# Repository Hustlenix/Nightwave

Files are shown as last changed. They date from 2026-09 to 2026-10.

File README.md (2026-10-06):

# Nightwave

Current builder boundary (2026-10-06): target PCB <=90x60 mm, finished device
about <=110x70x25 mm, INR15,000 electronics + PCB/assembly excluding tools.
Final PCB redesign/routing and enclosure CAD are builder-authored. The large
AI reference is not the final design; battery remains unselected. See
[compact requirements](docs/compact-builder-constraints.md), which supersede
older size/budget and final-CAD authoring permissions below.

## PCB checkpoint - 2026-10-06

The AI-authored [KiCad reference project](hardware/kicad/nightwave-reference/README.md)
now has a routed four-layer board, 132 circuit footprints plus three M2
mounting holes, numbered GPIO assignments, and native manufacturing review
exports. See its [validation status](hardware/kicad/nightwave-reference/VALIDATION_STATUS.md)
and [engineering checkpoint](docs/reference-pcb-checkpoint.md) for exact results.
The [downloadable review package](hardware/kicad/Nightwave-AI-Reference-2026-10-06.zip)
includes editable sources, PDF, Gerbers, drill, positions and board STEP.

The [completion ledger](docs/design-completion-status.md) tracks open work.
The [reference firmware profile](docs/reference-board-firmware.md) now matches
the PCB GPIO map and implements TFT output and expander buttons. Typed ERC,
DRC and schematic/board parity pass locally; hardware operation remains untested.

**This is not fabrication or grant-submission approval.** USB source-current
and protection, power-loop/current capacity, complete component procurement,
firmware-to-board integration and enclosure fit remain unresolved. Clean
connectivity/clearance checks are not electrical safety or functional proof.
The builder requested this separate AI-authored reference when their laptop
could not run KiCad; their original starter files remain untouched.

Nightwave is an in-progress, standalone pocket music player for the Pixl “A Music player for the saloon” Trial. It reads user-owned MP3 and PCM/WAV files directly from microSD, with software decoding, physical controls, wired stereo headphones, a speaker, synchronized LRC and Bluetooth output. No phone or streaming service is required. The builder selected ESP32-S3 plus BM83SM1-00TA (BD-14) and Waveshare 24382 non-touch TFT (BD-15). Their hardware drivers, combined GPIO map and battery sizing are not qualified or locked.

> Status (2026-10-03): WAV/MP3 three-task streaming, bench OLED/five-button interaction,
> lyrics/metadata/M3U, modes, bounded seek/resume, sleep timer and versioned
> persistence are implemented for the provisional hardware. The 2026-10-02
> continuation adds an idle-built SD catalog, paged songs/artists/albums and
> bounded PSRAM lookups for filtered browsing/track changes, MP3 duration/sparse
> seek, full-text display interface, BT/power contracts and engineering telemetry;
> [catalog limits](docs/library-index.md) remain explicit. See the
> [expanded-scope checkpoint](docs/engineering-budgets.md) for remaining software.
> Executed [firmware/host CI evidence](docs/software-validation.md) is revision-specific.
> **Funding package is NOT READY:** final power design,
> complete procurement BOM, reviewed enclosure CAD and human reviews are
> missing. An [AI-authored PCB reference](hardware/kicad/nightwave-reference/README.md)
> now exists; its native checks do not constitute fabrication approval or builder authorship.
> No physical playback, runtime, fit, final hardware or tier is claimed.

## Why it exists

The original hardware workflow used builder-authored mentor/reviewer mode;
the separate AI-authored reference above was subsequently requested. **Before
final schematic tasks**, review the selected [Bluetooth architecture](docs/bluetooth-architecture.md)
and [display BD-15](docs/display-selection.md). BD-16 selects
[TCA9535PWR input expansion](docs/input-expansion.md); review its [combined GPIO map](docs/pin-budget.md)
and review the [current power model](docs/current-power-model.md), charger/pack
and complete BOM before the first schematic task. Then use
[builder tasks](docs/builder-tasks.md), [subsystem requirements](docs/schematic-requirements.md)
and [your decision log](docs/builder-decisions.md). AI research and review are
disclosed; final schematic, routing and enclosure must be materially authored
by the builder. The reported Pixl clarification does not mark missing work done.

The product goal is to play the builder's own music offline without a phone,
notifications, subscription or hidden playback module. The builder's personal
motivation and genuine work journal must remain their own account; this README
does not invent a first-person build story.

## Architecture

```text
microSD / FAT
      |
      v
StorageTask -> compressed ring buffer -> DecoderTask -> PCM ring buffer
                                                        |
                                                        v
                                                AudioOutputTask
                                                        |
                                                   I2S + DMA
                                      +-----------------+-----------------+
                                      |                                   |
                                PCM5102A DAC                       MAX98360C amp
                                      |                                   |
                              TPA6132A2 headphone amp                mono speaker
                                      |
                               3.5 mm stereo jack
```

The ESP32 owns file enumeration, storage reads, MP3/WAV decoding, buffering, playback state, I2S output, buttons, UI, settings, diagnostics, and power policy. Nightwave does not use DFPlayer or another module that hides the storage/decode/playback pipeline. The diagram above is the current two-local-output software/bench path. The product requires a third mutually exclusive, rate-qualified I2S branch to BM83SM1-00TA for A2DP source output. Its radio adapter, combined playback router and 22.05/32 kHz conversion are not implemented. Host-tested Bluetooth control/framing contracts do not make that output operational.

The bench prototype uses an available MAX98357A breakout as a functional speaker-path proxy. The current AI-authored KiCad reference uses MAX98357AETE+T (TQFN); MAX98360C in historical candidate documents is not the reference board's fitted amplifier. This remains an unqualified engineering candidate.

## Current implementation

- repository and required engineering-document structure;
- current Pixl/Trial rules verification and honest AI-disclosure strategy;
- datasheet-backed provisional component comparison, BOM, pin budget, power tree, risk register, prototype plan, and decoder study;
- ESP-IDF 6.1 C++ firmware with safe-muted boot, chip/reset/heap/PSRAM diagnostics, debounced five-button logging, 1-bit SDMMC mount/enumeration/benchmarking, I2S DMA output, and a low-level tone test;
- robust host-tested WAV parsing for 16-bit mono/stereo PCM at 22.05/32/44.1/48 kHz, including unknown-chunk skipping and explicit errors;
- three-task WAV/MP3 streaming through a 32 KiB encoded ring and 16,384-frame
  SPSC PCM ring, pause/resume, cancellation, gain ramps and queue/error telemetry;
- SH1106 OLED driver (SSD1306 option), file/folder browser, now-playing, five
  buttons, headphone indicator, no-SD/error screens, sleep and diagnostics;
- bounded LRC, ID3v2.3/v2.4/ID3v1/WAV INFO metadata and local M3U/M3U8 loading;
- SD-backed incremental catalog, 16-row songs/artists/albums views, full indexed
  collection/filter queues, bounded artist/album lookup and checked ordinal-hint
  filter/folder resume; low-memory/over-cap caches use a slower fallback;
- normal/shuffle/repeat-all/repeat-track; accepted-sample lyric clock; WAV direct
  seek and idle-built sparse MP3 seek checkpoints with decoder preroll, safe
  decode-from-start fallback and a 30-minute resume/seek cap;
- versioned checked NVS volume/mode/output/resume/playlist/folder persistence,
  explicit saved-track resume and 15/30/45/60-minute/end-track sleep timers;
- JSON boot/stream/performance/self-test/engineering records, with unmeasured hardware marked;
- injected display frame interface carrying full bounded metadata/LRC strings;
  tested Bluetooth source-state/timeout/backpressure boundary and unknown-safe
  power HAL, without pretending unqualified adapters are operational;
- portable tests for WAV parsing, generated fixtures, ring wrap/full behavior, stereo-to-mono arithmetic, volume scaling, button debounce, and playback state;
- CI definitions for both ESP32-S3 firmware and portable host tests;
- exact Phase 2 prototype BOM, pin-by-pin wiring table, voltage/current plan, deterministic test-media generator, and staged bring-up checklist.

The firmware does **not** prove that a card mounts, a waveform reaches a physical
module, a speaker/headphone produces correct audio, or buffering survives real
card latency. OLED/controller wiring, jack detection and NVS behavior still need
bench validation. Battery reads, power-latch shutdown and automatic SD hotplug
reinitialization are not implemented. Retry/error handling is not a claim that
removing a real card during playback has been tested.

## Controls

The [Trial acceptance matrix](docs/trial-acceptance.md) maps every requirement to
source and missing physical proof. The [runtime recorder](docs/runtime-test.md)
logs sampled elapsed/playback windows and faults; it cannot certify battery life.

Previous/Next navigate the browser or change playing tracks. Play opens a folder
or starts/toggles playback. Volume +/- changes gain. Hold Play for the browser,
hold Previous for the parent folder, hold Volume + for diagnostics, hold Next
for lyrics and hold Volume - for mode/sleep/resume/output settings. First input
after the 30 s display sleep wakes without changing playback.
See [complete controls and limitations](docs/player-controls.md).

## Audio architecture

Helix decodes MP3 in software on ESP32-S3; WAV uses the validated PCM parser.
Storage, decode and I2S have separate tasks. PCM is stereo 16-bit at supported
22.05/32/44.1/48 kHz rates. ID3 skipping and resynchronization are bounded;
unsupported or corrupt media produces a recoverable error. The Class-D path
must select averaged-stereo mono in the reviewed final hardware; headphone
output uses the separate stereo DAC/amp path. Neither path is physically proven.

## Power architecture

USB-C and a protected 1S pack feed a charger/power path; SYS powers the speaker
and a buck-boost supplies 3.3 V. This direction is **provisional**, not a finished
circuit. The [selected-product screening model](docs/current-power-model.md)
calculates MCU, SD, selected TFT, speaker/wired/BT, idle, transients and charging.
Its continuously lit typical speaker case needs an estimated 7.08 Ah for eight
hours under the documented margins; a hypothetical 6.6 Ah gives 7.46 h, not a
passing measurement. Dimming/gating scenarios are conditional, not implemented
power savings. The [historical OLED model](docs/power-budget.md) is superseded.
[Charger timer, source-current and peak-load conflicts](docs/power-assumptions.md)
must be resolved before locking hardware. Estimated runtime is not measured
runtime, and charge-while-play safety is not verified.

## PCB and enclosure

The [current KiCad reference](hardware/kicad/nightwave-reference/README.md)
contains a seven-sheet schematic, placed four-layer board, project-local land
patterns and explicit pin map. Check its [revision-specific validation status](hardware/kicad/nightwave-reference/VALIDATION_STATUS.md)
for actual routing, DRC/parity results and available review exports. The source
is AI-authored at the builder's request, not evidence of human-authored CAD.
It is not fabrication approved. No reviewed editable enclosure, full mechanical
assembly or physical build proof is claimed. See [the reference differences and remaining gates](docs/reference-pcb-checkpoint.md).
An [AI-assisted KiCad starter](hardware/kicad/nightwave-starter/START_HERE.md)
now supplies a root hierarchy, six empty subsystem sheets and a blank board so
the builder can begin quickly. It is scaffolding only: it contains no finished
circuit, footprint assignment, GPIO map, placement or routing and is not funding
evidence by itself.
The board, battery, speaker, display, controls and ports must all have verified
mounting and clearances in the builder-owned design before funding submission.

## BOM

[Preliminary BOM CSV](hardware/BOM.csv): captured-price core subtotal **$53.16**,
including selected BM83 and Waveshare 24382, excluding the pending battery. This is
not a finished BOM total or funding/order cost. USB-C, support parts, PCB,
assembly, enclosure, delivery and taxes also remain excluded/pending. Critical
rows now include package, datasheet, source, footprint and electrical roles;
pending rows are explicit, not approved substitutes. The spreadsheet review
preserved the CSV and checked its selected/pending fields. Older prices remain
dated snapshots; the selected display was checked via official indexed content
2026-10-03 (direct fetch refused; stock/delivery unverified).
No parts have been ordered by this run.

## Build the firmware

Target toolchain: ESP-IDF `v6.1`, target `esp32s3`.

```sh
cd firmware
idf.py set-target esp32s3
idf.py build
```

The development baseline is `ESP32-S3-DevKitC-1-N8R8`; the provisional final module is `ESP32-S3-WROOM-1-N16R8`. Pins and component choices remain provisional until prototype validation.

Use `idf.py -p PORT flash monitor` after building, with the documented DevKit
only and verified wiring. The console adds `play`, `pause`, `resume`, and
`volume` to the bench commands; `wav` remains an alias. Follow
[Phase 3 firmware bring-up](docs/phase3-firmware-bringup.md) before enabling an
output. Production flashing/power instructions depend on the unfinished PCB.

## Load music and build the prototype

Copy supported `.wav` or `.mp3` files to a FAT-formatted microSD, optionally in
folders. Paths must be under 256 bytes; the browser displays at most 128 entries
per folder. No streaming or network is used. Generated test tones are described
in [test media](docs/test-tracks.md). Free-format/MPEG2.5 MP3, unsupported rates,
24-bit WAV and full Unicode display are not implemented features. Bounded WAV
and MP3 seek and shuffle are implemented; their limits and fallback behavior are
documented in [player controls](docs/player-controls.md) and [software evidence](docs/software-validation.md).

For the USB-powered human-assembled prototype, use the
[prototype BOM](hardware/prototype-BOM.csv), [wiring](docs/prototype-wiring.md)
and [bring-up checklist](docs/prototype-bringup.md). Do not connect a lithium
pack or place a final-PCB order using this preliminary package.

## Current validation and funding status

[Software evidence](docs/software-validation.md) separates actual CI runs from
host simulations and pending board measurements. The regression suite exercises
1000 start/cancel/control transitions, corrupt media, fragmented MP3, WAV,
concurrent ring transfers and real folder-navigation logic with fake devices.

[Funding audit](docs/funding-readiness.md),
[current official requirements](docs/pixl-funding-readiness.md),
[builder design/provenance review](docs/human-design-review.md), and
[independent sanity-check packet](docs/sanity-check.md) record the exact gaps.
Project 1200 was inspected in the authenticated builder session on 2026-10-02.
It is a hardware funding draft, with finished-build status unchecked. The Trial
requires local files, real speakers, physical playback/volume controls and a
full-night battery with the achieved runtime stated. Design funding and finished
build evidence are separate stages; see [the current project audit](docs/project-1200-audit.md).
No funding request has been submitted.

Run the [shipping artifact inventory](docs/shipping-audit.md) to expose unresolved
costs and missing design sources. A passing development validator or green form
checkbox does not establish a complete funding design or T4 eligibility.

## Finished-device acceptance

The [finished-device evidence inventory](docs/trial-acceptance.md#finished-device-evidence-inventory)
tracks own-file standalone speaker playback, physical play/pause/skip/volume,
actual full-night speaker battery runtime, final schematic/CAD/STEP, parts/build
instructions, build photos and a real demo video. The pending record is
[trial-evidence.json](measurements/trial-evidence.json); **achieved runtime is
unknown**, not an estimate or a simulated eight-hour result. No demo video exists
yet. Only populate evidence after the corresponding real work and human review.

```sh
python3 tools/check_trial_readiness.py
```

Exit 2 lists missing evidence. Exit 0 only inventories builder-reported evidence
for human review; it never certifies playback, safety, runtime, authorship or Pixl
acceptance. Keep the full [systems scope](docs/trial-acceptance.md) through release;
the hardware integrations must work, not just appear in the feature list.

## Engineering documents

- [Pixl requirements](docs/pixl-requirements.md)
- [Architecture notes](docs/architecture-notes.md)
- [Component comparison](docs/component-comparison.md)
- [Decoder study](docs/decoder-study.md)
- [Decision log](docs/decisions.md)
- [Pin budget](docs/pin-budget.md)
- [Power tree](docs/power-tree.md)
- [Prototype plan](docs/prototype-plan.md)
- [Prototype BOM](hardware/prototype-BOM.csv)
- [Prototype wiring](docs/prototype-wiring.md)
- [Prototype bring-up checklist](docs/prototype-bringup.md)
- [Deterministic test media](docs/test-tracks.md)
- [Phase 3 firmware bring-up](docs/phase3-firmware-bringup.md)
- [Audio buffer analysis](docs/audio-buffer-analysis.md)
- [Headphone prototype options](docs/headphone-prototype-options.md)
- [MP3 integration plan](docs/mp3-integration-plan.md)
- [Risk register](docs/risks.md)
- [Preliminary BOM](hardware/BOM.csv)
- [AI disclosure](docs/ai-disclosure.md)

## Physical validation still required

Direct-SD playback, decoder timing, buffer sizing, audio quality, channel correctness, output power, noise, thermal behavior, current draw, charge-while-play behavior, battery capacity, full-night runtime, PCB manufacturability, and enclosure fit all require physical evidence. The project-defined acceptance test is at least eight hours of continuous speaker playback under a declared profile; the current Pixl Trial itself says “a full night” and requires the achieved runtime to be stated, but does not publish an exact hour count.

## AI disclosure

AI assistance is being used for research synthesis, repository scaffolding, interface design, documentation, and software checks. The builder must understand and materially review the electrical and mechanical design, physically assemble and test the device, maintain honest journals and photos, and obtain a second-person sanity check before hardware submission. Fully AI-generated hardware design files are not acceptable under the current Pixl hardware rules.

## License

Nightwave's original repository content is provided under the MIT License. Third-party libraries keep their own licenses and notices.
The MP3 wrapper's Apache-2.0 license does not relicense the RealNetworks Helix
decoder. Read [dependency provenance and terms](docs/decoder-licenses.md);
notices are preserved in [licenses](licenses/). Original tone fixtures and the
small text font are generated within this repository, not downloaded media.

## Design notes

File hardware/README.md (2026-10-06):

# Hardware inventories and authority

`reference-procurement.csv` is the current procurement working inventory:
it is generated from the actual reference circuit BOM plus manufacturer-checked
resistor MPN selections in `reference-resistor-selections.json`. Run
`tools/build_reference_procurement.py` after changing either input. It resolves
49 resistor positions without changing their values/footprints. Zero-ohm current
ratings, capacitor effective capacitance, other missing MPNs and complete quotes
remain open. Empty prices are unknown, not zero; retained older prices are marked
historical. This file is not a completed purchasing list or an approved order.

Current product choices: ESP32-S3, BM83SM1-00TA Bluetooth output, Waveshare 24382
TFT and TCA9535PWR controls. Speaker, wired headphones, microSD, synchronized
lyrics and rechargeable power remain in scope.

Use `kicad/nightwave-reference/reference-bom.csv` for the **actual AI-authored
reference schematic inventory** and `design-manifest.json` for its pin/net
assignments. Missing prices and `PENDING_SELECTION` parts are unresolved, not
free or purchase-ready. The reference includes BQ25628E, dual TPS63802,
TPS22965 and MAX17048; battery approval and safety review remain open.

`BOM.csv` is the older research/candidate cost inventory, not a purchasing list
for that PCB. Its BQ25185 and pending BT rail entries do not describe the
reference circuit. `prototype-BOM.csv` and `prototype-wiring.csv` describe the
legacy USB-powered OLED/direct-button bench, not the selected product.

Do not combine these inventories to produce a purported complete price or
substitute their wiring maps. See `../docs/design-completion-status.md` for
the remaining design, procurement, enclosure and independent-review gates.

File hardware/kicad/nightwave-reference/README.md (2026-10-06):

# Nightwave KiCad reference design

This directory is an AI-authored KiCad engineering reference. See `VALIDATION_STATUS.md` for the actual routing/check results of the exported revision. It is unbuilt, unmeasured, and **not approved for fabrication or lithium-cell connection**. It is not evidence of human-authored CAD or Pixl acceptance.

## What is here

- native KiCad 10 hierarchical schematic and four-layer PCB source;
- selected ESP32-S3, BM83, Waveshare TFT, TCA9535, local DAC/headphone/speaker, USB-C, charger, dual regulated rails, protected battery and service/test interfaces;
- exact logical net/GPIO assignments generated from the same source as the PCB;
- BOM and machine-readable design manifest;
- `manufacturing/` review exports generated by KiCad CLI and prominently marked **DO NOT FABRICATE**;
- `reports/` ERC/DRC/netlist and rendered-review evidence.

## Critical stop

Do not order this board yet. An independent reviewer must close `REVIEW_CHECKLIST.md`. Automated routing and clearance/connectivity checks do not establish USB impedance, power-loop stability, current capacity, RF performance, charger safety, manufacturability or enclosure fit. IC pins now have explicit electrical types from manufacturer pin-function tables. ERC checks this model; it does not verify analog behavior or mode-dependent module configuration. The four source flags declare external power/ground and the analog rail after R30, not safety approval.

## Opening tomorrow

Open `Nightwave-Reference.kicad_pro`. Start with the root schematic, then inspect the PCB. The existing `nightwave-starter` project is intentionally separate and unchanged.

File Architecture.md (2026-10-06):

# Architecture.md

Current builder boundary (2026-10-06): target PCB <=90x60 mm, finished device
about <=110x70x25 mm, INR15,000 electronics + PCB/assembly excluding tools.
Final PCB redesign/routing and enclosure CAD are builder-authored. The large
AI reference is not the final design; battery remains unselected. See
[compact requirements](docs/compact-builder-constraints.md), which supersede
older size/budget and final-CAD authoring permissions below.

## Current implementation override - 2026-10-06

The separately disclosed AI-authored [reference PCB](hardware/kicad/nightwave-reference/README.md)
uses the selected S3/BM83, Waveshare 24382 and TCA9535 architecture.
Its [numbered GPIO map](hardware/kicad/nightwave-reference/FINAL_GPIO_MAP.md)
is checked against the [reference firmware profile](docs/reference-board-firmware.md).
TFT and expander button transports are implemented but not physically qualified;
Bluetooth still has an unavailable runtime backend. Power monitoring now has
a read-only shared-I2C adapter; charging control/shutdown remain unqualified.
The reference circuit uses BQ25628E, dual TPS63802, TPS22965, MAX17048,
PCM5102A, TPA6132A2 and MAX98357A. Earlier BQ24074/BQ25185 charger options
and old direct-button/OLED maps below are historical alternatives, not its BOM.
See [remaining completion gates](docs/design-completion-status.md). No pack,
fabrication approval or physical runtime is locked by this architecture.

# Nightwave — Technical Architecture

## 2026-10-01 final execution scope override

Local software decoding remains mandatory. New scope includes synced .lrc,
metadata/M3U, playback modes/resume/sleep and Bluetooth audio output. S3 remains
the working target, not an A2DP-capable chip. Choose docs/bluetooth-architecture.md
and docs/display-selection.md before final schematic work. On 2026-10-02 the
builder selected S3 plus BM83SM1-00TA (BD-14). On 2026-10-03 the builder selected
Waveshare 24382 non-touch 240x280 ST7789V2 (BD-15). BD-16 selects TCA9535PWR
input expansion; its combined numbered map and reviewed power hardware/pack
remain open; docs/current-power-model.md is
the current calculated screening model, not physical runtime evidence.
docs/engineering-budgets.md distinguishes
implemented software from remaining library performance, HAL/power and transport
work. Older two-output/OLED references below are historical provisional design.

2026-10-02: `library` now includes LibraryCatalog, with fixed-size SD records,
bounded directory work queue, idle incremental build, per-record integrity/path
checks and PSRAM 16-row pages. PlayerFrontend supplies songs/artist/album views,
full collection/filter playback and cached context resume. No indexing/metadata
work runs on the real-time audio workers. A v2 footer supplies bounded PSRAM
artist/album dictionaries and grouped track IDs; filtered selection uses direct
record access, with legacy/allocation/group-cap slow fallback. Queries/footer
warmup are UI-sliced; SD contention and fallback latency remain acceptance gaps.
See docs/library-index.md for memory budgets, wire format and resume checks.

## 1. Architecture objective

Runtime diagnostics now run from the serialized UI/console owner, using
boot-lifetime accepted-media and fault counters from the audio engine. Reports
distinguish wall time, sampled playback and qualified battery observations;
current unavailable power/untested audio keeps battery proof unestablished.
No logging, allocation or filesystem work is added to the audio worker. See
docs/runtime-test.md for sampling, counter-wrap, gap and physical-evidence limits.

Nightwave is not an ESP32 remote control for a self-contained MP3 module. The ESP32-S3 owns the storage, decode, buffering, playback state, UI, and power policy.

Current product output branches (only one active route):

```text
microSD -> reader -> encoded ring -> Helix/WAV -> PCM ring -> route/gain policy
  +-> I2S -> MAX98360C -> speaker                         [local candidate]
  +-> I2S -> PCM5102A -> TPA6132A2 -> stereo jack        [local candidate]
  +-> rate-qualified I2S -> BM83SM1-00TA -> A2DP sink    [builder-selected; backend pending]
```

BM83 does SBC/radio transport only; S3 retains filesystem/software decoding.
AT Tx supports 44.1/48 kHz. Existing 22.05/32 kHz local playback remains valid,
but Bluetooth at those rates requires a tested converter or explicit rejection.
No implicit rate change, AVRCP Tx support or speaker fallback on BT loss.
Source-mode control and full-text display/power HAL boundaries are portable;
hardware adapters, final GPIO, power rails and acoustic timing remain unqualified.

Implementation boundary, 2026-10-03: `StreamingPlayer` currently owns the local
`I2sAudioSink` and its muted/speaker/line routes. `BluetoothSource` is a separate
host-tested control/PCM contract; `app_main` instantiates `UnavailableBluetooth`.
The three-output diagram specifies the product, not an integrated three-output
implementation. Combined routing, actual UART events/provisioning and rate-correct
PCM transport still require implementation and qualification. Invalid PCM now
faults closed, disconnects and invalidates stale events; this does not enable radio.

Historical two-local-output bench pipeline (not the complete product architecture):

```text
microSD
  │
  ▼
SDMMC + FatFS
  │
  ▼
Storage / reader task
  │ compressed-byte ring buffer
  ▼
MP3/WAV decoder task
  │ PCM frames
  ▼
PCM ring buffer
  │
  ├── optional digital volume / EQ / limiter
  ▼
Audio output task
  │ I²S DMA
  ├──────────────────────┐
  ▼                      ▼
PCM5102A               MAX98360C
stereo DAC             mono Class-D
  │                      │
  ▼                      ▼
headphone amp          speaker
  │
  ▼
3.5 mm stereo jack
```

This architecture is deliberately chosen to expose the systems problems that a dedicated MP3 module hides.

## 2. Chosen stack

### Firmware

**ESP-IDF, C/C++, FreeRTOS**

Rationale:
- native access to ESP32-S3 I²S and DMA;
- native SDMMC/FatFS integration;
- FreeRTOS task primitives;
- detailed memory/task/driver control;
- suitable for profiling and embedded systems work.

Arduino wrappers MAY be used only for isolated libraries if necessary and justified. The main architecture MUST remain ESP-IDF-native.

### EDA

**KiCad**

Deliverables:
- `.kicad_pro`
- `.kicad_sch`
- `.kicad_pcb`
- footprint/model libraries used by project
- Gerber/drill export

### Mechanical CAD

Preferred:
**FreeCAD** with:
- `.FCStd`
- `.STEP`
- `.STL`

A parametric alternative such as Onshape is acceptable only if source remains editable and exportable.

### Rendering

Optional:
- KiCad 3D viewer;
- pcb2blender;
- Blender `.blend`.

Rendering is documentation, not a substitute for CAD source.

## 3. Repository structure

```text
nightwave/
├── README.md
├── LICENSE
├── docs/
│   ├── requirements.md
│   ├── architecture-notes.md
│   ├── decisions.md
│   ├── power-budget.md
│   ├── prototype-wiring.md
│   ├── schematic-review.md
│   ├── pcb-review.md
│   ├── bringup.md
│   ├── validation.md
│   ├── runtime-test.md
│   └── ai-disclosure.md
├── firmware/
│   ├── CMakeLists.txt
│   ├── sdkconfig.defaults
│   ├── main/
│   ├── components/
│   └── test/
├── hardware/
│   ├── BOM.csv
│   ├── kicad/
│   ├── libraries/
│   ├── manufacturing/
│   └── datasheets/
├── enclosure/
│   ├── nightwave.FCStd
│   ├── nightwave.step
│   ├── nightwave.stl
│   └── drawings/
├── renders/
├── measurements/
│   ├── current-draw.csv
│   ├── runtime.csv
│   └── notes.md
└── media/
    ├── build/
    └── final/
```

## 4. Major firmware modules

### app_state
Owns global product state:
- booting;
- ready;
- playing;
- paused;
- error;
- charging;
- low-battery shutdown.

No arbitrary module may mutate global state directly.

### storage
Responsibilities:
- mount/unmount microSD;
- enumerate folders/files;
- provide sequential reads;
- report throughput/errors;
- detect card changes when hardware allows.

### library
Responsibilities:
- filter supported media;
- parse/display file names;
- metadata extraction if implemented;
- stable track identifiers;
- navigation.

### decoder
Responsibilities:
- consume compressed bytes;
- identify format;
- decode MP3;
- decode WAV PCM;
- output normalized PCM frame representation;
- report decode errors/end-of-stream.

Candidate lightweight libraries should be researched and license-checked before lock. Avoid large framework adoption that bypasses the core architecture.

### audio_pipeline
Responsibilities:
- PCM ring buffer;
- sample-format normalization;
- volume ramp;
- mono mix for speaker;
- optional DSP;
- underrun/overflow counters.

### audio_i2s
Responsibilities:
- configure I²S;
- configure DMA buffers;
- stream PCM;
- start/stop cleanly;
- expose playback diagnostics.

### playback
Responsibilities:
- play/pause;
- next/previous;
- end-of-track;
- seek if implemented;
- queue;
- repeat/shuffle if implemented.

### input
Responsibilities:
- button GPIO;
- debounce;
- press/release events;
- long press only where explicitly defined.

### ui
Responsibilities:
- display rendering;
- screen transitions;
- error state;
- battery status;
- no blocking storage/audio operations.

### power
Responsibilities:
- fuel gauge;
- charger status;
- low-battery behavior;
- idle/display sleep policy;
- controlled shutdown.

### settings
Responsibilities:
- NVS-backed persistent volume;
- last track/path;
- preferences;
- schema/version handling.

### diagnostics
Responsibilities:
- structured logging;
- task high-water marks;
- underrun count;
- SD throughput;
- heap/PSRAM use;
- reset reason.

## 5. FreeRTOS task architecture

Initial tasks:

| Task | Priority intent | Primary responsibility |
|---|---|---|
| AudioOutputTask | highest application priority | keep DMA supplied |
| DecoderTask | high | compressed → PCM |
| StorageTask | medium-high | prefetch compressed data |
| InputTask | medium | button events |
| UITask | medium-low | screen refresh |
| PowerTask | low | SOC/charging/thermal policy |
| DiagnosticsTask | low | periodic metrics in debug builds |

Exact priorities/core affinity MUST be measured and tuned, not guessed permanently.

## 6. Buffering architecture

Two-stage buffering:

```text
SD card
  │
  ▼
compressed ring buffer
  │
  ▼
decoder
  │
  ▼
PCM ring buffer
  │
  ▼
I²S DMA
```

Why two buffers:
- isolates SD latency from decode;
- isolates decode-time variance from real-time audio output;
- makes underruns measurable;
- permits controlled prefetch.

Work MUST benchmark:
- SD sequential throughput;
- worst observed read latency;
- decode throughput;
- PCM consumption rate;
- heap/PSRAM budget.

Buffer sizes MUST be derived from measurements and recorded in `docs/architecture-notes.md`.

## 7. Memory architecture

Baseline:
- internal SRAM for latency-critical queues/driver structures;
- PSRAM, if the selected ESP32-S3 module includes it, for larger media buffers/library cache;
- NVS for settings only;
- microSD for music and optional cache/index.

Do not make playback depend on a huge in-RAM library database.

## 8. Storage architecture

Preferred final interface:
- SDMMC rather than SPI when pin budget/layout permit.

Reasons:
- higher bandwidth headroom;
- stronger systems depth;
- avoids unnecessary contention with display/peripherals.

Fallback:
- SDSPI if board constraints materially justify it.

Filesystem:
- FAT32/exFAT only if supported and licensing/toolchain implications are acceptable;
- FAT32 baseline is sufficient for V1.

## 9. Audio data model

Internal canonical PCM representation should be documented, e.g.:

```c
struct pcm_frame {
    int16_t left;
    int16_t right;
};
```

or packed buffers equivalent to 16-bit stereo PCM.

Decoder output that differs in sample rate/channel count MUST pass through an explicit format-adaptation stage.

## 10. Sample-rate strategy

V1 should support the common music rates used by the selected decoder library.

Preferred strategy:
- reconfigure I²S clock between tracks when source rate changes;
- avoid implementing arbitrary software resampling unless needed.

The transition MUST mute/ramp to avoid pops.

## 11. DSP architecture

Required:
- digital volume;
- saturation-safe stereo-to-mono mix.

Optional after stable core:
- parametric or multi-band EQ;
- limiter;
- balance.

DSP MUST not jeopardize buffer deadlines.

## 12. Audio hardware architecture

### Headphone path

```text
ESP32-S3 I²S
   │
   ▼
PCM5102A
   │ stereo analog
   ▼
headphone amplifier
   │
   ▼
3.5 mm TRS jack
```

PCM5102A is a candidate because it accepts I²S, provides stereo output, and does not require MCLK in the common configuration. Final schematic MUST follow the authoritative datasheet/reference design.

The DAC line output MUST NOT be assumed safe for arbitrary low-impedance headphones without the headphone amplifier stage.

### Speaker path

```text
ESP32-S3 I²S
   │
   ▼
MAX98360C-class Class-D
   │ differential speaker output
   ▼
4–8 ohm speaker
```

The speaker amplifier can consume the stereo stream and use a documented mono/channel selection mode.

The speaker path MUST support hardware/software shutdown for power savings and headphone insertion behavior.

### Headphone detection

Use a jack with a reliable detect/switch contact or a dedicated detector.

Event:
- headphone inserted → mute/shutdown speaker, enable headphone path;
- headphone removed → ramp/mute transition then restore speaker if user policy allows.

## 13. Control hardware

Five dedicated buttons:
- PREV;
- PLAY/PAUSE;
- NEXT;
- VOL-;
- VOL+.

Buttons:
- must be debounced in software;
- must not float;
- should use documented pull-up/pull-down strategy;
- must have ergonomic spacing in CAD.

## 14. Display hardware

Final product: Waveshare 24382 non-touch 240x280 SPI display selected in BD-15. The small
monochrome OLED is a legacy bench adapter, not a final default.

SelectedDisplayProfile defines portrait 240x280 geometry, 20-row GRAM offset,
RGB565 and bounded 16-row tiles (7,680 bytes). Maker example register choices
are recorded, not a functioning ESP-IDF driver. GPIO, initialization, PWM/sleep,
full lyric wrapping/glyphs and physical panel tests remain unfinished. Do not
run the historical OLED adapter against the TFT or infer a reviewed final map.

Selection criteria:
- low current;
- strong library support;
- readable outdoors/indoors;
- easy mechanical integration;
- availability.

SPI DMA tiles and backlight power need bounded budgets. I2C remains available
for the fuel gauge/control devices; check capacitance and pull-ups separately.

## 15. Power architecture

High-level:

```text
USB-C 5V
  │
  ├─ CC resistors / protection
  ▼
1-cell charger with power path
  │
  ├────────► VSYS
  │
  └────────► LiPo
               │
               └─ fuel gauge → I²C → ESP32-S3

VSYS
  ├─ qualified regulator → ESP32/DAC/readable display/logic
  ├─ speaker amp supply or validated derived rail
  └─ BM83 qualified rail + shutdown/backfeed isolation
```

Candidate charger:
- BQ24074-class or BQ25185-class power-path charger.

Candidate fuel gauge:
- MAX17048-class gauge.

The final choice MUST be based on:
- battery chemistry;
- charge current;
- thermal limits;
- package assembly;
- availability;
- protection requirements.

## 16. USB-C architecture

USB-C is used for power/charging in V1.

MUST:
- correctly advertise sink behavior using CC resistors if using USB-C receptacle;
- include ESD/protection as appropriate;
- avoid claiming USB data functionality unless implemented;
- keep connector mechanically supported.

Optional later:
- native USB firmware update or mass storage if electrical design supports data lines.

## 17. Battery sizing

Do not choose capacity from guesswork.

Process:

1. Prototype current measurement for:
   - idle;
   - headphone playback;
   - speaker playback at multiple volume levels;
   - display on/off.
2. Set >=8 h acceptance target and >=10 h engineering target for speaker profile.
3. Include regulator/charger losses and reasonable capacity derating.
4. Choose protected cell whose dimensions fit CAD.
5. Verify thermal and charge-current compatibility.
6. Validate with full discharge test.

## 18. PCB architecture

The final board is a real mixed-signal PCB, not a breakout-module motherboard.

Functional zones:

```text
┌─────────────────────────────────────┐
│ USB/charger/power     speaker amp   │
│                                     │
│ battery/fuel gauge                  │
│                                     │
│ ESP32-S3 + SD         I²S DAC       │
│                       headphone amp │
│ display/buttons       audio jack    │
└─────────────────────────────────────┘
```

Layout principles:
- respect ESP32 antenna keepout if using module with PCB antenna;
- short decoupling paths;
- controlled high-current Class-D return path;
- keep switching power/Class-D nodes away from low-level analog path;
- continuous reference planes where appropriate;
- avoid splitting return paths blindly;
- provide test points;
- clearly mark polarity/connectors;
- verify connector edge placement against CAD before fab.

## 19. Schematic hierarchy

Sheets/blocks:

- `POWER`
- `MCU`
- `STORAGE`
- `DISPLAY_INPUT`
- `AUDIO_DIGITAL`
- `AUDIO_ANALOG`
- `CONNECTORS_TEST`

Every rail and bus must be named consistently.

## 20. Mechanical architecture

Parametric enclosure with:
- base;
- lid;
- PCB standoffs;
- threaded inserts or screw bosses;
- battery pocket/cradle;
- speaker mount;
- acoustic grille;
- display window;
- button plungers/caps;
- USB-C opening;
- headphone opening;
- optional SD service opening;
- strain/clearance management.

PCB edge/connector placement and enclosure must be co-designed, not designed sequentially in isolation after PCB freeze.

## 21. Physical prototype architecture

Before final custom PCB:

```text
ESP32-S3 dev board
+ microSD breakout
+ I²S DAC breakout
+ headphone amp breakout
+ I²S speaker amp breakout
+ legacy bench OLED (final BD-15 screen is separate)
+ buttons
+ bench/USB power
```

Purpose:
- validate firmware architecture;
- measure current;
- validate headphone/speaker UX;
- expose software issues before fabrication.

The prototype is NOT the final submitted hardware.

## 22. Bring-up architecture

Final PCB bring-up sequence:

1. visual inspection;
2. continuity/short tests;
3. current-limited USB/bench power without battery when possible;
4. validate 3.3 V and VSYS;
5. validate MCU programming;
6. validate I²C devices;
7. validate SD;
8. validate DAC clocks/output;
9. validate headphone amp;
10. validate speaker amp;
11. validate buttons/display;
12. validate charger;
13. validate battery/fuel gauge;
14. full integrated playback.

Battery insertion comes only after power subsystem validation.

## 23. Testing strategy

### Firmware tests
- unit tests for file filtering;
- WAV parser;
- playback state transitions;
- settings validation;
- ring-buffer behavior where practical.

### Hardware validation
- rail voltage;
- current consumption;
- SD throughput;
- I²S clocks;
- headphone left/right;
- speaker output;
- jack detection;
- charging behavior;
- battery SOC;
- runtime.

### System tests
- 2+ hour continuous playback;
- full-night runtime;
- corrupted files;
- SD removal;
- repeated track changes;
- low-battery shutdown;
- headphones hot-plug;
- charge while playing.

## 24. Observability

Debug build MUST expose:

- boot/reset reason;
- current state;
- heap free/minimum;
- PSRAM use;
- stack high-water marks;
- SD throughput;
- decoder failures;
- compressed-buffer level;
- PCM-buffer level;
- audio underruns;
- output sample rate;
- battery SOC/voltage;
- charger state.

Release UI does not need to show all diagnostics.

## 25. CI

GitHub Actions SHOULD run:
- firmware format/lint if configured;
- ESP-IDF build;
- host-side unit tests where possible;
- file presence validation for release artifacts.

CI MUST NOT pretend to validate physical electronics.

## 26. Security/privacy

No user accounts and no network services.

Firmware MUST not transmit telemetry.

If USB data is later enabled, expose only intended interfaces.

## 27. Important tradeoffs

### Why not DFPlayer?
It hides filesystem/audio decode/buffering and removes much of the system depth.

### Why ESP32-S3?
It provides sufficient compute, I²S, DMA, FreeRTOS, SD support, and optional PSRAM while still fitting a handheld embedded device.

### Why separate DAC and speaker amp?
The headphone and speaker loads have different requirements and deserve explicit signal paths.

### Why a power-path charger?
The player must behave predictably while charging and playing.

### Why a custom PCB?
The goal is a complete physical product and a deeper hardware build, not a permanent breadboard/module stack.

## 28. Architectural freeze rule

The following are architecture-level invariants after Phase 2:

- ESP32-S3-class MCU;
- direct microSD access;
- software decode;
- ring-buffered PCM pipeline;
- DMA-driven I²S;
- separate headphone, speaker and Bluetooth source output paths;
- BM83SM1-00TA with source-capable AT firmware (builder-selected BD-14);
- larger readable display selected through BD-15, not locked to OLED;
- rechargeable 1-cell battery;
- fuel gauge;
- custom PCB;
- editable custom enclosure.

Changing one requires updating PRD.md, Architecture.md, phases.md, rules.md, design.md, and memory.md where affected.

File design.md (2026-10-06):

# design.md

Current builder boundary (2026-10-06): target PCB <=90x60 mm, finished device
about <=110x70x25 mm, INR15,000 electronics + PCB/assembly excluding tools.
Final PCB redesign/routing and enclosure CAD are builder-authored. The large
AI reference is not the final design; battery remains unselected. See
[compact requirements](docs/compact-builder-constraints.md), which supersede
older size/budget and final-CAD authoring permissions below.

## Current implementation override - 2026-10-06

A separate AI-authored reference PCB and board STEP now exist at the user's
request. The historical no-AI-CAD workflow below no longer describes those
artifacts; authorship must be disclosed and eligibility resolved with Pixl.
The board alone is 110 x 100 mm. No enclosure CAD or assembled fit verification
is complete. Waveshare 24382, two antenna exclusion regions, battery retention,
speaker, USB/headphone access and physical controls remain mandatory mechanical
requirements. Do not call the board STEP an enclosure or a finished pocket design.

# Nightwave — Physical + Interface Design System

2026-10-01 visual scope override: original angular industrial/comic-tech identity,
high contrast and lyric readability. Use Nightwave-owned shapes/typography,
not Marvel names, characters, logos or copied reactor/helmet art. Colour screen,
window/cutouts and final enclosure dimensions follow the builder's display/BT
decisions; no final CAD is assistant-authored. Earlier retro/OLED sketches below
are historical exploratory direction, not an approved physical design.

2026-10-03 selected display: Waveshare 24382 non-touch, 240x280; maker board
31.5x39 mm and active area 27.972x32.634 mm. Final window, corner treatment,
glass/PCB thickness, mount coordinates, cable bend and connector access must
follow the exact supplied drawing and builder-owned CAD. BM83 and S3 need
separate antenna exclusions. Pack size and enclosure dimensions are not locked.

## 1. Design principles

Nightwave should look and behave like a small intentional consumer device, not a development board inside a box.

Priorities:

1. controls are obvious by touch;
2. screen communicates playback state immediately;
3. speaker and headphones feel intentional;
4. enclosure is solid and serviceable;
5. internals look engineered;
6. PCB silkscreen is useful first, expressive second;
7. no visual feature may compromise battery, RF, audio, thermals, or manufacturability.

## 2. Visual direction

Working personality:

**compact offline player / late-night utility / understated retro-digital**

Avoid:
- gamer RGB;
- imitation iPod branding;
- copying PocketPlayer art;
- fake analog gauges;
- crowded cyberpunk decoration;
- unnecessary touchscreen aesthetics.

The physical object should remain recognizable even with the display off.

## 3. Product layout

Preferred portrait-ish front:

```text
┌────────────────────────────┐
│                            │
│       NIGHTWAVE            │
│ ┌────────────────────────┐ │
│ │ ♪ Track / File        │ │
│ │ ▶ 01:42     BAT 78%   │ │
│ │ VOL ███████░          │ │
│ └────────────────────────┘ │
│                            │
│   ◀      ▶/Ⅱ       ▶      │
│                            │
│       − VOL +              │
│                            │
│          speaker           │
│      · · · · · · ·         │
└────────────────────────────┘
```

This is conceptual; exact geometry comes from ergonomics and components.

## 4. Physical control hierarchy

Primary playback controls:
- Previous
- Play/Pause
- Next

Secondary:
- Volume -
- Volume +

Power:
- separate side switch/button to avoid accidental presses.

Controls should be distinguishable:
- play/pause central and largest;
- previous/next symmetric;
- volume separate enough to avoid accidental track changes.

Minimum button touch target is driven by physical switch/cap design, but should be comfortable for one-handed use.

## 5. Port layout

Preferred:
- USB-C: bottom or side, accessible while device rests on table;
- 3.5 mm jack: top edge for cable exit;
- microSD: side/service edge, not where it ejects into the user's palm;
- power: side.

Port positions MUST be frozen jointly between PCB and CAD.

## 6. Speaker design

Speaker:
- on front lower region or rear depending enclosure acoustic testing;
- grille should provide sufficient open area;
- enclosure must prevent diaphragm contact;
- speaker must have a rigid mount;
- avoid rattling surfaces;
- optional gasket if needed.

A rear speaker is acceptable only if tabletop use is not badly muffled.

## 7. Enclosure construction

Preferred two-part enclosure:
- base;
- lid/front.

Fastening:
- screws and bosses / heat-set inserts where suitable.

Internal features:
- PCB standoffs;
- battery cradle;
- speaker pocket;
- button guidance;
- display retention;
- connector clearances;
- cable channels only if wires are unavoidable.

Rounded external edges for pocket handling.

## 8. Serviceability

The enclosure SHOULD be reopenable.

Battery replacement need not be tool-less but should not require destroying the case.

SD card replacement MUST be practical.

## 9. Display typography

Readable display typography (BD-15 selected Waveshare 24382; driver/glyph tests pending; OLED sketches are bench-only):
- one readable bitmap font family or at most two sizes;
- high contrast;
- no decorative tiny fonts;
- truncate/scroll long file names predictably.

Information hierarchy:

### Level 1
Track/file title.

### Level 2
Play/pause state + elapsed time.

### Level 3
Volume, battery, output mode.

## 10. Screen inventory

### Splash
```text
NIGHTWAVE
offline audio
v0.x
```

### Initializing
```text
Mounting SD...
Starting audio...
```

### Now Playing
```text
Track Name
▶ 01:42 / 03:58
VOL 18     BAT 78%
HEADPHONES
```

### Paused
Same screen with a clear pause indicator.

### Library
```text
/Music
> Albums
  Mixes
  song.mp3
```

### No SD
```text
NO SD CARD
Insert card
```

### File error
```text
CAN'T PLAY FILE
Skip / Back
```

### Low battery
```text
LOW BATTERY
Saving state...
```

### Charging
Battery icon/state only; playback remains usable if validated.

## 11. Interaction rules

### Playback screen
- Play/Pause: immediate.
- Next/Previous: immediate.
- Volume buttons: immediate with temporary volume overlay.
- UI work must not block audio.

### Library
- Controls must have an explicitly documented navigation mapping.
- If five buttons are insufficient for intuitive library browsing, a later rotary encoder may be added, but core playback buttons remain.

### Long presses
Use only if they create real value and do not make required actions ambiguous.

## 12. Error-state behavior

Error UI must be factual.

Bad:
- "Oops! Something went wrong!"

Good:
- "SD card removed"
- "Unsupported file"
- "Decoder error"
- "Battery too low"

Where possible show one actionable response.

## 13. Motion

Display animation must be restrained:
- short transitions;
- no continuous decorative animation during playback;
- avoid wasting CPU/power;
- no animation that can starve audio task.

## 14. Accessibility / usability

- high contrast;
- clear icons plus text where ambiguity exists;
- controls usable without color;
- playback usable with one hand;
- volume changes predictable;
- startup/error text readable;
- no essential status conveyed only by tiny icon differences.

## 15. PCB visual design

PCB should be functional and authored.

Silkscreen SHOULD include:
- NIGHTWAVE;
- board revision;
- USB/power labels;
- battery polarity;
- speaker polarity;
- button labels;
- test-point names;
- headphone label;
- small original music/night-themed art in unused space.

Silkscreen MUST NOT:
- obscure pads;
- cross keepouts;
- cover reference information needed for assembly;
- copy another project's artwork.

## 16. Color/material direction

Do not lock color until fabrication/print options are known.

Roles:
- enclosure base: neutral/dark;
- printed legends: high contrast;
- PCB soldermask may be chosen aesthetically only after fab availability/cost is confirmed.

No project decision depends on a specific color.

## 17. Renders

Required render set:
- PCB front;
- PCB rear;
- exploded assembly;
- finished front;
- finished rear/ports.

Renders must reflect actual final source files.

## 18. Build photography

Take real photos at:
- breadboard audio proof;
- schematic/PCB design screen;
- board arrival;
- bare board inspection;
- assembled PCB;
- first power;
- audio test;
- enclosure fit;
- final device;
- runtime test setup.

Photos are evidence, not decoration.

## 19. Demo video structure

Target 45–90 seconds of clear evidence.

Sequence:
- finished device beauty shot;
- SD card/music;
- boot;
- speaker playback;
- pause/play;
- next/previous;
- volume;
- headphone insertion and stereo demo explanation;
- quick internals/PCB;
- runtime result;
- closing shot.

No cinematic edit should hide whether the device actually works.

## 20. Anti-patterns

Avoid:
- giant enclosure to make CAD easy;
- exposed dev boards in final device;
- permanently dangling jumper wires;
- hot glue as core mechanical structure;
- unreadable display or lyric text;
- buttons with unclear behavior;
- fake album art;
- unnecessary RGB;
- menus deeper than the feature set justifies;
- excessive boot animation;
- decorative PCB routing that harms return paths/audio;
- a render-only "finished device" with no physical proof.

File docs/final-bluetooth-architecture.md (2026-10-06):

# Bluetooth architecture closure record - 2026-10-06

Conclusion: S3 decoded PCM -> BM83 I2S input -> A2DP headphones/speaker is
documented, but current firmware still uses UnavailableBluetooth. Capability
is not completed integration or physical proof. No PCB changes are authorized.

## SKU and firmware

Selected BM83SM1-00TA ships with AT v1.0 in Host mode. Its source path uses
SBC44.1/48 kHz, I2S or analog input. Tx AVRCP and HFP audio gateway are absent.
Use one receiver with concurrent BLE/dual-link disabled initially: published
errata include reconnection audio breaks and particular TWS incompatibility.
Pairing/discovery and auto reconnect exist, but a confirmed link event must
precede PCM release. [AT release notes](https://ww1.microchip.com/downloads/aemDocuments/documents/WSG/ProductDocuments/ReleaseNotes/BM83_AT_v1.0_Release_Notes.pdf).

New sourcing issue: [Mouser TA listing](https://www.mouser.in/en/ProductDetail/Microchip-Technology/BM83SM1-00TA?qs=W%2FMpXkg%252BdQ4DzNNx0q4h4Q%3D%3D)
marks TA NRND. Its indexed quantity-one INR1136.80 is a snapshot, not a quote.
[TB listing](https://www.mouser.in/en/ProductDetail/Microchip-Technology/BM83SM1-00TB?qs=XAiT9M5g4x%2FwGa5Oh0NFkA%3D%3D)
shows INR1165.59 and2140 stock (retrieved2026-10-06; shipping/tax unknown).
TB has [ATv1.0.1 release notes](https://ww1.microchip.com/downloads/aemDocuments/documents/WSG/ProductDocuments/ReleaseNotes/BM83-AT-v1.0.1-Release-Notes.pdf).
Recommendation: investigate TB for a new design. Builder decision requested;
no silent substitution. Firmware/package compatibility remains engineering work.

Actual local archive inspection: downloaded IS2083_Turnkey_1.2.0.zip contains
Config GUI1.3.08, isUpdate, SPKCommandSet206.003 and MSPK2v1.3 images; it does
NOT establish possession of an AT image. Do not flash MSPK image as a substitute.
TA documentation names Turnkey1.1.0, CommandSet2.07, Config1.2.25, isUpdate297.
Recoverable AT image and matching configuration workflow still need verification.

## Electrical/software interface requirements

S3 I2S clock host, BM83 client is the proposed single-clock configuration.
DR1 receives PCM; RFS1/SCLK1 are frame/bit clocks. MCLK1 is BM83 OUTPUT, never
drive it from S3. Use PCM16 stereo44.1/48 kHz initially; general silicon I2S
formats do not imply AT source encoder support at every rate. Low-rate tracks
need tested conversion; current HAL rejects unsupported rates.
[Module datasheet](https://ww1.microchip.com/downloads/aemDocuments/documents/WSG/ProductDocuments/DataSheets/BM83-Bluetooth-Stereo-Audio-Module-Data-Sheet-DS70005402.pdf).

Reserve UART host/wake/reset and independently accessible programming pins,
ground and supply; service must work without booting normal S3 software.
Provision source/client format then read back mode/input/rate. Supply3.6 V is
the reference target, not direct SYS. Disable/isolate internal charging and
prevent I2S/UART backfeed when rail is off. Decoupling, pull states and exact
service pin map must be reconciled against the selected firmware/module revision.
Both RF modules need manufacturer all-layer antenna exclusions; no invented
universal inter-antenna distance. Metal battery/speaker/fasteners count as obstacles.

50/100 mA AT-source loads are ESTIMATED. Published internal-codec receiver
current and continuous RF test currents are not source-playback measurements.
Shutdown cannot be modelled as zero until off-state pin leakage/backfeed is bounded.

## Digital implementation status

Implemented: bounded eight-device discovery, event epochs, connection/start
timeouts, PCM validation/backpressure, disconnect stop request, reconnect and
pairing states. Added checksummed versioned64-byte preferred-endpoint NVS record,
failure-safe decode and commit-result handling. Clearing the preference is NOT
erasing BM83 bond keys. New host tests cover every corrupted record byte, partial
records, NVS failures, stale events and timer wrap. No automatic speaker fallback.

Still engineering work: actual UART command queue/ACK/error recovery, variable
discovery event parsing, bond erase confirmation, output-router mute sequencing,
UI/persistence integration, PCM clock/rate conversion and diagnostics wiring.
Keep firmware backend unavailable until those are implemented; do not represent
these software tasks as awaiting physical hardware alone.

Best architectural fallback remains replacing S3 with ESP32-WROVER-E-N8R8:
single Classic-Bluetooth-capable MCU/antenna, but native USB is lost and GPIO,
decoder/SBC memory, timing and firmware need migration. Keeping S3 plus another
ESP32 adds a second firmware/transport and does not reduce RF integration work.
Not recommended over qualified BM83 solely to avoid resolving provisioning.
[Espressif A2DP API](https://docs.espressif.com/projects/esp-idf/en/stable/esp32/api-reference/bluetooth/esp_a2dp.html).

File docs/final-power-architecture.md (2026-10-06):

# Power architecture closure record

2026-10-06. Architecture direction selected by builder; detailed circuit NOT
released. No CAD generated or changed. DATASHEET denotes published limits,
ESTIMATED planning assumptions, CALCULATED arithmetic; MEASURED: none.

## Selected direction and alternatives

Builder approved development of 5 V-only USB-C sink, TUSB320LAI current detection,
protected reverse-blocked input and BQ25628E switching power path with charging
disabled by default at reset. This is NOT approval of the old CE-tied-low circuit.

| Candidate | Engineering comparison | Disposition |
| --- | --- | --- |
| BQ25628ERYKR | Switching NVDC power path; programmable current and status; needs inductor, careful hot-loop layout and fail-safe host policy | Selected direction, detailed implementation open |
| BQ24074RGTR | Standalone linear power path, simpler control; enclosed dissipation rises with charge current | Not preferred for compact charge-while-play |
| BQ25185DLHR | Standalone linear 1 A-class candidate, small package; slower cool charging or more thermal burden | Not preferred |
| MCP73871-2CCI/ML | Linear load sharing with USB low/high current control; larger support/thermal budget | Useful simpler alternative, not selected |

CALCULATED linear charger-only heat at 5 V input, 3.7 V cell and 0.96 A charge:
(5-3.7)*0.96 = 1.248 W, excluding system-path loss. Switching is recommended
for heat reduction, not because the reference already used it. Actual switching
efficiency depends on operating point and layout; model assumes 85%, not a guarantee.

Sources: [BQ25628E](https://www.ti.com/lit/ds/symlink/bq25628e.pdf),
[BQ24074](https://www.ti.com/lit/ds/symlink/bq24074.pdf),
[BQ25185](https://www.ti.com/lit/ds/symlink/bq25185.pdf),
[MCP73871](https://www.microchip.com/content/dam/mchp/documents/APID/ProductDocuments/DataSheets/MCP73871-Data-Sheet-DS20002090F.pdf).

## Required power tree

USB-C VBUS -> connector protection/inrush/reverse blocking -> BQ25628E VBUS.
Protected 1S pack <-> BAT; SYS -> controlled system switch -> 3.3 V logic/audio
regulation and separately controlled 3.6 V Bluetooth regulation. Speaker uses
reviewed SYS-derived supply, never an unqualified 5 V boost assumption.
MAX17048 senses the cell independently of the switched application rails.

## USB and startup requirements

TUSB320LAIRWBR is the proposed exact CC controller. Configure sink-only; its
internal Rd replaces, rather than parallels, discrete CC pull-downs. This is not
the older TUSB320: live current-advertisement behavior differs. Provide dead-cell
CC operation and avoid back-driving its unpowered pins. No PD voltages requested.
[TI TUSB320LAI datasheet](https://www.ti.com/lit/ds/symlink/tusb320lai.pdf).

Current policy must distinguish unattached/unknown, default USB, enumerated USB,
1.5 A and 3 A advertisements, suspend, detach and detection faults. Never equate
CC default with unconditional permission for 500 mA. Device design target is at
most 1.5 A even if source advertises 3 A. All limits need tolerance/headroom for
CC/protection current outside the charger measurement path.

Critical unresolved implementation: reset-default input restriction and safe
dead-battery startup must work before S3 firmware. CE high stops charging, NOT
system input draw. A weak/default source may require application rails held off
and low-power detection/control before boot. Cannot resolve this by merely setting
IINDPM after startup. Hardware current-limit switching/gating and its reset truth
table remain engineering work, not a builder preference question.

Protection candidate TPS25947 family offers reverse-blocking/inrush/OVP, but
exact suffix, clamp/threshold tolerance, low-current limiting range and coordinated
VBUS TVS remain unselected. A high-current eFuse is not automatically a compliant
100 mA startup limiter. Candidate TPD2E2U06DCKR for exposed USB data needs clamp,
capacitance and placement verification; CC needs separate ESD/short-to-VBUS review.
No final protection BOM claim is made.
[eFuse](https://www.ti.com/lit/ds/symlink/tps25947.pdf),
[ESD](https://www.ti.com/lit/ds/symlink/tpd2e2u06.pdf).

## Charger, thermal and fault policy

Proposed normal charge target 960 mA (ESTIMATED policy), limited further by the
eventual pack rating, source permission, available system power and temperature.
Keep safety timers enabled. DATASHEET table default: 14.5 h nominal, 10.5 h minimum,
15.5 h maximum; conflicting 12 h prose is recorded, not silently used. Dynamic
timer/termination behavior needs full stage review. Do not reset timer repeatedly
to force completion on a weak source.

CE requires a hardware default-off path surviving reset, watchdog, unpowered MCU
and I2C faults. Thermal safety cannot depend solely on firmware. NTC must be an
exact curve/tolerance, attached to the selected pack with open/short response
verified. The reference 103AT network's 0..60 C mapping is not compatible by
default with a 0..45 C pack. Thresholds, resistor tolerances and reset register
values remain unresolved; never disable TS protection to pass startup.

Charge-while-playing uses available input power first; charge reduces on overload,
then battery supplementation may occur. A plugged-in device can still discharge.
On source drop/detach, reduce allowed input without depending on slow UI tasks.
Dead-cell/absent-cell and poor-source boot must not oscillate indefinitely.

## Rails, shutdown and gauge

TPS63802DLAR remains a candidate for 3.3 V and 3.6 V regulation. DATASHEET 2 A
rating at 3.3 V for VIN>=2.3 V does not qualify the 3.6 V rail or every layout.
Verify inductance/saturation, effective DC-biased capacitors, current peaks and
thermal derating. Use 80/85% efficiency only as ESTIMATED screening inputs.
[TPS63802](https://www.ti.com/lit/ds/symlink/tps63802.pdf).

Low voltage: mute/stop playback, persist state once, stop SD access, then release
power hold; hardware supervisor/protection must cover brownout or wedged firmware.
Exact threshold/hysteresis and supervisor/latch parts remain pending rail/pack
review. Gauge SOC is telemetry, not the protection cutoff. Existing read-only
MAX17048/BQ25628E backend and shared-I2C owner are tested digitally; no charging
register writes or actual controlled-shutdown backend are yet qualified.

## Mode model and closure status

`tools/output_power_model.py` is the current exclusive-output model. Speaker,
wired and Bluetooth never stream simultaneously. BT-off assumptions require
verified shutdown/isolation; otherwise retained-radio overhead is a separate
sensitivity, not simultaneous Bluetooth audio. See output-power-estimates.md.

Architecture choice COMPLETE. Reset input gating, protection coordination,
NTC/reset safety, final support parts and closed-loop control remain IN PROGRESS.
These are agent engineering tasks, not falsely labelled blocked on the builder.

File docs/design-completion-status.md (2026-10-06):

# Design completion ledger - 2026-10-06

Target: complete, reproducible Nightwave digital design. T4 is a reviewer decision,
not a claim. This document is engineering status, not a personal work journal.

## Completed in this checkpoint

- Separate reference/legacy firmware profiles and schematic-to-firmware pin checks.
- Reference TCA9535 button sampling/recovery, initial TFT transport/text/lyrics,
  and corrected headphone-enable versus DAC-mute GPIO handling.
- Explicit IC pin types in generated schematics, including BM83 MCLK direction;
  external supply/ground declarations instead of an all-passive ERC model.
- Schematic-only generation preserves existing project rules and footprint files.
- Packaging checks typed ERC as well as DRC/parity; it must not archive a failing
  native report or silently claim that digital checks certify electrical safety.
- Native ERC negative controls pass: deliberately conflicting outputs and a
  removed battery power declaration are both rejected in isolated design copies.
- Core scope documents explicitly distinguish the current reference architecture
  from historical charger, OLED/direct-button, power and authorship workflows.

## Executed checkpoint evidence

Latest software source `161cbc9711793a3932db5e07af251155a77d53fb` is pushed to
`main`. [Quality run 37445159892](https://github.com/Hustlenix/Nightwave/actions/runs/37445159892)
passed all 18 Release suites, all 18 ASAN/leak suites, 46 Python tests and the
project/reference validators. Both reference and bench ESP32-S3 builds passed
[firmware run 37445159915](https://github.com/Hustlenix/Nightwave/actions/runs/37445159915).
This adds serialized shared-I2C device registration and host concurrency,
ownership, timeout and partial-read failure tests against the actual adapters.
Charger timer screening now uses the Rev C table values (10.5 h minimum,
14.5 h nominal, 15.5 h maximum), with the conflicting 12 h prose recorded.
These changes do not alter or qualify the PCB, battery, USB interface or enclosure.

Earlier native CAD checkpoint (CAD unchanged by the latest software source):

Source `add96254341f786c73a4e9cfb6795bf37f1b4b58` is pushed to `main`.
[Project quality run 37441295569](https://github.com/Hustlenix/Nightwave/actions/runs/37441295569)
passed all 15 Release suites, all 15 AddressSanitizer/leak suites, 39 Python
tests and project/reference validators. Hardware tests remain unperformed.
Local native KiCad reports show zero ERC, DRC, unconnected and parity findings.
Both reference and legacy bench ESP32-S3 jobs passed in
[firmware run 37441295524](https://github.com/Hustlenix/Nightwave/actions/runs/37441295524).

## Still open; do not label the design complete

Continuation after add9625: shared I2C ownership and read-only MAX17048/BQ25628E
power telemetry are implemented; host conversion/failure tests pass locally.
The new reference-specific power calculation exposes concrete blockers:
320 mA default charging versus 10.05 Ah/10.5-hour minimum timer, >2 A transient harness
screen, USB current permission and pack-compatible temperature policy.
These are not resolved by reading registers. Source
b7566f34de4ed5d4800aa6802087daeb4587eb0e is pushed. Quality run
[37443602845](https://github.com/Hustlenix/Nightwave/actions/runs/37443602845)
passed 16 Release/16 ASAN-leak suites and 42 Python tests; both firmware
profiles passed [37443602596](https://github.com/Hustlenix/Nightwave/actions/runs/37443602596).
Procurement follow-up resolves 49 resistor MPNs against primary manufacturer
specifications; 48 other entries and complete current pricing remain open.

| Work | Exit evidence |
| --- | --- |
| Pixl authorship eligibility | Organizer clarification covering the actual AI-authored CAD, plus honest disclosure |
| Physical envelope/budget | Decided: PCB <=90x60 mm target, device about <=110x70x25 mm, INR15,000 electronics + PCB/assembly excluding tools. Final PCB/CAD builder-authored; feasibility and quotes remain open. See compact-builder-constraints.md. |
| USB source-current policy/protection | Reviewed CC/USB enumeration policy, startup current, ESD and connector implementation |
| Charger/battery safety | Verified limits, NTC curve/attachment, default/reset behavior, charge timing and pack approval |
| Power/current budget | Mode-specific calculations including transient load, connector/wire/copper limits and estimated runtime |
| Purchaseable BOM | Exact passives/NTC/harness/connector MPNs, ratings, availability and complete priced total |
| Mixed-signal layout | Reviewed switching loops, return paths, current necks, RF clearances, USB impedance and assembly process |
| Product firmware | BM83 live transport/provisioning, rate compatibility, real power backend, status/SD handling and improved TFT UI |
| Enclosure | Editable complete assembly, realistic component bodies, retention and interference/tolerance checks |
| External review | Named independent human review and resolution of material findings |
| Final build | Real assembly, listening/thermal/fit tests, overnight runtime, photos and video after funding |

No purchase, fabrication order, Pixl submission, organizer message or human
review has been performed by this checkpoint. No approval is inferred from CI.

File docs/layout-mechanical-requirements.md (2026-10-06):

# PCB and enclosure requirements for builder authoring

## Current compact-design override - 2026-10-06

Use [compact builder constraints](compact-builder-constraints.md): PCB target
90 x 60 mm, device about 110 x 70 x 25 mm, electronics/PCB assembly INR15,000
excluding tools. Builder authors final PCB and enclosure CAD. The AI reference
is not the final layout. Battery is unselected; old pack/package examples below
are historical unless reconciled with the current reference BOM. BQ25628E and
MAX98357A replace older options in the reference, still requiring review.

2026-10-01. Requirements and candidate constraints only. No outline, placement,
routing, footprint or enclosure source has been authored/verified here. Builder
must select dimensions/stackup, author files and return them for source review.

Final-addendum gate: Bluetooth/display decisions must precede final layout/CAD.
Use their exact module/panel/cable/antenna envelope, not the historical OLED
window. Recalculate pack/charging/thermal space from expanded engineering budgets.

BD-14 now retains S3 and selects BM83SM1-00TA: reserve its 32 x 15 x 2.5 mm
module envelope plus manufacturer land pattern, antenna exclusion and UART/
reset/provisioning access. Both RF modules need their own reviewed antenna
space, kept away from pack/speaker/metal and each other; nominal body area is
not the RF envelope. BD-15 selects Waveshare 24382 non-touch: 31.5x39 mm board,
27.972x32.634 mm active area with maker R5 corner description. Thickness,
mount-hole datum, glass projection, MX1.25 cable bend/mate and lens tolerance
require the exact supplied drawing. BD-16 selects TCA9535PWR TSSOP-24;
reserve its verified land pattern and input pull-ups, not a module-sized box.
The recalculated pack remains unselected. The old
OLED cutout and 6600 mAh pack dimensions below are historical examples only.

## Footprint verification register

| Candidate | Source/package fact | Source-file verification still required |
| --- | --- | --- |
| ESP32-S3-WROOM-1-N16R8 | Module 18x25.5x3.1 mm; manufacturer land pattern | Module-pad/GPIO mapping, center ground pad, antenna exclusion, height/tolerance |
| PCM5102APWR | TI PW TSSOP-20 | Exact pad pitch/body, pin 1, analog/digital grounds, model rotation |
| TPA6132A2RTER | TI RTE WQFN-16, 3x3 mm | Exposed pad, paste/vias, charge-pump pin mapping |
| MAX98360CEFB+T | ADI ordering table: 10-pin FC2QFN, NOT WLP | Corrected October 2023 OUTP/OUTN map; exact outline/land pattern, assembly support |
| BQ25185DLHR | TI DLH WSON-10 2.2x2 mm, unresolved choice | Thermal pad/paste, polarity, charger decision |
| BQ25628E alternative | TI RYK WQFN-18 2.5x3 mm, unselected | Full drawing/pad map, power components and assembly quote |
| TPS63802DLAR | TI DLA 10 numbered pins plus exposed pad | Copper/paste/thermal connection, switch pins, regulator-loop geometry |
| MAX17048G+T10 | ADI TDFN-EP 8, 2x2 mm; outline 21-0168, land pattern 90-0065 | VDD sense versus CELL, EP ground, pad numbering/model |
| USB4105-GF-A | GCT series page: 3.31 mm profile, 7.35 mm body length | Exact suffix/stake length/locating pegs drawing; board edge/mating envelope |
| Molex 104031-0811 | Manufacturer part page located | Actual sales drawing/pin table/detect switch/card insertion envelope |
| SJ-3503-SMT-TR | Indexed maker drawing identifies sleeve/tip/ring and two audio switches; full PDF returns 403 | Full drawing/pad map and physical continuity; no isolated digital detect assumed |
| BM83SM1-00TA | Selected 50-pad module, 32 x 15 x 2.5 mm | Exact land pattern, second antenna keep-out, test/provision access, assembly height |
| Waveshare 24382 non-touch TFT | Selected 31.5x39 mm board; 27.972x32.634 mm active area | Exact drawing/revision/thickness/mount/cable/mate and window tolerance |
| TCA9535PWR input expansion | Selected TSSOP-24 PW | Exact pin-1/pad pitch/land pattern and external pull-ups; no floating inputs |
| Switches, speaker/battery/display connectors | Exact choices not locked | Maker drawings, hole/pad numbering, cable/actuation/clearance envelopes |

Source links and electrical roles: [schematic requirements](schematic-requirements.md).
Body dimensions are not pad dimensions and a 3D model does not prove a footprint.
Package suffixes are engineering inputs, not interchangeable names.

For every actual footprint: compare top/bottom view, pin-1 landmark, pitch,
pad size, thermal pad net, solder-mask/paste, drills/slots, courtyard and height
against its dated manufacturer drawing. Save a dimensioned comparison and
source URL/revision. Inspect actual KiCad library and placed-instance overrides.
Third-party downloads remain unverified until compared. No register row is PASSED.

## Stackup and fabrication

Four layers are a candidate for continuous returns and compact power/audio
routing, not a builder selection. Candidate topology: top components/signals,
adjacent continuous GND, inner power/slow signals, bottom signals/ground. Two
layers require proving returns and fitting exact packages without risky necks.

[JLCPCB capabilities](https://jlcpcb.com/capabilities/pcb-capabilities) is a
comparison source, not a quotation or committed manufacturer. Choose a real
service/stackup and capture copper weights, thickness, drill/annular ring,
trace/space, edge clearance, mask/paste, via treatment and assembly capabilities.
Fine-pitch FC2QFN and any WLP option need package-specific assembly confirmation.
Do not equate advertised PCB minimum trace width with supported assembly.
Do not order, buy or export a fictional manufacturing-ready package.

## Placement and electrical constraints

[Espressif layout guidance](https://docs.espressif.com/projects/esp-hardware-design-guidelines/en/latest/esp32s3/pcb-layout-design.html):
place module antenna toward/outside board edge where practical, maintain its
specified all-layer exclusion and account for enclosure/battery/speaker metal.
Recommended housing clearance around antenna is at least 15 mm. Native USB
uses continuous reference, 90 ohm differential ±10%, minimal transitions with
return vias. SDIO recommendations include 50 ohm ±10%, short routes and matched
CMD/DAT versus CLK. Use actual stackup impedance calculation, not guessed widths.

Keep converter/charger hot loops compact using each selected IC's layout
reference. Put input/return decoupling directly at pins; keep SW copper away
from DAC/headphone inputs, I2C and RF. Keep FB sense separate from noisy nodes.
Use a continuous ground return rather than blindly splitting analog/digital
grounds. Do not send switching/speaker supply return through headphone ground.
Keep DAC/amp analog traces short and symmetric where appropriate. Route I2S
over ground, review fanout capacitance and source damping after edge-rate data.

Route SPK_P/N together with short, adequately wide traces; neither is ground.
Account for DC/RMS and switched-current losses, connector contact resistance,
via/bottleneck resistance and speaker cable EMI. Keep headphone traces away
from that pair. Protection parts belong near exposed connectors with a short
return. Route input and battery power for worst-case validated current.

Builder width calculation example: copper resistivity assumed 1.72e-8 ohm-m,
50 mm long, 1 mm wide, 35 um thick trace gives 24.6 mohm. At 1.5 A this is 36.9 mV
drop and 55.3 mW per trace, excluding vias/connectors and temperature rise. A
similar return doubles path loss. This is NOT IPC thermal/current qualification.
Set allowed drop/temperature first, then size copper and validate physically.

Required checks: schematic/netlist consistency, no unconnected critical pins,
manufacturer DRC, plane continuity, power-loop review, RF keepout, test access,
mounting holes free of unintended copper and silkscreen polarity/revision.
Record every intentional waiver with reason; a zero DRC count is not a design
review. Final exports must be tied to the reviewed source commit.

## Mechanical dimensions and tolerances

Create a shared datum: PCB origin, top surface Z=0, port mating planes, display
active-area datum, button axes and mounting-hole coordinates. Record mm and
orientation. Builder chooses board outline from actual component/service
envelopes, not a generic pocket-size rectangle.

The historical, unselected 6600 mAh pack example is about 69x54x18 mm and 155 g; see
[supplier page](https://www.adafruit.com/product/353). Allow cable, connector,
retention and inspection space. Do not compress/pierce cells, use sharp bosses
against wraps or place a hot charger against the pack. Do not assume that an
estimated runtime justifies this size/weight or fixes the supplier-current issue.
The indexed [speaker maker datasheet](https://www.sameskydevices.com/product/resource/cms-28528n-l152.pdf)
lists diameter 28 mm, height 5.2 mm, weight 7.8 g and 750 Hz nominal resonance.
Full PDF access returned 403; wire/retention/tolerance drawing remains pending.
The base suffix has wire leads without connector; A and B specify different
mating housings. Do not budget a pre-attached connector for the base suffix.
BD-15's SKU is selected, but glass/cable/mate and mount-hole source dimensions
still need verification; never infer coordinates or thickness from a product photo.

Proposed fit starting points, NOT manufacturing guarantees: 0.3–0.5 mm clearance
per side for rigid printed sliding fits, 0.5 mm electrical part-to-wall reserve,
and 2 mm wall thickness. Builder must choose printer/material, run a tolerance
coupon and adjust; different processes require different values. Battery safety,
thermal, RF and moving-control clearances override these examples.

Use worst-case tolerances: minimum cavity minus maximum component size minus
retention/assembly reserve must stay positive. Include board thickness, solder
height, connector stake projection, print shrink/warp and fastener protrusion.
Do not call an overlap-free ideal STEP assembly a tolerance analysis.

## Retention, acoustics, controls and service

- PCB: actual screw/boss coordinates with insulating standoff height; no loose
  board. Choose screw/insert drawing, engagement and boss wall thickness before
  holes. Keep screws away from battery, traces and antenna keepout.
- Pack: removable cradle/strap or rated retention method with strain relief.
  Account for the selected pack's mass/inertial loads, no conductive abrasion and NTC contact.
- Speaker: secured flange/holder, gasket if appropriate, clear cone travel,
  isolated front/back paths. Choose acoustic cavity/grille based on actual
  speaker data and listening; no fabricated tuning or sound-pressure result.
- Display: secure mounts, glass not carrying enclosure screw force, aligned
  visible area with cable bend/connector removal access.
- Buttons: guide axes, rest preload, full switch travel, overtravel stop, return
  force and tolerance stack. Do not claim five plungers work from a render.
- Ports: plug-body/cable clearance, insertion/removal grip, USB/card/jack datum
  alignment, no side force on solder joints. Battery must remain serviceable.
- Assembly: documented order with screws/tool path, no trapped connectors,
  NTC/speaker wiring separated from switching nodes, no wire crushed by lid.
- Thermal: preserve charger/regulator heat paths and evaluate safe touch/cell
  temperatures later. Venting assumptions are not measured cooling performance.

Builder returns editable CAD plus electronics-inclusive STEP, dimensioned port
and mounting drawings, tolerance table, section views, interference results and
exploded assembly. Review starts with source dimensions and actual components.
STL alone is not an editable design. No final enclosure is authored here.

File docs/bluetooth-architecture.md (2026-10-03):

# BD-14 Bluetooth architecture

Checked 2026-10-02. **Builder selected A in chat: retain S3 + BM83SM1-00TA.**
The comparison is preserved for traceability. Selection is not transmitter-tool,
interoperability, power or physical validation. Personal reasons were not supplied.

| Item | A — S3 + BM83 (selected) | B — replace main MCU | C — S3 + ESP32 coprocessor |
| --- | --- | --- | --- |
| Exact hardware | Existing ESP32-S3-WROOM-1-N16R8 plus Microchip **BM83SM1-00TA** AT-preprogrammed module | **ESP32-WROVER-E-N8R8**, 8 MB flash/8 MB PSRAM | Existing S3 plus **ESP32-WROVER-E-N8R8** |
| Profiles/source | AT v1.0: A2DP 1.3 **source**; Tx AVRCP/HFP AG **not supported** | Classic BT 4.2; source A2DP and AVRCP via selected/tested stack | Same Classic source capabilities, second custom firmware |
| S3 interface | PCM I2S + UART host control, MFB wake/P0_0 UART_TX_IND, reset and separate service/configuration access | None: platform replacement. Native S3 USB lost; UART service needed | I2S receive or framed SPI PCM + UART/control; clock/queue protocol required |
| Firmware work | Medium/high: bounded AT protocol/events, provision tools, disconnect/mute, rate handling | High: port GPIO/SD/I2S/USB/PSRAM plus SBC/source queues and resource profiling | Highest: two images, transport/clock bridge plus SBC, recovery and updates |
| Audio | AT SBC encode **44.1/48 kHz**, I2S/Aux input. No AAC/AVRCP Tx promise | PCM16 decode -> SBC at qualified 44.1/48 rates; pin encoder/API version | Same, plus bridge framing/clock-domain handling |
| Power | Exact AT-source average unknown. **50 mA at 3.7 V is an estimate**, not a module rating; qualification must replace it | Whole MCU + concurrent decode/SBC/radio unknown; Wi-Fi datasheet current is not BT playback current | Additional MCU/radio load; no credible measured advantage over A |
| Module price/stock | **$12.20; 30** listed; standard lead 17 weeks | **$5.88; 16,392** listed; 8-week standard lead | Extra **$5.88** module, same snapshot; additional support circuitry |
| Area | BM83 **32x15x2.5 mm**, 480 mm² added before pads/keep-out/support | **18x31.4x3.3 mm**, 565.2 mm² main module before keep-out | Adds 565.2 mm² plus bridge/passives to S3 area |
| RF | Integrated antenna; two antenna locations, vendor keep-outs and disabled unused S3 radio | One PCB antenna; follow module land/placement guidance | Two antennas; separation/coexistence qualification |
| Latency | No universal vendor guarantee; endpoint + SBC/buffers dominate | Same, plus configured source queues | Same, plus bridge queues |
| Main risks | AT tool/package access, 22.05/32 conversion, headphone interop, supply/backfeed, Tx has no AVRCP | Platform migration, no native USB, scarce internal RAM, decode/SBC/display contention | Highest firmware/scheduling/clock risk and two-system failure handling |

Prices are USD quantity-one seller snapshots, not quotes; exclude carrier,
programmer, passives, delivery, import tax and assembly. Availability can change.
[BM83 seller](https://www.digikey.com/en/products/detail/microchip-technology/BM83SM1-00TA/12807564),
[WROVER seller](https://www.digikey.com/en/products/detail/espressif-systems/ESP32-WROVER-E-N8R8/11613126).

Recommendation was A to preserve the validated S3 pipeline. The builder has now
chosen it; do not switch to B/C or generic BM83SM1-00AA without a new choice.
S3's BLE does **not** supply Classic A2DP or LE Audio.
[Espressif audio support](https://docs.espressif.com/projects/esp-adf/en/latest/solution-center/bluetooth-audio.html).

## Selected-path qualification and constraints

AT v1.0 identifies UART CommandSet 2.07, ConfigTool 1.2.25, isUpdate 297 and
SPKCommandSet 202.253 under IS2083 Turnkey 1.1.0/AT v1.0. Actual usable package,
access/licence and on-module version compatibility remain unverified. Public
command documentation has now been inspected as described below. Do not invent
UART opcodes. Release notes identify dual-link/TWS and BLE coexistence problems
and FreeBuds 3 incompatibility. Start with one receiver and no concurrent BLE.
[Microchip AT release notes](https://ww1.microchip.com/downloads/aemDocuments/documents/WSG/ProductDocuments/ReleaseNotes/BM83_AT_v1.0_Release_Notes.pdf).

BM83 supply/IO limits, MFB/P0_0 wake direction, I2S master/slave clocks and
provisioning access must be traced to the exact module drawing. SYS_PWR is
internal, not a peripheral supply. Disable/isolate the module charger; never
parallel it with Nightwave's charger. Preserve antenna keep-out and modular
approval constraints; module certification is not final-product compliance.
[BM83 datasheet](https://ww1.microchip.com/downloads/en/DeviceDoc/BM83-Bluetooth-Stereo-Audio-Module-Data-Sheet-DS70005402D.pdf).

22.05/32 kHz tracks need a validated converter for this route; current HAL
explicitly rejects them rather than misclocking. Local outputs retain those
rates. Allocate an initial **100–300 ms test window**, not promised latency;
measure drift/reconnect/endpoint delay and lyric correction. No automatic loud
speaker fallback after radio loss. Unsupported adapter remains unavailable.

Portable `BluetoothSource` bounds discovery to eight devices, checks event
epochs, requires explicit choice, times out discovery/connect/start, propagates
PCM backpressure and requests stop on loss. Callbacks must queue fixed events;
backend connect cancels discovery. It is not a working BM83 UART/radio adapter.
`Bm83Uart` adds fixed 256-byte framing/checksum and fragmented-input timeout
tests from the manufacturer protocol example. It implements no guessed AT
discovery/source command semantics. `Bm83AtCodec` now encodes documented AT
discovery/cancel, TX selection, I2S input, 44.1/48 rate, queries and packet gating,
and validates fixed status reports. It does not connect devices, manage ACKs,
send PCM or declare a working backend. Packet gating is not AVDTP start/suspend.
[Microchip host UART guide, sections 5.2–5.3](https://ww1.microchip.com/downloads/aemDocuments/documents/OTH/ProductDocuments/UserGuides/BM83_Host_MCU_Firmware_Development_Guide_DS50002896A.pdf).
Do not claim pairing, transmission or runtime before actual qualification.

The manufacturer-linked [Turnkey 1.2.0 archive](https://ww1.microchip.com/downloads/en/DeviceDoc/IS2083_Turnkey_1.2.0.zip)
was downloaded read-only (38,375,334 bytes; SHA256
`426e6f7c2d2575ed820affb4f2ada0bd98aa543ed18df7e7c0ae64dbfdd101a7`).
Its `AudioUARTCommandSet_v2.08.pdf`, sections 5.1.63/7.65, contains AT commands
and status events. Tables were text/visually reviewed. The discovery/EIR length
wording needs on-module verification, so variable discovery payloads are not
guessed. Changing TX mode requires reset/reverification; changing input/rate
interrupts DSP. Vendor tools were not executed; actual AT image/tool/licence
and compatibility with selected TA's documented v2.07 remain qualification items.
Current [module datasheet Rev. H](https://ww1.microchip.com/downloads/aemDocuments/documents/WSG/ProductDocuments/DataSheets/BM83-Bluetooth-Stereo-Audio-Module-Data-Sheet-DS70005402.pdf)
and [AT v1.0.1 release notes](https://ww1.microchip.com/downloads/aemDocuments/documents/WSG/ProductDocuments/ReleaseNotes/BM83-AT-v1.0.1-Release-Notes.pdf)
were also located; the latter identifies **00TB**, not an automatic replacement
for builder-selected **00TA**. Do not silently change SKU/firmware.

Alternative ESP32 implementation must pin and test its IDF/SBC combination:
current IDF source send APIs take encoded buffers with MTU/ownership rules,
not an older PCM callback copied blindly.
[ESP-IDF A2DP source API](https://docs.espressif.com/projects/esp-idf/en/stable/esp32/api-reference/bluetooth/esp_a2dp.html),
[WROVER dimensions/RF guidance](https://documentation.espressif.com/esp32-wrover-e_esp32-wrover-ie_datasheet_en.html).

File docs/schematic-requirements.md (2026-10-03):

# Schematic mentoring and review requirements

Entry gate: BM83SM1-00TA (BD-14) and Waveshare 24382 non-touch (BD-15) are builder-selected.
Do not start Builder Task 1 until the current software checkpoint is pushed and
verified, selections propagated, selected BD-16 input strategy mapped/reviewed and the new
power/charger/pack/BOM/pin budget reviewed. See current-power-model.md and
pin-budget.md. The legacy OLED footprint and two-output map are not final.

Selected Bluetooth block must reserve the exact 50-pad BM83 land pattern,
qualified 3.2–4.2 V rail, UART, MFB, provisioning/boot, reset and reviewed I2S
clock/rate interface. Disable its internal charger with the external product
charger; evaluate powered-off audio/control backfeed. Preserve AT firmware
provision/recovery access and both module antenna keep-outs. Public framing
support is not qualification of source commands, firmware access or a headset.

BM83 P0_0 is a configuration-dependent UART_TX_IND host-wake output, not the
Test-mode strap. P3_4/SYS_CFG supplies reset-time Test-mode access in public
documentation and can also be RTS. Review the exact TA AT image's functions;
preserve safe service access and do not treat every service signal as free GPIO.
Candidate BQ25185 SYS is 4.5 V in adapter mode and must not directly feed BM83;
PENDING_BT_POWER_RAIL makes the unresolved supply explicit in the BOM.

Checked 2026-10-01. This is a requirements/reference packet, not a complete
netlist or final schematic. The builder chooses parts/values and draws the
actual KiCad sheets. Numbers below are reference values or calculated examples,
not component lock. Use exact package pin tables, never a breakout's labels as
an IC pin map. Review the actual files before marking any connection correct.

## 1. ESP32-S3 module

[Module datasheet](https://www.espressif.com/sites/default/files/documentation/esp32-s3-wroom-1_wroom-1u_datasheet_en.pdf),
pin definitions, reference schematic and land pattern. N16R8 contains flash,
PSRAM, crystal and RF circuitry: do not duplicate a bare-chip reference circuit.
Connect 3V3 and all module grounds, including the center grounding pad. EN is
reset/enable, GPIO0 selects recovery boot, GPIO19/20 are USB D-/D+. Do not use
octal-PSRAM GPIO35–37. Check module-pad numbers separately from GPIO numbers.

[Espressif checklist](https://docs.espressif.com/projects/esp-hardware-design-guidelines/en/latest/esp32s3/schematic-checklist.html)
recommends 3.3 V, at least 500 mA capability for the MCU supply, local bulk and
decoupling, and typically 10 kohm/1 uF EN RC. EN must not float. The RC time
constant is 10 ms, not proof of reset timing for a slow-rising supply. Consider
a supervisor if needed. Keep GPIO0 accessible and avoid a large boot-pin cap.

Review: annotate module variant, EN startup, boot states, reserved pins and
reset/programming access. Unused pins need intentional NCs, not hidden errors.

## 2. USB-C input and service

[GCT USB4105](https://gct.co/connector/usb4105): import the exact suffix drawing
before footprint approval. Decide power-only versus native USB; existing docs
disagree and GPIO19/20 are reserved, not a proven wired interface. In a passive
sink each CC has its own Rd; do not join CC1 and CC2. Account for both connector
orientations, shield stakes, VBUS transient protection and input inrush. D+/D-
need low-capacitance protection and impedance-controlled routing if used.

[TUSB320](https://www.ti.com/lit/ds/symlink/tusb320.pdf), sections 5, 7.3/7.4:
candidate CC current detector with internal Rd in sink mode; do not parallel
extra Rd without checking the implementation. PORT defines sink role, CC1/2
sense attach/current, VBUS_DET senses input, ADDR selects I2C or GPIO reporting,
EN_N controls operation. Its initial GPIO current result is not continuously
updated; I2C refresh needs the documented procedure. Check dead-battery and
powered-off backdrive conditions. This is not a USB-PD controller.

Review: default input cap before MCU boot, authorized current after attach,
detach/advertisement-change fallback, host eligibility and no reverse feeding.
Source-current permission is independent of a charger's programmed limit.

## 3. Charger and power path

See [power options](power-options.md). BQ25185 remains an unresolved candidate,
not a locked answer for the larger pack. IN receives protected VBUS, BAT the
protected pack, SYS the system load; these are different nets. ILIM/VSET selects
input/voltage and ISET selects charge current. TS/MR senses temperature/reset,
CE controls charging, STAT outputs need appropriate pull-ups.
[BQ25185](https://www.ti.com/lit/ds/symlink/bq25185.pdf), pin table and sections
6.3/7.2. Check capacitor derating, cell voltage, NTC and timer explicitly.

For a switching alternative, inspect BQ25628E sections 6, 8.3, 8.6, 9 and 11.
Builder must independently derive its bootstrap, inductor, bias, ILIM/TS and
reset-state circuit from that reference. Do not copy an EVM without explaining
why each populated component is needed. Charging faults must remain visible.

Review: charging with MCU absent/reset, unplug behavior, no-battery behavior,
timer/termination, real cell temperature and source current under playback.

## 4. 3.3 V regulator and master shutdown

[TPS63802](https://www.ti.com/lit/ds/symlink/tps63802.pdf), pin table, section 10
and package drawing. VIN is system input, VOUT regulated output, L1/L2 switching
inductor nodes, FB senses the divider, EN enables, MODE sets operating policy,
PG reports power-good. Tie/decouple every ground/supply as specified. Reference
3.3 V divider is 511 kohm/91 kohm with 0.5 V feedback; calculated nominal is
3.3077 V. The example 0.47 uH inductor and 10/22 uF caps require saturation,
DC-bias and layout verification. Ten numbered pins plus exposed pad is not an
arbitrary eleven-pin symbol. Verify at minimum input and peak load.

Review: SYS-fed speaker and regulator both turn off when requested; charging
can remain available. A GPIO called POWER_HOLD does not create a latch. Define
startup/wake, loss of firmware control and low-battery hardware behavior.

## 5. Fuel gauge

[MAX17048](https://www.analog.com/media/en/technical-documentation/data-sheets/MAX17048-MAX17049.pdf),
pin descriptions and application examples: VDD goes to protected battery positive
and is the MAX17048 voltage-sense input, bypassed by 0.1 uF. CELL is not internally
connected on MAX17048 (unlike MAX17049); follow its application wiring, not a
guessed sense circuit. CTG, GND and exposed pad go to ground. QSTRT goes low if
unused. SDA/SCL and active-low ALRT use the correct logic-domain pull-ups.

Review: gauge remains battery-powered when the player is off, switched 3.3 V
bus does not back-power the MCU, SOC remains an estimate, alert acknowledgment
and low-battery thresholds have a documented hysteresis/recovery policy.

## 6. microSD

[Molex 104031-0811](https://www.molex.com/en-us/products/part-detail/1040310811)
requires the real contact-number drawing, insertion envelope and switch diagram.
VDD is 3.3 V; CLK/CMD/DAT0 implement the current one-bit firmware. DAT1/2/3 still
need intentional bias. Card detect is a separate switch, not a data contact.
[Espressif SD pull-up requirements](https://docs.espressif.com/projects/esp-idf/en/stable/esp32s3/api-reference/peripherals/sd_pullup_requirements.html):
external 10 kohm pull-ups on CMD and DAT0–3 are required even for one-bit use.

Review: local decoupling/inrush, detect polarity, ESD, no 5 V contacts, removable
card accessibility. Firmware does not currently provide automatic hotplug remount.

## 7. Selected display: Waveshare 24382 non-touch

BD-15 is recorded: 240x280 ST7789V2 SPI, 3.3 V supply and logic, six independent
GPIO signals MOSI/SCLK/CS/DC/reset/PWM backlight. Review the exact MX1.25 8-pin
cable pinout, mating connector MPN/footprint, backlight input limits, reset and
powered-off behavior against the supplied revision. A module drawing is not
a bare-controller footprint. Budget 90 mA maximum maker allowance and bounded
RGB565 tiles; no verified ESP-IDF driver or final combined GPIO map exists.
See display-selection.md, pin-budget.md and current-power-model.md.

### Historical OLED bench reference, not the final product

SH1106-compatible is not an exact purchasable module definition. Obtain the
module maker's pinout, drawing, supply limits, address straps, controller and
mounting pattern. Current driver defaults to SH1106 128x64/0x3c and a two-column
glass offset, with SSD1306 option. Bare panel VCC/charge-pump circuitry is not
equivalent to a four-pin breakout supply. Do not approve the old unverified
SP12864-13 label without supplier evidence.

Review: 3.3 V logic, pull-up rail (not 5 V), optional reset GPIO40 if present,
module height/window/mounts and switched-off bus behavior. No new exact module
or price is asserted here.

## 8. Five buttons

Legacy bench firmware uses active-low switches to ground, GPIO1/2/4/10/15.
BD-16 moves product buttons and slow SD/charge/gauge inputs to TCA9535PWR;
exact port allocation, IRQ GPIO/address straps and debounced frontend integration
remain pending. All 16 ports stay inputs with external defined levels; do not
move mute, power hold or timing signals into this input-only contract. Select
exact momentary switch MPN, actuation force, lifetime, travel and actuator height.
External pull-up choices must account for leakage/off state. Avoid a large RC
that invalidates debounce or creates slow noisy edges. Firmware debounce is
25 ms, hold threshold 700 ms; a held control must not accidentally act as boot.

Review: map previous/play/next/volume-down/up consistently, inspect multi-pad
switch commoning, protect exposed long wires, give every button a real mount.

## 9. PCM5102A DAC

[PCM5102A](https://www.ti.com/lit/ds/symlink/pcm5102a.pdf), pin table and figure
33: BCK/LRCK/DIN receive I2S; SCK is handled per three-wire PLL mode, not floated
by accident. FMT low selects I2S, FLT/DEMP need deliberate straps. XSMT is active-
low mute. AVDD/DVDD/CPVDD, LDOO, VNEG and CAPP/CAPM need the specified supply,
decoupling and charge-pump connections. OUTL/R are line-level, not headphone
drivers. Reference full scale is 2.1 Vrms. Use the reference output filtering.

Review: part-specific pin numbering, pump loop, analog returns and mute timing.
At 22.05 kHz the 150-sample-plus-0.2-ms mute interval is about 7.0 ms. Current
GPIO18 was a prototype DAC-mute control; its relationship to final amp EN must
be explicitly designed, not assumed equivalent.

## 10. Headphone amplifier

[TPA6132A2](https://www.ti.com/lit/ds/symlink/tpa6132a2.pdf), pin table, gain table,
single-ended input and charge-pump examples. EN enables; G0/G1 select -6/0/3/6 dB
(both low is -6 dB). INL/R pairs need the documented single-ended configuration,
not arbitrary grounding of an input. CPP/CPN, HPVSS/HPVDD and supply caps support
the internal pump. OUTL/R connect to headphone tip/ring; sleeve is signal ground.

Review: DAC input amplitude versus amp clipping and chosen loaded output ceiling,
input capacitor high-pass corner, gain straps, enable default low and hotplug
noise. At 2.1 Vrms DAC full scale, -6 dB alone predicts 1.052 Vrms before clipping.
See calculations; no fixed voltage is claimed safe for every headphone or ear.

## 11. Speaker amplifier

[MAX98360 family](https://www.analog.com/media/en/technical-documentation/data-sheets/MAX98360A-MAX98360D.pdf),
DAI configurations and exact package drawing. BOM suffix CEFB+T is 10-pin
FC2QFN, not the CENL+T 9-ball WLP. Supply range is 2.5–5.5 V. EN enables,
GAIN_SLOT selects fixed gain/slot, DAI0/1/2 wiring selects input mode/channel.
Do not copy MAX98357A breakout labels to this device. For 6 dB I2S reference,
GAIN_SLOT is tied to VDD; verify DAI configuration for the intended mono stream.
Local reference supply caps are 10 uF and 0.1 uF. OUTP/OUTN are differential BTL.

Review: exact-package assembler capability, corrected OUTP/OUTN pin map
(October 2023 revision), gain/format, disabled boot,
peak supply/thermal limits, short output loop. Never ground either speaker output
or use a grounded scope probe there. Differential instrumentation is required.

## 12. Headphone jack and detect

The indexed [SJ-3503-SMT-TR maker drawing](https://www.sameskydevices.com/product/resource/sj-3503-smt-tr.pdf)
identifies 1=sleeve, 2=tip, 3=ring, 4=tip switch, 5=ring switch. These are audio
switches, not an isolated insertion detector. Full PDF access returned HTTP 403;
the actual source footprint and physical continuity are still NOT verified.
Do not put a 3.3 V pull-up on a contact that connects to headphone audio. An
isolated insertion contact or a properly designed detector is required for GPIO16.

Review: plug absent/present truth table with tip/ring/sleeve continuity, digital
thresholds, ESD, TRS/TRRS behavior, default speaker/amp mute and enclosure access.
Return an exact drawing and later unpowered continuity results; no result invented.

## 13. Speaker connector

Select keyed two-contact connector rated for actual BTL current, mating cable
and retention. Nets are SPK_P/SPK_N, not VCC/GND. At 2 W into 8 ohm, sinusoidal
load current is 0.5 Arms/0.707 A peak; switching/short-circuit stresses require
additional margin. Provide strain relief and keep pair routing together.

Review: connector numbering/mate orientation, insulation, assembly cable length,
speaker terminals never connected to chassis/ground and accessible service plug.

## 14. Battery connector and sensor

Protected 1S pack is still provisional. Verify mating connector, cable current,
actual polarity and protection specs from supplier; a JST-style name does not
guarantee common polarity. Two-wire pack needs a retained insulated external
temperature sensor, not a fabricated third wire or fixed-temperature bypass.

Review: battery removal without piercing/soldering cells, short protection,
NTC open/short faults, rated source/load current, reverse-connection mitigation.
Only a human connects a pack after current-limited non-battery checks.

## 15. Test and programming

Provide named GND, VBUS, BAT, SYS, 3V3, EN, GPIO0 and appropriate service pins.
UART0 GPIO43/44 can provide recovery independent of native USB. No raw 5 V UART
into MCU GPIO. Add current measurement access without interrupting protection.

Review: debugger/probe access after assembly, clear pad labels/polarity, no
inaccessible reset/boot, no grounded speaker test point. Capture actual ERC and
net cross-checks; a checklist is not an executed electrical test.

## Legacy bench GPIO contract — not the selected-product map

GPIO numbers below are not module pads or final product assignments. BD-16
relocates five buttons, SD detect, charge status and fuel alert to TCA9535PWR;
their ports/address/IRQ and combined BM83/TFT map require source review. Do not
draw the final schematic from this historical bench table.

| Interface | GPIO | Direction / default intent |
| --- | --- | --- |
| SD CLK/CMD/DAT0 / card detect | 12/11/13 / 14 | Clock/output, bidirectional data, detect input |
| I2S BCLK/WS/DOUT | 5/6/7 | Outputs to both digital audio branches |
| I2C SDA/SCL | 8/9 | Shared open-drain bus, 3.3 V pull-ups |
| Previous/play/next/down/up | 1/2/4/10/15 | Active-low input |
| Headphone detect | 16 | Active-low input expected; circuit pending |
| Speaker/headphone enable | 17/18 | Default off; final DAC mute relationship pending |
| Charge status / power hold | 21 / 38 | Input / output reserved, final policy pending |
| Fuel alert / display reset | 39 / 40 | Input / output reserved |
| Native USB D-/D+ | 19/20 | Reserved; service decision pending |
| UART0 TX/RX | 43/44 | Recovery service candidate |

Header authority: firmware/components/app_state/include/nightwave/hardware_config.h.
Changing an assignment requires coordinated schematic, wiring docs and firmware
tests. New charger/CC interrupt pins need a budget review, not an invented spare.
Calculate total I2C pull-up resistance including all modules: multiple parallel
resistors may exceed device sink limits. For a 100 pF assumed bus and 300 ns
rise-time budget, Rmax = tr/(0.8473*C) = 3.54 kohm; verify measured capacitance
and each device's VOL/IOL before choosing. This is an example, not a fitted value.
Calculation reference: [TI I2C pull-up application note](https://www.ti.com/lit/an/slva689/slva689.pdf).

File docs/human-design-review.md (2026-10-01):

# Builder design authorship and review

Status: NOT COMPLETE. A review checklist is not proof of original authorship.
See `pixl-funding-readiness.md` for the current program rule.

The builder reports Pixl clarified that AI tutoring/review is permitted with
real builder engineering decisions/authorship. Work now uses builder-tasks.md
and builder-decisions.md. Pending editable sources do not block independent
research/software; they do prevent claiming executed source-level design checks.

Provide original editable design sources and commit history as the work evolves.
For each subsystem record the builder's decisions, source/datasheet, authored
changes, reasoning, reviewer and unresolved issues. Do not invent dates or hours.

- [ ] Power tree, input limits and charge-while-play behavior
- [ ] Battery protection, polarity, NTC, charge current and thermal limits
- [ ] MCU boot/reset/programming, decoupling and antenna keepout
- [ ] SD pull-ups, voltage, pin map and detect
- [ ] DAC/headphone gain, jack switching and output safety
- [ ] Speaker supply, BTL output and shutdown
- [ ] Regulator layout, load/peak margins and grounding
- [ ] Exact footprint geometry and pin-1/orientation
- [ ] PCB return paths, placement/routing and manufacturer rules
- [ ] Enclosure port datums, fasteners, battery clearance and interference
- [ ] Firmware GPIOs agree with schematic and PCB
- [ ] Sources and AI disclosure accurately describe who created each artifact

Request clarification from Pixl before submission if the authorship boundary is
uncertain. Do not claim that rubber-stamping generated hardware satisfies it.

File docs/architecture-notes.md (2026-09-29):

# Firmware Architecture Notes

## Data flow

```text
FAT file
  |
  v
StorageTask -- compressed-byte ring --> DecoderTask -- PCM-frame ring --> AudioOutputTask
    |                                      |                                  |
 SD metrics                        format/error events                   I2S DMA + underruns
                                                                               |
                                                         +---------------------+------------------+
                                                         |                                        |
                                                  stereo DAC/HP amp                      mono Class-D
```

Control events travel through a bounded application event queue. Bulk audio never travels through the control queue. No UI, library scan, filesystem operation, logging sink, or allocation is allowed to block the audio output loop.

## Provisional tasks

Exact priority, stack size, core affinity, and period are **not locked** until profiling.

| Task | Responsibility | Input | Output | Queues/events | Timing sensitivity | Blocking restrictions |
|---|---|---|---|---|---|---|
| AudioOutputTask | keep I2S DMA supplied; apply final volume/ramp/mix policy; count underruns | PCM ring; playback state | DMA buffers; diagnostics | state/format events | Hardest application deadline | no filesystem, display, logging flush, or unbounded wait |
| DecoderTask | decode MP3 frames or parse/copy WAV PCM; emit format/error/EOF | compressed ring; track commands | PCM ring; format events | command queue + ring waits | High; must stay ahead of consumption | no UI; bounded waits only; avoid steady-state allocation |
| StorageTask | mount/enumerate/read SD; prefetch sequential bytes; recover card faults | open/read/cancel requests; card detect | compressed ring; storage status | request and event queues | Medium-high; latency is buffered | never runs in audio task; read chunks are bounded |
| InputTask | debounce five buttons and jack detect | GPIO/ISR notifications | input events | event queue | Low latency, tiny work | ISR only timestamps/notifies; no business logic |
| UITask | render boot/library/playback/error/diagnostic screens | immutable UI model/events | display bus updates | coalesced UI queue | Soft real-time | capped refresh rate; no storage scans |
| PowerTask | read gauge/charger state; enforce low-battery policy | I2C/status GPIO | power events/UI data | event queue | Low | bounded I2C timeout; never gates audio directly in ISR |
| DiagnosticsTask | snapshot counters/watermarks and print on debug channel | atomic counters/snapshots | logs/engineering screen | timer/event | Low | no expensive sampling in high-priority context |

## Buffering model

```text
SD read chunks -> compressed ring -> decoder frame -> PCM ring -> I2S DMA descriptors
```

Initial compile-time placeholders are 32 KiB compressed and 32 KiB PCM capacity, preferably in PSRAM for bulk storage while DMA buffers and queue structures remain internal. These are hypotheses, not final sizes.

Sizing procedure:

1. measure maximum PCM byte rate among V1 formats (48 kHz × 2 channels × 2 bytes = 192,000 B/s);
2. measure p95 and maximum SD read latency using several cards and file fragmentation states;
3. measure p95 and maximum MP3 frame decode time;
4. include DMA duration and task-scheduling jitter;
5. choose a reserve with documented margin and repeat under UI/SD/error stress;
6. compare internal-memory versus PSRAM ring access and ensure DMA-capable buffers stay internal;
7. expose current fill, minimum watermark, high watermark, overflow, and underrun counts.

## Audio format contract

Canonical PCM is signed 16-bit interleaved stereo. Mono decoder output is duplicated to L/R in the adaptation stage. Speaker mono uses `((int32_t)L + (int32_t)R) / 2` before saturation, never 16-bit addition. Format metadata includes sample rate, channels, and bits per sample. Unsupported combinations fail explicitly.

At a sample-rate change: ramp down/mute, stop and drain I2S, configure the clock, prefill, restart DMA, and ramp up. Arbitrary software resampling is not a V1 requirement.

## Events and ownership

- `AppStateStore` (future implementation) is the sole writer of application state.
- Producers send typed `AppEvent` values through a bounded queue.
- Playback commands are distinct from resulting state events.
- Track ownership is represented by a stable ID/path owned by the library component; UI holds a copied view model, not live filesystem objects.
- Stop/skip increments a stream generation so stale decoder/storage data is discarded deterministically.

## Diagnostics contract

The scaffold exposes fields for reset reason, SD bytes/throughput/worst latency, decoder frames/time/failures, compressed and PCM buffer levels/minimums, underruns, current sample rate, free/minimum heap, PSRAM use, per-task stack watermarks, battery percentage/voltage, and charger state. Unknown values remain explicitly unavailable; the UI must not invent them.

## Fault behavior

- SD absent/removal: cancel stream, mute, close/unmount where possible, remain responsive, show factual error, and allow remount.
- corrupt/unsupported file: stop only that stream, report typed error, permit skip/back.
- underrun: count it, output silence or controlled mute for the missing segment, and continue/recover according to severity.
- unexpected reset: report reset reason; never claim resume correctness until tested.

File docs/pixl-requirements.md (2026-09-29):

# Pixl Requirements Verification

Checked: 2026-09-29 (Asia/Calcutta)

This record separates published Pixl requirements from Nightwave's own stricter engineering goals. The live project page for Pixl project 1200 was checked while signed in, and the public official documentation was checked independently.

## Music Player Trial

| Requirement | Status | Source | Checked | Mandatory or recommended |
|---|---|---|---|---|
| Build a physical music player | Verified | Live Pixl project 1200, full Trial brief | 2026-09-29 | Mandatory |
| Load the builder's own audio files from SD card or flash | Verified | Live Pixl project 1200 | 2026-09-29 | Mandatory |
| Play through real speakers without phone, app, or streaming | Verified | Live Pixl project 1200 | 2026-09-29 | Mandatory |
| Provide physical play, pause, skip, and volume controls | Verified | Live Pixl project 1200 | 2026-09-29 | Mandatory |
| Battery lasts “a full night” and achieved runtime is stated | Verified | Live Pixl project 1200 | 2026-09-29 | Mandatory; no numeric duration is published |
| Repo includes wiring diagram or schematic, modifiable enclosure CAD (`.STEP` or `.blend`), parts list, build steps, and demo video | Verified | Live Pixl project 1200 | 2026-09-29 | Mandatory |
| ESP32/Pi Pico/Arduino plus DAC/amp is a suggested starting point | Verified | Live Pixl project 1200 | 2026-09-29 | Recommended |
| Technical requirements are intentionally not very fixed; ask `#pixl-help` before starting | Verified | Live Pixl project 1200 | 2026-09-29 | Recommended clarification path |

The live project is already associated with “A Music player for the saloon · Dustline.” The project page says the Trial picker flags it when shipping; that is the current Trial flagging mechanism.

## Hardware Requirements

Pixl requires an original, reproducible, plausibly working design. The hardware submission page requires a good README, a complete CAD assembly with all components, a concrete attachment method rather than tape/glue, applicable firmware, and another person’s sanity check. Source: [Pixl Hardware Ship Requirements](https://pixl.hackclub.com/docs/hardware-requirements).

## Required Repository Files

- public, live GitHub repository;
- README explaining what it is, how it is used, and why it exists;
- images of complete CAD and the PCB or a clear wiring diagram;
- BOM in CSV form with links and a total-cost line;
- PCB source when a PCB is used, including project/schematic/layout and manufacturing data;
- editable CAD source plus STEP export (the Trial text also names `.blend` as acceptable modifiable CAD);
- firmware source;
- build-progress images, finished-build images, and a demo video for the build submission;
- source updated to match any physical bodges.

Sources: [Hardware Ship Requirements](https://pixl.hackclub.com/docs/hardware-requirements), [Ship Requirements](https://pixl.hackclub.com/docs/rules).

## CAD / PCB Requirements

The official hardware page requires a complete assembly showing all components and their real retention, editable CAD plus STEP when 3D models are used, and full PCB source/manufacturing files when a PCB is used. A PCB is not explicitly required by the Trial, but it is a Nightwave project requirement and a central part of its technical case.

## AI / Authorship Requirements

The public ship rules permit AI tools when their use is disclosed honestly. The hardware rules are stricter about authorship: the design must be original and custom, not made entirely by AI, and fully AI-generated design files may be rejected. Nightwave therefore treats AI output as research/scaffolding/review material. The human builder must understand, materially review or author, assemble, measure, journal, photograph, and obtain the required second-person review. Sources: [Ship Requirements](https://pixl.hackclub.com/docs/rules), [Hardware Ship Requirements](https://pixl.hackclub.com/docs/hardware-requirements).

## Hackatime / Tracking

- Install Hackatime before substantive work and register the project using the correct Hackatime project name.
- Only hours after 2026-07-18 count under the current rules.
- Trial hour minimums, if any, are shown in the project dashboard.
- Journals are used to justify hours; entries claiming tracked hours require at least 100 characters per hour, with an absolute floor of 100 characters.
- Autonomous AI work must not be represented as human work time.

Sources: [Build Your First Project](https://pixl.hackclub.com/docs/first-project), [Ship Requirements](https://pixl.hackclub.com/docs/rules).

## Shipping / Demo Requirements

The live project page currently asks for a linked GitHub repo, demo link, thumbnail, uploaded BOM CSV, cart screenshots, and funding amount before shipping. It labels at least one tracked hour as optional for hardware. The Trial picker is already set to the music-player Trial. Public rules also require an accessible demo and AI disclosure. No submission was made in this phase.

## Tier Guidance

Reviewers assign T1–T4 after reviewing the build. Current guidance describes T4 Nexus as serious systems work with involved architecture and real depth; padding hours or features does not raise a tier. Nightwave targets that depth but cannot claim a tier. Source: [Restoration Energy and Levels](https://pixl.hackclub.com/docs/energy).
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

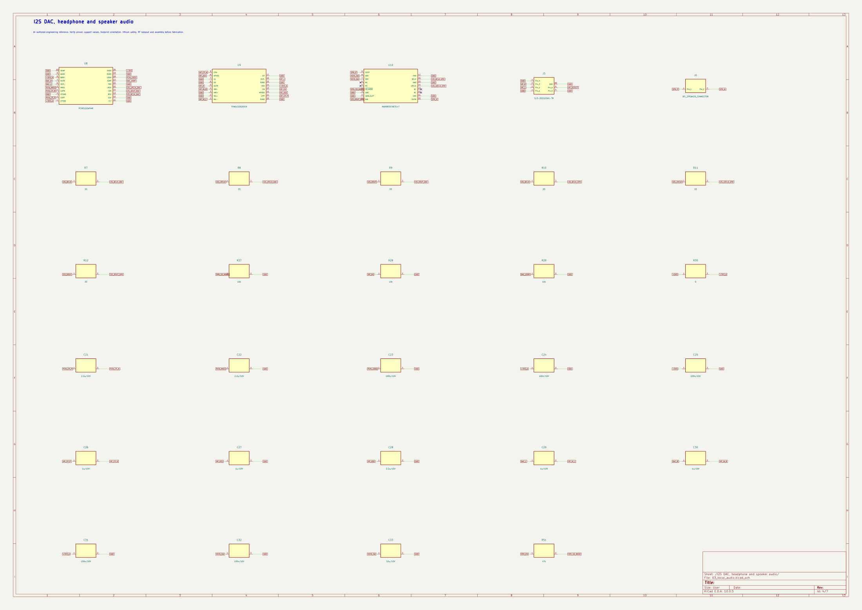
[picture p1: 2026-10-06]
hardware/kicad/nightwave-reference/reports/render/page-4.png

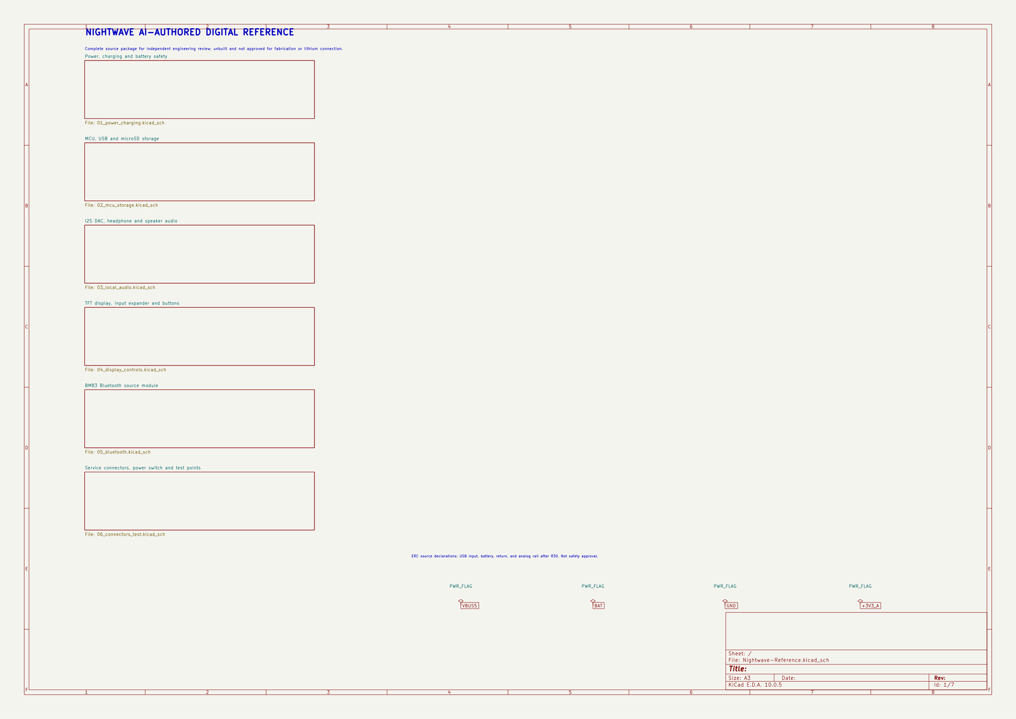
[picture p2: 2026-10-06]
hardware/kicad/nightwave-reference/reports/render/page-1.png

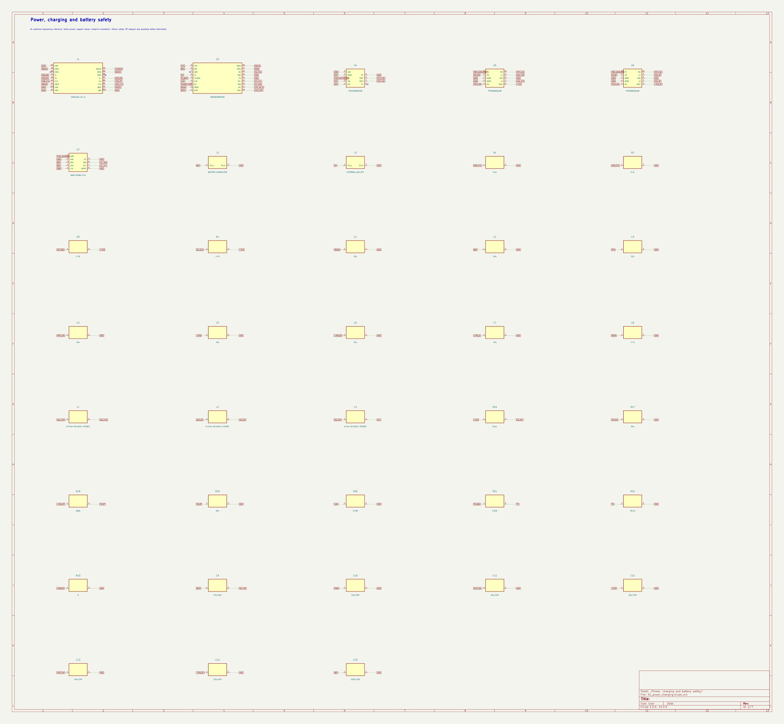
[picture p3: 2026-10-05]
hardware/kicad/nightwave-reference/reports/render/page-2.png

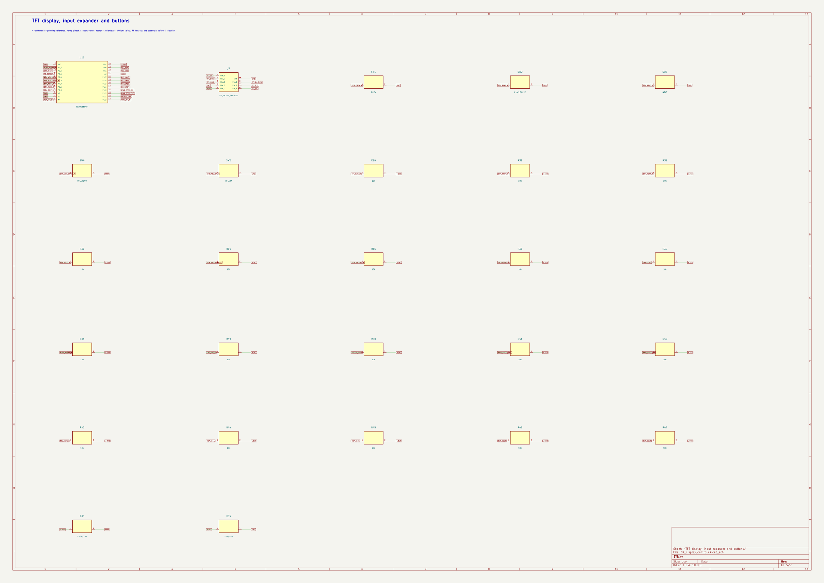
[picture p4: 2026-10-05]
hardware/kicad/nightwave-reference/reports/render/page-5.png

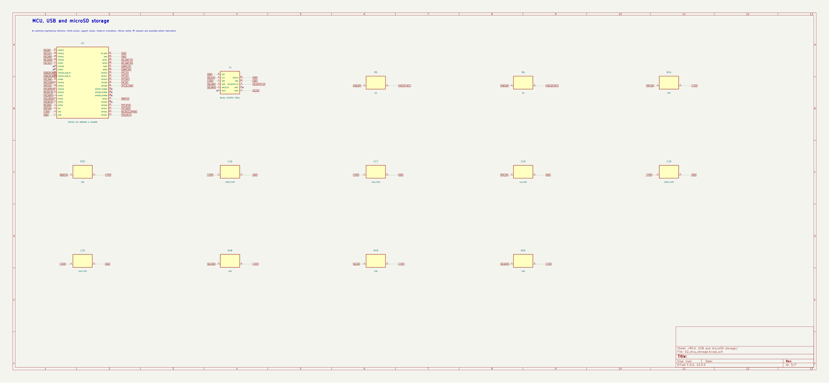
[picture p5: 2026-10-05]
hardware/kicad/nightwave-reference/reports/render/page-3.png

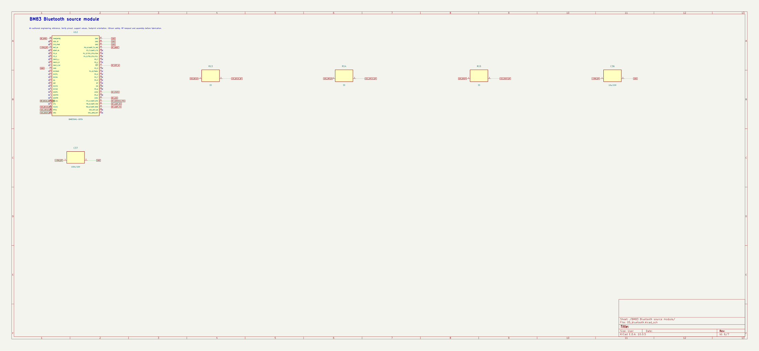
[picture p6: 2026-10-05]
hardware/kicad/nightwave-reference/reports/render/page-6.png

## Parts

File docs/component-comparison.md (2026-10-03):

# Component Comparison

2026-10-03 current choices supersede the historical pending labels below:
S3 + BM83SM1-00TA (BD-14), Waveshare 24382 non-touch (BD-15), TCA9535PWR
input expansion (BD-16). Current BOM is hardware/BOM.csv and selected-product
screening is current-power-model.md. Price snapshots are not procurement approval.

## 2026-10-01 expanded-scope candidates — NOT LOCKED

| Function | Candidate | Cost/availability snapshot | Qualification blocker | Status |
| --- | --- | --- | --- | --- |
| Dedicated A2DP source alongside S3 | BM83 AT family; AA listing needs AT firmware, TA release-note variant is AT-preprogrammed | AA $13.18, 2,429 listed; exact source SKU quote pending | Actual AT image/tools, UART/rates, one-headphone test, power/antenna budget | BD-14 PENDING |
| Main-MCU alternative | Original ESP32-WROVER-E-N8R8 | $5.88, 16,392 listed | S3-to-ESP32 pin/USB/PSRAM migration, SBC/IDF source integration | BD-14 PENDING |
| Larger display | Adafruit 3787, 1.54-inch ST7789 | $17.50, 7 listed | SPI/glyph driver, actual current and mount/window | BD-15 PENDING |
| Larger display | Waveshare non-touch 1.69-inch ST7789V2 | Indexed $9.31–$9.99, stock not verified | Exact drawing/connector/stock, offsets/current/driver | BD-15 PENDING |

Links and engineering comparisons are in [Bluetooth architecture](bluetooth-architecture.md)
and [display selection](display-selection.md). These are candidates, not added
locked BOM rows. Old SELECT/price labels below are historical and must not be
used for funding totals, procurement or proof of builder decisions.

Checked: 2026-09-29. Prices are indicative one-off USD snapshots where an official/distributor page exposed a price; `recheck` means a purchase-time quote is required. None of these parts has been purchased.

## MCU module and development board

2026-10-01 update: this table remains a historical price/comparison snapshot.
The power model now identifies Adafruit 353 / 6600 mAh as a provisional candidate
and a BQ25185 charge-timer conflict. See power-budget.md and power-assumptions.md;
neither charger nor final capacity is locked by the older table below.

| Candidate | MPN | Supply | Important Specs | Package | Power | Pros | Cons | Assembly Risk | Availability | Approx Cost | Source | Decision |
|---|---|---|---|---|---|---|---|---|---|---:|---|---|
| ESP32-S3 module, 16 MB/8 MB | ESP32-S3-WROOM-1-N16R8 | 3.0–3.6 V | dual-core LX7, 16 MB flash, 8 MB octal PSRAM, PCB antenna | 41-pad module | peaks require regulator margin | memory headroom; certified module; many GPIO | GPIO33–37 consumed by octal PSRAM; antenna keepout | Medium, castellated/LGA ground pad | Active; DigiKey showed 0 with incoming stock | 6.76 | [Espressif](https://www.espressif.com/en/products/modules/esp32/1000) | PROVISIONAL SELECT |
| ESP32-S3 module, 8 MB/8 MB | ESP32-S3-WROOM-1-N8R8 | 3.0–3.6 V | 8 MB flash, 8 MB octal PSRAM | module | similar | enough for V1; may have better stock | less flash margin | Medium | Active, recheck | recheck | [datasheet](https://www.espressif.com/sites/default/files/documentation/esp32-s3-wroom-1_wroom-1u_datasheet_en.pdf) | BACKUP |
| Prototype board | ESP32-S3-DevKitC-1-N8R8 | USB 5 V / 3.3 V | matching S3 + 8 MB PSRAM, USB/JTAG, headers | dev board | USB powered | official docs; exposed GPIO; no custom soldering | bulky; pin exposure differs from final | Low | Active, recheck exact variant | recheck | [guide](https://docs.espressif.com/projects/esp-dev-kits/en/latest/esp32s3/esp32-s3-devkitc-1/) | PROVISIONAL SELECT |

## microSD interface

| Candidate | MPN | Supply | Important Specs | Package | Power | Pros | Cons | Assembly Risk | Availability | Approx Cost | Source | Decision |
|---|---|---|---|---|---|---|---|---|---|---:|---|---|
| 1-bit SDMMC | ESP32-S3 peripheral | 3.3 V | CLK/CMD/D0; 20/40 MHz; CRC | internal | card dependent | native protocol, 3 bus pins, leaves D1–D3 free | dedicated bus and pull-ups | Low electrically; routing care | built in | 0 | [ESP-IDF](https://docs.espressif.com/projects/esp-idf/en/release-v5.4/esp32s3/api-reference/peripherals/sdmmc_host.html) | PROVISIONAL SELECT |
| 4-bit SDMMC | ESP32-S3 peripheral | 3.3 V | CLK/CMD/D0–D3 | internal | card dependent | maximum bandwidth headroom | six bus pins; extra pull-ups/routing with no proven need | Medium | built in | 0 | [ESP-IDF](https://docs.espressif.com/projects/esp-idf/en/release-v5.4/esp32s3/api-reference/peripherals/sdmmc_host.html) | REJECT for V1 |
| SDSPI | ESP32-S3 SPI host | 3.3 V | CS/SCLK/MOSI/MISO | internal | card dependent | broad module compatibility; shareable bus | arbitration, lower practical throughput, no native 4-bit path | Low | built in | 0 | [ESP-IDF](https://docs.espressif.com/projects/esp-idf/en/stable/esp32/api-reference/storage/sdmmc.html) | BACKUP |

## Stereo DAC

| Candidate | MPN | Supply | Important Specs | Package | Power | Pros | Cons | Assembly Risk | Availability | Approx Cost | Source | Decision |
|---|---|---|---|---|---|---|---|---|---|---:|---|---|
| TI stereo DAC | PCM5102APWR | 3.3 V analog/digital | 2.1 Vrms, 112 dB SNR, 8–384 kHz, 32-bit I2S, internal PLL/no MCLK | TSSOP-20 | recheck operating draw | proven, hardware controlled, easy package | line output still needs headphone amp; newer TI alternatives exist | Low–Medium | Active | recheck | [TI](https://www.ti.com/product/PCM5102A) | PROVISIONAL SELECT |
| TI integrated newer DAC | TAD5242 | check datasheet | 120 dB class, integrated line/headphone driver | QFN | recheck | potentially removes headphone amp | newer integration increases software/supply risk; not prototype-matched | High | Active | recheck | [TI comparison](https://www.ti.com/product/PCM5102A) | BACKUP |
| Cirrus stereo DAC | CS4344-CZZ | 3.3/5 V domains | 24-bit, up to 192 kHz, I2S | TSSOP-10 | recheck | compact and established | MCLK/clocking and output filtering must be checked | Low–Medium | recheck | recheck | [Cirrus](https://www.cirrus.com/products/cs4344-45-48/) | BACKUP |

## Headphone amplifier

| Candidate | MPN | Supply | Important Specs | Package | Power | Pros | Cons | Assembly Risk | Availability | Approx Cost | Source | Decision |
|---|---|---|---|---|---|---|---|---|---|---:|---|---|
| DirectPath stereo amp | TPA6132A2RTER | 2.3–5.5 V | 25 mW/ch into 16 Ω at 2.3 V, –6/0/+3/+6 dB, pop suppression | 16-WQFN 3×3 mm | 2.1 mA typ; <1 µA shutdown | capless 0 V outputs; differential inputs; high PSRR | QFN/exposed pad; output level/gain needs listening and safety validation | High | Active; 1,760 seen in stock | 1.10 | [TI](https://www.ti.com/product/TPA6132A2) | PROVISIONAL SELECT |
| TI output-cap amp | TPA6111A2DGN | 2.5–5.5 V | stereo headphone amplifier | HVSSOP | recheck | easier exposed-lead package | output capacitors and pop/size penalties | Medium | Active, recheck | recheck | [TI](https://www.ti.com/product/TPA6111A2) | BACKUP |
| ADI DirectDrive amp | MAX97220A | 2.5–5.5 V | stereo headphone amplifier, click/pop controls | TDFN | recheck | capless output alternative | leadless package and supply check | High | Production, recheck | recheck | [ADI](https://www.analog.com/en/products/max97220a.html) | BACKUP |

## Speaker amplifier

| Candidate | MPN | Supply | Important Specs | Package | Power | Pros | Cons | Assembly Risk | Availability | Approx Cost | Source | Decision |
|---|---|---|---|---|---|---|---|---|---|---:|---|---|
| Ramped digital Class-D | MAX98360CEFB+T | 2.5–5.5 V | 3.2 W into 4 Ω at 5 V; I2S; mono mix; no MCLK; 13 ms ramp | 10-pin FC2QFN 0.5 mm | 2.2 mA IQ; 92% at 1 W/8 Ω | current production; ramp; lower noise; compact | fine-pitch leadless assembly; no easy generic breakout | High | Production | 1.33 class list price | [ADI](https://www.analog.com/en/products/MAX98360A.html) | PROVISIONAL SELECT |
| Common digital Class-D | MAX98357AETE+T | 2.5–5.5 V | 3.2 W/4 Ω at 5 V; I2S; mono mix; no MCLK | 16-TQFN 3×3 mm | 2.4 mA IQ; 92% at 1 W/8 Ω | excellent breakout ecosystem and prototype evidence | DigiKey base listing constrained/discontinued; older device | High | Production at ADI; supplier risk | 4.08 | [ADI](https://www.analog.com/en/products/max98357a.html) | BACKUP / PROTOTYPE |
| 14 V digital Class-D | MAX98365AEWC+T | 3–14 V | up to 13.8 W/8 Ω at 14 V; I2S | WLCSP | 30 mW IQ | recommended for new designs | unnecessary rail/power/assembly complexity for pocket 1S system | Very high | Recommended for new designs | 1.01 list | [ADI](https://www.analog.com/en/products/max98365.html) | REJECT |

## Charger / power path

| Candidate | MPN | Supply | Important Specs | Package | Power | Pros | Cons | Assembly Risk | Availability | Approx Cost | Source | Decision |
|---|---|---|---|---|---|---|---|---|---|---:|---|---|
| Modern standalone power-path charger | BQ25185DLHR | 3–18 V input | 1-cell, up to 1 A charge, 4.5 V SYS, thermistor/thermal regulation, 3.125 A system discharge | 10-WSON 2.2×2 mm | 4 µA battery-only IQ | low IQ; robust input; charge/system control | tiny exposed-pad package; linear heat at high charge current | High | Active | recheck | [TI](https://www.ti.com/product/BQ25185) | PROVISIONAL SELECT |
| Established power-path charger | BQ24074RGTR | 4.35–10.2 V input | 1-cell, up to 1.5 A, fixed 4.2 V, 4.4 V system output | 16-VQFN 3×3 mm | 6.5 µA battery sleep max cited | proven, larger QFN, many examples | higher IQ/older; heat; fixed battery voltage | High | Active | recheck | [TI](https://www.ti.com/product/BQ24074) | BACKUP |
| Load-sharing charger | MCP73871-2CCI/ML | USB/adaptor input | 1-cell linear charger with system load sharing | QFN-20 | recheck | established; flexible source selection | larger BOM/package; older architecture | High | In production, recheck | recheck | [Microchip](https://ww1.microchip.com/downloads/en/DeviceDoc/MCP73871-Data-Sheet-DS20002090F.pdf) | BACKUP |

## 3.3 V regulator

| Candidate | MPN | Supply | Important Specs | Package | Power | Pros | Cons | Assembly Risk | Availability | Approx Cost | Source | Decision |
|---|---|---|---|---|---|---|---|---|---|---:|---|---|
| 2 A buck-boost | TPS63802DLAR | 1.3–5.5 V | 3.3 V adjustable, 2 A for VIN≥2.3 V, load disconnect, forced PWM | 10-VSON-HR 3×2 mm | 11 µA IQ | uses full 1S range; ESP peak margin; low IQ | demanding layout/0.47 µH inductor; switching-noise validation | High | Active | recheck | [TI](https://www.ti.com/product/TPS63802) | PROVISIONAL SELECT |
| Wide-input buck-boost | TPS63070RNMR | 2–16 V | up to 2 A, 2.4 MHz, PFM/PWM, load disconnect | 15-VQFN-HR | 50 µA IQ | robust output; easy headroom | higher IQ; over-wide input; more loss/complexity | High | Active | recheck | [TI](https://www.ti.com/product/TPS63070) | BACKUP |
| 750 mA buck | TPS62840DGRR | 1.8–6.5 V | 750 mA, 100% duty | VSON | 60 nA IQ | excellent idle efficiency, RF-friendly | loses 3.3 V regulation as battery falls; marginal peak margin | High | Active | recheck | [TI](https://www.ti.com/product/TPS62840) | REJECT for main rail |
| 600 mA LDO | AP2112K-3.3TRG1 | up to 6 V | 3.3 V, 600 mA | SOT-25 | low IQ class | cheap/easy/quiet | wastes energy; dropout loses low-SOC capacity; current margin weak | Low | Active | 0.28 snapshot | [Diodes](https://www.diodes.com/part/view/AP2112) | REJECT for main rail |

## Fuel gauge

| Candidate | MPN | Supply | Important Specs | Package | Power | Pros | Cons | Assembly Risk | Availability | Approx Cost | Source | Decision |
|---|---|---|---|---|---|---|---|---|---|---:|---|---|
| ModelGauge 1S | MAX17048G+T10 | cell 2.5–4.5 V | SOC/voltage/rate over I2C, no sense resistor | 8-TDFN 2×2 mm | 3 µA hibernate; 23 µA active | low BOM and power; alert output | cell model/temperature compensation still needs validation | High | Recommended for new designs | 1.64 at 1k list | [ADI](https://www.analog.com/en/products/max17048.html) | PROVISIONAL SELECT |
| Advanced ModelGauge | MAX17055 | 1S | ModelGauge m5, current sensing/coulomb features | TDFN/WLP | recheck | richer diagnostics and accuracy potential | sense resistor/BOM/config complexity | High | Recommended, recheck | recheck | [ADI](https://www.analog.com/en/products/max17055.html) | BACKUP |
| OCV gauge | LC709203F | 1S | I2C, no sense resistor | WDFN | low power | common module ecosystem | lifecycle/supply must be checked at lock | High | recheck | recheck | [onsemi](https://www.onsemi.com/products/power-management/battery-management/battery-fuel-gauges/lc709203f) | BACKUP |

## Display

| Candidate | MPN | Supply | Important Specs | Package | Power | Pros | Cons | Assembly Risk | Availability | Approx Cost | Source | Decision |
|---|---|---|---|---|---|---|---|---|---|---:|---|---|
| 1.3 in OLED module | SP12864-13 | module 3.3 V target | 128×64, SH1106, I2C/SPI/parallel | module | content dependent | readable, low pin count, mechanical module | vendor price/connector must be confirmed; OLED burn-in | Low | Vendor quote/check | recheck | [SantoP](https://santopdisplay.com/1-3-inch-oled-display/) | PROVISIONAL SELECT |
| 0.96 in SSD1306 module | exact vendor TBD | 3.3 V | 128×64, I2C | module | content dependent | ubiquitous and cheap | too small for filenames; clones vary | Low | broad but inconsistent | recheck | [SSD1306 datasheet](https://cdn-shop.adafruit.com/datasheets/SSD1306.pdf) | BACKUP |
| 1.54 in memory LCD | exact Sharp part TBD | 3.3 V | reflective, very low static power | FPC/module | low static | sunlight readable, low power | cost/library/mechanical complexity; no deep black UI | Medium | recheck | recheck | [Sharp displays](https://global.sharp/products/device/lineup/selection/lcd/memory/) | REJECT for first prototype |

## Connectors, speaker, battery, USB-C

| Candidate | MPN | Supply | Important Specs | Package | Power | Pros | Cons | Assembly Risk | Availability | Approx Cost | Source | Decision |
|---|---|---|---|---|---|---|---|---|---|---:|---|---|
| switched 3.5 mm jack | SJ-3503-SMT-TR | passive | TRS, two internal switches, right-angle mid-mount | SMT/mechanical | none | physical detect contacts; published CAD | board-edge/CAD coordination; switch truth table validation | Medium | Active; recheck stock | recheck | [Same Sky](https://www.sameskydevices.com/product/interconnect/connectors/audio-connectors/jacks/sj-3503-smt-tr) | PROVISIONAL SELECT |
| microSD socket | 104031-0811 | 3.3 V bus | push-pull, 1.42 mm, card detect, 10k cycles | SMT/mechanical | none | exact drawing; retention tabs | fine contacts and edge orientation | Medium | Published; check supplier | recheck | [Molex](https://www.molex.com/en-us/products/part-detail/1040310811) | PROVISIONAL SELECT |
| 28 mm speaker | CMS-28528N-L152 | amplifier load | 8 Ω, 2 W nominal, 28×5.2 mm, 99 dB at 1 W/0.1 m | wire leads | program dependent | slim; useful power margin | needs cavity/gasket/listening validation | Low electrical | Active; check supplier | recheck | [Same Sky](https://www.sameskydevices.com/product/audio/speakers/miniature-%2810-mm~40-mm%29/cms-28528n-l152) | PROVISIONAL SELECT |
| protected LiPo candidate | Adafruit 258 | 3.7 V nominal | 1200 mAh, 34×62×5 mm, JST-PH, protection | pouch | 4.5 Wh nominal | documented size and protection | likely insufficient for target; 500 mA max charge recommendation | Physical safety gate | In stock when checked | 9.95 | [Adafruit](https://www.adafruit.com/product/258) | BACKUP |
| protected LiPo candidate | Adafruit 328 | 3.7 V nominal | 2500 mAh, about 10 Wh, JST-PH, protection | pouch | measured later | larger energy baseline | capacity and enclosure cannot be locked before measurement | Physical safety gate | In stock when checked | 14.95 | [Adafruit](https://www.adafruit.com/category/574) | PROVISIONAL FORM-FACTOR CANDIDATE |
| USB-C receptacle | USB4105-GF-A | 5 V VBUS | USB2.0 16-signal, 5 A rated, shell stakes, 20k cycles | SMT + through-hole stakes | passive | robust mechanical retention; exact drawing/CAD | 16 pins more than power-only minimum | Medium | Active; supplier lead time shown | recheck | [GCT](https://gct.co/files/specs/usb4105-spec.pdf) | PROVISIONAL SELECT |

## Decision summary

The final module, storage width, audio/power ICs, display, jack, socket, speaker, and battery are all **provisional**. Prototype measurements, supply checks in the purchase region, footprint verification, and assembly-service capability must precede Phase 7 lock.

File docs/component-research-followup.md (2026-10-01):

# Component research follow-up

Checked 2026-10-01. Proposals only, not builder selections, final procurement
or source-file footprint passes. Existing BOM labels/prices are historical
candidate inputs. The $55.97 subtotal stays unchanged; the examples below are
not silently added to a funding total. Final quantity/cost depends on the real
builder schematic and chosen fab/assembly/mechanical process.

## Display alternative with documented interface and dimensions

[Adafruit product 938](https://www.adafruit.com/product/938) is a 1.3-inch
128x64 SSD1306 module, I2C default with optional reset, address selectable
0x3c/0x3d, compatible in principle with the firmware's SSD1306 option (not
physically tested). Listed $19.95 and out of stock at check time. This is a retail
product ID, not an invented bare-panel manufacturer MPN. Board dimensions are
35.6x33x6.2 mm, mounting pitch 30.5x28 mm, holes 2.5 mm; confirm received revision.
Maker quotes approximately 25–40 mA depending on usage. It requires reviewing
the current model's 5 mA OLED average assumption, duty cycle and transient budget.
Documented source beats an unverified pinout, but out-of-stock availability and
module bulk/cost are tradeoffs. Do not replace the builder's intended module
without their decision. Never use an old revision's mounting pattern blindly.

## Passive reference candidates, not a complete passive BOM

[TPS63802 reference table 10-6](https://www.ti.com/lit/ds/symlink/tps63802.pdf)
lists Coilcraft XFL4015-471ME (0.47 uH), Murata GRM188R60J106ME84 (10 uF) and
GRM188R60J226MEA0 (22 uF) as application-characterization components. These are
exact research candidates, not automatically approved substitutions. Obtain
current maker drawings/derating curves, lifecycle, stock and assembly quotes.
Nominal capacitance and example inductor current do not establish adequacy at
the chosen bias/temperature/transients. Choose resistor tolerance/package for
divider and current-limit error budget. Passives count comes from actual sheets.

## Connector and assembly issues

- [GCT USB4105](https://gct.co/connector/usb4105) includes distinct shell stake
  lengths. Capture the exact purchasable suffix/drawing and quoted quantity.
  Do not use a 060 model to prove fit for a different stake length.
- [Same Sky jack drawing](https://www.sameskydevices.com/product/resource/sj-3503-smt-tr.pdf)
  indexed pin table confirms tip/ring audio switches, not isolated digital detect.
  Full fetch is 403. Resolve detector topology or choose a documented isolated
  detect jack. No actual continuity/footprint check has passed.
- [Same Sky speaker datasheet](https://www.sameskydevices.com/product/resource/cms-28528n-l152.pdf)
  indexed text distinguishes base wire-lead part from A/B connector variants.
  Full fetch is 403; reserve cable strain relief and obtain the mechanical drawing.
- MAX98360CEFB+T is the 10-pin FC2QFN. CENL+T is the 9-ball WLP. The
  [manufacturer ordering/pin table](https://www.analog.com/media/en/technical-documentation/data-sheets/MAX98360A-MAX98360D.pdf)
  and corrected output locations control selection; review actual library files.

## Before a priced BOM can be final

For every builder-chosen component capture reference designators, exact MPN,
quantity, package, datasheet revision, validated footprint/model reference,
supplier URL, unit/extended price, currency/date/quantity, stock and substitutions.
Include NTC, source controller, master disconnect, all passives/ESD, connectors
and mates, switches, fasteners/retention, PCB/assembly, print/material, shipping
and tax. Mark unknown prices unavailable, never zero. Distinguish raw prototype
cost, final per-unit cost and minimum-order cash outlay. Requote before approval.
No purchase, funded budget, or human selection is asserted in this research.

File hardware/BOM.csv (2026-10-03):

Section | Manufacturer | Manufacturer_Part_Number | Description | Qty | Unit_Price_USD | Extended_Price_USD | Supplier | Supplier_URL | Availability_Snapshot | Decision_Status | Notes | Package | Datasheet_URL | Footprint_Information | Power_Role | Interface_Role
Candidate PCB | Espressif Systems | ESP32-S3-WROOM-1-N16R8 | S3 main MCU 16 MB flash 8 MB PSRAM | 1 | 6.76 | 6.76 | DigiKey | https://www.digikey.com/en/products/detail/espressif-systems/ESP32-S3-WROOM-1-N16R8/15295894 | 2026-09-29 historical backorder snapshot; recheck | RETAINED_BY_BD14 | Exact flash variant remains sourcing review; legacy bench map not final | Castellated module | https://www.espressif.com/sites/default/files/documentation/esp32-s3-wroom-1_wroom-1u_datasheet_en.pdf | Manufacturer land pattern and antenna keepout; builder verify pad map | Regulated 3.3 V main load | SDMMC I2S UART SPI I2C USB
Candidate PCB | Texas Instruments | PCM5102APWR | Stereo line DAC | 1 | 4.04 | 4.04 | DigiKey | https://www.digikey.com/en/products/detail/texas-instruments/PCM5102APWR/3788628 | 2026-09-29 historical stock 1140; recheck | CANDIDATE | Not a direct headphone driver | TSSOP-20 PW | https://www.ti.com/lit/ds/symlink/pcm5102a.pdf | TI PW package drawing; builder pad/orientation verification | 3.3 V analog and digital; mute/rail policy pending | I2S to stereo analog
Candidate PCB | Texas Instruments | TPA6132A2RTER | Stereo headphone amplifier | 1 | 1.10 | 1.10 | DigiKey | https://www.digikey.com/en/products/detail/texas-instruments/TPA6132A2RTER/2121537 | 2026-09-29 historical stock 1760; recheck | CANDIDATE | Gain and output ceiling need builder review | WQFN-16 RTE 3x3 mm | https://www.ti.com/lit/ds/symlink/tpa6132a2.pdf | TI RTE land pattern including exposed pad | Headphone path supply and enable | Analog stereo input and TRS output
Candidate PCB | Analog Devices | MAX98360CEFB+T | Mono I2S class-D amplifier | 1 | 1.33 | 1.33 | Analog Devices | https://www.analog.com/en/products/max98360a-max98360b-max98360c-max98360d.html | 2026-09-29 manufacturer price class; exact stock/price recheck | CANDIDATE | Do not substitute CENL WLP pin map; BTL outputs never grounded | 10-pin FC2QFN EFB | https://www.analog.com/media/en/technical-documentation/data-sheets/MAX98360A-MAX98360D.pdf | Manufacturer EFB drawing and numbered pin map; assembly review | System speaker rail with shutdown | I2S and differential speaker load
Candidate PCB | Microchip Technology | BM83SM1-00TA | AT-preprogrammed A2DP source radio module | 1 | 12.20 | 12.20 | DigiKey | https://www.digikey.com/en/products/detail/microchip-technology/BM83SM1-00TA/12807564 | 2026-10-02 stock 30; 17 week standard lead | BUILDER_SELECTED_BD14 | AT package/UART mapping and physical source validation pending; disable internal charger | 50-pad SMD module 32x15x2.5 mm | https://ww1.microchip.com/downloads/en/DeviceDoc/BM83-Bluetooth-Stereo-Audio-Module-Data-Sheet-DS70005402D.pdf | Manufacturer BM83 pad pattern plus antenna keepout; no final footprint authored | Qualified module rail shutdown and backfeed isolation pending | 44.1/48 kHz I2S UART MFB host wake P0_0 UART_TX_IND; P3_4 service configuration per exact firmware
Builder-selected module | Waveshare | 24382 | Non-touch 1.69 inch 240x280 ST7789V2 SPI display | 1 | 9.49 | 9.49 | Waveshare | https://www.waveshare.com/product/1.69inch-lcd-module.htm | 2026-10-03 official indexed USD9.49; direct403; stock and delivery unverified | BUILDER_SELECTED_BD15 | Selected in chat Oct3; six GPIO and reviewed cable/backlight/power integration pending | 31.5x39 mm carrier; thickness pending; MX1.25 8-pin cable | https://www.waveshare.com/wiki/1.69inch_LCD_Module | Module mounts per exact drawing; PCB connector MPN pinout and footprint pending; not bare ST7789 footprint | 3.3 V logic and backlight; vendor90 mA maximum; not measured | SPI MOSI SCLK CS DC reset PWM backlight; no touch
Candidate PCB | Texas Instruments | BQ25185DLHR | Single-cell power-path charger candidate | 1 | 2.28 | 2.28 | DigiKey | https://www.digikey.com/en/products/detail/texas-instruments/BQ25185DLHR/16834981 | 2026-09-29 historical stock 16473; recheck | REVIEW_REQUIRED | Not charger lock; safety timer/source/thermal conflict; BQ25628E alternative pending | WSON-10 DLH 2.2x2 mm | https://www.ti.com/lit/ds/symlink/bq25185.pdf | TI DLH land pattern plus thermal pad; trace exact revision | USB to protected cell and system power path | Status ILIM ISET VSET TS
Candidate PCB | Texas Instruments | TPS63802DLAR | 3.3 V buck-boost regulator candidate | 1 | 3.00 | 3.00 | DigiKey | https://www.digikey.com/en/products/detail/texas-instruments/TPS63802DLAR/10273184 | 2026-09-29 historical stock 16848; recheck | REVIEW_REQUIRED | Low-cell transients and effective capacitance need new product budget | VSON-HR-10 DLA plus exposed pad | https://www.ti.com/lit/ds/symlink/tps63802.pdf | TI DLA land pattern and high-current loop layout | 3.3 V conversion | Enable feedback power-good
Candidate PCB | Analog Devices | MAX17048G+T10 | Fuel gauge candidate | 1 | 4.61 | 4.61 | DigiKey | https://www.digikey.com/en/products/detail/analog-devices-inc-maxim-integrated/MAX17048G-T10/3758921 | 2026-09-29 historical stock 24490; recheck | CANDIDATE | VDD senses protected cell; not powered as 3.3 V peripheral | TDFN-8 | https://www.analog.com/media/en/technical-documentation/data-sheets/MAX17048-MAX17049.pdf | Manufacturer G package land pattern; builder review | Protected cell sensing | I2C and optional alert
Candidate PCB | Same Sky | SJ-3503-SMT-TR | Stereo 3.5 mm jack | 1 | 1.38 | 1.38 | DigiKey | https://www.digikey.com/en/products/detail/same-sky-formerly-cui-devices/SJ-3503-SMT-TR/2625162 | 2026-09-29 historical stock 18421; recheck | CANDIDATE | Audio switches do not establish isolated digital insertion detection | SMT mid-mount mechanical | https://www.sameskydevices.com/product/resource/sj-3503-smt-tr.pdf | Exact maker pad/hole/cutout drawing; continuity review | Passive headphone connector | Tip ring sleeve and audio switch contacts
Candidate PCB | Molex | 104031-0811 | microSD socket with card detect | 1 | 2.21 | 2.21 | DigiKey | https://www.digikey.com/en/products/detail/molex/104031-0811/5029382 | 2026-09-29 historical stock 17181; recheck | CANDIDATE | Pullups and insertion clearance required | SMT push-pull socket | https://www.molex.com/en-us/products/part-detail/1040310811 | Exact Molex sales drawing footprint/card travel/detect map | 3.3 V SD card rail | 1-bit SDMMC and detect
Candidate PCB | Same Sky | CMS-28528N-L152 | 28 mm 8 ohm 2 W speaker | 1 | 4.76 | 4.76 | DigiKey | https://www.digikey.com/en/products/detail/same-sky-formerly-cui-devices/CMS-28528N-L152/9561796 | 2026-09-29 historical stock 1374; recheck | CANDIDATE | Base suffix wire leads; acoustic cavity must be validated | 28x5.2 mm speaker wire leads | https://www.sameskydevices.com/product/resource/cms-28528n-l152.pdf | Mechanical envelope gasket and separately selected connector | Speaker amplifier load | Differential BTL leads
Candidate PCB | GCT | USB4105-GF-A | USB-C service/charge receptacle | 1 |  |  | Mouser | https://www.mouser.com/ProductDetail/GCT/USB4105-GF-A | Historical active listing; price/stock recheck | CANDIDATE | Native USB service reserved; source-current policy pending | 16-contact SMT plus shell stakes | https://gct.co/files/specs/usb4105-spec.pdf | Exact GF-A suffix drawing and plated/nonplated hole map | 5 V input and source policy | USB2 D+/D- and independent CC1 CC2 Rd
Pending PCB | Builder choice | PENDING_BATTERY_SELECTION | Protected rechargeable 1S battery sized after selected-product power review | 1 |  |  | Pending documented pack source |  | Pending ratings price stock NTC polarity envelope | PENDING_BUILDER_SELECTION | Current calculated screening is not pack approval; old 2500/6600 mAh candidates not authoritative | Pending protected pack and keyed connector | Pending chosen supplier electrical/current/charge datasheet | Pending cell envelope retention connector polarity | Energy store and protection | Charger fuel sensing NTC
Builder-selected PCB | Texas Instruments | TCA9535PWR | 16-bit I2C input expander for buttons and slow status | 1 |  |  | Texas Instruments | https://www.ti.com/product/TCA9535/part-details/TCA9535PWR | 2026-10-03 active maker listing; price and numeric stock unavailable | BUILDER_SELECTED_BD16 | Selected in chat; all-input driver tested digitally; address ports IRQ and physical bus pending; unused inputs need external pulls | TSSOP-24 PW; nominal7.8x6.4mm including leads | https://www.ti.com/lit/ds/symlink/tca9535.pdf | TI PW0024 drawing and numbered pin table; builder verify land pattern orientation | 3.3 V low-speed control load; external pull-up current budgeted in support allowance | I2C address0x20-0x27 and open-drain INT; five buttons SD detect charge status fuel alert; no power or audio outputs
Pending PCB | Builder choice | PENDING_SUPPORT_PARTS | Inductor effective capacitors feedback current-set NTC USB Rd ESD switches and keyed connectors | 1 |  |  | Pending exact approved suppliers |  | Selections incomplete | PENDING_BUILDER_SELECTION | Must split into exact rows before circuit/BOM release; not hidden in priced total | Pending each exact package | Pending each exact component datasheet | Pending each exact land pattern and pin map | Power conversion protection source policy sensing and shutdown | USB power analog GPIO I2C and external connectors
Fabrication | Builder choice | PENDING_PCB_FAB | Four-layer PCB fabrication/assembly | 1 |  |  | Pending fab |  | Quote and stackup pending | PENDING_BUILDER_SELECTION | Not a final board design or authorized order | Pending stackup | Pending fab capability document | Builder-owned PCB and fab stackup | PCB interconnect | Manufacturing
Mechanical | Builder choice | PENDING_ENCLOSURE | Serviceable enclosure lens mounts and hardware | 1 |  |  | Pending material supplier |  | Design not started | PENDING_BUILDER_SELECTION | Builder authors final CAD; chosen display/pack drawings required | Pending material and fixtures | Pending material and fixture data | Builder-owned editable enclosure | Thermal and mechanical role | Controls ports acoustic/RF clearance
Pending PCB | Builder choice | PENDING_BT_POWER_RAIL | BM83 isolated regulated supply and enable with backfeed control | 1 |  |  | Pending reviewed source |  | Selected BM83 needs qualified3.2-4.2V rail | PENDING_BUILDER_SELECTION | Do not connect to BQ25185 SYS4.5V or parallel chargers; exact regulator switches support parts pending | Pending power IC and switch package | https://www.microchip.com/en-us/product/bm83 | Pending exact regulator and load-switch footprint and BM83 pin/rail review | Separate qualified BM83 rail | Supply enable discharge and powered-off I2S/UART isolation
Summary | NA | PRICED_CORE_SUBTOTAL | Subtotal of captured candidate and selected-module prices | 1 |  | 53.16 | NA | NA | 2026-10-03 mixed dated research snapshots | PRELIMINARY | Not an order total; excludes battery support parts BT rail PCB assembly enclosure delivery and tax | NA | NA | NA | NA | NA

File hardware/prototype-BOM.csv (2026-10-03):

ID | Stage | Category | Manufacturer | Manufacturer_Part_Number | Description | Qty | Unit_Price_USD | Extended_Price_USD | Supplier | Supplier_URL | Availability_Checked_2026-09-30 | Required | Alternative | Notes
P01 | All | Controller | Espressif Systems | ESP32-S3-DevKitC-1-N8R8 | Official ESP32-S3 development board with 8 MB flash and 8 MB PSRAM | 1 | 15.00 | 15.00 | Mouser | https://www.mouser.com/en/ProductDetail/Espressif-Systems/ESP32-S3-DevKitC-1-N8R8 | In stock 1127 | YES | DigiKey 1965-ESP32-S3-DEVKITC-1-N8R8-ND is backordered | Record board revision because v1.1 uses GPIO38 for RGB LED
P02 | SD | Storage | SparkFun Electronics | BOB-00544 | Raw microSD Transflash breakout with all SD data pins exposed | 1 | 5.95 | 5.95 | SparkFun | https://www.sparkfun.com/sparkfun-microsd-transflash-breakout.html | In stock | YES | DigiKey 1568-00544-ND | 3.3 V only; no level shifter and no mechanical card-detect switch
P03 | Headphone | DAC | Adafruit Industries | 6250 | PCM5102 I2S stereo line-level DAC breakout | 1 | 4.95 | 4.95 | DigiKey | https://www.digikey.com/en/products/detail/adafruit-industries-llc/6250/26249971 | In stock 457 | YES | Adafruit direct was out of stock | Line output is rated for loads of at least 1 kohm and must not drive headphones directly
P04 | Headphone | Headphone amplifier | Texas Instruments | TPA6132A2EVM2 | TPA6132A2 stereo DirectPath headphone amplifier evaluation module | 1 |  |  | Texas Instruments | https://www.ti.com/tool/TPA6132A2EVM2 | TI page reports unavailable for direct order | YES | Build the reviewed MIT breakout at https://github.com/AdamKeher/TPA6132A2RTER-Breakout only after human review | Do not substitute an unlabeled marketplace board; obtain quote before purchase
P04A | Headphone | Alternative headphone prototype | Adafruit Industries | 6309 | TLV320DAC3100 I2S DAC with stereo headphone output | 1 | 6.95 | 6.95 | Adafruit | https://www.adafruit.com/product/6309 | In stock at check time | PROVISIONAL ALTERNATIVE | TPA6132A2EVM2 if a documented unit becomes available | Bench-only alternate path; requires I2C configuration and does not validate final PCM5102A plus TPA6132A2 architecture
P05 | Speaker | Speaker amplifier | Adafruit Industries | 3006 | MAX98357A mono I2S Class-D amplifier breakout | 1 | 5.95 | 5.95 | Adafruit | https://www.adafruit.com/product/3006 | In stock | YES | Exact MAX98357A breakout from an authorized distributor | Prototype proxy for the final MAX98360C path; BTL output is never grounded
P06 | UI | Display | Adafruit Industries | 938 | 1.3 inch 128x64 SSD1306 OLED I2C breakout | 1 | 19.95 | 19.95 | Adafruit | https://www.adafruit.com/product/938 | In stock | YES | Bench-only OLED; final Waveshare24382 selected BD-15 and unqualified | Historical USB-powered UI proxy; not the final screen or enclosure envelope
P07 | Input | Buttons | Adafruit Industries | 367 | 6 mm normally-open tactile button pack of 20 | 1 | 2.50 | 2.50 | Adafruit | https://www.adafruit.com/product/367 | In stock | YES | Any documented normally-open breadboard switch | Use five buttons; remaining switches are spares
P08 | Speaker | Transducer | Adafruit Industries | 6486 | 36 mm 8 ohm 2 W speaker with wires | 1 | 1.95 | 1.95 | Adafruit | https://www.adafruit.com/product/6486 | In stock | YES | Any documented 8 ohm speaker rated at least 2 W | Keep initial amplifier gain and digital volume low
P09 | Interconnect | Breadboard | Adafruit Industries | 239 | Full-size 830-tie-point solderless breadboard | 1 | 5.95 | 5.95 | Adafruit | https://www.adafruit.com/product/239 | In stock | YES | Equivalent reputable full-size breadboard | DevKitC may require a second breadboard or side rail because of board width
P10 | Interconnect | Jumpers | Adafruit Industries | 1957 | Premium male-to-male jumper wires 20 x 150 mm | 1 | 1.95 | 1.95 | Adafruit | https://www.adafruit.com/product/1957 | In stock | YES | Short 22 AWG solid-core jumpers | Keep I2S and SD wiring short
P11 | Interconnect | USB cable | Adafruit Industries | 898 | USB-A to Micro-B data cable 165 mm | 1 | 2.95 | 2.95 | Adafruit | https://www.adafruit.com/product/898 | In stock | YES | Cable matching the verified DevKitC revision | Official guide identifies the USB-to-UART connector as Micro-USB
P12 | SD | Pull-up resistor | Stackpole Electronics | CF14JT10K0 | 10 kohm 5 percent 0.25 W axial resistor | 5 | 0.10 | 0.50 | DigiKey | https://www.digikey.com/en/products/detail/stackpole-electronics-inc/CF14JT10K0/1741265 | In stock 389046 | YES | Any 10 kohm through-hole resistor | One each from CMD and DAT0-DAT3 to 3.3 V
P13 | Storage | Test media | BUILDER-SUPPLIED | RECORDED-AT-GATE | 8 to 32 GB microSDHC card formatted FAT32 | 1 |  |  |  |  | Exact make and model must be recorded | YES | None | Do not assume counterfeit-card performance
P14 | Headphone | Load | BUILDER-SUPPLIED | RECORDED-AT-GATE | Wired stereo headphones 32 ohm or higher for first test | 1 |  |  |  |  | Exact model and impedance must be recorded | YES | None | Begin at mute and zero digital volume
P15 | Power | Test equipment | BUILDER-SUPPLIED | RECORDED-AT-GATE | Current-limited 5 V bench supply or powered USB source rated 2 A plus DMM | 1 |  |  |  |  | Availability must be confirmed | YES | None | No lithium battery is used in the first audio proof
SUMMARY | NA | NA | NA | KNOWN_PRICED_SUBTOTAL | Subtotal of rows with captured prices; includes optional P04A but excludes P04 P13 P14 P15 tax and shipping | 1 |  | 74.55 | NA | NA | NA | NA | NA | This is not a purchase authorization or final project cost

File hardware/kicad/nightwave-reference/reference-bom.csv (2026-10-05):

Reference | Qty | Manufacturer | MPN | Value | Footprint | Datasheet | Unit_Price_USD | Supplier_URL | Status
J1 | 1 | GCT | USB4105-GF-A | USB4105-GF-A | Connector_USB:USB_C_Receptacle_GCT_USB4105-xx-A_16P_TopMnt_Horizontal | https://gct.co/files/specs/usb4105-spec.pdf |  |  | REFERENCE_REVIEW_REQUIRED
U3 | 1 | Texas Instruments | BQ25628ERYKR | BQ25628ERYKR | Nightwave:TI_RYK0018A | https://www.ti.com/lit/ds/symlink/bq25628e.pdf |  |  | REFERENCE_REVIEW_REQUIRED
U4 | 1 | Texas Instruments | TPS22965DSGR | TPS22965DSGR | Package_SON:Texas_DSG0008A_WSON-8-1EP_2x2mm_P0.5mm_EP0.9x1.6mm_ThermalVias | https://www.ti.com/lit/ds/symlink/tps22965.pdf |  |  | REFERENCE_REVIEW_REQUIRED
U5 | 1 | Texas Instruments | TPS63802DLAR | TPS63802DLAR | Nightwave:TI_DLA0010A | https://www.ti.com/lit/ds/symlink/tps63802.pdf |  |  | REFERENCE_REVIEW_REQUIRED
U6 | 1 | Texas Instruments | TPS63802DLAR | TPS63802DLAR | Nightwave:TI_DLA0010A | https://www.ti.com/lit/ds/symlink/tps63802.pdf |  |  | REFERENCE_REVIEW_REQUIRED
U7 | 1 | Analog Devices | MAX17048G+T10 | MAX17048G+T10 | Package_DFN_QFN:TDFN-8-1EP_2x2mm_P0.5mm_EP0.8x1.2mm | https://www.analog.com/media/en/technical-documentation/data-sheets/MAX17048-MAX17049.pdf |  |  | REFERENCE_REVIEW_REQUIRED
J2 | 1 | JST | S2B-PH-K-S | BATTERY_CONNECTOR | Connector_JST:JST_PH_S2B-PH-K_1x02_P2.00mm_Horizontal | https://www.jst-mfg.com/product/pdf/eng/ePH.pdf |  |  | REFERENCE_REVIEW_REQUIRED
J3 | 1 | JST | S2B-PH-K-S | EXTERNAL_10K_NTC | Connector_JST:JST_PH_S2B-PH-K_1x02_P2.00mm_Horizontal | https://www.jst-mfg.com/product/pdf/eng/ePH.pdf |  |  | REFERENCE_REVIEW_REQUIRED
U1 | 1 | Espressif Systems | ESP32-S3-WROOM-1-N16R8 | ESP32-S3-WROOM-1-N16R8 | RF_Module:ESP32-S3-WROOM-1 | https://www.espressif.com/sites/default/files/documentation/esp32-s3-wroom-1_wroom-1u_datasheet_en.pdf | 6.76 |  | REFERENCE_REVIEW_REQUIRED
J4 | 1 | Molex | 104031-0811 | Molex 104031-0811 | Connector_Card:microSD_HC_Molex_104031-0811 | https://www.molex.com/en-us/products/part-detail/1040310811 | 2.21 |  | REFERENCE_REVIEW_REQUIRED
U8 | 1 | Texas Instruments | PCM5102APWR | PCM5102APWR | Package_SO:Texas_PW0020A_TSSOP-20_4.4x6.5mm_P0.65mm | https://www.ti.com/lit/ds/symlink/pcm5102a.pdf | 4.04 |  | REFERENCE_REVIEW_REQUIRED
U9 | 1 | Texas Instruments | TPA6132A2RTER | TPA6132A2RTER | Package_DFN_QFN:VQFN-16-1EP_3x3mm_P0.5mm_EP1.6x1.6mm_ThermalVias | https://www.ti.com/lit/ds/symlink/tpa6132a2.pdf | 1.10 |  | REFERENCE_REVIEW_REQUIRED
U10 | 1 | Analog Devices | MAX98357AETE+T | MAX98357AETE+T | Package_DFN_QFN:TQFN-16-1EP_3x3mm_P0.5mm_EP1.23x1.23mm | https://www.analog.com/media/en/technical-documentation/data-sheets/MAX98357A-MAX98357B.pdf |  |  | REFERENCE_REVIEW_REQUIRED
J5 | 1 | Same Sky | SJ3-350153AG-TR | SJ3-350153AG-TR | Nightwave:SameSky_SJ3-350153AG | https://www.sameskydevices.com/product/resource/sj3-35015x.pdf |  |  | REFERENCE_REVIEW_REQUIRED
J6 | 1 | JST | S2B-PH-K-S | BTL_SPEAKER_CONNECTOR | Connector_JST:JST_PH_S2B-PH-K_1x02_P2.00mm_Horizontal | https://www.jst-mfg.com/product/pdf/eng/ePH.pdf |  |  | REFERENCE_REVIEW_REQUIRED
U11 | 1 | Texas Instruments | TCA9535PWR | TCA9535PWR | Package_SO:TSSOP-24_4.4x7.8mm_P0.65mm | https://www.ti.com/lit/ds/symlink/tca9535.pdf |  |  | REFERENCE_REVIEW_REQUIRED
J7 | 1 | JST | SM08B-GHS-TB(LF)(SN) | TFT_24382_HARNESS | Connector_JST:JST_GH_SM08B-GHS-TB_1x08-1MP_P1.25mm_Horizontal | https://www.jst-mfg.com/product/pdf/eng/eGH.pdf |  |  | REFERENCE_REVIEW_REQUIRED
SW1 | 1 |  | PENDING_SELECTION | PREV | Button_Switch_SMD:SW_SPST_TL3342 |  |  |  | MPN_PENDING_SELECTION
SW2 | 1 |  | PENDING_SELECTION | PLAY_PAUSE | Button_Switch_SMD:SW_SPST_TL3342 |  |  |  | MPN_PENDING_SELECTION
SW3 | 1 |  | PENDING_SELECTION | NEXT | Button_Switch_SMD:SW_SPST_TL3342 |  |  |  | MPN_PENDING_SELECTION
SW4 | 1 |  | PENDING_SELECTION | VOL_DOWN | Button_Switch_SMD:SW_SPST_TL3342 |  |  |  | MPN_PENDING_SELECTION
SW5 | 1 |  | PENDING_SELECTION | VOL_UP | Button_Switch_SMD:SW_SPST_TL3342 |  |  |  | MPN_PENDING_SELECTION
U12 | 1 | Microchip Technology | BM83SM1-00TA | BM83SM1-00TA | Nightwave:Microchip_BM83_GroundLands | https://ww1.microchip.com/downloads/en/DeviceDoc/BM83-Bluetooth-Stereo-Audio-Module-Data-Sheet-DS70005402D.pdf | 12.20 |  | REFERENCE_REVIEW_REQUIRED
SW6 | 1 |  | PENDING_SELECTION | MAIN_POWER | Button_Switch_SMD:SW_SPDT_PCM12 |  |  |  | MPN_PENDING_SELECTION
J8 | 1 |  | PENDING_SELECTION | UART0_SERVICE | Connector_PinHeader_2.54mm:PinHeader_1x06_P2.54mm_Vertical |  |  |  | MPN_PENDING_SELECTION
TP1 | 1 |  | NO_PURCHASE | VBUS5 | TestPoint:TestPoint_Pad_D1.0mm |  |  |  | PCB_FEATURE
TP2 | 1 |  | NO_PURCHASE | BAT | TestPoint:TestPoint_Pad_D1.0mm |  |  |  | PCB_FEATURE
TP3 | 1 |  | NO_PURCHASE | SYS | TestPoint:TestPoint_Pad_D1.0mm |  |  |  | PCB_FEATURE
TP4 | 1 |  | NO_PURCHASE | VSYS_SW | TestPoint:TestPoint_Pad_D1.0mm |  |  |  | PCB_FEATURE
TP5 | 1 |  | NO_PURCHASE | +3V3 | TestPoint:TestPoint_Pad_D1.0mm |  |  |  | PCB_FEATURE
TP6 | 1 |  | NO_PURCHASE | +3V6_BT | TestPoint:TestPoint_Pad_D1.0mm |  |  |  | PCB_FEATURE
TP7 | 1 |  | NO_PURCHASE | I2C_SDA | TestPoint:TestPoint_Pad_D1.0mm |  |  |  | PCB_FEATURE
TP8 | 1 |  | NO_PURCHASE | I2C_SCL | TestPoint:TestPoint_Pad_D1.0mm |  |  |  | PCB_FEATURE
TP9 | 1 |  | NO_PURCHASE | I2S_BCLK | TestPoint:TestPoint_Pad_D1.0mm |  |  |  | PCB_FEATURE
TP10 | 1 |  | NO_PURCHASE | I2S_LRCLK | TestPoint:TestPoint_Pad_D1.0mm |  |  |  | PCB_FEATURE
TP11 | 1 |  | NO_PURCHASE | I2S_DOUT | TestPoint:TestPoint_Pad_D1.0mm |  |  |  | PCB_FEATURE
TP12 | 1 |  | NO_PURCHASE | GND | TestPoint:TestPoint_Pad_D1.0mm |  |  |  | PCB_FEATURE
TP13 | 1 |  | NO_PURCHASE | BT_SERVICE_P34 | TestPoint:TestPoint_Pad_D1.0mm |  |  |  | PCB_FEATURE
TP14 | 1 |  | NO_PURCHASE | BT_LED | TestPoint:TestPoint_Pad_D1.0mm |  |  |  | PCB_FEATURE
TP15 | 1 |  | NO_PURCHASE | BT_STATE | TestPoint:TestPoint_Pad_D1.0mm |  |  |  | PCB_FEATURE
TP16 | 1 |  | NO_PURCHASE | HP_DETECT | TestPoint:TestPoint_Pad_D1.0mm |  |  |  | PCB_FEATURE
R1 | 1 |  | PENDING_SELECTION | 5.1k | Resistor_SMD:R_0603_1608Metric |  |  |  | MPN_PENDING_SELECTION
R2 | 1 |  | PENDING_SELECTION | 5.1k | Resistor_SMD:R_0603_1608Metric |  |  |  | MPN_PENDING_SELECTION
R3 | 1 |  | PENDING_SELECTION | 4.7k | Resistor_SMD:R_0603_1608Metric |  |  |  | MPN_PENDING_SELECTION
R4 | 1 |  | PENDING_SELECTION | 4.7k | Resistor_SMD:R_0603_1608Metric |  |  |  | MPN_PENDING_SELECTION
R5 | 1 |  | PENDING_SELECTION | 22 | Resistor_SMD:R_0603_1608Metric |  |  |  | MPN_PENDING_SELECTION
R6 | 1 |  | PENDING_SELECTION | 22 | Resistor_SMD:R_0603_1608Metric |  |  |  | MPN_PENDING_SELECTION
R7 | 1 |  | PENDING_SELECTION | 33 | Resistor_SMD:R_0603_1608Metric |  |  |  | MPN_PENDING_SELECTION
R8 | 1 |  | PENDING_SELECTION | 33 | Resistor_SMD:R_0603_1608Metric |  |  |  | MPN_PENDING_SELECTION
R9 | 1 |  | PENDING_SELECTION | 33 | Resistor_SMD:R_0603_1608Metric |  |  |  | MPN_PENDING_SELECTION
R10 | 1 |  | PENDING_SELECTION | 33 | Resistor_SMD:R_0603_1608Metric |  |  |  | MPN_PENDING_SELECTION
R11 | 1 |  | PENDING_SELECTION | 33 | Resistor_SMD:R_0603_1608Metric |  |  |  | MPN_PENDING_SELECTION
R12 | 1 |  | PENDING_SELECTION | 33 | Resistor_SMD:R_0603_1608Metric |  |  |  | MPN_PENDING_SELECTION
R13 | 1 |  | PENDING_SELECTION | 33 | Resistor_SMD:R_0603_1608Metric |  |  |  | MPN_PENDING_SELECTION
R14 | 1 |  | PENDING_SELECTION | 33 | Resistor_SMD:R_0603_1608Metric |  |  |  | MPN_PENDING_SELECTION
R15 | 1 |  | PENDING_SELECTION | 33 | Resistor_SMD:R_0603_1608Metric |  |  |  | MPN_PENDING_SELECTION
C1 | 1 |  | PENDING_SELECTION | 10u | Capacitor_SMD:C_0603_1608Metric |  |  |  | MPN_PENDING_SELECTION
C2 | 1 |  | PENDING_SELECTION | 10u | Capacitor_SMD:C_0603_1608Metric |  |  |  | MPN_PENDING_SELECTION
C3 | 1 |  | PENDING_SELECTION | 22u | Capacitor_SMD:C_0603_1608Metric |  |  |  | MPN_PENDING_SELECTION
C4 | 1 |  | PENDING_SELECTION | 22u | Capacitor_SMD:C_0603_1608Metric |  |  |  | MPN_PENDING_SELECTION
C5 | 1 |  | PENDING_SELECTION | 22u | Capacitor_SMD:C_0603_1608Metric |  |  |  | MPN_PENDING_SELECTION
C6 | 1 |  | PENDING_SELECTION | 22u | Capacitor_SMD:C_0603_1608Metric |  |  |  | MPN_PENDING_SELECTION
C7 | 1 |  | PENDING_SELECTION | 10u | Capacitor_SMD:C_0603_1608Metric |  |  |  | MPN_PENDING_SELECTION
C8 | 1 |  | PENDING_SELECTION | 4.7u | Capacitor_SMD:C_0603_1608Metric |  |  |  | MPN_PENDING_SELECTION
L1 | 1 | Coilcraft | XFL4015-471MEC | 0.47uH XFL4015-471MEC | Nightwave:Coilcraft_XFL4015 | https://www.coilcraft.com/getmedia/84927b8b-f089-421b-a7f4-a0fa23afe908/xfl4015.pdf |  |  | REFERENCE_REVIEW_REQUIRED
L2 | 1 | Coilcraft | XFL4015-471MEC | 0.47uH XFL4015-471MEC | Nightwave:Coilcraft_XFL4015 | https://www.coilcraft.com/getmedia/84927b8b-f089-421b-a7f4-a0fa23afe908/xfl4015.pdf |  |  | REFERENCE_REVIEW_REQUIRED
L3 | 1 | Coilcraft | XFL4015-701MEC | 0.7uH XFL4015-701MEC | Nightwave:Coilcraft_XFL4015 | https://www.coilcraft.com/getmedia/84927b8b-f089-421b-a7f4-a0fa23afe908/xfl4015.pdf |  |  | REFERENCE_REVIEW_REQUIRED
R16 | 1 |  | PENDING_SELECTION | 511k | Resistor_SMD:R_0603_1608Metric |  |  |  | MPN_PENDING_SELECTION
R17 | 1 |  | PENDING_SELECTION | 91k | Resistor_SMD:R_0603_1608Metric |  |  |  | MPN_PENDING_SELECTION
R18 | 1 |  | PENDING_SELECTION | 562k | Resistor_SMD:R_0603_1608Metric |  |  |  | MPN_PENDING_SELECTION
R19 | 1 |  | PENDING_SELECTION | 91k | Resistor_SMD:R_0603_1608Metric |  |  |  | MPN_PENDING_SELECTION
R20 | 1 |  | PENDING_SELECTION | 5.49k | Resistor_SMD:R_0603_1608Metric |  |  |  | MPN_PENDING_SELECTION
R21 | 1 |  | PENDING_SELECTION | 5.23k | Resistor_SMD:R_0603_1608Metric |  |  |  | MPN_PENDING_SELECTION
R22 | 1 |  | PENDING_SELECTION | 30.1k | Resistor_SMD:R_0603_1608Metric |  |  |  | MPN_PENDING_SELECTION
R23 | 1 |  | PENDING_SELECTION | 0 | Resistor_SMD:R_0603_1608Metric |  |  |  | MPN_PENDING_SELECTION
R24 | 1 |  | PENDING_SELECTION | 10k | Resistor_SMD:R_0603_1608Metric |  |  |  | MPN_PENDING_SELECTION
R25 | 1 |  | PENDING_SELECTION | 10k | Resistor_SMD:R_0603_1608Metric |  |  |  | MPN_PENDING_SELECTION
R26 | 1 |  | PENDING_SELECTION | 10k | Resistor_SMD:R_0603_1608Metric |  |  |  | MPN_PENDING_SELECTION
R27 | 1 |  | PENDING_SELECTION | 10k | Resistor_SMD:R_0603_1608Metric |  |  |  | MPN_PENDING_SELECTION
R28 | 1 |  | PENDING_SELECTION | 10k | Resistor_SMD:R_0603_1608Metric |  |  |  | MPN_PENDING_SELECTION
R29 | 1 |  | PENDING_SELECTION | 10k | Resistor_SMD:R_0603_1608Metric |  |  |  | MPN_PENDING_SELECTION
R30 | 1 |  | PENDING_SELECTION | 0 | Resistor_SMD:R_0603_1608Metric |  |  |  | MPN_PENDING_SELECTION
R31 | 1 |  | PENDING_SELECTION | 10k | Resistor_SMD:R_0603_1608Metric |  |  |  | MPN_PENDING_SELECTION
R32 | 1 |  | PENDING_SELECTION | 10k | Resistor_SMD:R_0603_1608Metric |  |  |  | MPN_PENDING_SELECTION
R33 | 1 |  | PENDING_SELECTION | 10k | Resistor_SMD:R_0603_1608Metric |  |  |  | MPN_PENDING_SELECTION
R34 | 1 |  | PENDING_SELECTION | 10k | Resistor_SMD:R_0603_1608Metric |  |  |  | MPN_PENDING_SELECTION
R35 | 1 |  | PENDING_SELECTION | 10k | Resistor_SMD:R_0603_1608Metric |  |  |  | MPN_PENDING_SELECTION
R36 | 1 |  | PENDING_SELECTION | 10k | Resistor_SMD:R_0603_1608Metric |  |  |  | MPN_PENDING_SELECTION
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

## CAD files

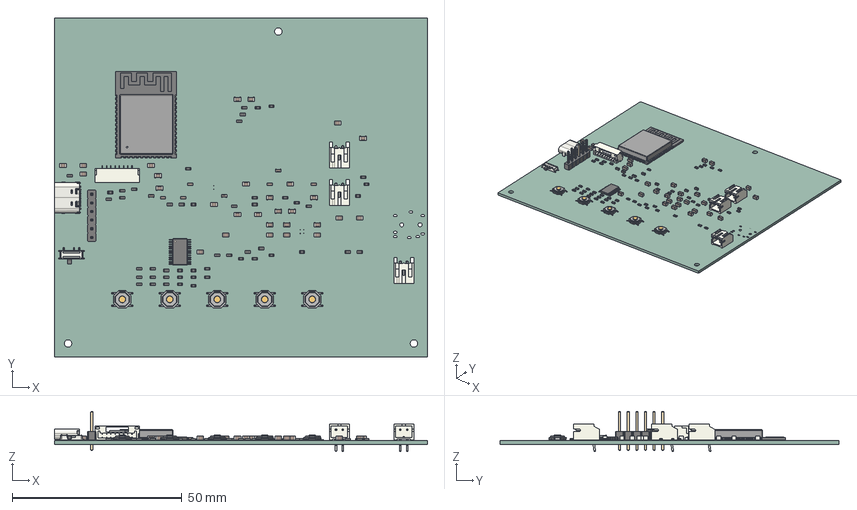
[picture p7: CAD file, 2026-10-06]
hardware/kicad/nightwave-reference/manufacturing/Nightwave-Reference-PCB-Review.step
110.0 x 100.0 x 11.9 mm
R_0603_1608Metric x 51
C_0805_2012Metric x 29
JST_S2B_PH_K x 3
C_0603_1608Metric x 8
PinHeader_1x06_P254mm_Vertical
Fusion_sp
SW_SPST_TL3342 x 5
JST_SM08B_GHS_TB
USB_C_Receptacle_16P_TopMnt_Horizontal_GCT_USB4105-xx-A
TSSOP-24_4.4x7.8mm_P0.65mm
ESP32-S3-WROOM-1
Nightwave-Reference_PCB

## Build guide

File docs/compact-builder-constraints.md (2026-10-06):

# Compact Nightwave requirements - 2026-10-06

User-approved constraints, not a finished layout or enclosure design.
Supersedes the former unanswered size/budget decision and prior permission to
produce the final PCB routing or final enclosure CAD automatically.

## Envelope and authorship

- PCB target <=90 x 60 mm; finished device target about <=110 x 70 x 25 mm.
  A few extra millimetres need an engineering reason and builder acceptance.
- The 110 x 100 mm AI reference is historical engineering input, not the final
  pocket-player board. Do not preserve its size merely to reuse routing.
- Builder authors final KiCad layout/routing and editable enclosure CAD.
  AI continues research, calculations, software/tests, sourcing, requirements
  and review. Do not shrink, reroute, generate or overwrite final CAD files.
- Retain selected S3 + BM83SM1-00TA, Waveshare 24382 and TCA9535; no silent
  substitutions or deletion of speaker, headphones, SD, controls or lyrics.

## Budget

Electronics plus PCB fabrication/assembly target maximum: INR15,000, excluding
reusable tools. Conservatively include delivery, taxes, import charges, setup,
stencil, minimum order quantities and spares within this ceiling. Enclosure
production cost is reported separately until inclusion is clarified, not free.

Planning allocations, NOT quotes: electronics INR8,000, PCB/assembly INR4,000,
freight/tax/contingency INR3,000. Rebalance against dated quotes, never by cutting
safety or assembly capability. There are 48 unresolved reference BOM entries
and no complete landed total. Partial prices do not establish affordability.
Quote the actual final board/stackup/quantity, not the large reference exports.

## Battery-independent power screening

Run `python tools/compact_design_screen.py`. Assumptions: 3.7 V nominal,
80% usable energy, 80% aging factor, 20% load margin, eight hours. These are
estimates, not measured performance. No candidate capacity is a pack selection.

| Hypothetical capacity | Maximum average cell-side power for 8 h |
| --- | ---: |
| 4,000 mAh | 0.987 W |
| 5,000 mAh | 1.233 W |
| 6,000 mAh | 1.480 W |
| 8,000 mAh | 1.973 W |

Existing reference speaker + retained BT estimate is 1.959 W, requiring about
7,940 mAh; wired requires about 6,775 mAh and Bluetooth about 6,674 mAh under
these assumptions. These are not final specifications. Worst-practical 1 W
speaker sensitivity requires about 16,077 mAh; do not automatically pick a huge
pack to satisfy that sensitivity. Define listening level and display duty,
implement safe inactive-route isolation/dimming, then recalculate. Muting is
not power-off. Peak current remains a separate protection/path constraint.

Neither historical 6,600 mAh nor reference 10,050 mAh is selected for the compact
device. Final sizing follows finalized BT/TFT/speaker/power topology, losses,
load profiles, minimum guaranteed capacity, protection, temperature and connector
limits. Actual runtime requires later physical measurement.

## Mechanical screening, not CAD

Illustrative 2 mm walls leave a 106 x 66 x 21 mm internal bounding box. A 1.2 mm
PCB leaves 19.8 mm total vertical space for components, display, pack, insulation,
retention and tolerance. Bosses, ports and cables reduce usable space further.

The [reference Adafruit 5035 pack](https://www.adafruit.com/product/5035) is
66.6 x 55.3 x 18.7 mm (manufacturer checked 2026-10-06). Stacking it over that
PCB leaves only 1.1 mm for everything else under these assumptions. This flags
a stack conflict, not proof all arrangements fail. Do not compress a cell to
fit. Use supplier-specific dimensional/swelling allowances for the eventual pack.

Builder requirements:

- Dimensioned XY/Z stack for exact display/module revisions, connectors/mates,
  cable bends, SD insertion, plug-body access and assembly sequence.
- Separate manufacturer RF exclusion volumes for both radios, accounting for
  every copper layer, battery, speaker metal, fasteners and enclosure material.
- Speaker retention/cone clearance/front-back acoustic separation; no invented
  acoustic tuning. Buttons need actuation travel and tolerance analysis.
- Battery service access, insulated retention, strain relief and NTC contact;
  no screws/edges pressing on cells; thermal review around charger/regulators.
- Actual fabrication stackup/impedance, power loops/returns, courtyards and
  tolerance/interference checks before routing release.

## Remaining non-builder closure before final handoff

1. USB source-current permission and reset-safe charger control; compatible NTC,
   charge limits, timing and fault behavior. Read-only telemetry is not safety control.
2. Final mode-specific energy/current/charge model with the compact constraints.
3. Exact sourced BOM and dated landed INR quote within target.
4. BM83 transport/provisioning/audio-rate integration and digital tests.
5. Verified manufacturer drawing register for mechanical and footprint requirements.

I2C race fix 161cbc9 is already pushed: CI37445159892 passed 18 Release,
18 ASAN/leak suites and 46 Python tests; firmware37445159915 passed both profiles.
New compact-screen tests are separate from that checkpoint. No builder CAD is
changed here. Independent review and physical qualification remain necessary.

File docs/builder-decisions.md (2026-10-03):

# Builder decisions

## Final pre-schematic choices

### BD-14 Bluetooth architecture

- Decision: A2DP SOURCE transport/platform, before final schematic.
- Alternatives: S3 + BM83 AT; original ESP32-WROVER main MCU; S3 + ESP32 coprocessor.
- My selection: retain ESP32-S3 plus Microchip BM83SM1-00TA, explicitly selected by the builder in chat on 2026-10-02.
- Why I selected it: not supplied; do not invent an AI-written first-person justification.
- Tradeoffs: See bluetooth-architecture.md; firmware access, rates, GPIO, power, cost and antennas.
- Evidence: Manufacturer research is linked in bluetooth-architecture.md; builder source/journal PENDING.
- Validation still required: chosen firmware/tools, one-headphone source demo, latency/rates, power, source review.

### BD-15 Display — selected 2026-10-03

- Decision: readable display SKU/envelope, before schematic/CAD.
- Alternatives: Adafruit 3787 1.54-inch TFT; Waveshare non-touch 1.69-inch TFT SKU 24382. Old OLED is a bench reference, not a final default.
- My selection: Waveshare 24382 non-touch 1.69-inch 240x280 ST7789V2 module, explicitly selected by the builder in chat on 2026-10-03. Not touch SKU 27057.
- Why I selected it: personal reasons not supplied; do not invent a first-person justification.
- Tradeoffs: Readability, SPI/GPIO/RAM, backlight power, driver and enclosure size.
- Evidence: actual builder chat selection; maker snapshots/calculations in display-selection.md. Builder source/journal remains PENDING.
- Validation still required: exact supplied module revision/drawing/thickness, connector/cable, combined pin strategy, driver, brightness/current, glyph/wrapping and fit tests. Selection is not physical qualification or battery approval.

### BD-16 Combined GPIO input expansion — selected 2026-10-03

- Decision: recover GPIO capacity without using USB, boot straps or PSRAM pins.
- Alternatives: TCA9535PWR input expansion; review a reduced/direct pin strategy.
- My selection: TI TCA9535PWR, explicitly selected in chat on 2026-10-03 for five buttons and slow card/charge/gauge inputs. Audio mute, power hold, TFT and BT timing controls remain direct.
- Why I selected it: personal reasons not supplied; do not invent them.
- Tradeoffs: one 24-pin IC, external pull-ups and IRQ; shared-bus failure/recovery and polling latency; eight unused inputs must not float.
- Evidence: actual chat selection; datasheet/register and ESP-IDF adapter regression in docs/input-expansion.md. Maker price/stock remain unverified.
- Validation still required: address straps, exact port/IRQ map, I2C electrical/POR/off-state review, debounced button integration, physical latency/current and footprint/source review. Selection is not schematic entry approval.

For subsequent choices use these seven fields: Decision / Alternatives / My
selection / Why I selected it / Tradeoffs / Evidence / Validation still required.
Earlier research records below remain historical prompts, not completed choices.

2026-10-01. Candidate comparisons below are AI-prepared research prompts, not
builder selections. The existing BOM's SELECTED labels are historical candidate
status, not proof of human authorship or final approval. Fill choices and reasons
only with the builder's actual account. Preserve alternatives and rejected ideas.
Link the real commit/files and genuine journal entry when available. Do not
invent hours. Verify genuine Hackatime tracking before a long authoring session;
no secret/key inspection is required.

## BD-01 MCU module and service interface

- Decision: PENDING BUILDER INPUT.
- Alternatives considered: ESP32-S3-WROOM-1-N16R8 versus smaller flash; native USB versus UART service pads (research candidates; builder may add/reject).
- Datasheet/reference: Espressif module datasheet and schematic checklist.
- Reason I selected it: PENDING BUILDER INPUT; do not AI-fill as a personal account.
- Risks/tradeoffs: Module availability; reserved PSRAM pins; recovery when firmware is broken.
- Validation still required: datasheet trace, actual source review, relevant ERC/DRC/fit and physical tests.
- Builder-authored files/commit and date: PENDING.

## BD-02 USB source-current policy

- Decision: PENDING BUILDER INPUT.
- Alternatives considered: Fixed conservative sink; advertised Type-C current detector; legacy-host enumeration policy (research candidates; builder may add/reject).
- Datasheet/reference: TUSB320 datasheet; USB-C requirements in schematic-requirements.md.
- Reason I selected it: PENDING BUILDER INPUT; do not AI-fill as a personal account.
- Risks/tradeoffs: Default/dead-battery current; changing advertisement; powered-off backfeed.
- Validation still required: datasheet trace, actual source review, relevant ERC/DRC/fit and physical tests.
- Builder-authored files/commit and date: PENDING.

## BD-03 Charger and recharge target

- Decision: PENDING BUILDER INPUT.
- Alternatives considered: BQ25185 linear versus BQ25628E switching power path; battery/profile changes (research candidates; builder may add/reject).
- Datasheet/reference: power-options.md and linked TI datasheets.
- Reason I selected it: PENDING BUILDER INPUT; do not AI-fill as a personal account.
- Risks/tradeoffs: Safety timer; reset defaults; enclosure thermal behavior; weak source.
- Validation still required: datasheet trace, actual source review, relevant ERC/DRC/fit and physical tests.
- Builder-authored files/commit and date: PENDING.

## BD-04 Pack and temperature sensing

- Decision: PENDING BUILDER INPUT.
- Alternatives considered: 6600 mAh protected pack versus documented higher-current pack; attached NTC versus pack-integrated NTC (research candidates; builder may add/reject).
- Datasheet/reference: Adafruit product 353; selected charger temperature circuit.
- Reason I selected it: PENDING BUILDER INPUT; do not AI-fill as a personal account.
- Risks/tradeoffs: Supplier current-rating conflict; mass/size; NTC retention; charge limits.
- Validation still required: datasheet trace, actual source review, relevant ERC/DRC/fit and physical tests.
- Builder-authored files/commit and date: PENDING.

## BD-05 3.3 V converter and shutdown

- Decision: PENDING BUILDER INPUT.
- Alternatives considered: TPS63802 with master disconnect versus another proven converter/power architecture (research candidates; builder may add/reject).
- Datasheet/reference: TPS63802 datasheet; power-options.md.
- Reason I selected it: PENDING BUILDER INPUT; do not AI-fill as a personal account.
- Risks/tradeoffs: Low-cell transients; effective capacitance; off-state leakage; charging while off.
- Validation still required: datasheet trace, actual source review, relevant ERC/DRC/fit and physical tests.
- Builder-authored files/commit and date: PENDING.

## BD-06 Fuel-gauge and low-battery policy

- Decision: PENDING BUILDER INPUT.
- Alternatives considered: MAX17048; validated voltage/SOC policy; interrupt or polling (research candidates; builder may add/reject).
- Datasheet/reference: MAX17048/MAX17049 datasheet.
- Reason I selected it: PENDING BUILDER INPUT; do not AI-fill as a personal account.
- Risks/tradeoffs: VDD sense wiring; model accuracy; bus backfeed; graceful shutdown.
- Validation still required: datasheet trace, actual source review, relevant ERC/DRC/fit and physical tests.
- Builder-authored files/commit and date: PENDING.

## BD-07 Storage and display

- Decision: PENDING BUILDER INPUT.
- Alternatives considered: Molex 104031-0811; exact SH1106 module versus documented SSD1306 module (research candidates; builder may add/reject).
- Datasheet/reference: Molex drawing; actual display vendor drawing required.
- Reason I selected it: PENDING BUILDER INPUT; do not AI-fill as a personal account.
- Risks/tradeoffs: Connector pin numbering; DAT pull-ups; module pin order and mounts.
- Validation still required: datasheet trace, actual source review, relevant ERC/DRC/fit and physical tests.
- Builder-authored files/commit and date: PENDING.

## BD-08 Controls and headphone detection

- Decision: PENDING BUILDER INPUT.
- Alternatives considered: Five momentary buttons; isolated insertion contact versus separate detector (research candidates; builder may add/reject).
- Datasheet/reference: schematic-requirements.md; actual jack drawing required.
- Reason I selected it: PENDING BUILDER INPUT; do not AI-fill as a personal account.
- Risks/tradeoffs: Audio-contact bias; detect polarity; ESD; button travel.
- Validation still required: datasheet trace, actual source review, relevant ERC/DRC/fit and physical tests.
- Builder-authored files/commit and date: PENDING.

## BD-09 Headphone signal chain

- Decision: PENDING BUILDER INPUT.
- Alternatives considered: PCM5102A plus TPA6132A2; gain/attenuation options and output ceiling (research candidates; builder may add/reject).
- Datasheet/reference: TI DAC/headphone-amp datasheets; engineering calculations.
- Reason I selected it: PENDING BUILDER INPUT; do not AI-fill as a personal account.
- Risks/tradeoffs: Clipping; hearing exposure; input impedance; pop sequencing; output load.
- Validation still required: datasheet trace, actual source review, relevant ERC/DRC/fit and physical tests.
- Builder-authored files/commit and date: PENDING.

## BD-10 Speaker path and assembly

- Decision: PENDING BUILDER INPUT.
- Alternatives considered: MAX98360CEFB+T 10-pin FC2QFN versus CENL+T 9-ball WLP or compatible alternative; fixed gain and I2S mode (research candidates; builder may add/reject).
- Datasheet/reference: MAX98360 family datasheet.
- Reason I selected it: PENDING BUILDER INPUT; do not AI-fill as a personal account.
- Risks/tradeoffs: Exact package assembly availability; DAI mode wiring; corrected output pin map; BTL output isolation; peak power.
- Validation still required: datasheet trace, actual source review, relevant ERC/DRC/fit and physical tests.
- Builder-authored files/commit and date: PENDING.

## BD-11 Connectors, protection and test access

- Decision: PENDING BUILDER INPUT.
- Alternatives considered: USB4105; keyed battery/speaker connectors; selected ESD devices and test points (research candidates; builder may add/reject).
- Datasheet/reference: Each exact manufacturer drawing required.
- Reason I selected it: PENDING BUILDER INPUT; do not AI-fill as a personal account.
- Risks/tradeoffs: Battery polarity; current rating; clamp voltage; service access.
- Validation still required: datasheet trace, actual source review, relevant ERC/DRC/fit and physical tests.
- Builder-authored files/commit and date: PENDING.

## BD-12 PCB manufacturing and placement

- Decision: PENDING BUILDER INPUT.
- Alternatives considered: Manufacturer/stackup, trace rules, assembly side, outline and mounting (research candidates; builder may add/reject).
- Datasheet/reference: layout-mechanical-requirements.md; chosen fab rules.
- Reason I selected it: PENDING BUILDER INPUT; do not AI-fill as a personal account.
- Risks/tradeoffs: RF keepout; switching noise; trace drop; DRC; component sourcing.
- Validation still required: datasheet trace, actual source review, relevant ERC/DRC/fit and physical tests.
- Builder-authored files/commit and date: PENDING.

## BD-13 Enclosure and acoustic design

- Decision: PENDING BUILDER INPUT.
- Alternatives considered: Battery/speaker placement, mounting/retention, screws, port datums, cavity (research candidates; builder may add/reject).
- Datasheet/reference: layout-mechanical-requirements.md; actual component dimensions.
- Reason I selected it: PENDING BUILDER INPUT; do not AI-fill as a personal account.
- Risks/tradeoffs: Fit tolerances; sound leakage; thermal clearance; serviceability.
- Validation still required: datasheet trace, actual source review, relevant ERC/DRC/fit and physical tests.
- Builder-authored files/commit and date: PENDING.

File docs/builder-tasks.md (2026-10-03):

# Builder tasks and source-review handoff

2026-10-01 final-addendum override: **do not start final schematic/PCB/CAD tasks
until Bluetooth architecture (BD-14) and display (BD-15) choices are recorded,
the current software checkpoint is pushed/verified, selections propagated, and
the updated power model, BOM and GPIO budget are complete**.
Read bluetooth-architecture.md and display-selection.md. The existing S3 pin
table and OLED envelope are provisional and cannot be treated as final.

BD-14 is selected: S3 + BM83SM1-00TA. BD-15 is selected: Waveshare 24382 non-touch.
BD-16 selects TCA9535PWR input expansion; the combined map and power/charger/pack
review remain open. See
[pin budget](pin-budget.md) and [current power screening](current-power-model.md).
The existing bench pins are not final combined-product assignments. Only after all the
entry checks above, start with task 1 (MCU); remaining tasks are assignments,
not a demand to complete the whole device before review. Return one subsystem
at a time. AI keeps independent research/test/documentation work moving, but
never claims your decisions/hours or authors final design files wholesale.

Before a long authoring session, verify genuine Hackatime tracking in your
editor; do not share keys. Record your actual choices/reasons in
[builder-decisions.md](builder-decisions.md). Save source under hardware/kicad
or enclosure, with required custom libraries. Screenshots support review but
are not substitutes for editable sources. No task below is marked completed.

Review loop: builder authors -> assistant traces against the exact datasheet,
identifies pin/net/footprint/value mistakes with explanations -> builder fixes ->
assistant re-reviews. Later add an independent human sanity check. For each
review record source commit, files, issue severity, required correction and
retest evidence. Do not mark ERC/DRC or fit passed unless actually executed.

## Bluetooth qualification checklist — not the first schematic builder task

### Objective

After the architecture choice, qualify an actual A2DP source path before locking its schematic.

### What I need to create

Builder-authored block for the selected module/MCU, control/provisioning access,
power/reset and digital audio interface; or integrate Classic Bluetooth in the
chosen main MCU block. Do not author both alternatives as if both were selected.

### Datasheets I need

Exact chosen module datasheet, source-firmware release notes/UART guide or
Espressif Classic A2DP source API/example; links in bluetooth-architecture.md.

### Engineering decisions I must make

Exact source-capable SKU/firmware, clocks/rates, provision/recovery access,
power-off/backfeed, GPIO allocation and antenna coexistence/keep-outs.

### Constraints

No sink-only/BLE substitution. Support the required sample rates via validated
conversion if needed. No sudden speaker fallback on wireless disconnection.
Never use a module's internal power output to feed arbitrary peripherals.

### Checklist

- [ ] Record BD-14 choice/reasons; verify real firmware/tool availability and source role.
- [ ] Reconcile display/SD/audio/control GPIO and rail/peak-current budgets.
- [ ] Return one-headphone digital/bench evidence under a separate safe human gate.
- [ ] Keep provisioning and firmware licensing reproducible; no unqualified codec claims.

### What files/screenshots to return

Actual builder source block/reference annotations, firmware/SKU/tool versions,
BD-14 entry, unresolved issues and real prototype logs when performed.

## BUILDER TASK — 1. Chosen MCU module

### Objective

After every entry gate above, create the retained ESP32-S3 MCU sheet. Reconcile
the combined BM83/TFT/SD/audio GPIO and updated power budget first.

### What I need to create

A KiCad module block with 3V3/GND, EN reset, GPIO0 boot, service access and named peripheral interfaces.

### Datasheets I need

Module datasheet pin table/reference/land pattern; Espressif schematic checklist (links in schematic-requirements.md §1).

### Engineering decisions I must make

Module suffix, reset timing, USB versus UART recovery and GPIO-to-module-pad mapping.

### Constraints

Use the module reference, not bare-chip crystal/flash circuitry. Do not assign PSRAM/strap/USB pins to other functions.

### Checklist

- [ ] Verify all grounds/center pad, local bulk/decoupling, EN default, boot access, no accidental rail shorts and header-consistent GPIOs.
- [ ] Record real decisions/reasons, source revision and unresolved questions.

### What files/screenshots to return

Editable .kicad_pro/.kicad_sch plus custom symbol/library files; MCU-sheet PDF or screenshots, ERC report with unresolved items, and BD-01 choices.

## BUILDER TASK — 2. USB-C input and service

### Objective

Define an input that never overdraws its source.

### What I need to create

Connector/protection/CC block and a default/attached/detached current-policy table.

### Datasheets I need

Exact GCT suffix drawing; chosen CC controller if used (§2).

### Engineering decisions I must make

Power-only versus native USB, passive Rd versus current-aware sink, shield/protection and legacy-source policy.

### Constraints

No default highest-current assumption; no 5 V into GPIO; protect every powered-off path.

### Checklist

- [ ] Trace both plug orientations, CC independence/controller Rd, reset/dead-battery limit, source-change fallback and inrush.
- [ ] Record real decisions/reasons, source revision and unresolved questions.

### What files/screenshots to return

Editable sheet, exact connector drawing, state/current table and BD-02/11 entries.

## BUILDER TASK — 3. Charger and power path

### Objective

Resolve the large-pack timer/source/thermal conflict.

### What I need to create

Chosen charger sheet, component calculations and POR/watchdog/fault table.

### Datasheets I need

power-options.md; exact selected charger/cell datasheets (§3).

### Engineering decisions I must make

Charger, current, timer, termination, temperature monitoring and recharge expectation.

### Constraints

Keep safety mechanisms; charge setting cannot create absent source power. No cell connection or ordering.

### Checklist

- [ ] Trace IN/BAT/SYS, CE, NTC open/short, timer, input cap and thermal estimate.
- [ ] Record real decisions/reasons, source revision and unresolved questions.

### What files/screenshots to return

Editable sheet, value calculations, reset/fault table, source evidence and BD-03/04 entries.

## BUILDER TASK — 4. 3.3 V regulator and shutdown

### Objective

Provide stable logic power and real off behavior.

### What I need to create

Regulator sheet plus master-disconnect/wake schematic.

### Datasheets I need

TPS63802 reference/package or chosen alternative; switch/latch datasheet (§4).

### Engineering decisions I must make

Converter, effective caps, inductor, MODE/EN, charging while off and wake method.

### Constraints

SYS speaker branch must obey off policy; no invented latch just from POWER_HOLD.

### Checklist

- [ ] Check divider tolerance, inductor saturation, min-cell peak load, shutdown leakage paths.
- [ ] Record real decisions/reasons, source revision and unresolved questions.

### What files/screenshots to return

Editable sheet, calculations, off/wake state diagram and BD-05 entry.

## BUILDER TASK — 5. Fuel gauge

### Objective

Sense the protected cell without back-powering switched logic.

### What I need to create

Gauge block and low-battery/hysteresis requirements.

### Datasheets I need

MAX17048 pin/application/I2C sections (§5).

### Engineering decisions I must make

Pull-up domains, alert versus polling and unknown/low/recovery states.

### Constraints

MAX17048 VDD senses the cell; CELL is not its internal sense input.

### Checklist

- [ ] Check VDD bypass, CTG/EP/GND, QSTRT, bus off state and ALRT polarity.
- [ ] Record real decisions/reasons, source revision and unresolved questions.

### What files/screenshots to return

Editable block and BD-06 entry; no SOC/runtime measurement assumed.

## BUILDER TASK — 6. microSD

### Objective

Connect one-bit storage with all required biasing.

### What I need to create

Socket, decoupling, detect and protection block.

### Datasheets I need

Exact Molex sales drawing and Espressif SD pull-up requirements (§6).

### Engineering decisions I must make

Socket, detect polarity, inrush and protective/series components.

### Constraints

External CMD/DAT0–3 pull-ups even for one-bit; 3.3 V contacts.

### Checklist

- [ ] Compare contact numbers to drawing, card insertion envelope and current GPIO map.
- [ ] Record real decisions/reasons, source revision and unresolved questions.

### What files/screenshots to return

Editable block, actual socket drawing and BD-07 entry.

## BUILDER TASK — 7. Builder-selected display

### Objective

Implement the BD-15 chosen display interface after its combined budget review.

### What I need to create

Exact module/connector/reset block and dimension reference.

### Datasheets I need

Actual chosen module supply/pin/dimension/controller drawing; display-selection.md.

### Engineering decisions I must make

Review selected Waveshare 24382/ST7789V2 four-wire SPI, exact cable/mating
connector, reset/PWM backlight, 3.3 V logic/supply, GPIO and mounting. Do not
reopen SPI versus I2C or substitute the old OLED without a new builder decision.

### Constraints

Do not reuse the old OLED pin/window assumptions for TFT. Budget DMA/PSRAM,
backlight current and SPI GPIO together with the BD-14 Bluetooth transport.

### Checklist

- [ ] Check controller, logic rail, pull-ups, sleep/off bus and mount/window dimensions.
- [ ] Record real decisions/reasons, source revision and unresolved questions.

### What files/screenshots to return

Editable block, vendor drawing/URL, exact MPN and BD-15 entry.

## BUILDER TASK — 8. Five buttons

### Objective

Provide reliable electrical controls and mechanically supported actuators.

### What I need to create

Five switch blocks with named controls and exact switch drawing.

### Datasheets I need

Chosen switch maker datasheet; firmware interface contract (§8).

### Engineering decisions I must make

Switch package/force/travel, pull-up/RC, exposed-interface ESD.

### Constraints

Active-low mapping; do not accidentally ground unused common pads or a strap.

### Checklist

- [ ] Confirm commoning, rest/pressed state, debounce compatibility and actuator height.
- [ ] Record real decisions/reasons, source revision and unresolved questions.

### What files/screenshots to return

Editable block, switch drawing and BD-08 entry.

## BUILDER TASK — 9. PCM5102A DAC

### Objective

Create the line-level stereo source.

### What I need to create

DAC block, pump/decoupling/filter circuit and mute requirement.

### Datasheets I need

TI pin table and reference figure 33 (§9).

### Engineering decisions I must make

3-wire mode, FMT/FLT/DEMP, filtering and mute sequencing.

### Constraints

No headphones directly on line output; GPIO18 enable relationship is not finalized.

### Checklist

- [ ] Trace each pump/supply pin, I2S, output routing and shutdown timing.
- [ ] Record real decisions/reasons, source revision and unresolved questions.

### What files/screenshots to return

Editable block, pin trace and BD-09 entry.

## BUILDER TASK — 10. Headphone amplifier

### Objective

Provide a deliberately bounded, low-pop loaded output.

### What I need to create

Amp block, gain/attenuation budget and chosen input circuit.

### Datasheets I need

TPA6132A2 single-ended reference/gain table (§10).

### Engineering decisions I must make

Gain straps, input attenuation, high-pass corner and loaded output target.

### Constraints

A chosen voltage is not universal hearing safety; no listening at uncontrolled full scale.

### Checklist

- [ ] Check both input pairs, pump caps, EN low on reset, load clipping and hotplug policy.
- [ ] Record real decisions/reasons, source revision and unresolved questions.

### What files/screenshots to return

Editable block, calculations and BD-09 entry.

## BUILDER TASK — 11. Speaker amplifier

### Objective

Implement the exact part's I2S/BTL path.

### What I need to create

Amp supply/DAI/gain/enable/output block.

### Datasheets I need

MAX98360 exact FC2QFN or WLP pin/DAI/package sections (§11).

### Engineering decisions I must make

Exact suffix/package, mono selection, fixed gain and supply limits.

### Constraints

CEFB+T is FC2QFN, not WLP; OUTP/N never ground.

### Checklist

- [ ] Verify corrected output pin map, DAI configuration, disabled boot and supply current.
- [ ] Record real decisions/reasons, source revision and unresolved questions.

### What files/screenshots to return

Editable block, exact footprint/reference drawing and BD-10 entry.

## BUILDER TASK — 12. Headphone jack and detect

### Objective

Produce digital insertion indication without biasing audio.

### What I need to create

Exact jack plus isolated-contact/detector circuit and truth table.

### Datasheets I need

Actual selected jack switch drawing; detector datasheet if used (§12).

### Engineering decisions I must make

Jack/contact topology, logic polarity, ESD and default mode.

### Constraints

Do not pull an audio switch contact to 3.3 V without a justified detector.

### Checklist

- [ ] Trace every contact absent/present and annotate GPIO16 low/high behavior.
- [ ] Record real decisions/reasons, source revision and unresolved questions.

### What files/screenshots to return

Editable block, source drawing, circuit truth table and BD-08/11 entries; bench continuity only when actually obtained.

## BUILDER TASK — 13. Speaker connector

### Objective

Retain and service the BTL speaker wiring.

### What I need to create

Rated keyed connector and mating cable definition.

### Datasheets I need

Exact connector/mate current/geometry drawing (§13).

### Engineering decisions I must make

Connector, cable/current/retention and service direction.

### Constraints

SPK_P/N are not power/ground; no chassis/ground contact.

### Checklist

- [ ] Check pin/mate orientation, current and strain relief.
- [ ] Record real decisions/reasons, source revision and unresolved questions.

### What files/screenshots to return

Editable block, connector drawing and BD-11 entry.

## BUILDER TASK — 14. Battery connector and NTC

### Objective

Provide safe pack polarity, retention and real temperature sensing.

### What I need to create

Pack connector/sensor block with actual polarity and retention requirements.

### Datasheets I need

Pack, connector/mate and NTC datasheets (§14).

### Engineering decisions I must make

Exact pack/current capability, connector, reverse protection and sensor mounting.

### Constraints

No cell-wrap modification/soldering; no assumed JST polarity; no fixed TS bypass.

### Checklist

- [ ] Check polarity, wire rating, protection and NTC fault behavior.
- [ ] Record real decisions/reasons, source revision and unresolved questions.

### What files/screenshots to return

Editable block, supplier evidence, sensor plan and BD-04/11 entries.

## BUILDER TASK — 15. Test and programming

### Objective

Make recovery and safe diagnostics accessible.

### What I need to create

Named test points, boot/reset/service pads and measurement access.

### Datasheets I need

MCU recovery reference and selected connector/probe drawings (§15).

### Engineering decisions I must make

UART/USB access, pad geometry and current measurement link.

### Constraints

No grounded probe on BTL output; no 5 V UART GPIO.

### Checklist

- [ ] Check access after assembly and readable net/polarity labels.
- [ ] Record real decisions/reasons, source revision and unresolved questions.

### What files/screenshots to return

Editable sheet and BD-01/11 entry.

## BUILDER TASK — 16. PCB outline, placement and routing

### Objective

Author the reviewed circuit as a manufacturable board.

### What I need to create

Actual outline/mounts, validated footprints, placements, routes and planes.

### Datasheets I need

layout-mechanical-requirements.md; exact fab stackup/rules and package drawings.

### Engineering decisions I must make

Board geometry, stackup, port datums, placement and routing choices.

### Constraints

Do not start final routing before schematic/footprint review; builder performs placements/routes.

### Checklist

- [ ] Run DRC; inspect returns, power loops, antenna exclusion, source/CAD alignment and assembly capability.
- [ ] Record real decisions/reasons, source revision and unresolved questions.

### What files/screenshots to return

Editable .kicad_pcb/.kicad_pro, custom libraries, stackup/rules, DRC report, layer views, STEP and BD-12 entry.

## BUILDER TASK — 17. Editable enclosure assembly

### Objective

Author a serviceable fitted enclosure around real components.

### What I need to create

Base/lid, mounts/retention, control guides, port openings and complete assembly.

### Datasheets I need

layout-mechanical-requirements.md; actual board/component/fastener drawings.

### Engineering decisions I must make

Datums, material/process tolerances, cavity/grille, screws, cable/tool access.

### Constraints

No final enclosure around guessed OLED/jack/speaker dimensions; no compressed battery.

### Checklist

- [ ] Check worst-case clearances, interference, assembly order, thermal/RF envelope and removability.
- [ ] Record real decisions/reasons, source revision and unresolved questions.

### What files/screenshots to return

Editable native CAD, electronics-inclusive STEP, sections/dimension/tolerance table, interference report and BD-13 entry.

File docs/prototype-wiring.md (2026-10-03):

# Phase 2 prototype wiring

Checked: 2026-09-30. This is a staged bench-wiring plan for the exact parts in [`hardware/prototype-BOM.csv`](../hardware/prototype-BOM.csv), not permission to connect a battery or a claim that the wiring has been built.

The machine-readable pin-by-pin table is [`hardware/prototype-wiring.csv`](../hardware/prototype-wiring.csv). `tools/validate_project.py` checks its ESP GPIO assignments against the firmware hardware configuration.

## Prototype scope

The prototype proves the architecture in separable stages:

1. ESP32-S3 boot/logging;
2. five buttons and OLED;
3. raw 3.3 V microSD in 1-bit SDMMC mode;
4. PCM5102 stereo line output;
5. TPA6132A2 headphone output;
6. MAX98357A mono speaker output.

No lithium cell or charger is used. The MAX98357A breakout is a functional proxy for the provisional MAX98360C speaker path. The Adafruit SSD1306 breakout is a bench-only UI proxy. The builder selected Waveshare 24382 non-touch TFT in BD-15; the old SH1106 proposal is obsolete, not a final product default. This bench map does not allocate the selected BM83 or TFT; do not wire them from this table.

## GPIO map and development-board exceptions

| Function | GPIO | Physical destination |
|---|---:|---|
| I2S BCLK / LRCLK / data | 5 / 6 / 7 | PCM5102 and MAX98357A inputs in parallel |
| I2C SDA / SCL | 8 / 9 | OLED |
| SD CMD / CLK / DAT0 | 11 / 12 / 13 | raw microSD breakout |
| Previous / play / next | 1 / 2 / 4 | normally-open switches to ground |
| Volume down / up | 10 / 15 | normally-open switches to ground |
| Speaker enable | 17 | MAX98357A `SD` |
| DAC mute | 18 | PCM5102 `MUTE`, after polarity confirmation |

The SparkFun BOB-00544 does **not** expose a mechanical card-detect switch. Its `CD/DAT3` label is the SD DAT3/chip-select signal, so prototype GPIO14 is left unused and card insertion/removal is handled through mount/read failures. This is intentionally different from the final switched socket.

ESP32-S3-DevKitC-1 v1.1 drives its RGB LED from GPIO38. Do not connect the provisional final-board `POWER_HOLD` function to GPIO38 during the prototype. GPIO19/20 remain reserved for native USB, GPIO43/44 for UART0, and strapping/flash/PSRAM GPIO remain unused.

## SD pull-ups

Espressif specifies 10 kΩ pull-ups on CMD and DAT0–DAT3 even in 1-bit mode, and states that the DevKitC-1 provides none. Install five external resistors:

| Card signal | Connection |
|---|---|
| CMD | 10 kΩ to 3.3 V, plus GPIO11 |
| DAT0 | 10 kΩ to 3.3 V, plus GPIO13 |
| DAT1 | 10 kΩ to 3.3 V; otherwise unconnected |
| DAT2 | 10 kΩ to 3.3 V; otherwise unconnected |
| DAT3 | 10 kΩ to 3.3 V; otherwise unconnected |

CLK connects to GPIO12 without a pull-up. Card VCC is 3.3 V only. Source: [ESP32-S3 SD pull-up requirements](https://docs.espressif.com/projects/esp-idf/en/latest/esp32s3/api-reference/peripherals/sd_pullup_requirements.html).

## Headphone signal path

The PCM5102 breakout produces line level and explicitly requires a load of at least 1 kΩ. Do not plug headphones into its jack.

For the TI TPA6132A2EVM2:

- connect ground before VDD;
- power VDD from 3.3 V;
- connect PCM5102 left/right analog pads to `INL`/`INR`;
- install JP1 and JP2 shunts for single-ended input;
- select 0 dB gain (`G1=0`, `G0=1`);
- begin with the source muted and digital volume at zero;
- connect headphones only to the EVM output jack.

The official EVM guide permits 2.5–5.5 V and documents those jumper settings. Do not replace it with an unidentified marketplace module. `docs/headphone-prototype-options.md` selects the documented Adafruit 6309 TLV320DAC3100 breakout as a provisional separate headphone-test path; it requires its own reviewed wiring and ESP-IDF I2C driver and does not validate the PCM5102 plus TPA6132A2 chain. An open MIT TPA6132A2 breakout remains a fabrication alternative only after schematic and assembly review.

## Speaker signal path

The MAX98357A `+` and `-` outputs form a bridge-tied load. Connect them only across the 8 Ω speaker. Neither terminal may be grounded, probed with a ground-referenced oscilloscope clip, or fed into another amplifier.

Start with `SD` low, software volume at zero, and the breakout powered from a current-limited 5 V source. Enable only after clocks and zero PCM data are stable. The default board configuration mixes left and right to mono.

## Voltage domains

| Domain | Nominal | Loads | Rule |
|---|---:|---|---|
| USB/bench | 5 V | DevKitC input; MAX98357A VIN | current-limited during staged bring-up |
| Logic | 3.3 V | SD; OLED; PCM5102; TPA6132A2 EVM; GPIO | never expose raw SD to 5 V |
| I2S/I2C/GPIO | 3.3 V logic | all digital signals | no level shifting required for selected boards |
| PCM analog | ground-centered line level | DAC to headphone EVM | keep short and away from speaker output wiring |
| Speaker BTL | switching differential output | 8 Ω speaker only | neither lead is ground |

## Planning current envelope

These ranges size the bench source and help catch gross wiring faults. They are not measurements and must not be reported as results.

| Load/state | Expected planning range |
|---|---:|
| DevKitC, radios disabled | 50–150 mA from 5 V |
| microSD active reads | 20–100 mA at 3.3 V, with possible higher bursts |
| PCM5102 breakout active | 15–30 mA at 3.3 V |
| TPA6132A2 EVM | 2–5 mA idle; roughly 5–40 mA playing depending on load |
| OLED, content dependent | 10–40 mA at 3.3 V |
| MAX98357A and 8 Ω speaker | 2–10 mA idle; roughly 50–300 mA at quiet/moderate output; higher peaks possible |
| Whole prototype | roughly 80–220 mA idle; 150–700 mA during speaker playback |

Use a source capable of at least 1 A continuous; 2 A gives margin. Set a lower current limit for each isolated first-power stage, then raise it only when the observed draw is understood.

## Unresolved physical facts

Before board-specific firmware is merged, record photographs and labels for every actual module, the exact DevKitC revision, microSD make/model, headphone impedance, power-source arrangement, OLED I2C address, and whether the PCM5102 `MUTE` and MAX98357A `SD` pins behave as documented.

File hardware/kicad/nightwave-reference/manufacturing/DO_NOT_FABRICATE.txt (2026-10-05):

UNBUILT AI-AUTHORED REVIEW EXPORTS - NOT FABRICATION APPROVED
See ../VALIDATION_STATUS.md and ../REVIEW_CHECKLIST.md.
A clean DRC is not charging, thermal, RF, USB or mechanical qualification.

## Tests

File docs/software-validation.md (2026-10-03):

# Digital software validation

No physical playback, timing, fit, current, temperature or battery result is
claimed by these tests. Native device build and host simulations are different
evidence from a bench test.

The serial/player path uses `StreamingPlayer`: StorageTask -> 32768-byte SPSC
encoded ring -> DecoderTask -> 16384-frame stereo PCM ring -> AudioOutputTask
-> I2S DMA. Buffers live off worker stacks. The older two-task WavPlayer remains
a historical bring-up implementation and is not the active product path.

Helix 1.0.3 handles CBR/VBR Layer III; bounded ID3v2 skipping, ID3v1 tail skip,
framing, corrupt-frame recovery and typed EOF/errors surround the dependency.
Supported output rates are 22.05/32/44.1/48 kHz; mono duplicates to stereo. Free
format, MPEG2.5, unsupported rates and mid-track rate changes are rejected.
Rate changes between tracks reconfigure the sink after teardown. Tags above
16 MiB are rejected; resync/decode-error recovery is limited to 8192 bytes per
track. There is no unbounded retry of an unchanged compressed frame.

The output worker owns gain ramping, pause fade/drain/mute, resume fade, route
changes and teardown. Natural EOF drains DMA with silence. Errors cancel both
producers; completion publishes only after resources are closed. A bounded
stop timeout is not permission to delete live resources or start a new track.

## Host regression coverage

- WAV bounds, RIFF chunks, unsupported formats, generated PCM fixture.
- MP3 stereo CBR, mono VBR and MPEG2 mono, fragmented input, ID3 and truncated
  frames; deterministic corrupt byte corpus with bounded progress.
- Real StreamingPlayer with host-thread RTOS and simulated I2S: 1000 alternating
  WAV/MP3 starts/cancels, overlap refusal, pause/resume control cycles, an observed
  held/muted pause, resume, EOF, output fault/recovery, partial task creation and
  delayed-stop retention. Those are simulated scheduling tests, not 1000 physical
  track-change measurements.
- SPSC full/wrap/empty plus 100000 ordered transfers across two host threads;
  overflow-safe mono mixing, Q15 volume and ramp endpoints.
- Real PlayerFrontend with fake devices and actual host directory scans:
  folders, five-button commands, file changes, corrupt recovery, route indicator,
  delayed setting writes, diagnostic view, sleep/wake and mount retry.
- Actual I2S adapter with mocked ESP driver: configuration, preload, silence
  drain, write errors and output-enable behavior.
- Actual OLED/NVS adapters with mocked APIs: SH1106 page/offset versus SSD1306
  window addressing, render bytes, sleep/wake, bus errors/cleanup, volume
  persistence, malformed stored values and open/set/commit/init failures.
- Bounded LRC sorting/offset/multi-tags/duplicate timestamps/UTF-8, malformed and
  overlong documents, local M3U root containment, ID3 UTF-8/UTF-16 and WAV duration;
  1000 parser/fuzz/shuffle operations and sleep-timer unsigned-clock rollover.
- New real-frontend metadata/lyrics/settings/sleep/M3U controls with fake playback,
  sample clock freeze/direct WAV/MP3 decode-discard seek in real streaming tests,
  and actual checked NVS blob serialization/corruption handling.

CI generates its own WAV tones and encodes MP3 with FFmpeg; no songs are fetched.
Host Helix math substitutes equivalent C primitives; device builds use Xtensa
source. Read [dependency terms](decoder-licenses.md).

## Reproduce on Linux

```
python3 tools/validate_project.py
python3 tools/power_budget.py
python3 tools/generate_test_media.py --output .generated/test-media
# Encode the three original MP3 fixtures exactly as project-quality.yml does.
cmake -S tests -B build/host-tests -DCMAKE_BUILD_TYPE=Release
cmake --build build/host-tests --parallel
ctest --test-dir build/host-tests --output-on-failure
```

CI supplies full C++/ESP-IDF evidence; no Windows C++ compiler is on PATH.
Ubuntu WSL has g++ but no CMake; targeted frontend/ASAN tests can also run there.
Execution records below must name a successful commit/run,
not merely the presence of workflow files.

Executed evidence at `13ed6be` (2026-10-01):

- [ESP32-S3 firmware build](https://github.com/Hustlenix/Nightwave/actions/runs/36864360208): success.
- [Project quality](https://github.com/Hustlenix/Nightwave/actions/runs/36864360149): five test executables, 5/5 passed.

At `a2aa741`, [Project quality](https://github.com/Hustlenix/Nightwave/actions/runs/36865138075)
ran all six executables successfully, including actual OLED/NVS adapters against
mock APIs; [firmware build](https://github.com/Hustlenix/Nightwave/actions/runs/36865138056)
also passed.

At `6349cd0`, [Project quality](https://github.com/Hustlenix/Nightwave/actions/runs/36865602237)
passed all six suites in Release and again with AddressSanitizer and leak
detection (6/6 in each configuration). This includes the decoder's corrupt
corpus and actual streaming/frontend/adapter sources. No sanitizer finding was
reported by that run; this is not proof against every possible malformed file
or target-only race.

At `ea393ac`, [Project quality](https://github.com/Hustlenix/Nightwave/actions/runs/36874323047)
passed repository/BOM/wiring checks, the 17-task handoff structure check,
engineering-calculation self-tests, and all six suites in both Release and
AddressSanitizer with leak detection. This validates software and calculated
screening examples, not schematic/footprint correctness or physical behavior.
Device firmware source is unchanged from the previously successful device build.

At `35b7ab4`, [device build](https://github.com/Hustlenix/Nightwave/actions/runs/36878328683)
and [Project quality](https://github.com/Hustlenix/Nightwave/actions/runs/36878328795)
succeeded, with 7/7 Release and 7/7 AddressSanitizer/leak suites. Initial
54ba552 exposed a clipped corrupt-path error title; fixed to show the filename.
The later playlist-resume test exposed a noncanonical CTest fixture root
(tests/../) conflicting with the canonical SD-root contract. Test roots now use
weakly_canonical, and suite-owned generated playlists are cleared before each
run to make Release/ASAN reruns independent. No user media is removed.

Current UI lyrics/queue allocate explicitly in S3 PSRAM after boot; host tests
allocate them on the heap. The radio/display/power/load limits and unfinished
expanded-scope features are documented in engineering-budgets.md. A passing
build/sanitizer result does not establish physical sync, timing or production
readiness. Performance counters saturate at UINT32_MAX; discard derived averages
after saturation. Stack minima are meaningful only after workers report them.

At `50df90c`, [ESP32-S3 build plus size/component reports](https://github.com/Hustlenix/Nightwave/actions/runs/36882011549)
and [Project quality](https://github.com/Hustlenix/Nightwave/actions/runs/36882011690)
passed. All seven suites passed in Release and ASAN with leak detection,
including canonical-root M3U resume, isolated test fixtures and heap UI assets.
Targeted frontend and media suites also ran under ASAN/leak detection in Ubuntu
WSL; both passed. At `92c17ea`, [Project quality](https://github.com/Hustlenix/Nightwave/actions/runs/36882687260)
passed again after diagnostic-parser array/saturation validation fixes. Firmware
source is unchanged from 50df90c. Local project/calculation/parser self-tests pass.

2026-10-02 catalog continuation: targeted actual catalog + frontend sources
compiled in Ubuntu WSL with g++17, -Wall/-Wextra/-Wpedantic/-Werror and ASAN/leak
detection, and both executed successfully. Coverage includes 262-track catalog
and 260-track UI fixtures, paging, groups, full queues, repeat/seek, context
resume, backup fallback, corrupt checksums/paths, limits and 1,000 query/cancel
cycles. Repository validator and diff whitespace checks also passed. A new
device build and full eight-suite Release/ASAN CI run are required; their actual
results will be recorded below after execution. No physical acceptance inferred.

The initial merged checkpoint adbb92e failed its optimized Release compilation
in run 36962394436: GCC inlining reported possible snprintf truncation in the
cache-path helper. The join was replaced by checked lengths/memcpy; warning
policy was not weakened. Sanitizer success alone does not replace Release or
device compilation. Record the repaired run's results only after execution.

At 3ce6014 (run 36962585890), optimized compilation passed; 7/8 Release suites
passed. The new catalog location assertion used CTest's `tests/../` fixture path
instead of its canonical root. The fixture lookup now uses the canonical root,
matching the saved-path contract. ASAN was skipped by that failed run; it is
not recorded as a pass. Targeted WSL tests with canonical arguments had passed.

Validated checkpoint `14b10c02e433cf87f54a9f238603f0969b49ef90`:

- [ESP32-S3 build + size/components](https://github.com/Hustlenix/Nightwave/actions/runs/36962788706): success.
- [Project quality](https://github.com/Hustlenix/Nightwave/actions/runs/36962788677): success, 8/8 Release and 8/8 ASAN/leak suites.
- New frontend assertions verify catalog traversal does not advance while audio
  owns workers. The fake-audio suite does not prove on-device SD starvation bounds.
- Link report: DIRAM 204,882/341,760 bytes, remaining 136,878; .bss 144,960;
  image 437,340 bytes. Not runtime heap/PSRAM/CPU measurements.
- The device build includes upstream ESP-IDF Wi-Fi/supplicant CMake dependency
  warnings; it successfully builds. No project warning was suppressed.
- Concurrent origin/main CI/setting-migration/website changes were preserved
  via merge adbb92e, not overwritten. The original adbb92e device run was
  superseded/cancelled; it is not counted as successful validation.

The subsequent c05ba8d documentation-only ledger left firmware/test source identical
to this validated checkpoint. The full product is still not funding-ready;
library-index.md records lookup/fallback performance and physical acceptance gaps.

2026-10-02 v2 lookup continuation: targeted WSL catalog tests passed with
optimized -O3/_FORTIFY_SOURCE=3 and -Wall/-Wextra/-Wpedantic/-Werror, and again
with AddressSanitizer/leak detection. The catalog builds actual 10,000-file
metadata-only fixtures, checks zero-read group pages, ≤16-read filtered pages,
one-read selection/correct resume hints, stale hints, malformed footers,
1,024/1,025-group boundaries, legacy migration and 1,000 query/cancel cycles.
The expanded frontend suite passed ASAN/leak detection with actual catalog/UI
sources and fake audio/devices, including cold/legacy/malformed resume without
boot autoplay. Lookup allocation is 227,488 bytes per generation (bounded
explicit PSRAM on target, host heap in tests), not internal static storage.
These operation counts are not measured SD/UI/acoustic latency. A new full
eight-suite Release/ASAN run and ESP32-S3 build are required for this source;
record their actual results below, not the older checkpoint's success.

Validated/pushed v2 library checkpoint df301661256671e3db892fd3cd6450fb65588c4f:

- [ESP32-S3 build](https://github.com/Hustlenix/Nightwave/actions/runs/36994661327): success.
- [Project quality](https://github.com/Hustlenix/Nightwave/actions/runs/36994661341): success; 8/8 Release and 8/8 ASAN/leak.
- Link DIRAM 204882/341760, .bss 144960, image 445484 bytes. Not runtime heap.
- Concurrent website-only origin commits were preserved by merge, not overwritten.

Next digital continuation adds idle MP3 frame-duration/seek caches, real-Helix
indexed-seek equivalence checks, injected display frames, bounded Bluetooth
source control, unknown-safe power interfaces and engineering JSON. Targeted
local index Release/ASAN-leak and real-streaming Release tests passed. The
15-second indexed seek matches decode-from-start PCM hash/sample count and uses
fewer decode calls/SD bytes. This is synthetic host output, not physical latency.
Full new-source CI/device results must be recorded separately after execution.

Validated/pushed digital source `8c7015e6aac9ec7024e46e5aa58eeba0afa8604b`:

- [ESP32-S3 build/size](https://github.com/Hustlenix/Nightwave/actions/runs/37002164509): success.
- [Project quality](https://github.com/Hustlenix/Nightwave/actions/runs/37002164501): success, 10/10 Release plus 10/10 ASAN/leak suites; validator/arithmetic passed.
- MP3 index/streaming, display injection and BT/power/engineering HAL coverage
  are included, not inferred from the earlier eight-suite run.
- Link DIRAM 205394/341760, remaining 136366; .bss 145456; image 453300 bytes.
  These are link figures, not runtime free heap, stack/PSRAM or physical proof.
- Original b28228c host tests passed; its [device run](https://github.com/Hustlenix/Nightwave/actions/runs/37001601554)
  failed on initializer-list unsigned-int versus target uint32_t type deduction.
  A fixed-width array repaired it; warnings were not disabled. Website quality
  passed at b28228c. Failed build is retained, not counted as a pass.

Subsequent manufacturer-defined AT codec source requires its own run below;
neither wire-format tests nor this build proves wireless transmission.

Final firmware source `ee2f4fcf73614d2327ecfeccc653c36a05663846` is pushed:

- [ESP32-S3 firmware](https://github.com/Hustlenix/Nightwave/actions/runs/37003131904): success.
- [Project quality](https://github.com/Hustlenix/Nightwave/actions/runs/37003131911): success; 10/10 Release and 10/10 ASAN/leak, validator/arithmetic passed.
- Includes the manufacturer-defined fixed AT command/status codec and 1000
  repeated valid/invalid status cycles, without enabling the radio backend.
- All large-library, settings reload/stale resume, corruption/capacity/migration,
  MP3 seek and display/BT/power/report tests ran in those suites. Indexed real-
  decoder PCM comparison is a generated-host fixture, not an acoustic result.

Later diagnostics-reader/documentation updates leave firmware/C++ tests identical
to ee2f4fc; their own project-quality run is recorded after execution. The reader
now validates engineering counters/flags/null battery fields, rejects overflow/
excessive nesting, and keeps physical acceptance NOT_ESTABLISHED even if a
captured record falsely says physical_pass=true.

Final diagnostics-reader checkpoint `3316ff55d83511158287a02ada794164c2e98f55`
is pushed. [Project quality 37003778650](https://github.com/Hustlenix/Nightwave/actions/runs/37003778650)
succeeded: validator, engineering/diagnostic parser self-tests, 10/10 Release
and 10/10 ASAN/leak suites. `git diff ee2f4fc 3316ff5 -- firmware tests` is empty,
so the successful ee2f4fc ESP32-S3 build applies to identical firmware/C++ sources.
This subsequent evidence-ledger-only commit changes no software source.

## Runtime checkpoint and finished-device continuation

Verified on 2026-10-03 for published source `8bb9232c2c0647568259bf5ba04034ea728a4218`:

- [ESP32-S3 firmware](https://github.com/Hustlenix/Nightwave/actions/runs/37021176284): success.
- [Project quality](https://github.com/Hustlenix/Nightwave/actions/runs/37021176476): success, 11/11 Release and 11/11 ASAN/leak suites, nine synthetic shipping-inventory tests and project/calculation checks.
- Includes the sampled runtime recorder and boot-lifetime counters. Synthetic
  playback windows are not physical battery runtime; unknown power keeps battery
  evidence unestablished.

The 2026-10-03 continuation adds a separate finished-device evidence inventory and
malformed-PCM Bluetooth fail-closed regression. Null/empty/oversized/mismatched
blocks must fault, disconnect once, invalidate the epoch and request a stop; no
invalid block reaches the backend. Targeted strict optimized and ASAN/leak HAL
tests passed in WSL. Full Release/ASAN and firmware CI for this changed source
must be recorded separately after execution. No real radio/backend is enabled.

Selected-product continuation records the builder's BD-15 Waveshare 24382 and
BD-16 TCA9535PWR choices. New display geometry/tile and input-expander adapter
tests pass targeted strict Release and ASAN with leak detection in WSL.
All 27 Python tests (9 funding, 12 Trial inventory, 6 power arithmetic) and the
project validator pass locally. The new source requires 13/13 full C++ suites
and its own ESP32-S3 CI build; the pending run must not be labelled successful.

Published engineering source `a7edc5f215600a4436387c0fcfee70ace1dda816` has
passed [Project quality 37126760412](https://github.com/Hustlenix/Nightwave/actions/runs/37126760412):
**13/13 Release, 13/13 ASAN with leak detection**, all 27 Python tests (9 funding,
12 finished-device inventory, 6 selected-product power), validator and engineering
calculations. CI logs were read on 2026-10-03, not inferred from queued status.
This includes 10,000-track artists/albums/filtered pages, corrupt/legacy cache,
group/low-memory fallback, stale resume, settings reload, malformed BT PCM,
selected-display geometry and actual ESP-IDF input adapter against host fakes.
[ESP32-S3 firmware 37126760414](https://github.com/Hustlenix/Nightwave/actions/runs/37126760414)
also completed successfully for that exact source, including compilation of the
new input adapter. No host/CI
result establishes physical radio/display/SD, battery runtime, CAD fit or authorship.

Follow-up inventory verification found a stale selection-label allowlist: it
recognized BD-14 but not actual BD-15/16 or retained-S3 labels. The checker now
accepts those explicit labels without accepting unknown decisions or treating
selection as completed pricing/review. A tenth funding regression preserves
missing-price/final-total blockers. All 28 Python tests pass locally.

Final verified software source `cb3db92af2a889a90981650fe004e3e03244d0a7`:

- [Project quality 37127240521](https://github.com/Hustlenix/Nightwave/actions/runs/37127240521): success; 13/13 Release, 13/13 ASAN/leak, 10 funding +12 Trial +6 power Python tests, project validator and calculations.
- [ESP32-S3 firmware 37127240508](https://github.com/Hustlenix/Nightwave/actions/runs/37127240508): success for that exact commit.
- Firmware/C++ sources remain identical to a7edc5f; the follow-up changes only the funding checker, its Python regression and documentation. This final ledger follow-up changes documentation only, not software/config/BOM/tests.
- Actual funding inventory remains BLOCKED with 34 findings and no final total. Finished-device inventory remains BLOCKED with 41 findings, runtime null and physical_pass=false. No fabricated evidence was added to make either inventory green.

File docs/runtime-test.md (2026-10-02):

# Continuous runtime recording

The Trial says "a full night" without a numeric duration. Nightwave's internal
acceptance target is at least eight continuous hours, not a quoted Pixl minimum.
No physical runtime has been measured. This recorder does not award a pass.

## Software operation

Once supported local audio is playing at nonzero volume, use:

```text
runtime start
runtime status
runtime stop
```

`runtime stop` stops the recorder, not the music. Repeated start is refused while
a recording is active. Start/end/status and minute summaries emit bounded
`nightwave_runtime` JSON. Observation runs about once per second from the UI
owner, outside the audio task. No SD writes, NVS wear or heap allocation are added.

The engine supplies boot-lifetime accepted-media, error and underrun counters,
which survive track/seek changes. Accepted frames exclude starvation silence;
the frame counter wraps modulo 32 bits and observations handle that wrap.
This measures software acceptance by I2S, not sound leaving the speaker.

- `elapsed_ms`: wall time since the explicit start in this boot.
- `observed_play_ms`: sampled intervals with active, unpaused, nonzero-volume
  playback, stable route/volume/rate, sufficient accepted-frame progress and no
  newly observed fault. DMA lead allows up to 4096 frames of scheduling variation.
- `battery_play_ms`: those intervals additionally have fresh, plausible battery
  telemetry from a separately qualified power adapter and an acoustically verified
  route. The current `UnavailablePower`/untested bench integration gives **zero**.
- Gaps over two seconds, pauses/stalls/faults and configuration changes remain
  visible. Backwards time terminates recording. Duplicate timestamps add no time.

Every report retains `physical_pass:false` and `human_review_required:true`,
including the synthetic eight-hour regression fixture. A scheduler observation
cannot independently prove uninterrupted audible playback, calibrated voltage,
source authenticity, battery capacity or measured runtime. Short between-sample
events can be missed; retain external observations and original device logs.
The eight-hour test in CI is a rapidly simulated timeline, not an eight-hour run.

## Later physical protocol — not executed

First complete and review the exact protected battery, charger, source-current,
regulator, fuel-gauge and shutdown design. Do not connect a cell to the provisional
USB-only bench wiring. Follow the reviewed production power/bring-up procedure.

For the full-night profile, record the actual board/firmware hash, battery model
and capacity, full-charge conditions, speaker/load, fixed volume, same-rate local
playlist/repeat mode, display timeout/backlight, ambient conditions and logger.
The speaker route must work without any phone/app/network or Bluetooth receiver.
Use a separately reviewed logging setup that does not power or charge the device;
USB-powered playback is not battery-runtime evidence.

Capture actual start/stop times externally, real periodic voltage/SOC readings,
fault/underrun logs and whether audio continues. Run to the reviewed controlled
cutoff; never defeat battery protection or discharge beyond reviewed limits.
Stop for abnormal heat, unstable rails, protection activation or playback faults.
If power loss prevents a final report, the last minute record is only a lower
bound, not an invented stop time. Record shutdown externally.

Return the raw logs, exact conditions, real readings and video/time evidence.
State the achieved runtime precisely. If it misses eight hours, keep the failure,
identify the load/design cause and repeat after an actual revision.

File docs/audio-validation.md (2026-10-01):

# Audio validation and Phase 4 entry gate

Audit date: 2026-09-30.

Superseded execution gate, 2026-10-01: the funding-readiness request allows
digital development before physical validation. Historical missing-evidence
results below still apply, but no longer block software implementation. See
`pixl-funding-readiness.md`. No physical result has been supplied.

## Historical 2026-09-30 result (superseded for digital execution)

At this historical checkpoint, **Phase 4 had not started.** The prior request required physical
Phase 3 evidence before entry. The repository contains no returned device logs,
build photos, or measured audio results. Both existing measurement CSVs contain
headers only. Firmware and project-quality CI passed for `a66576a`; this establishes
build/host-test health, not physical playback.

| Entry evidence | Verified result |
|---|---|
| Exact ESP32-S3 board and connected audio hardware | Not provided |
| Device boots; serial console responds | Not physically verified |
| Real SD mounts and files enumerate | Not physically verified |
| I2S tone reaches the speaker | Not physically verified |
| Supported WAV plays on that speaker | Not physically verified |
| MP3 physical playback | Not physically verified; digital integration now implemented |
| Power source | USB/bench power is specified; actual source not provided |
| 30-minute / two-hour stability | Not run |

## Phase 3 preflight repairs

Repair commit: `ce4816965049b92f5cea02e8bdfb664f8803ce6f`.
Both [Firmware CI](https://github.com/Hustlenix/Nightwave/actions/runs/36750836556)
and [Project quality CI](https://github.com/Hustlenix/Nightwave/actions/runs/36750836808)
passed for that commit. Project quality ran the portable host-test executable
successfully. These checks do not exercise FreeRTOS worker lifetimes on a device.

Source inspection before the bench handoff found prerequisite defects:

- A 4096-byte automatic read array occupied a task with a 4096-byte stack.
  The array now belongs to the player object, leaving stack space for FatFS,
  logging, and calls. The workers report minimum free stack on exit; actual
  stack adequacy still needs device measurement.
- Workers could execute before both task creations succeeded. Both now wait
  for a notification before touching track resources, so creation rollback
  can safely close the file and destroy I2S.
- Audio errors could leave the storage worker stuck on a full ring. The audio
  worker now cancels the producer and waits for producer cleanup before
  publishing idle. `stop` refuses to tear down live worker resources if its
  one-second wait expires; a new track remains refused while cleanup is pending.
- The defaults specified 16 MB flash despite the documented N8R8 development
  board. Defaults now specify 8 MB flash. Exact hardware must still be confirmed.
- Short WAV reads now produce an explicit error and cancel playback instead
  of being mistaken for successful EOF.

These repairs do not establish production engine reliability. There is still
no MP3 decoder, compressed byte stage, pause/resume implementation, or track
controller in the device build. The standalone host state-machine tests do not
prove those playback features.

ESP-IDF documents task stack sizing/watermarks in bytes in its
[RAM usage guide](https://docs.espressif.com/projects/esp-idf/en/stable/esp32s3/api-guides/performance/ram-usage.html).

## HUMAN GATE: first returned Phase 3 evidence

### Objective

Verify actual board boot, serial diagnostics, SD access, tone, and WAV output.
Provide existing results first if these tests have already been performed.

### Wiring/configuration

Use the exact confirmed board and breakouts from `hardware/prototype-wiring.csv`.
The documented baseline is ESP32-S3-DevKitC-1-N8R8, SparkFun BOB-00544 raw SD,
Adafruit MAX98357A 3006, and an 8 ohm speaker. Confirm received labels/revisions
before wiring. Use USB/bench power without a lithium battery. The five external
SD pull-ups and 3.3 V SD power are required. Both speaker leads connect only to
the amplifier's BTL outputs.

### Firmware commit/build

Use the commit containing this preflight repair and its passing Firmware CI run.
The startup `project=nightwave version=...` line records the built Git revision.
Build with ESP-IDF 6.1, target `esp32s3`, and the 8 MB flash defaults for N8R8.
Do not use an old generated sdkconfig retaining the 16 MB setting: verify
`Flash size = 8 MB` in menuconfig before flashing the N8R8 baseline.

### Procedure

Follow `docs/phase3-firmware-bringup.md` in order. First boot the DevKitC alone
and save the complete serial output. Confirm the board label and observed
flash/PSRAM capacities. After the documented unpowered wiring checks, copy
the generated WAV fixtures to a FAT32 card and run:

```text
board
sd
bench /sdcard/02_left_right_stereo_44100.wav
tone speaker 440
wav speaker /sdcard/02_left_right_stereo_44100.wav
status
stop
```

Wait for each tone/file to finish before the next playback command. Capture
button presses too if the buttons are already connected. Leave headphones
disconnected for this first speaker test.

### Expected result

`BOOT OK`, correct board diagnostics, file enumeration, an error-free SD
benchmark, a quiet two-second tone, WAV playback, and a responsive console.
The speaker mixes stereo; it cannot prove headphone left/right separation.
No task-stack panic, reset loop, or unexplained underrun is acceptable evidence
of a successful first pass.

### What to measure

Record actual card identity, benchmark throughput/worst read latency/errors,
WAV underruns/errors, and worker stack watermarks. Return any observed current
only with its supply conditions and instrument. No measurement rows are filled
until the corresponding device log or instrument result exists.

### STOP if

The device resets unexpectedly, the stack checker panics, wiring disagrees with
the exact module, the rail is shorted, a module heats unexpectedly, or audio
produces severe pops. Power off before rewiring or removing the SD card.

### Return to Work

Exact board/audio-module labels, clear front/back photos, SD make/model/capacity,
power-source details, firmware version, complete serial log, and actual audible
observations. Failed logs are useful too. Once real WAV playback is understood,
finish the MP3 prerequisite; then evaluate Phase 4 entry again.

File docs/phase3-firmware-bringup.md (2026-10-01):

# Phase 3 firmware bring-up

This is the exact current digital handoff. The firmware builds for ESP32-S3 in CI, but no physical command below has been run on the user's hardware yet.

See `docs/audio-validation.md` for the Phase 4 entry audit and prerequisite
repairs. Use the repaired build for the first WAV bench test. On the N8R8
baseline, verify 8 MB flash in menuconfig if reusing an older sdkconfig.

## Build and flash

Use ESP-IDF 6.1 and the USB-to-UART connector on the confirmed `ESP32-S3-DevKitC-1-N8R8`:

```powershell
cd firmware
idf.py set-target esp32s3
idf.py build
idf.py -p COM_PORT flash monitor
```

Replace `COM_PORT` with the observed port. Do not connect a battery. Start with every peripheral disconnected and power only from USB or a current-limited 5 V bench source.

## Expected DevKitC-only log

The first valid boot contains lines equivalent to:

```text
diagnostics: BOOT OK
diagnostics: project=nightwave version=... idf=v6.1...
diagnostics: target=ESP32-S3 revision=... cores=2 flash=... reset_reason=...
diagnostics: heap_free=... heap_min=... psram=...
buttons: BUTTONS READY ...
storage: SD mount failed: ...
nightwave: SD unavailable; console and button diagnostics remain active
nightwave>
```

Return the complete boot log, not just `BOOT OK`. A mount failure is expected when SD is not connected. Stop if there is a brownout/reset loop, unexpected heat, smoke, or a rail fault.

## Button test

With power off, wire each normally-open button from its GPIO to ground according to `hardware/prototype-wiring.csv`. Reapply power, press and release every button ten times, and capture lines such as:

```text
buttons: BUTTON PLAY_PAUSE PRESSED t_ms=...
buttons: BUTTON PLAY_PAUSE RELEASED t_ms=...
```

Expected mapping is Previous GPIO1, Play/Pause GPIO2, Next GPIO4, Volume Down GPIO10, Volume Up GPIO15. The software debounce is an unmeasured 25 ms starting value; return any missed/double events rather than tuning by guess.

## SD test

Power off before attaching or removing the raw SD breakout. Follow `docs/prototype-wiring.md`, including all five required 10 kohm pull-ups and 3.3 V-only power. Copy `.generated/test-media/*.wav` to the FAT32 card root.

At the prompt:

```text
sd
bench /sdcard/02_left_right_stereo_44100.wav
status
```

Expected evidence includes card identity/capacity from ESP-IDF, the enumerated audio files, and one line containing `SD BENCH bytes=... elapsed_ms=... avg_kib_s=... worst_read_us=... errors=0`. Repeat across three cold boots, then perform the five-minute read procedure in `docs/prototype-bringup.md` before calling SD stable.

## I2S tone test

The boot state keeps GPIO17 and GPIO18 low and does not initialize I2S. Do not use `tone line` until the exact line/headphone module and enable polarity are confirmed. For the documented MAX98357A speaker breakout, power off, follow the wiring table, ensure neither BTL speaker lead is grounded, and start with a current-limited 5 V supply.

Then run:

```text
tone speaker 440
```

The firmware configures 44.1 kHz, 16-bit stereo I2S with 8 x 256 DMA frames, writes zero PCM, enables the speaker path, generates a two-second ramped tone at 1,200 counts peak (about 3.7% full scale), writes silence, disables the amp, and tears down I2S. Return the log plus a description/video of actual behavior. Stop on severe pops, reset, excessive current, or heat.

## WAV test

After SD and tone pass:

```text
wav speaker /sdcard/01_silence_stereo_44100.wav
status
wav speaker /sdcard/02_left_right_stereo_44100.wav
status
```

The parser accepts RIFF/WAVE PCM, 16-bit mono/stereo, and 22.05/32/44.1/48 kHz; it skips bounded unknown chunks and rejects inconsistent/truncated files. Playback uses a storage task, a 16,384-frame PCM ring, an audio task, and I2S DMA. Any `AUDIO UNDERRUN` line is a test failure to investigate, not a message to hide.

Use `stop` to request cancellation. Cleanup mutes before waiting for the producer,
then stops I2S after the producer closes its file. If `STOP PENDING` appears, cleanup has not finished;
the player retains live resources and refuses another track. Capture the log
and retry `status`/`stop`; do not remove the card or start a new hardware test.
Card removal recovery has not been implemented or tested.

## Evidence to return

- clear photos of both sides of the DevKitC and every connected module;
- board/module labels and revisions;
- microSD make, model, capacity, and FAT format;
- power source/current limit and any observed current;
- complete boot, button, SD benchmark, tone, WAV, and status logs;
- whether each physical sound was silent/correct/wrong, with no inferred measurements;
- exact wired headphone model and impedance before headphone testing.

## Phase 3 software repairs, 2026-10-01

Repair commit `4e19872` passed the [ESP32-S3 build](https://github.com/Hustlenix/Nightwave/actions/runs/36851574808)
and [project-quality checks](https://github.com/Hustlenix/Nightwave/actions/runs/36851574841),
including both test executables (2/2). Use this repair or a later verified build
for the bench procedure above.

- WAV parsing respects the declared RIFF extent, validates odd-chunk padding,
  rejects duplicate fmt/data chunks, rejects incomplete PCM frames, and checks
  full-width channel/bit-depth fields before narrowing. Data before fmt remains
  supported; bytes outside the RIFF container are ignored.
- I2S preloads all 8 x 256 stereo frames with zero PCM before enabling clocks.
  Setup fails explicitly on driver errors or incomplete preload. DMA buffers
  automatically clear after sending, preventing repeated stale PCM on starvation.
- The stereo output adapter rejects null/empty/overflowing PCM blocks and
  sample-rate/channel mismatches. Driver write timeouts use milliseconds, as
  required by the ESP-IDF API, independently of the RTOS tick rate.
- Natural WAV EOF flushes a complete DMA span of zeros before muting to avoid
  discarding the queued tail. Cancel/error mutes before waiting for producer
  cleanup. Tone generation rejects non-finite/out-of-range frequencies and
  reports silence/drain failures.
- Portable regression tests cover malformed WAV boundaries and PCM contracts.
  A separate test executable compiles the actual I2S adapter against fake driver
  calls, exercising startup order, failure cleanup, partial writes, timeout,
  drain size, and mutually exclusive output enables. These mocks do not simulate
  DMA timing, FreeRTOS scheduling, electrical behavior, or sound quality.

Reference: [Espressif I2S API](https://docs.espressif.com/projects/esp-idf/en/latest/esp32s3/api-reference/peripherals/i2s.html).
Physical verification remains outstanding; MP3 digital integration was added on
2026-10-01 (see software-validation.md). This repair is not
a claim that Phase 3 has met its hardware exit criteria.

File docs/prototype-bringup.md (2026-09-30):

# Phase 2 bring-up checklist

This checklist stops at every point where power, soldering, listening, or measurement requires the human builder. There is no battery in this phase.

## Equipment

- current-limited 5 V bench source or known 2 A USB source;
- digital multimeter with continuity and DC-current capability;
- computer with data-capable USB cable and serial monitor;
- soldering equipment for breakout headers;
- 8–32 GB microSDHC card;
- powered speakers or high-impedance input for the DAC-only stage;
- 32 Ω or higher wired headphones for the EVM stage;
- 8 Ω, 2 W speaker;
- camera for clear module-label and wiring photographs.

## 0 — Unpowered inspection

- [ ] Photograph both sides of every module and record exact labels/revisions.
- [ ] Confirm the board says `ESP32-S3-DevKitC-1-N8R8` and record v1.0/v1.1.
- [ ] Confirm every ground rail is continuous.
- [ ] Confirm 3.3 V and 5 V rails are not shorted to ground or each other.
- [ ] Confirm SD pull-ups measure approximately 10 kΩ to 3.3 V.
- [ ] Confirm no speaker terminal is connected to ground.
- [ ] Check that all GPIO matches `hardware/prototype-wiring.csv`.

Stop on any short, unknown label, damaged cell, or disagreement with the wiring table.

## 1 — DevKitC only

- [ ] Disconnect every peripheral.
- [ ] Power through the USB-to-UART connector.
- [ ] Capture boot log, chip revision, flash size, PSRAM size, reset reason, and firmware commit.
- [ ] Confirm GPIO38 RGB LED behavior for the recorded board revision.

Pass: repeated boots produce stable logs with no brownout/reset loop.

## 2 — Inputs and OLED

- [ ] Power off, connect OLED and buttons, then power on.
- [ ] Run an I2C scan and record the OLED address.
- [ ] Exercise every button at least ten times.
- [ ] Record bounce duration and choose debounce timing from observations.
- [ ] Display solid/off/checkerboard screens and note current variation.

Pass: every button maps correctly and the OLED updates without resets.

## 3 — microSD

- [ ] Power off and connect the raw 3.3 V socket and all five pull-ups.
- [ ] Insert a freshly FAT32-formatted test card before power-on.
- [ ] Mount, enumerate, and stream-read a large file.
- [ ] Record card make/model, capacity, mount time, sequential throughput, and read errors.
- [ ] Power down before removing the card until removal recovery firmware exists.

Pass: three cold boots and a five-minute sequential read complete without error.

## 4 — PCM5102 line output

- [ ] Connect BCLK/WSEL/DIN and DAC power with `MUTE` asserted.
- [ ] Connect only powered speakers, an audio analyzer, or another input rated for line level.
- [ ] Start zero PCM, configure 44.1 kHz/16-bit stereo I2S, then unmute.
- [ ] Play silence, left/right identification, dual-tone, and sweep files.
- [ ] Stop clocks only after ramping digital samples to zero and muting.

Pass: channel identity is correct, silence has no obvious severe noise, and repeated start/stop does not create severe pops.

## 5 — TPA6132A2 headphones

- [ ] Verify EVM VDD polarity, JP1/JP2, and 0 dB gain before power.
- [ ] Keep DAC muted and volume zero while inserting headphones.
- [ ] Unmute and increase volume one step at a time.
- [ ] Verify left/right identity at a safe listening level.
- [ ] Repeat mute/unmute and track-rate changes while noting clicks or imbalance.

Pass: stereo channels are correct, volume control is predictable, and no dangerous transient or thermal fault occurs.

## 6 — MAX98357A speaker

- [ ] Use a separate current-limited 5 V source for the amplifier with common ground.
- [ ] Verify speaker impedance and that neither BTL output is grounded.
- [ ] Hold `SD` low; start I2S with zero samples; then enable.
- [ ] Raise volume gradually while recording supply current.
- [ ] Run ten minutes at the intended prototype limit and inspect temperature, resets, rattles, and clipping.

Pass: mono mix is intelligible and stable, and no reset/overcurrent/thermal problem appears.

## 7 — Combined stress

- [ ] Stream from SD while updating OLED and polling buttons.
- [ ] Alternate DAC/headphone and speaker enable sequences.
- [ ] Record underruns, minimum free heap, queue depth, SD latency, and reset reason.
- [ ] Run at least 60 minutes before calling the prototype stable.

Pass: zero unexplained resets, zero silent errors, and every underrun is counted and visible.
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

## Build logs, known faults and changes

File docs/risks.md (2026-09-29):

# Risk Register

Status values remain `OPEN` until evidence closes them.

| Risk | Probability | Impact | Evidence | Mitigation | Verification | Status |
|---|---|---|---|---|---|---|
| ESP32/SD peak current collapses 3.3 V | Medium | High | ESP32 radio-class peaks and SD inrush exceed quiet averages even with radios disabled | 2 A-class buck-boost, local bulk/decoupling, radios disabled in product | scope 3V3 at boot, scan, skip, max decode/UI load | OPEN |
| TPS63802 transient or layout instability | Medium | High | fast converter with small inductor/exposed pad is layout-sensitive | copy datasheet layout/current loops; validated L/C; margin | load-step and ripple measurement across battery range | OPEN |
| switching regulator noise reaches headphones | Medium | High | buck-boost switching can couple by rail/ground/field | zoning, return-path control, forced PWM experiment, local filtering | noise spectrum/listening at silence and load transitions | OPEN |
| charger overheats | Medium | High | linear dissipation rises with 5 V input, low battery, playback load | conservative charge current, thermal copper, NTC/thermal regulation | temperature during worst charge + playback | OPEN |
| charge-while-play starves load or adds noise | Medium | High | input limit shared by charger/system | power-path config, charge-current reduction, UI status | current/rail/audio test while plugging/unplugging USB | OPEN |
| battery lacks protection or polarity differs | Low–Medium | Critical | JST-PH polarity is not universal | protected named pack; keyed/marked connector; polarity DMM gate | visual + polarity check before connection | OPEN |
| battery capacity misses full-night target | Medium | High | no current measurements exist | defer capacity; measure modes; apply derating | continuous declared runtime test | OPEN |
| headphone level unsafe or clips | Medium | High | 2.1 Vrms DAC and gain selection can exceed comfortable level | conservative digital max/gain; ramp; optional limiter | resistive-load scope + listening at staged volume | OPEN |
| headphone load incompatibility | Low–Medium | High | real headphones vary 16–300 Ω and cable behavior | TPA6132A2 rated path; test common loads | distortion/level/thermal across loads | OPEN |
| DAC/headphone gain or DC/pop issue | Medium | High | independent startup/shutdown sequencing | enable/mute state machine and ramps | hot-plug/start/stop scope/listening | OPEN |
| Class-D output tied to ground | Low | Critical | BTL outputs are both active | keyed 2-wire connector, schematic labels, docs | continuity review before power | OPEN |
| Class-D EMI couples into DAC/SD | Medium | High | high dV/dt speaker loop | tight differential route, zoning, edge control, optional filter pads | EMI/noise/SD-error stress at high output | OPEN |
| I2S fanout edge/ringing | Low–Medium | Medium | one ESP output drives DAC + speaker amp | short routes, source series-resistor options | logic-analyzer/scope edges and error-free playback | OPEN |
| SD latency causes underruns | Medium | High | cards and fragmentation vary | two-stage buffers, chunk prefetch, measurements | worst-latency + two-hour stress | OPEN |
| SD removal crashes or deadlocks | Medium | High | file/block driver can fail mid-read | card detect, generation cancel, bounded timeouts | repeated removal at read/decode/idle states | OPEN |
| MP3 decode misses real-time deadline | Low–Medium | High | library not yet benchmarked on exact build | fixed-point Helix candidate, dedicated task, telemetry | representative bitrate/frame timing | OPEN |
| corrupt MP3 causes infinite resync | Medium | Medium | sync bytes can appear in ID3/corrupt data | explicit ID3 skip and bounded resync budget | fuzz/truncated corpus tests | OPEN |
| sample-rate transition pops or misclocks | Medium | Medium | I2S needs reconfiguration | drain/mute/reconfigure/prefill/ramp | alternating 44.1/48 kHz stress | OPEN |
| PCM stereo-to-mono overflow | Low | High | 16-bit L+R can overflow | 32-bit sum, divide, saturate, tests | max-amplitude vector tests | OPEN |
| analog ground/return mistakes add hum | Medium | High | mixed signal + USB + headphone cables | continuous planes, controlled current paths, no blind splits | silence/noise test battery and USB-powered | OPEN |
| QFN/WSON/FC2QFN assembly defects | Medium | High | several exposed-pad fine-pitch parts | fab assembly capability, stencil, inspection/test points | X-ray/visual + electrical bring-up | OPEN |
| wrong footprint/pin-1/orientation | Medium | Critical | connector and leadless drawings are easy to misread | manufacturer land patterns; independent cross-check | print/1:1 overlay and second-person review | OPEN |
| connector orientation blocks enclosure | Medium | High | USB/SD/jack are edge-critical | co-design PCB/CAD, STEP models, datum table | assembled CAD/interference and physical fit | OPEN |
| speaker acoustic cavity rattles/muffles | High | Medium | bare speaker specs do not predict enclosure response | gasket, rigid mount, cavity/grille iterations | sweeps/listening/fit prototype | OPEN |
| enclosure tolerance damages battery | Low–Medium | Critical | pouch cells must not be pinched/punctured | cradle clearance, no sharp bosses, serviceable retention | CAD section review + unpowered fit test | OPEN |
| OLED current/burn-in hurts runtime | Medium | Medium | content and on-time control OLED power | timeout/dim, limited static icons, power gate option | display current/on-time measurement | OPEN |
| USB-C sink misconfiguration | Low–Medium | High | both CC pins need Rd; connector pin duplication easy | separate 5.1 kΩ Rd, exact footprint, ESD review | CC/VBUS test with flipped cables/sources | OPEN |
| component unavailable in purchase region | Medium | High | N16R8 and older MAX98357A listings showed supply constraints | backups, regional recheck, no lock before order | Phase 7 supplier/lead-time audit | OPEN |
| current BOM misses passives/mechanics | High | Medium | Phase 1 block-level BOM only | expand after reference schematics and CAD | schematic-BOM-PCB cross-check | OPEN |
| AI authorship violates Pixl rules | Medium | Critical | fully AI-generated hardware designs can be rejected | disclosure, human material review/authorship, second-person sanity check | documented human review before submission | OPEN |

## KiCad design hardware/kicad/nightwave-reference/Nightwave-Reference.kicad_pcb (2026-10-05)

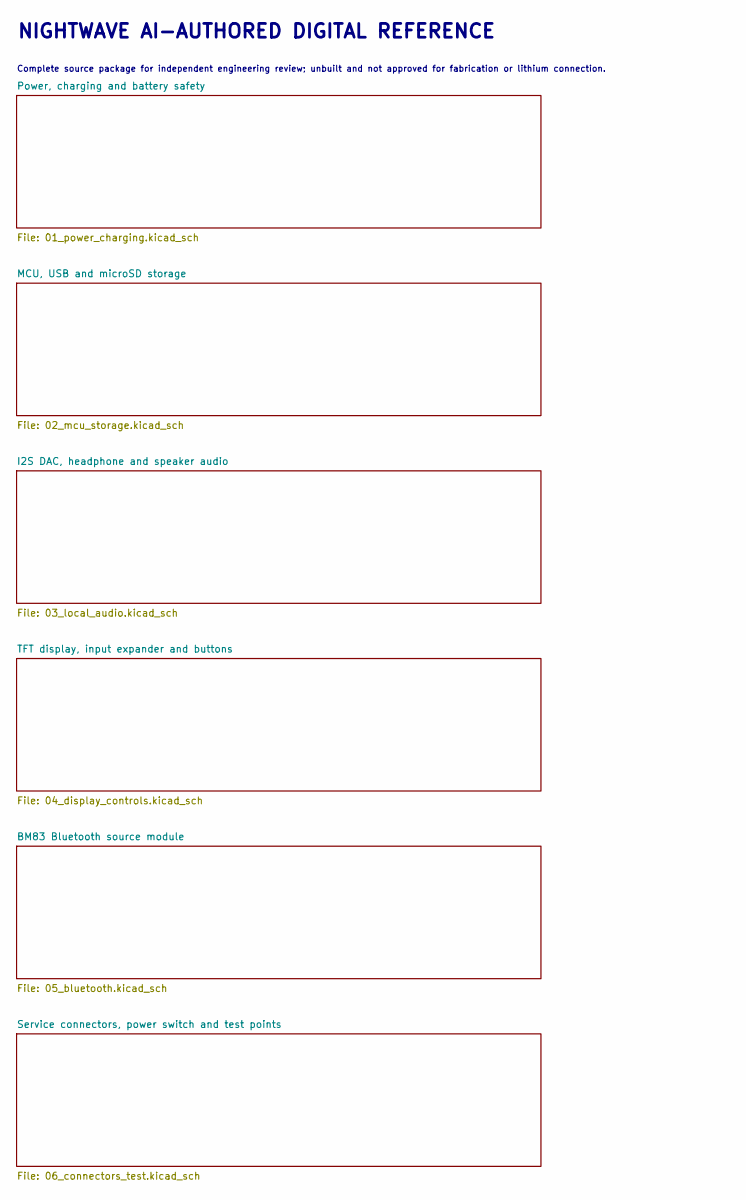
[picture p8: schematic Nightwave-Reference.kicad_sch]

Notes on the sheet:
NIGHTWAVE AI-AUTHORED DIGITAL REFERENCE
Complete source package for independent engineering review; unbuilt and not approved for fabrication or lithium connection.

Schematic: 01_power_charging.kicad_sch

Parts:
C1, C2, C7: 10u; C_0603_1608Metric
C3, C4, C5, C6: 22u; C_0603_1608Metric
C8: 4.7u; C_0603_1608Metric
C9: 47n/10V; C_0805_2012Metric
C10: 10u/25V; C_0805_2012Metric
C11, C13: 10u/10V; C_0805_2012Metric
C12, C14: 22u/10V; C_0805_2012Metric
C15: 100n/10V; C_0805_2012Metric
J1: USB4105-GF-A; USB_C_Receptacle_GCT_USB4105-xx-A_16P_TopMnt_Horizontal
J2: BATTERY_CONNECTOR; JST_PH_S2B-PH-K_1x02_P2.00mm_Horizontal
J3: EXTERNAL_10K_NTC; JST_PH_S2B-PH-K_1x02_P2.00mm_Horizontal
L1, L2: 0.47uH XFL4015-471MEC; Coilcraft_XFL4015
L3: 0.7uH XFL4015-701MEC; Coilcraft_XFL4015
R1, R2: 5.1k; R_0603_1608Metric
R3, R4: 4.7k; R_0603_1608Metric
R16: 511k; R_0603_1608Metric
R17, R19: 91k; R_0603_1608Metric
R18: 562k; R_0603_1608Metric
R20: 5.49k; R_0603_1608Metric
R21: 5.23k; R_0603_1608Metric
R22: 30.1k; R_0603_1608Metric
R23: 0; R_0603_1608Metric
U3: BQ25628ERYKR; TI_RYK0018A
U4: TPS22965DSGR; Texas_DSG0008A_WSON-8-1EP_2x2mm_P0.5mm_EP0.9x1.6mm_ThermalV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
U5, U6: TPS63802DLAR; TI_DLA0010A
U7: MAX17048G+T10; TDFN-8-1EP_2x2mm_P0.5mm_EP0.8x1.2mm

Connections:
+3V3: C5.1 (+3V3), C12.1 (+3V3), R3.2 (+3V3), R4.2 (+3V3), R16.1 (+3V3), U5.6 (VOUT); also elsewhere on the board
+3V3_A: C7.1 (+3V3_A); also elsewhere on the board
+3V6_BT: C6.1 (+3V6_BT), C14.1 (+3V6_BT), R18.1 (+3V6_BT), U6.6 (VOUT); also elsewhere on the board
BAT: C2.1 (BAT), C15.1 (BAT), J2.1, U3.8 (BAT), U7.2 (CELL), U7.3 (VDD); also elsewhere on the board
BTST: C9.1 (BTST), U3.1 (BTST)
CHASSIS: J1.SH (SHIELD), R23.1 (CHASSIS)
CHG_INT_N: U3.11 (INT); also elsewhere on the board
CHG_STAT: U3.10 (STAT); also elsewhere on the board
FB_3V3: R16.2 (FB_3V3), R17.1 (FB_3V3), U5.4 (FB)
FB_BT: R18.2 (FB_BT), R19.1 (FB_BT), U6.4 (FB)
FUEL_ALERT_N: U7.5 (ALRT); also elsewhere on the board
GND: C1.2 (GND), C2.2 (GND), C3.2 (GND), C4.2 (GND), C5.2 (GND), C6.2 (GND), C7.2 (GND), C8.2 (GND), C10.2 (GND), C11.2 (GND), C12.2 (GND), C13.2 (GND), C14.2 (GND), C15.2 (GND), J1.A1 (GND), J1.A12 (GND), J1.B1 (GND), J1.B12 (GND), J2.2, J3.2, R1.2 (GND), R2.2 (GND), R17.2 (GND), R19.2 (GND), R20.2 (GND), R22.2 (GND), R23.2 (GND), U3.14 (CE), U3.15 (GND), U4.5 (GND), U4.9 (EP), U5.2 (MODE), U5.3 (AGND), U5.8 (GND), U6.2 (MODE), U6.3 (AGND), U6.8 (GND), U7.1 (CTG), U7.4 (GND), U7.6 (QSTRT), U7.9 (EP); also elsewhere on the board
I2C_SCL: R4.1 (I2C_SCL), U3.13 (SCL), U7.7 (SCL); also elsewhere on the board
I2C_SDA: R3.1 (I2C_SDA), U3.12 (SDA), U7.8 (SDA); also elsewhere on the board
ILIM: R20.1 (ILIM), U3.4 (ILIM)
PGOOD_CHG: U3.3 (PG); also elsewhere on the board
PMID: C10.1 (PMID), U3.17 (PMID)
PWR_GOOD_3V3: U5.5 (PG); also elsewhere on the board
PWR_GOOD_BT: U6.5 (PG); also elsewhere on the board
PWR_SWITCH_ON: U4.3 (ON); also elsewhere on the board
REGN: C8.1 (REGN), U3.2 (REGN)
SW1_3V3: L1.1, U5.9 (L1)
SW1_BT: L2.1, U6.9 (L1)
SW2_3V3: L1.2, U5.7 (L2)
SW2_BT: L2.2, U6.7 (L2)
SW_CHG: C9.2 (SW_CHG), L3.1, U3.16 (SW)
SYS: C3.1 (SYS), L3.2, U3.9 (SYS), U4.1 (VIN), U4.2 (VIN), U4.4 (VBIAS); also elsewhere on the board
TS: J3.1, R21.2 (TS), R22.1 (TS), U3.6 (TS)
TS_BIAS: R21.1 (TS_BIAS), U3.5 (TS_BIAS)
USB_CC1: J1.A5 (CC1), R1.1 (USB_CC1)
USB_CC2: J1.B5 (CC2), R2.1 (USB_CC2)
USB_DM: J1.A7 (D-), J1.B7 (D-); also elsewhere on the board
USB_DP: J1.A6 (D+), J1.B6 (D+); also elsewhere on the board
VBUS5: C1.1 (VBUS5), J1.A4 (VBUS), J1.A9 (VBUS), J1.B4 (VBUS), J1.B9 (VBUS), U3.18 (VBUS); also elsewhere on the board
VSYS_SW: C4.1 (VSYS_SW), C11.1 (VSYS_SW), C13.1 (VSYS_SW), U4.7 (VOUT), U4.8 (VOUT), U5.1 (EN), U5.10 (VIN), U6.1 (EN), U6.10 (VIN); also elsewhere on the board

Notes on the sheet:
Power, charging and battery safety
AI-authored engineering reference. Verify pinout, support values, footprint orientation, lithium safety, RF keepout and assembly before fabrication.

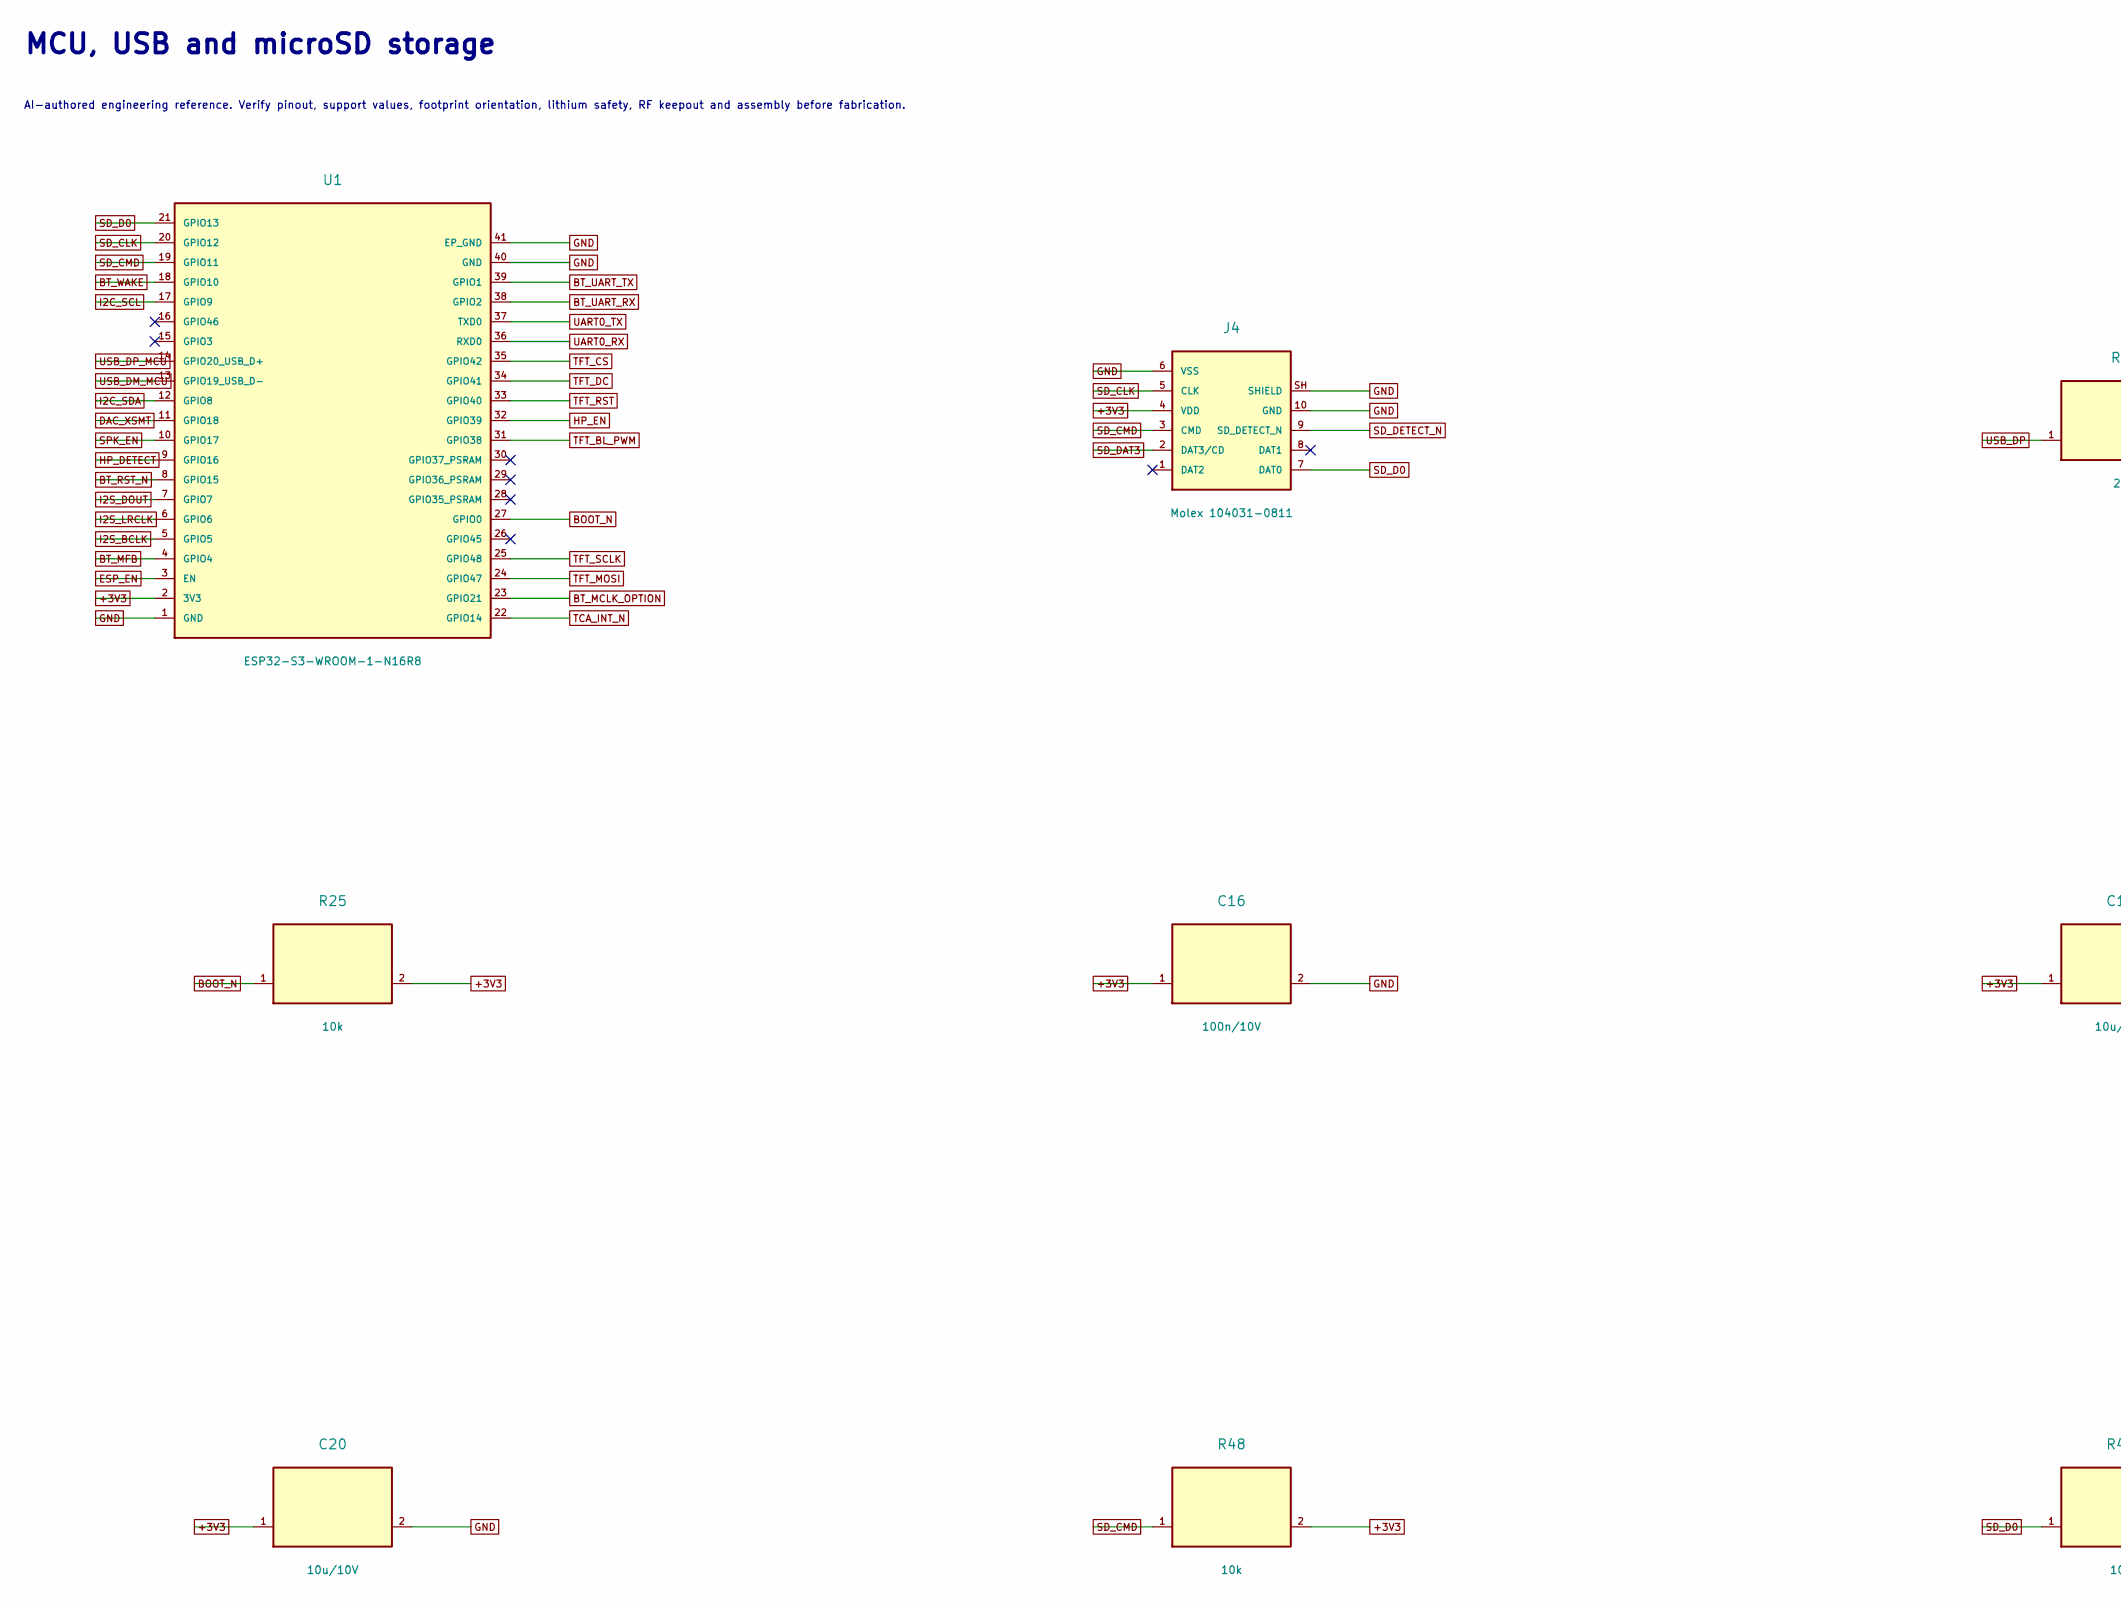
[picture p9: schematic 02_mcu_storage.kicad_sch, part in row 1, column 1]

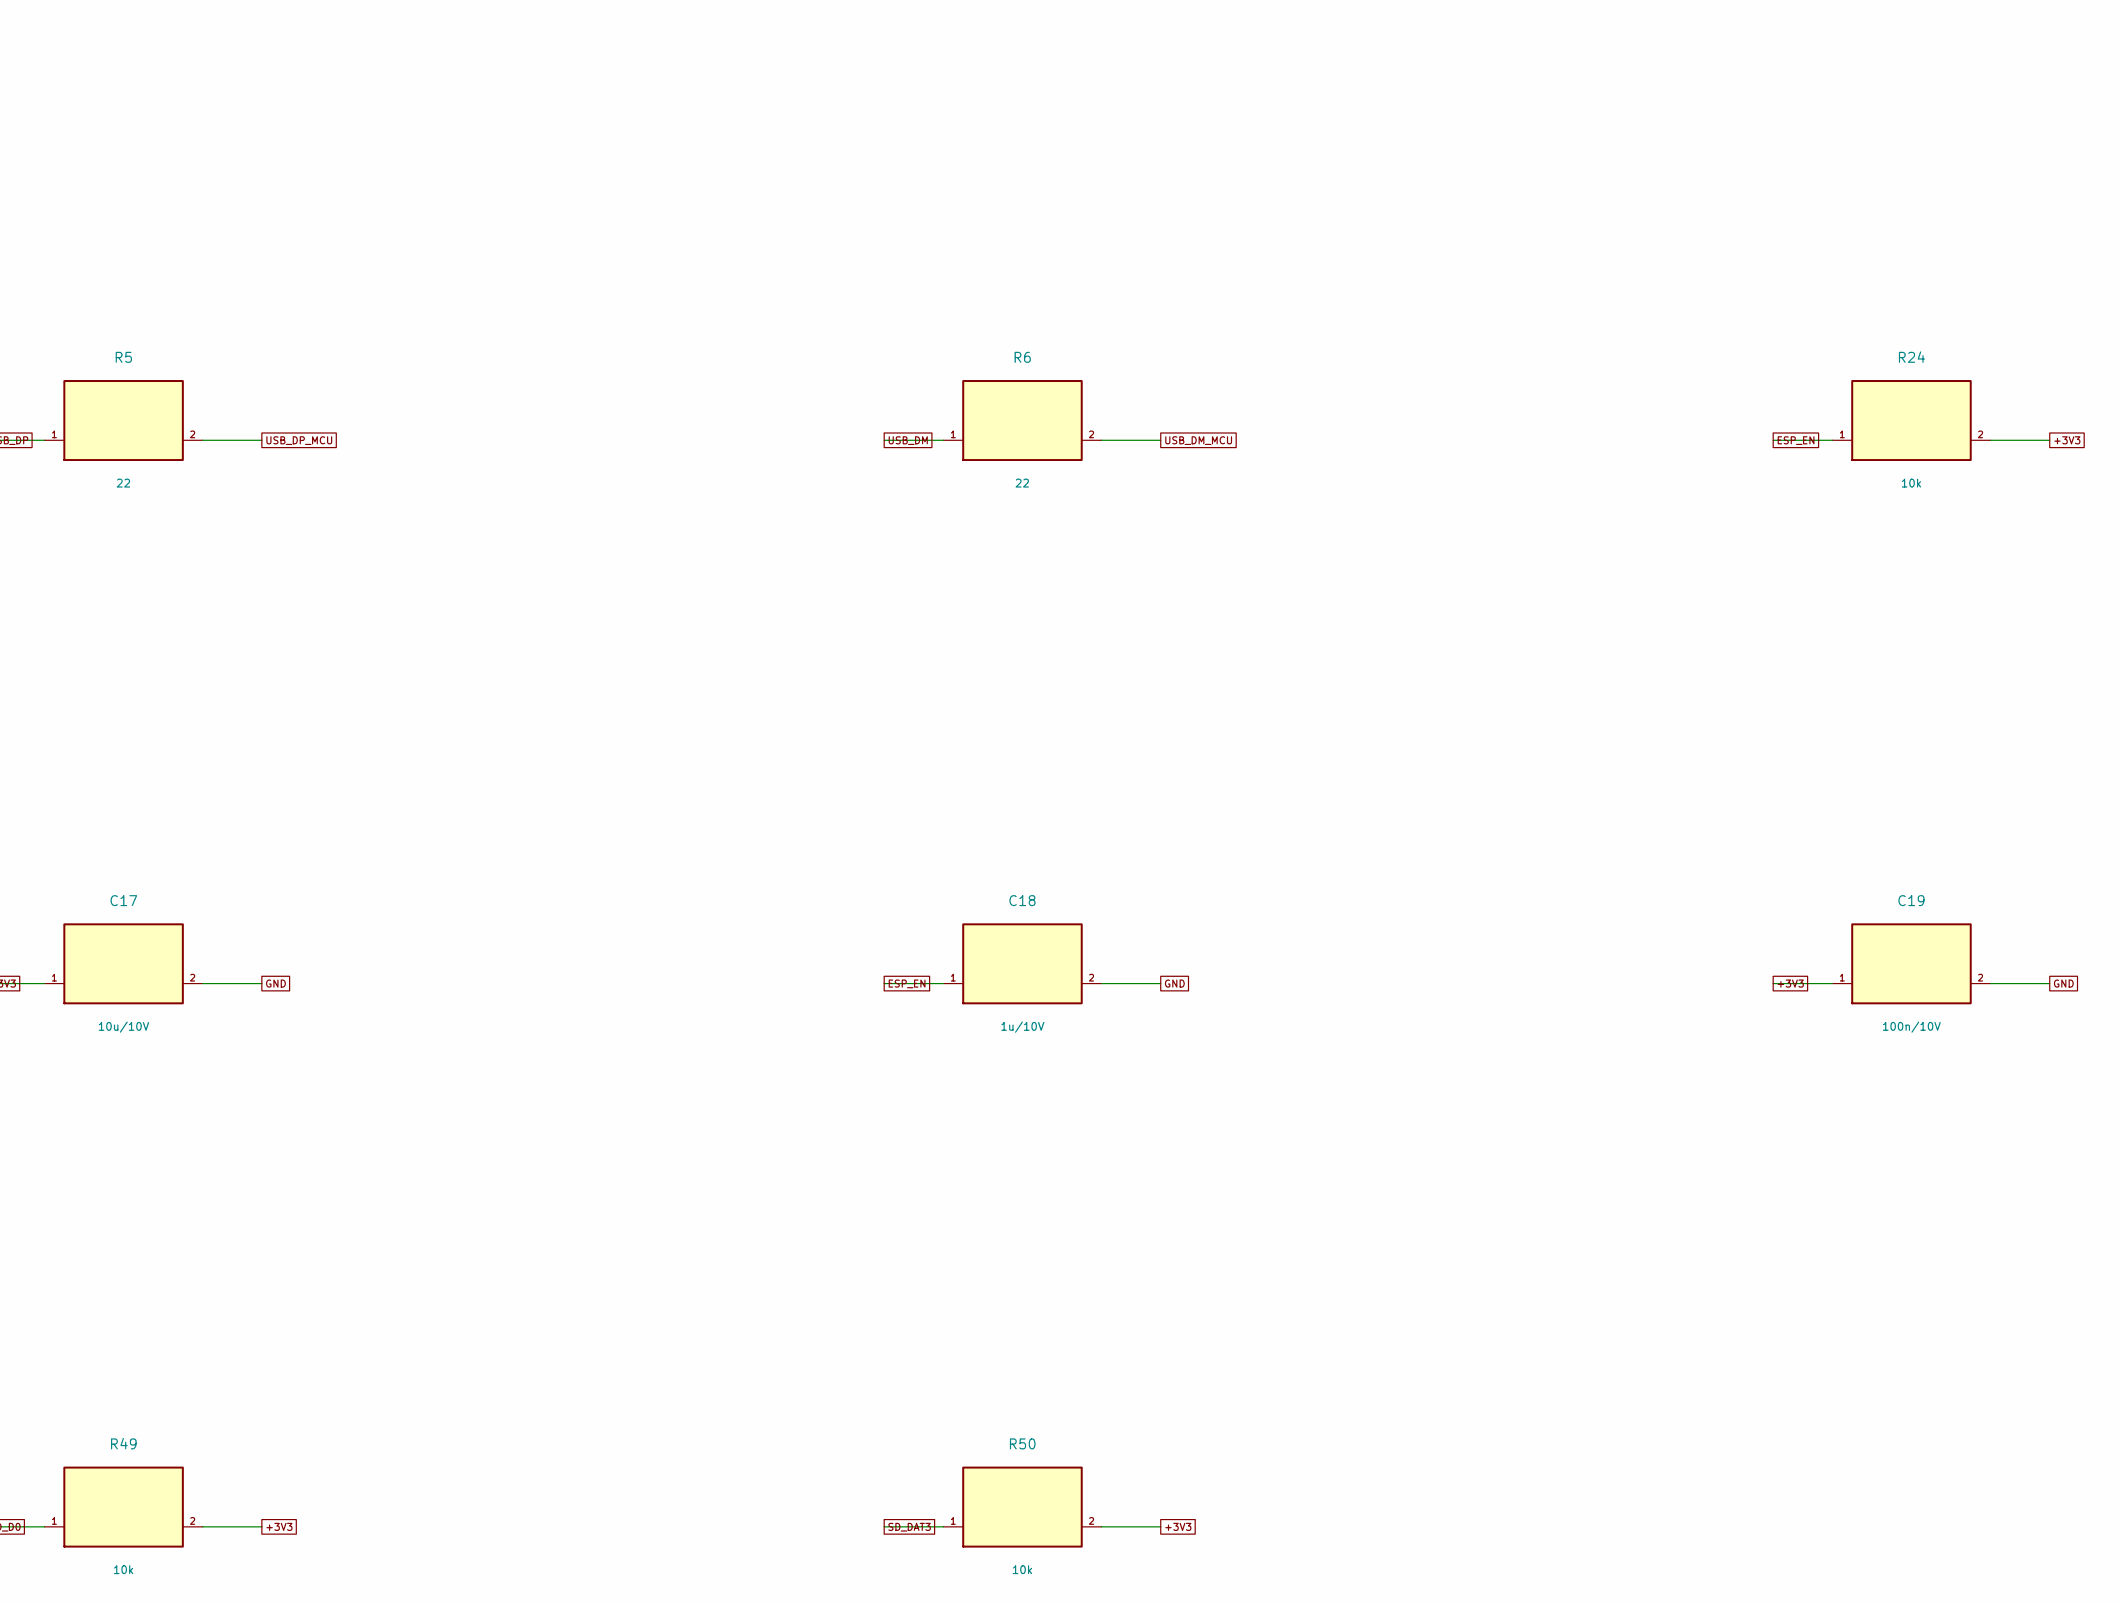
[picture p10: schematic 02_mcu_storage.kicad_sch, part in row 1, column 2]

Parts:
C16, C19: 100n/10V; C_0805_2012Metric
C17, C20: 10u/10V; C_0805_2012Metric
C18: 1u/10V; C_0805_2012Metric
J4: Molex 104031-0811; microSD_HC_Molex_104031-0811
R5, R6: 22; R_0603_1608Metric
R24, R25, R48, R49, R50: 10k; R_0603_1608Metric
U1: ESP32-S3-WROOM-1-N16R8; ESP32-S3-WROOM-1

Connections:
+3V3: C16.1 (+3V3), C17.1 (+3V3), C19.1 (+3V3), C20.1 (+3V3), J4.4 (VDD), R24.2 (+3V3), R25.2 (+3V3), R48.2 (+3V3), R49.2 (+3V3), R50.2 (+3V3), U1.2 (3V3); also elsewhere on the board
BOOT_N: R25.1 (BOOT_N), U1.27 (GPIO0); also elsewhere on the board
BT_MCLK_OPTION: U1.23 (GPIO21); also elsewhere on the board
BT_MFB: U1.4 (GPIO4); also elsewhere on the board
BT_RST_N: U1.8 (GPIO15); also elsewhere on the board
BT_UART_RX: U1.38 (GPIO2); also elsewhere on the board
BT_UART_TX: U1.39 (GPIO1); also elsewhere on the board
BT_WAKE: U1.18 (GPIO10); also elsewhere on the board
DAC_XSMT: U1.11 (GPIO18); also elsewhere on the board
ESP_EN: C18.1 (ESP_EN), R24.1 (ESP_EN), U1.3 (EN); also elsewhere on the board
GND: C16.2 (GND), C17.2 (GND), C18.2 (GND), C19.2 (GND), C20.2 (GND), J4.6 (VSS), J4.10 (GND), J4.SH (SHIELD), U1.1 (GND), U1.40 (GND), U1.41 (EP_GND); also elsewhere on the board
HP_DETECT: U1.9 (GPIO16); also elsewhere on the board
HP_EN: U1.32 (GPIO39); also elsewhere on the board
I2C_SCL: U1.17 (GPIO9); also elsewhere on the board
I2C_SDA: U1.12 (GPIO8); also elsewhere on the board
I2S_BCLK: U1.5 (GPIO5); also elsewhere on the board
I2S_DOUT: U1.7 (GPIO7); also elsewhere on the board
I2S_LRCLK: U1.6 (GPIO6); also elsewhere on the board
SD_CLK: J4.5 (CLK), U1.20 (GPIO12)
SD_CMD: J4.3 (CMD), R48.1 (SD_CMD), U1.19 (GPIO11)
SD_D0: J4.7 (DAT0), R49.1 (SD_D0), U1.21 (GPIO13)
SD_DAT3: J4.2 (DAT3/CD), R50.1 (SD_DAT3)
SD_DETECT_N: J4.9 (SD_DETECT_N); also elsewhere on the board
SPK_EN: U1.10 (GPIO17); also elsewhere on the board
TCA_INT_N: U1.22 (GPIO14); also elsewhere on the board
TFT_BL_PWM: U1.31 (GPIO38); also elsewhere on the board
TFT_CS: U1.35 (GPIO42); also elsewhere on the board
TFT_DC: U1.34 (GPIO41); also elsewhere on the board
TFT_MOSI: U1.24 (GPIO47); also elsewhere on the board
TFT_RST: U1.33 (GPIO40); also elsewhere on the board
TFT_SCLK: U1.25 (GPIO48); also elsewhere on the board
UART0_RX: U1.36 (RXD0); also elsewhere on the board
UART0_TX: U1.37 (TXD0); also elsewhere on the board
USB_DM: R6.1 (USB_DM); also elsewhere on the board
USB_DM_MCU: R6.2 (USB_DM_MCU), U1.13 (GPIO19_USB_D-)
USB_DP: R5.1 (USB_DP); also elsewhere on the board
USB_DP_MCU: R5.2 (USB_DP_MCU), U1.14 (GPIO20_USB_D+)

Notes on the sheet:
MCU, USB and microSD storage
AI-authored engineering reference. Verify pinout, support values, footprint orientation, lithium safety, RF keepout and assembly before fabrication.

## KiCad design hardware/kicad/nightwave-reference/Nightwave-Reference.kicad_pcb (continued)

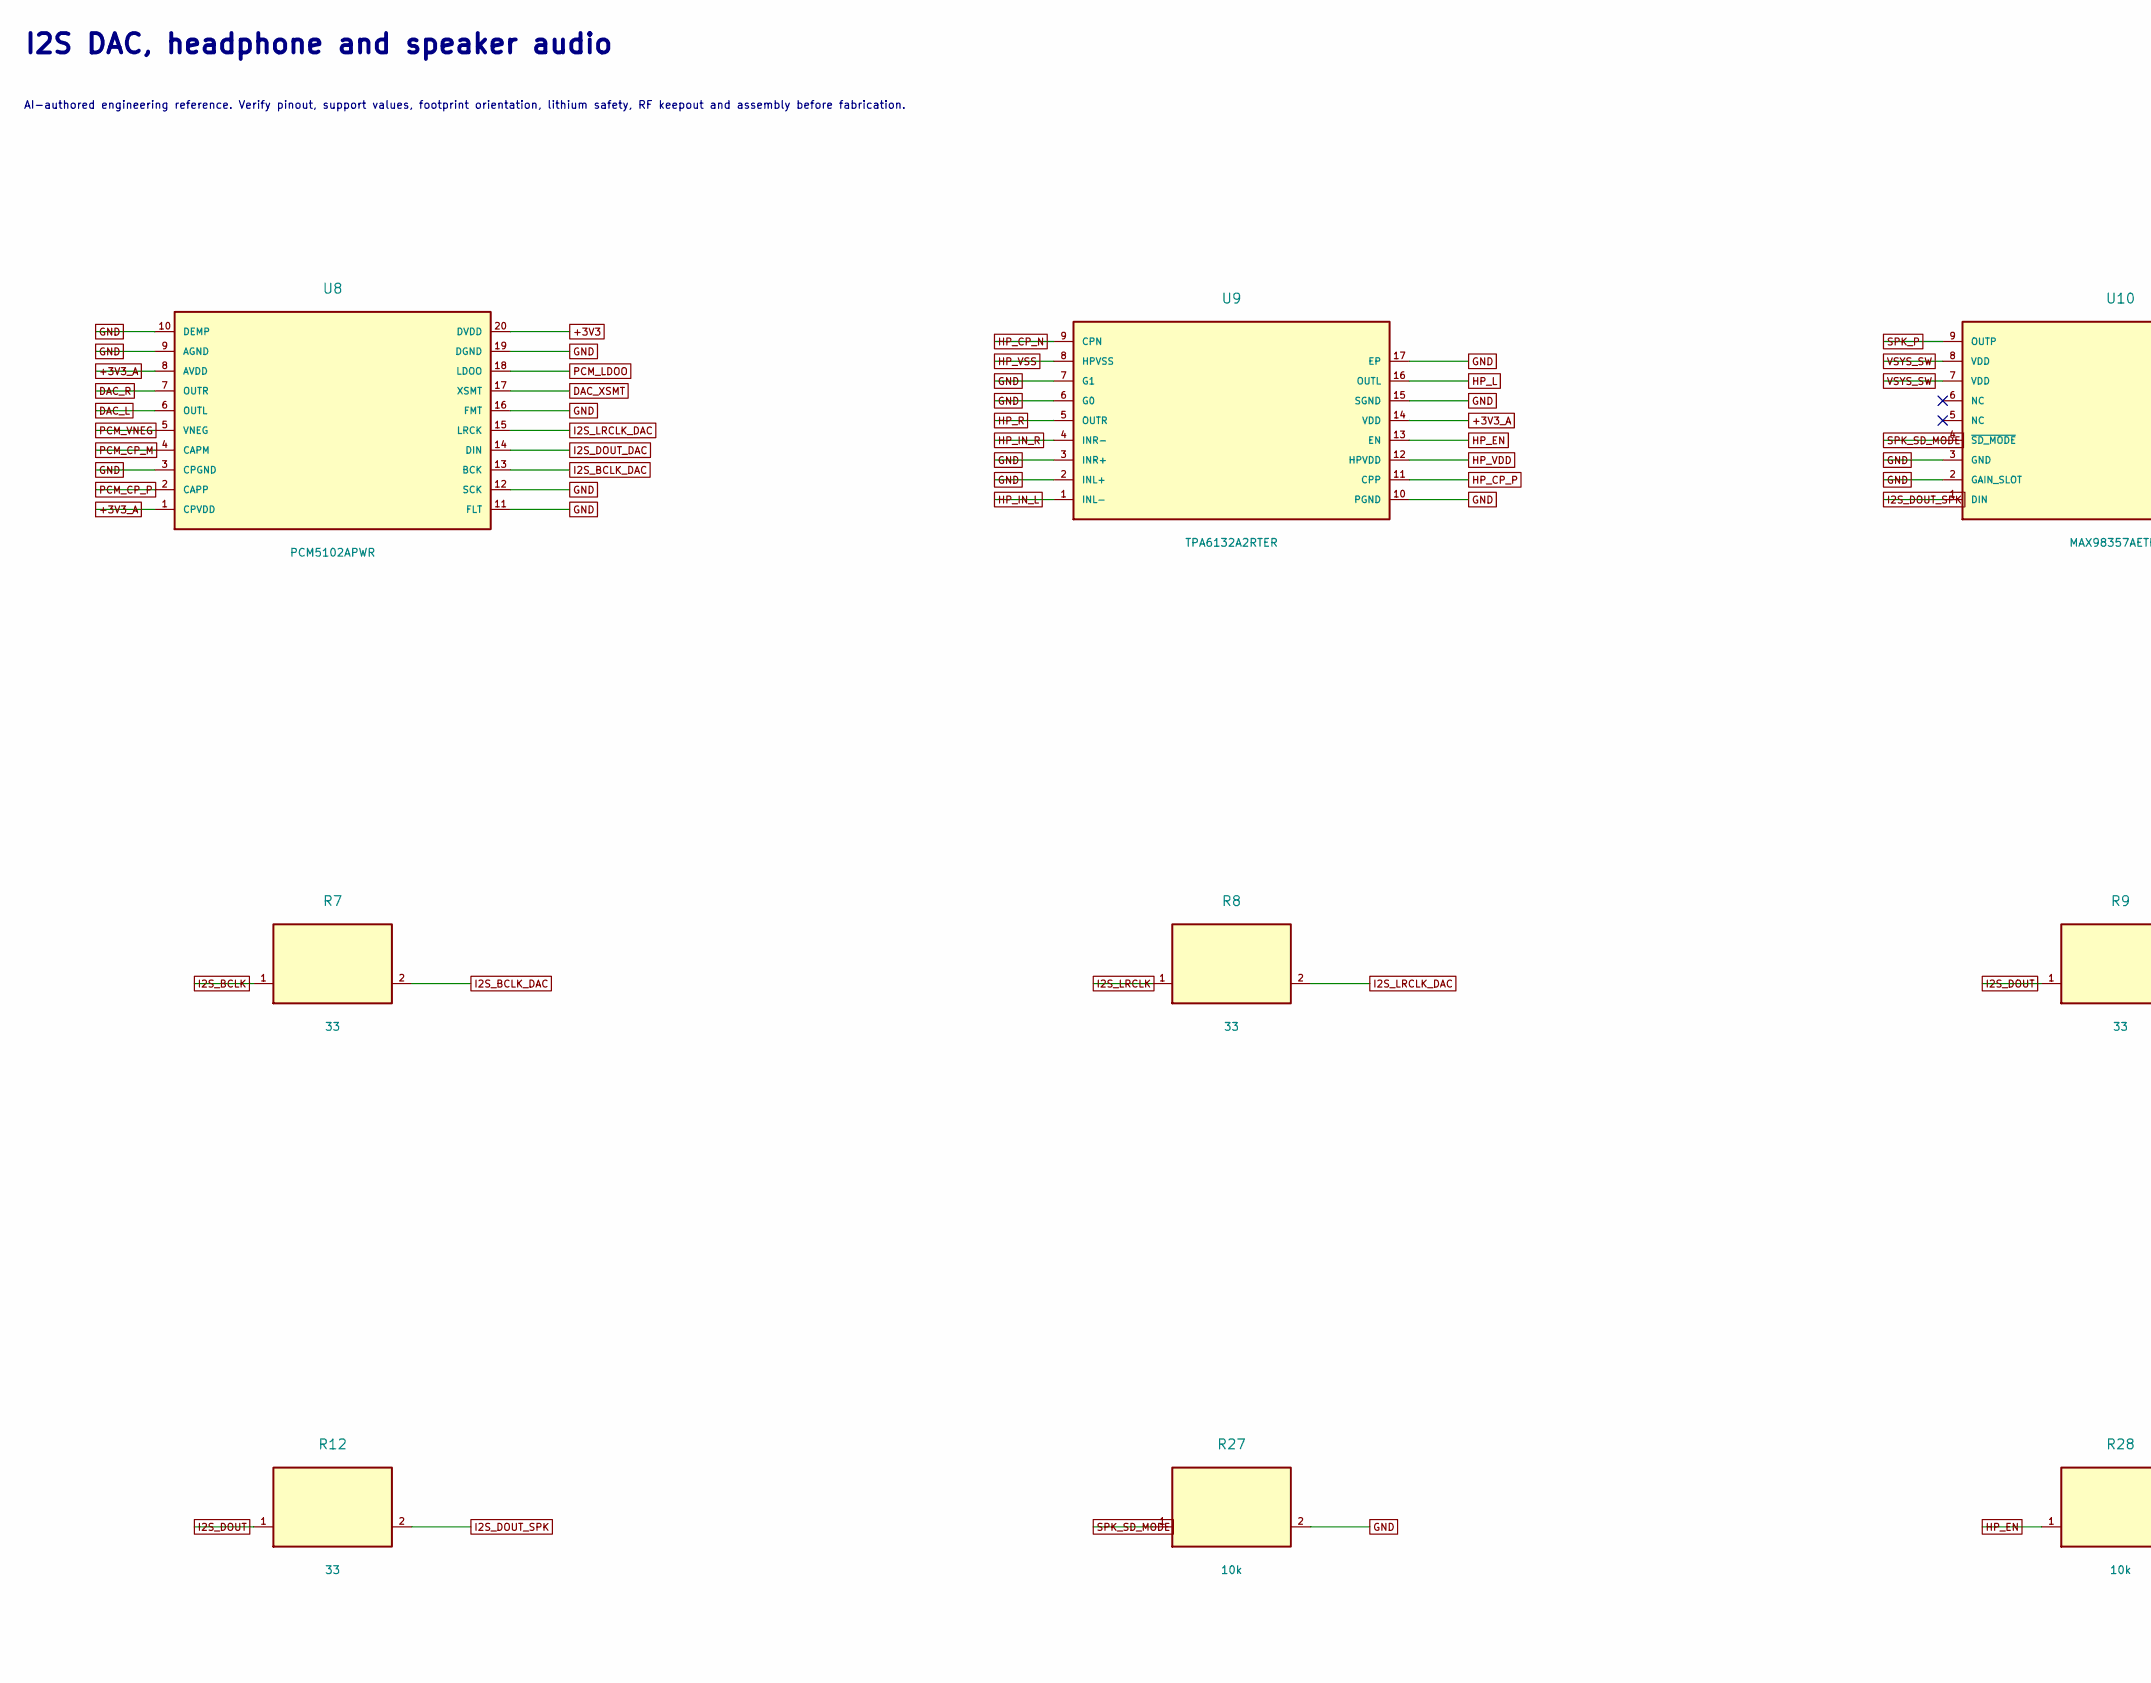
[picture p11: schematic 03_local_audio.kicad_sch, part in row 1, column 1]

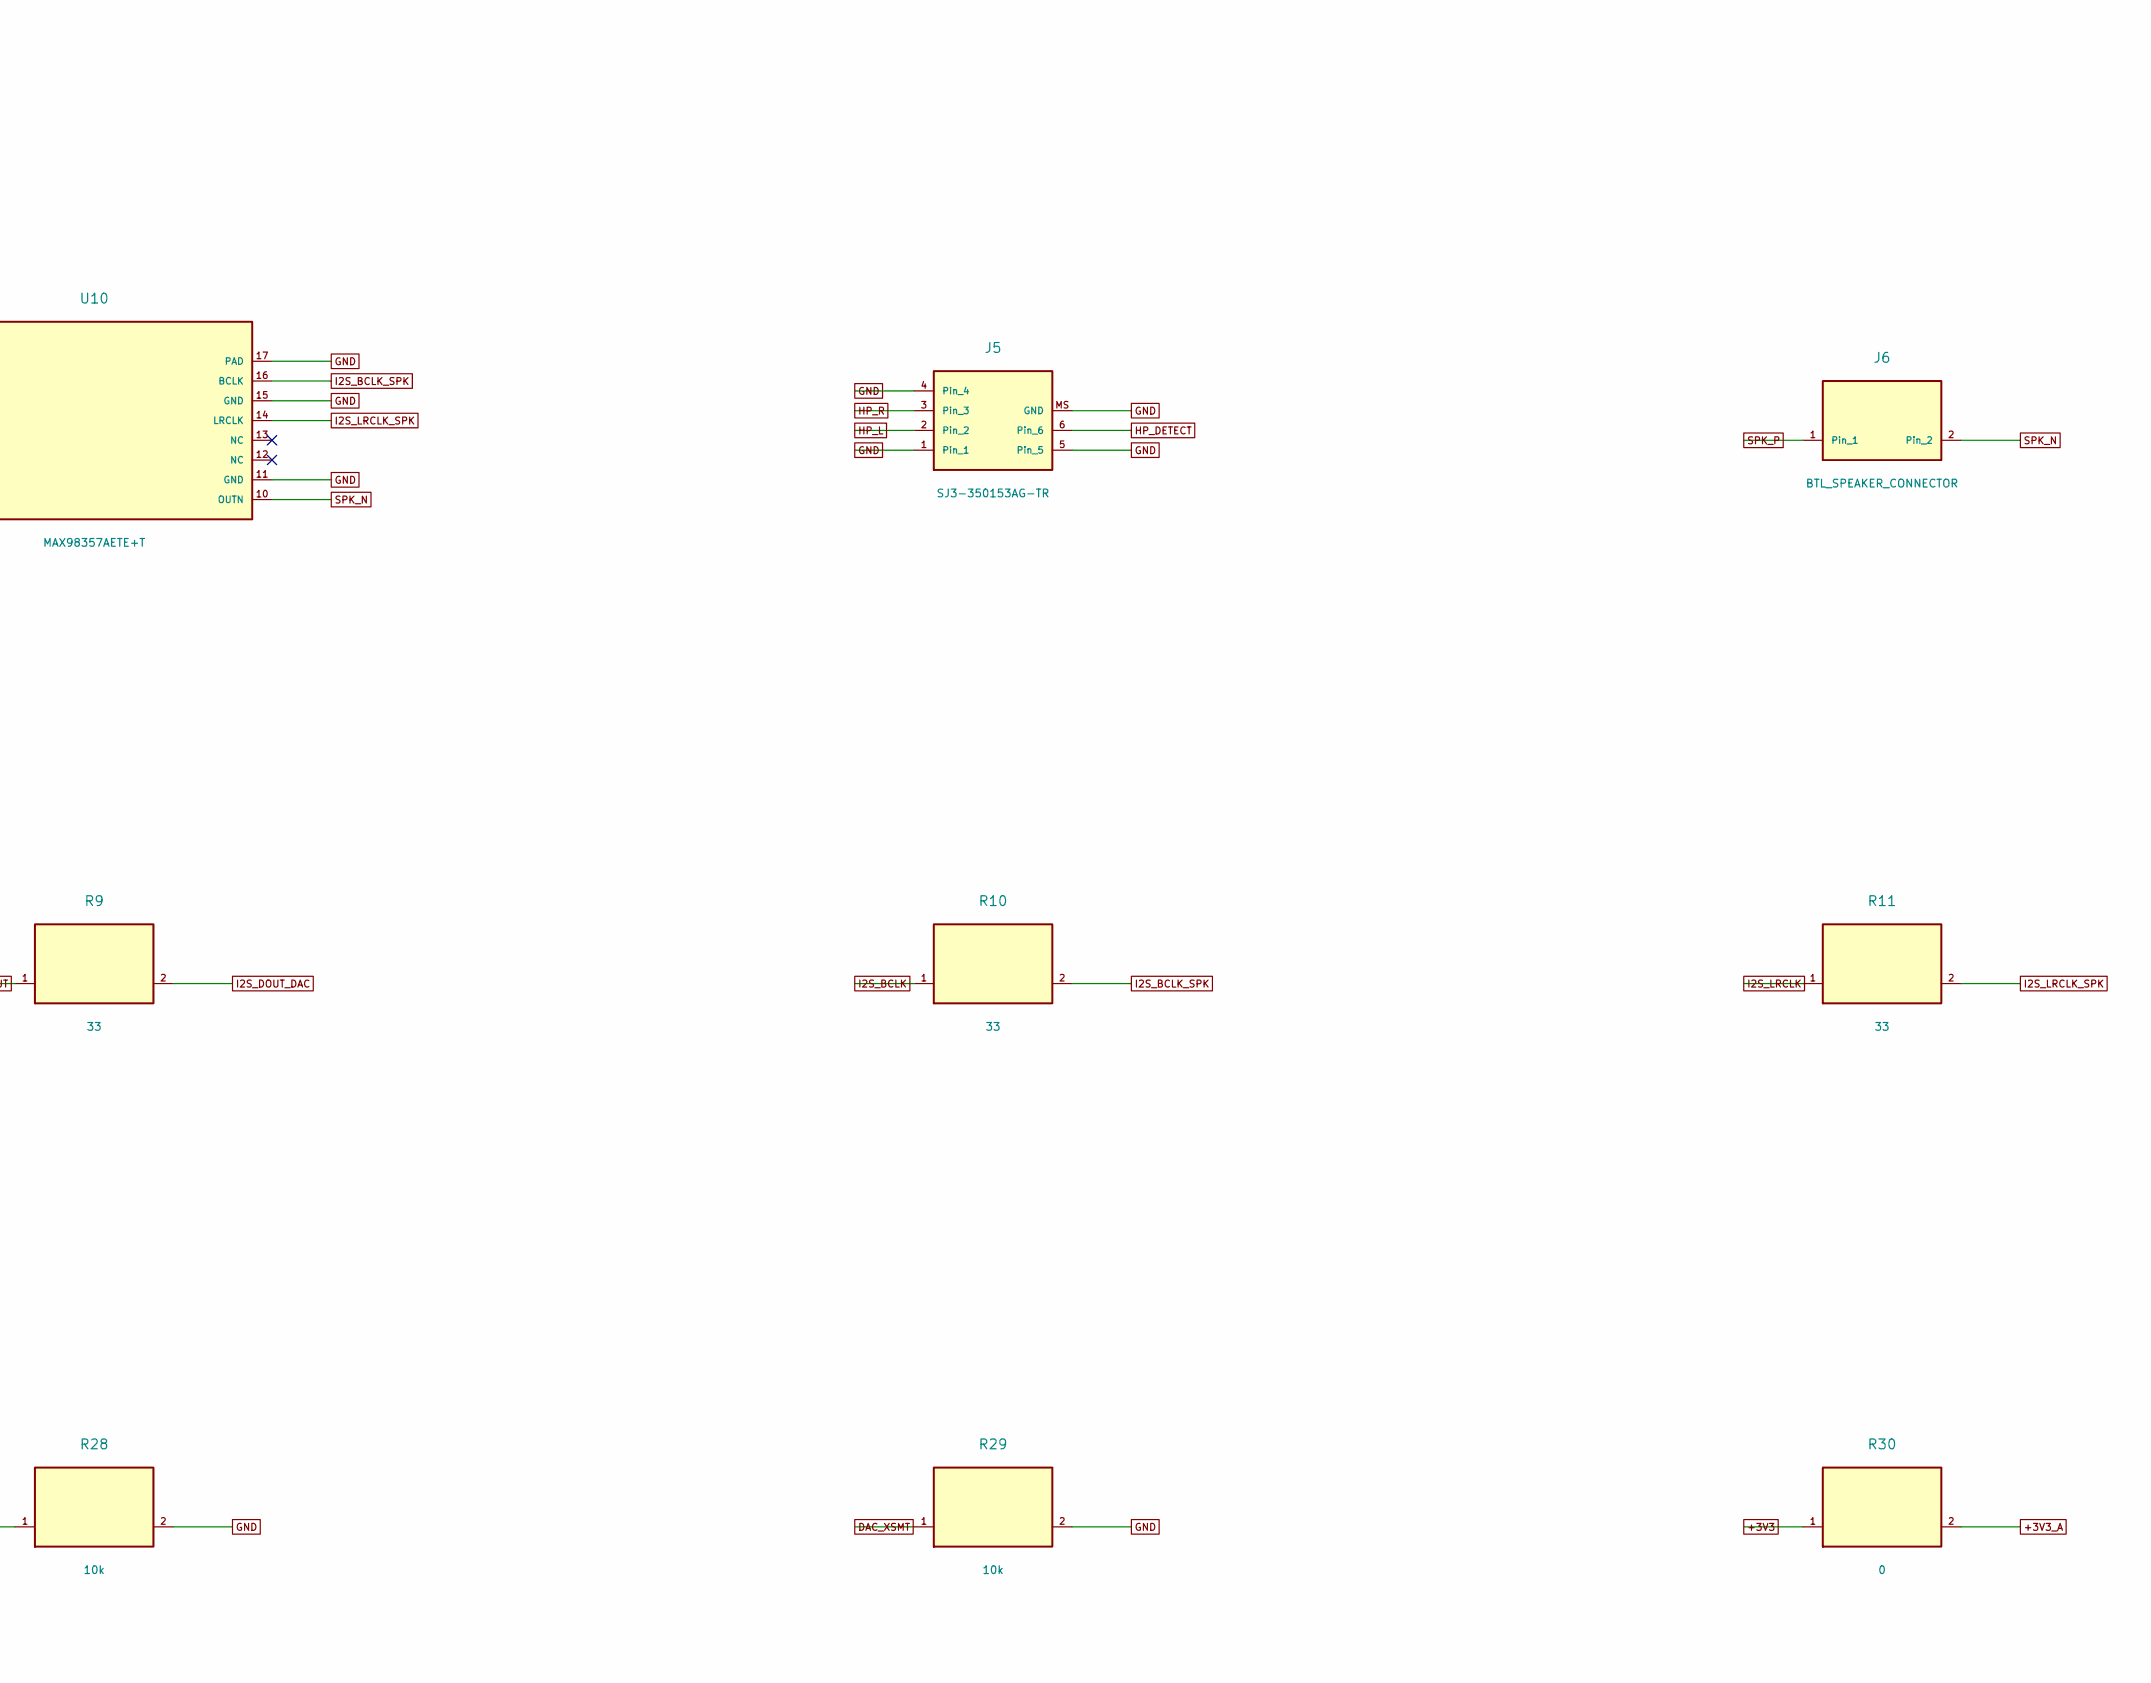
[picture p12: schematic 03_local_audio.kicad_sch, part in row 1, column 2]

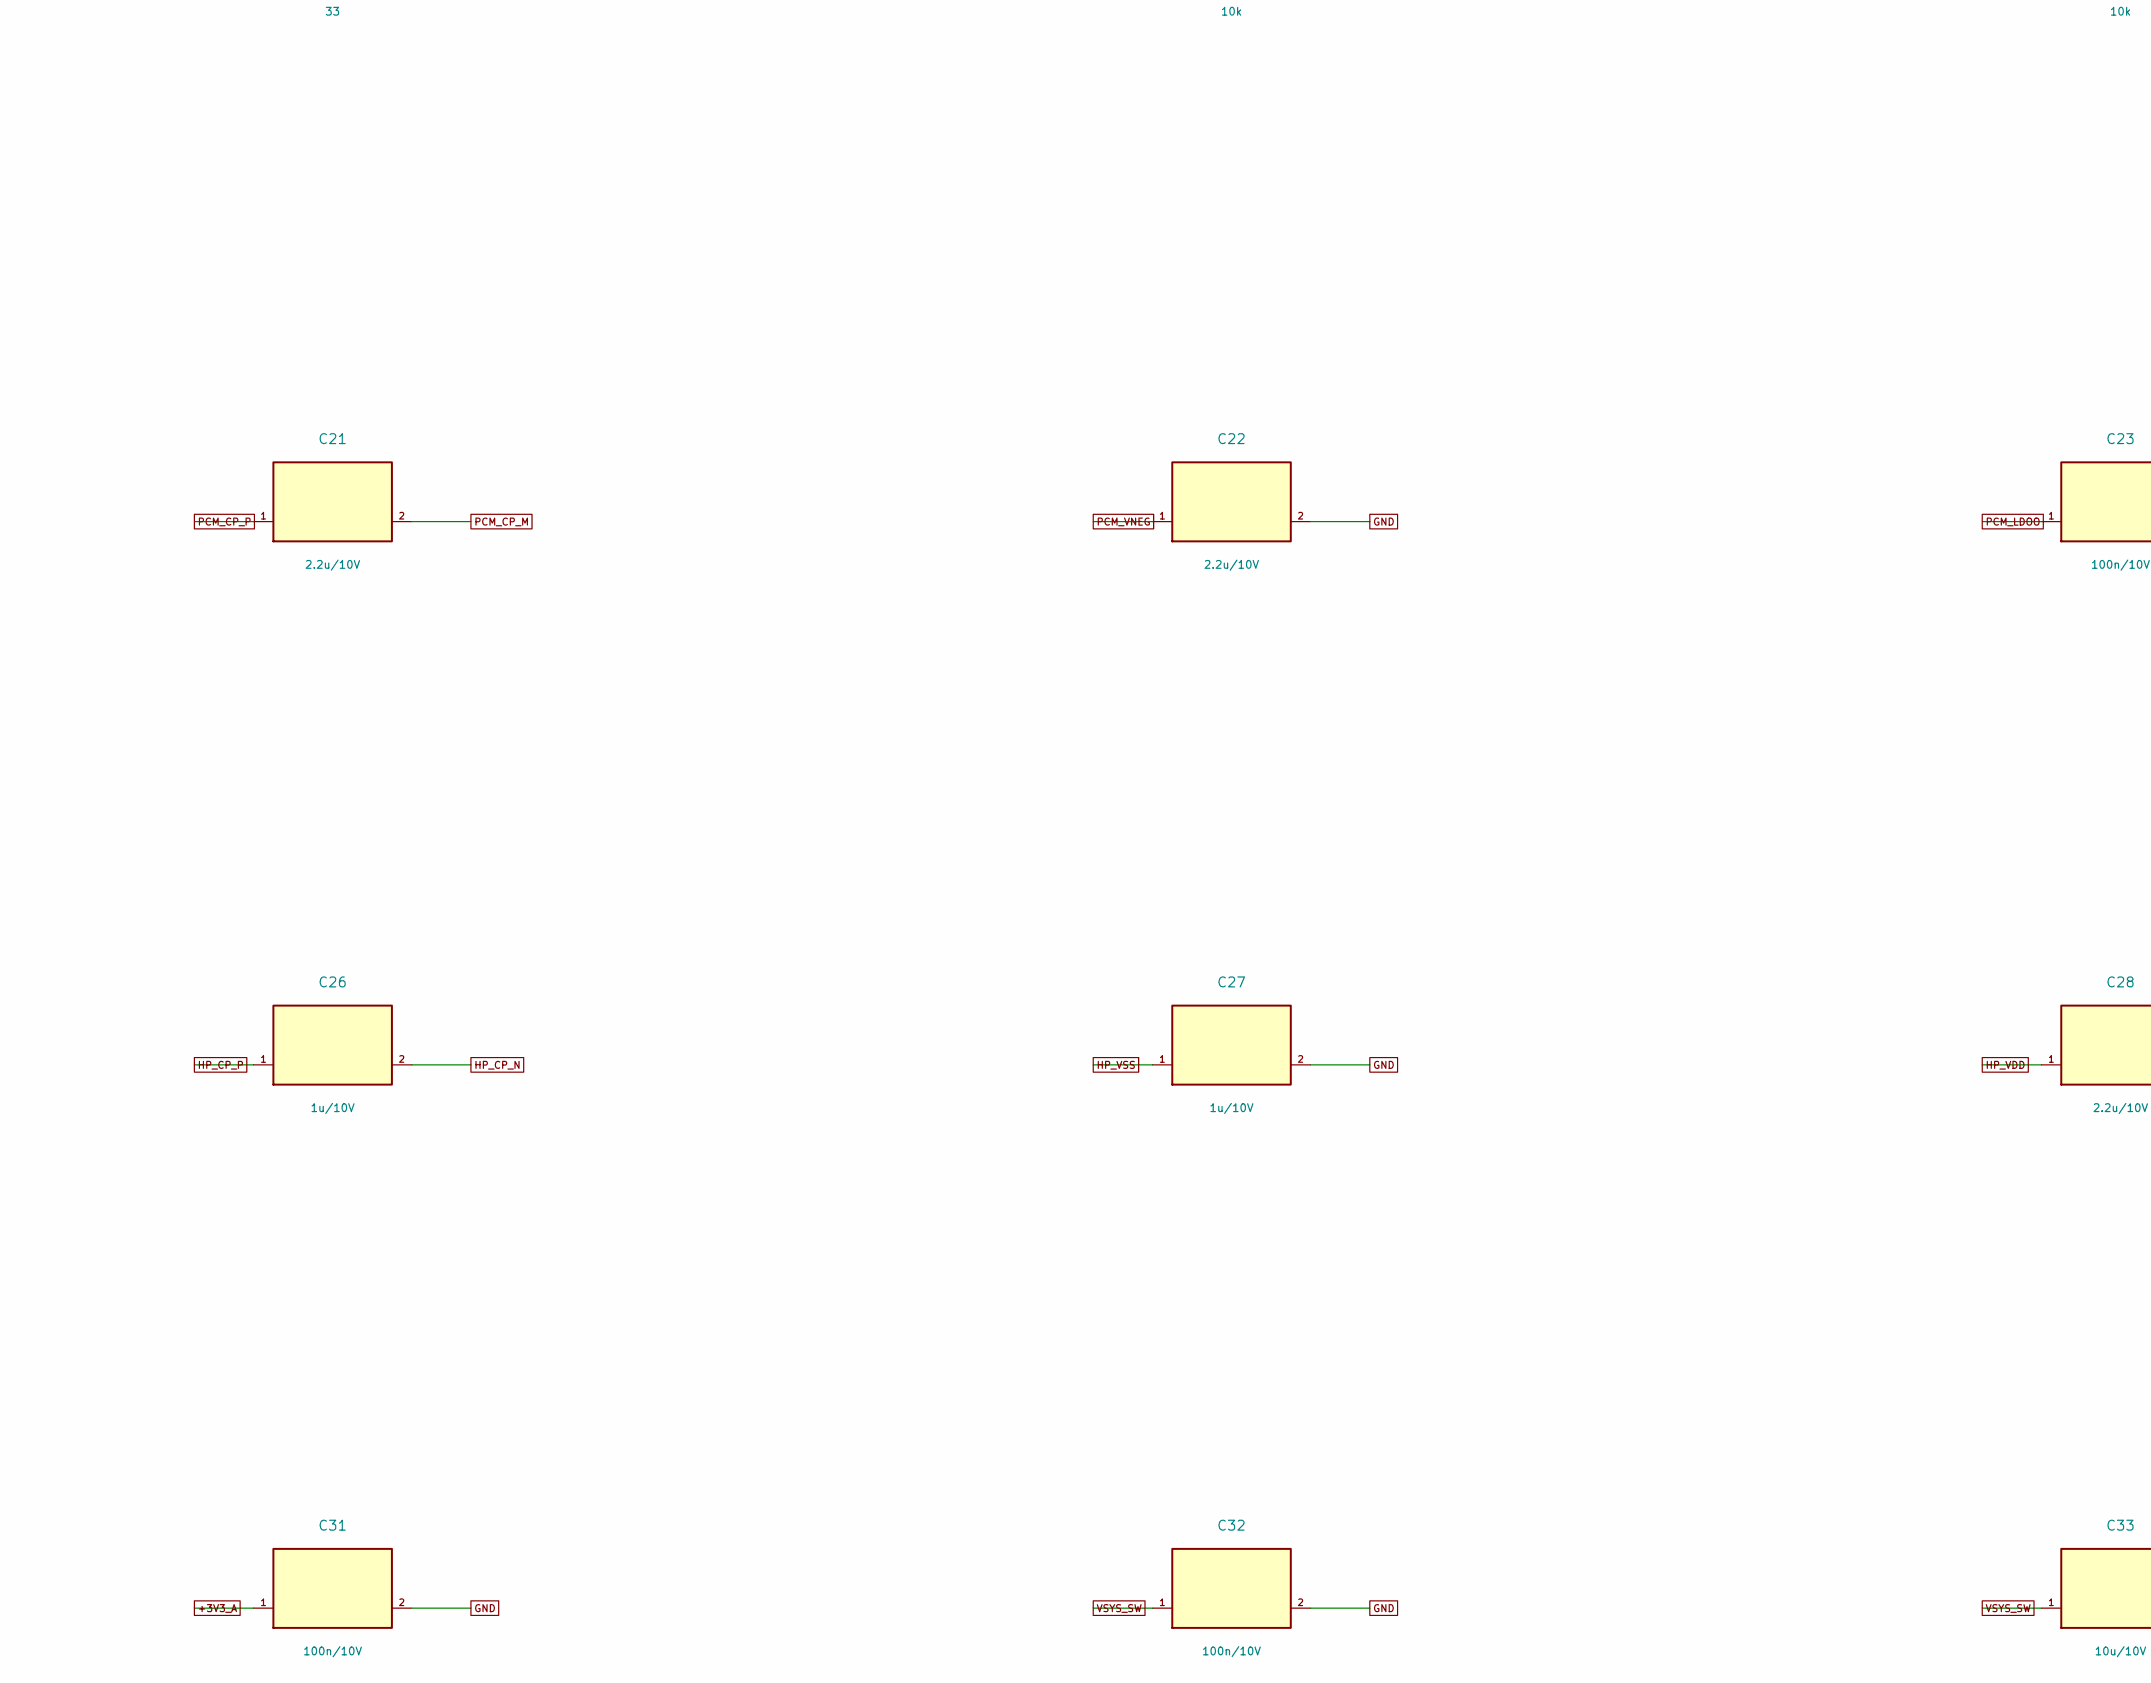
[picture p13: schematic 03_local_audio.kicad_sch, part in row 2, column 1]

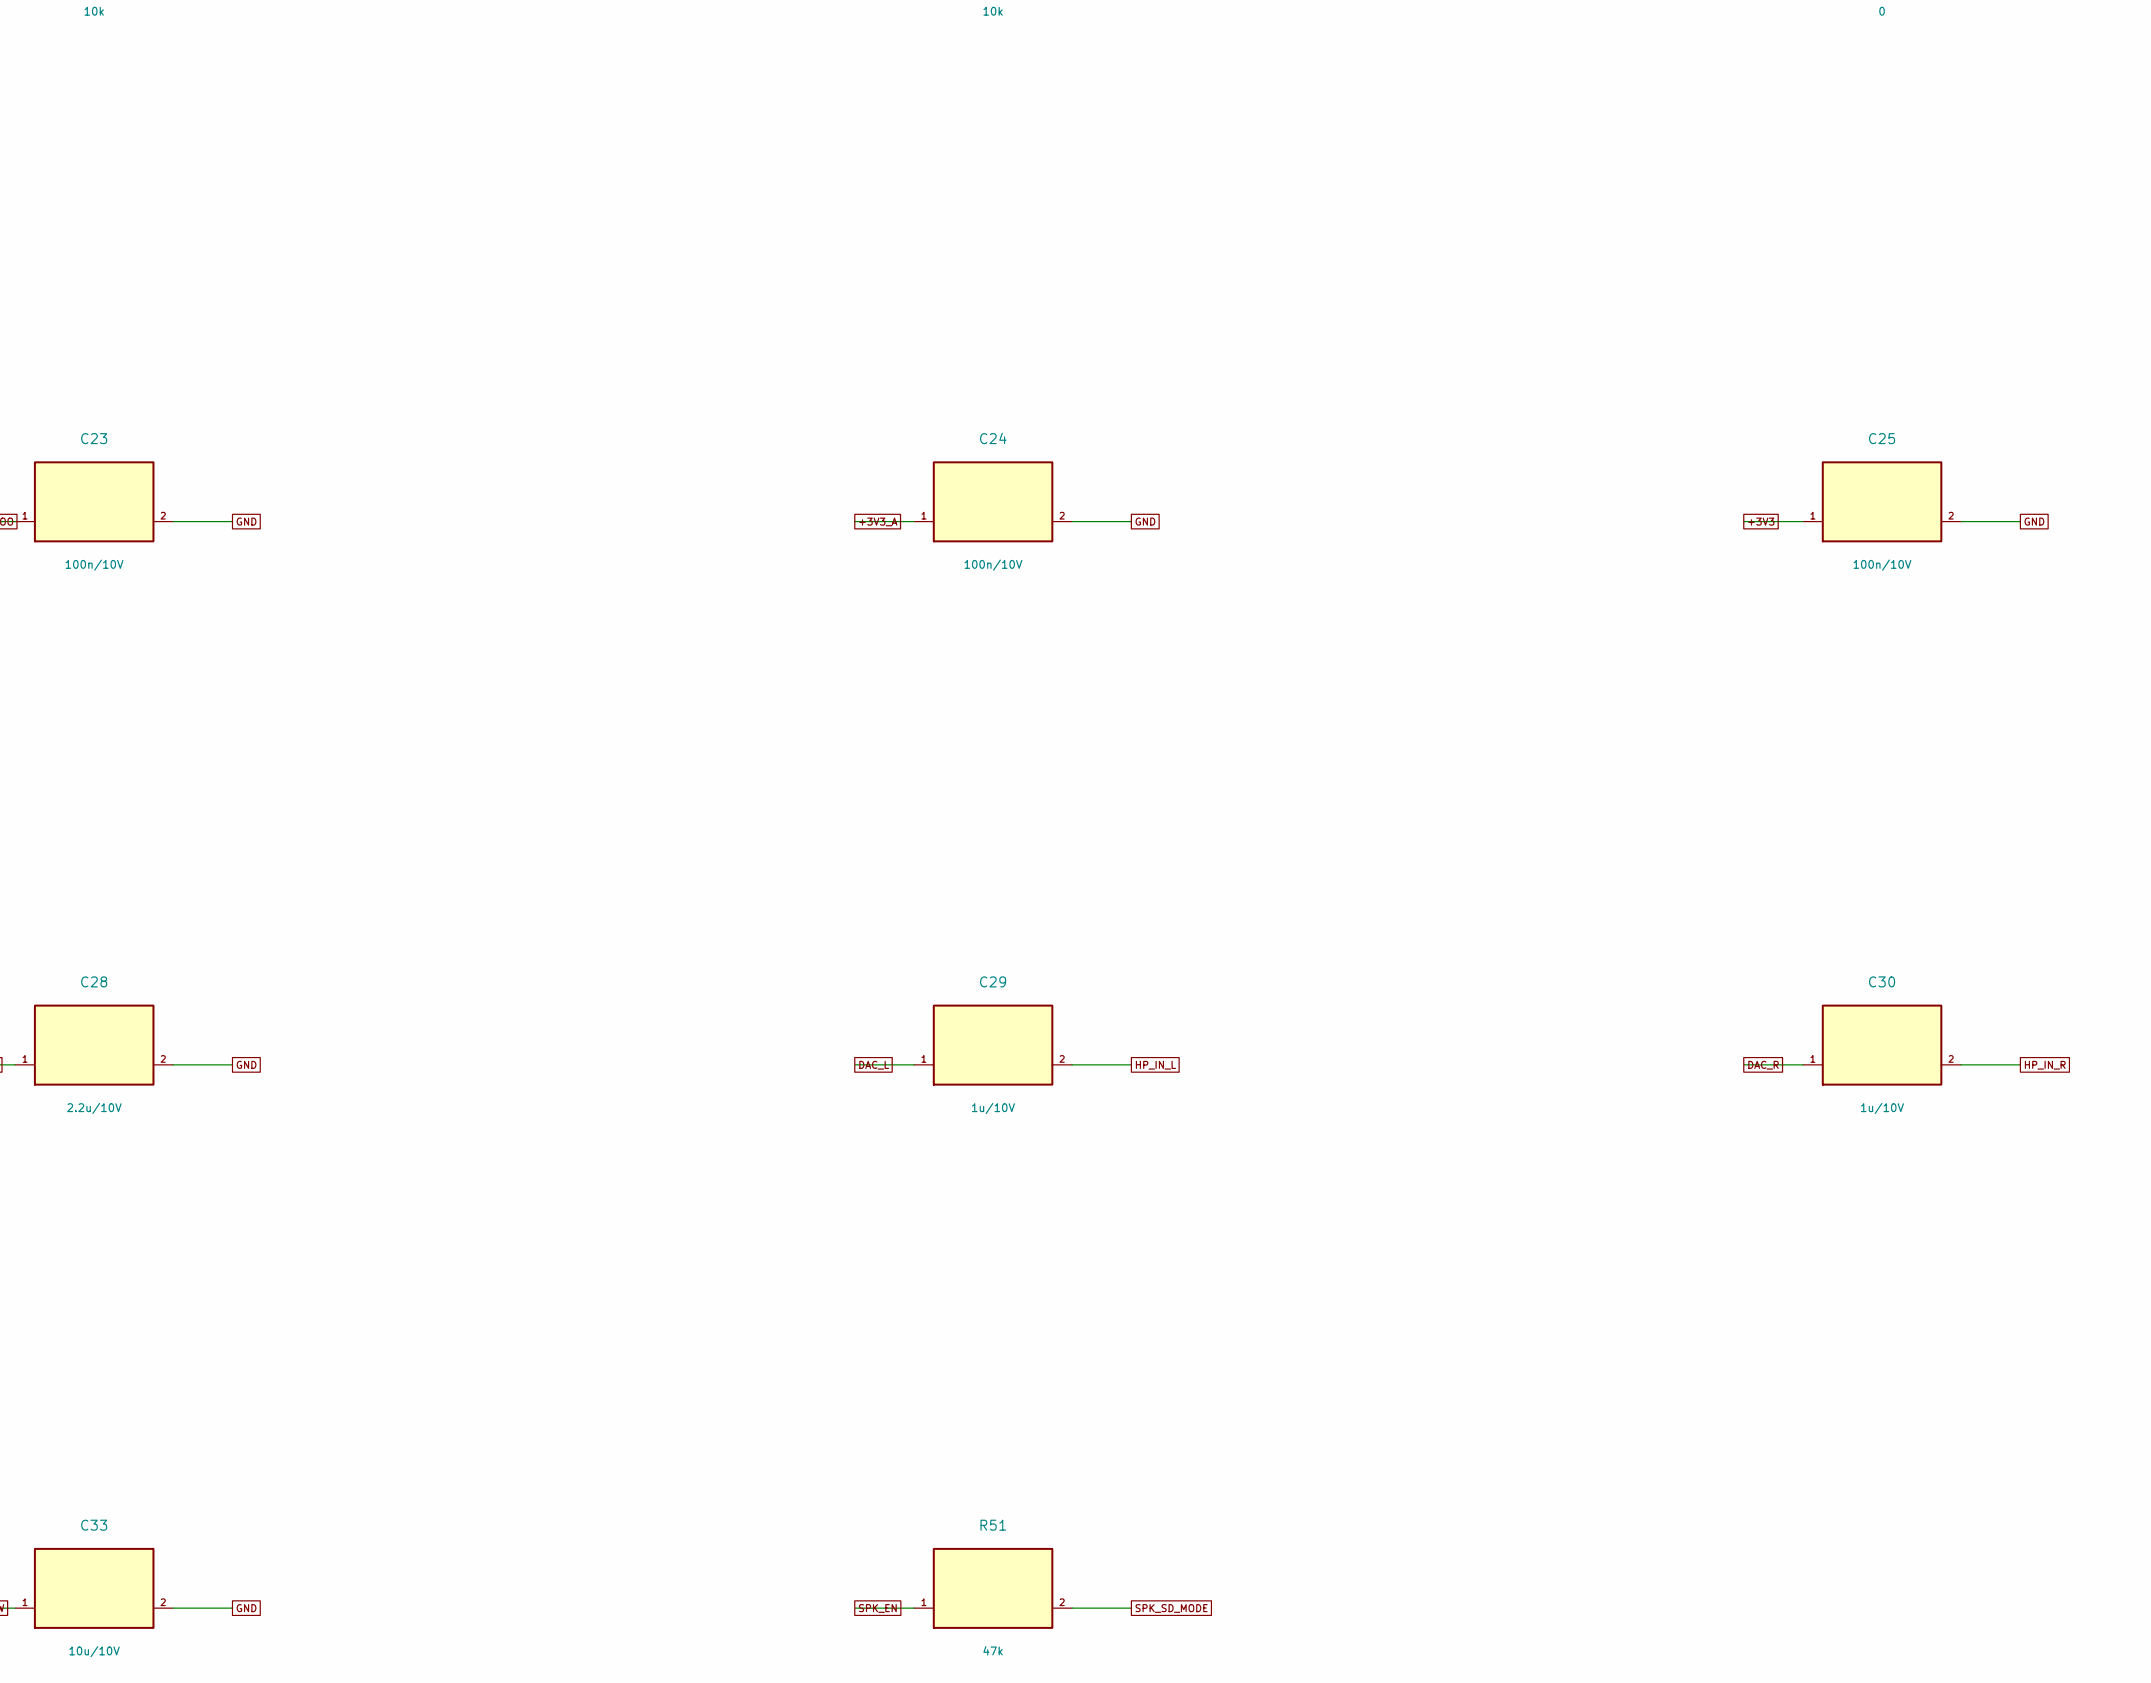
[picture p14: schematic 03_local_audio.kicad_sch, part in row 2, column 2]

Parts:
C21, C22, C28: 2.2u/10V; C_0805_2012Metric
C23, C24, C25, C31, C32: 100n/10V; C_0805_2012Metric
C26, C27, C29, C30: 1u/10V; C_0805_2012Metric
C33: 10u/10V; C_0805_2012Metric
J5: SJ3-350153AG-TR; SameSky_SJ3-350153AG
J6: BTL_SPEAKER_CONNECTOR; JST_PH_S2B-PH-K_1x02_P2.00mm_Horizontal
R7, R8, R9, R10, R11, R12: 33; R_0603_1608Metric
R27, R28, R29: 10k; R_0603_1608Metric
R30: 0; R_0603_1608Metric
R51: 47k; R_0603_1608Metric
U8: PCM5102APWR; Texas_PW0020A_TSSOP-20_4.4x6.5mm_P0.65mm
U9: TPA6132A2RTER; VQFN-16-1EP_3x3mm_P0.5mm_EP1.6x1.6mm_ThermalVias
U10: MAX98357AETE+T; TQFN-16-1EP_3x3mm_P0.5mm_EP1.23x1.23mm

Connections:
+3V3: C25.1 (+3V3), R30.1 (+3V3), U8.20 (DVDD); also elsewhere on the board
+3V3_A: C24.1 (+3V3_A), C31.1 (+3V3_A), R30.2 (+3V3_A), U8.1 (CPVDD), U8.8 (AVDD), U9.14 (VDD); also elsewhere on the board
DAC_L: C29.1 (DAC_L), U8.6 (OUTL)
DAC_R: C30.1 (DAC_R), U8.7 (OUTR)
DAC_XSMT: R29.1 (DAC_XSMT), U8.17 (XSMT); also elsewhere on the board
GND: C22.2 (GND), C23.2 (GND), C24.2 (GND), C25.2 (GND), C27.2 (GND), C28.2 (GND), C31.2 (GND), C32.2 (GND), C33.2 (GND), J5.1, J5.4, J5.5, J5.MS (GND), R27.2 (GND), R28.2 (GND), R29.2 (GND), U8.3 (CPGND), U8.9 (AGND), U8.10 (DEMP), U8.11 (FLT), U8.12 (SCK), U8.16 (FMT), U8.19 (DGND), U9.2 (INL+), U9.3 (INR+), U9.6 (G0), U9.7 (G1), U9.10 (PGND), U9.15 (SGND), U9.17 (EP), U10.2 (GAIN_SLOT), U10.3 (GND), U10.11 (GND), U10.15 (GND), U10.17 (PAD); also elsewhere on the board
HP_CP_N: C26.2 (HP_CP_N), U9.9 (CPN)
HP_CP_P: C26.1 (HP_CP_P), U9.11 (CPP)
HP_DETECT: J5.6; also elsewhere on the board
HP_EN: R28.1 (HP_EN), U9.13 (EN); also elsewhere on the board
HP_IN_L: C29.2 (HP_IN_L), U9.1 (INL-)
HP_IN_R: C30.2 (HP_IN_R), U9.4 (INR-)
HP_L: J5.2, U9.16 (OUTL)
HP_R: J5.3, U9.5 (OUTR)
HP_VDD: C28.1 (HP_VDD), U9.12 (HPVDD)
HP_VSS: C27.1 (HP_VSS), U9.8 (HPVSS)
I2S_BCLK: R7.1 (I2S_BCLK), R10.1 (I2S_BCLK); also elsewhere on the board
I2S_BCLK_DAC: R7.2 (I2S_BCLK_DAC), U8.13 (BCK)
I2S_BCLK_SPK: R10.2 (I2S_BCLK_SPK), U10.16 (BCLK)
I2S_DOUT: R9.1 (I2S_DOUT), R12.1 (I2S_DOUT); also elsewhere on the board
I2S_DOUT_DAC: R9.2 (I2S_DOUT_DAC), U8.14 (DIN)
I2S_DOUT_SPK: R12.2 (I2S_DOUT_SPK), U10.1 (DIN)
I2S_LRCLK: R8.1 (I2S_LRCLK), R11.1 (I2S_LRCLK); also elsewhere on the board
I2S_LRCLK_DAC: R8.2 (I2S_LRCLK_DAC), U8.15 (LRCK)
I2S_LRCLK_SPK: R11.2 (I2S_LRCLK_SPK), U10.14 (LRCLK)
PCM_CP_M: C21.2 (PCM_CP_M), U8.4 (CAPM)
PCM_CP_P: C21.1 (PCM_CP_P), U8.2 (CAPP)
PCM_LDOO: C23.1 (PCM_LDOO), U8.18 (LDOO)
PCM_VNEG: C22.1 (PCM_VNEG), U8.5 (VNEG)
SPK_EN: R51.1 (SPK_EN); also elsewhere on the board
SPK_N: J6.2, U10.10 (OUTN)
SPK_P: J6.1, U10.9 (OUTP)
SPK_SD_MODE: R27.1 (SPK_SD_MODE), R51.2 (SPK_SD_MODE), U10.4 (~SD_MODE)
VSYS_SW: C32.1 (VSYS_SW), C33.1 (VSYS_SW), U10.7 (VDD), U10.8 (VDD); also elsewhere on the board

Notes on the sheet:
I2S DAC, headphone and speaker audio
AI-authored engineering reference. Verify pinout, support values, footprint orientation, lithium safety, RF keepout and assembly before fabrication.

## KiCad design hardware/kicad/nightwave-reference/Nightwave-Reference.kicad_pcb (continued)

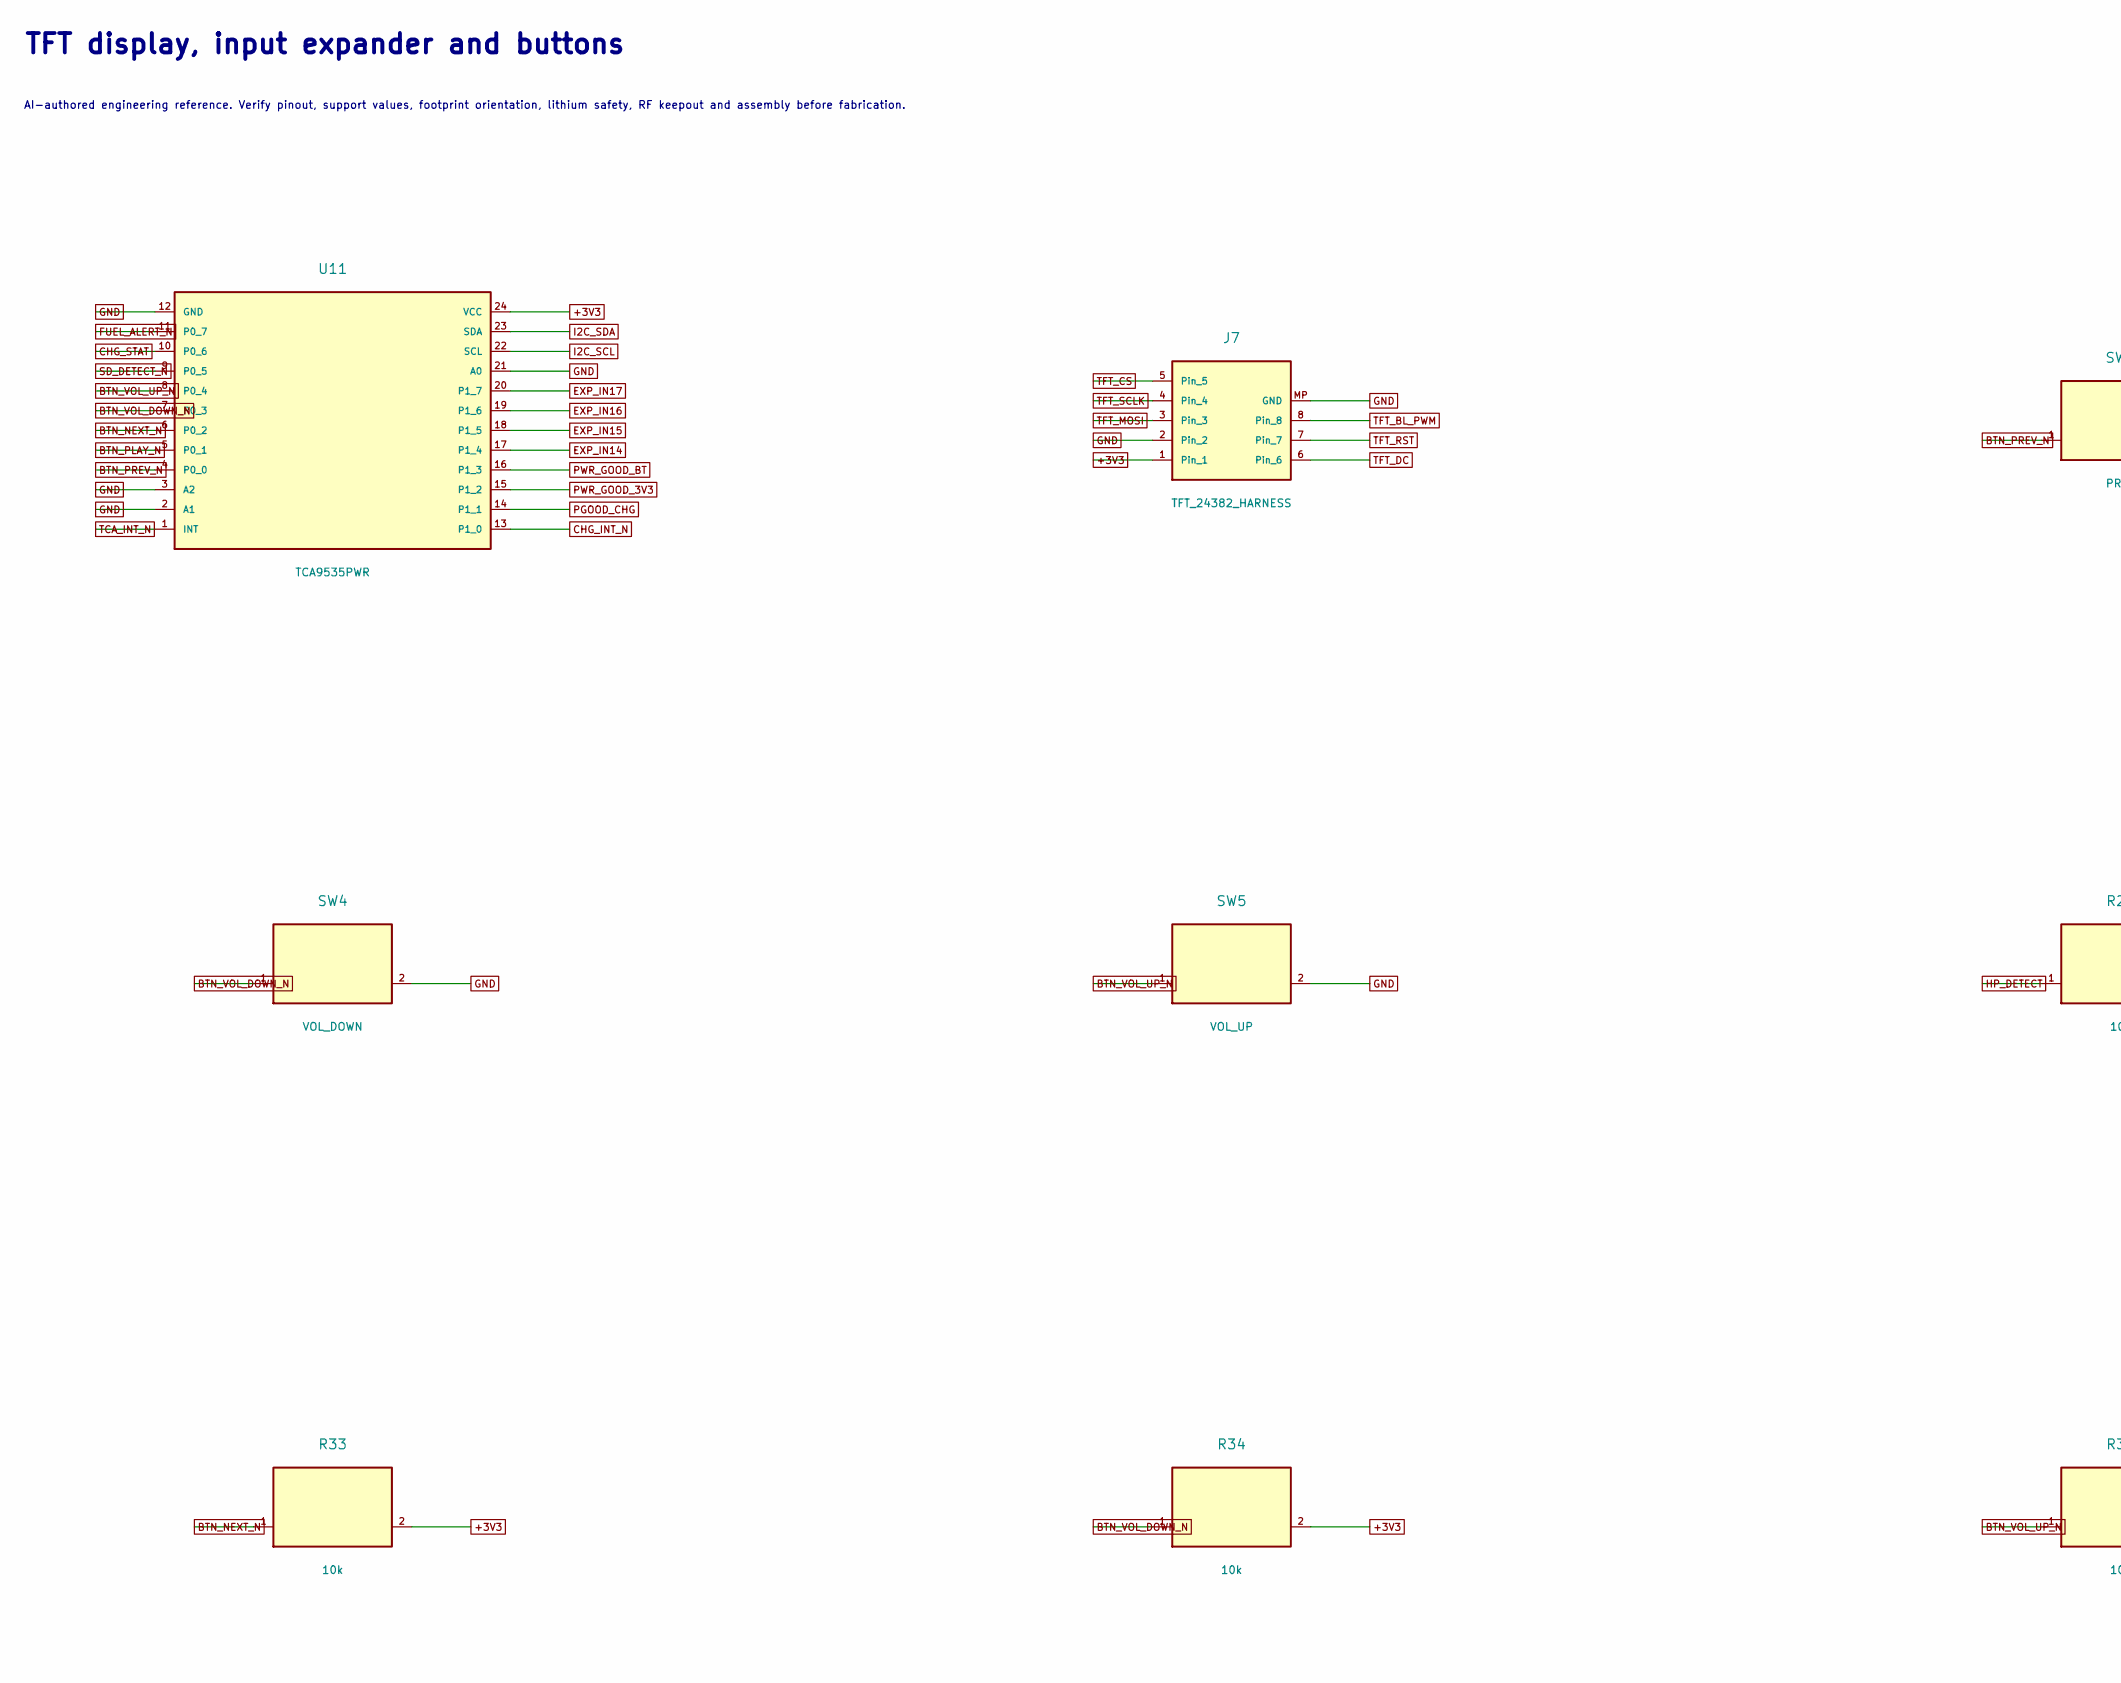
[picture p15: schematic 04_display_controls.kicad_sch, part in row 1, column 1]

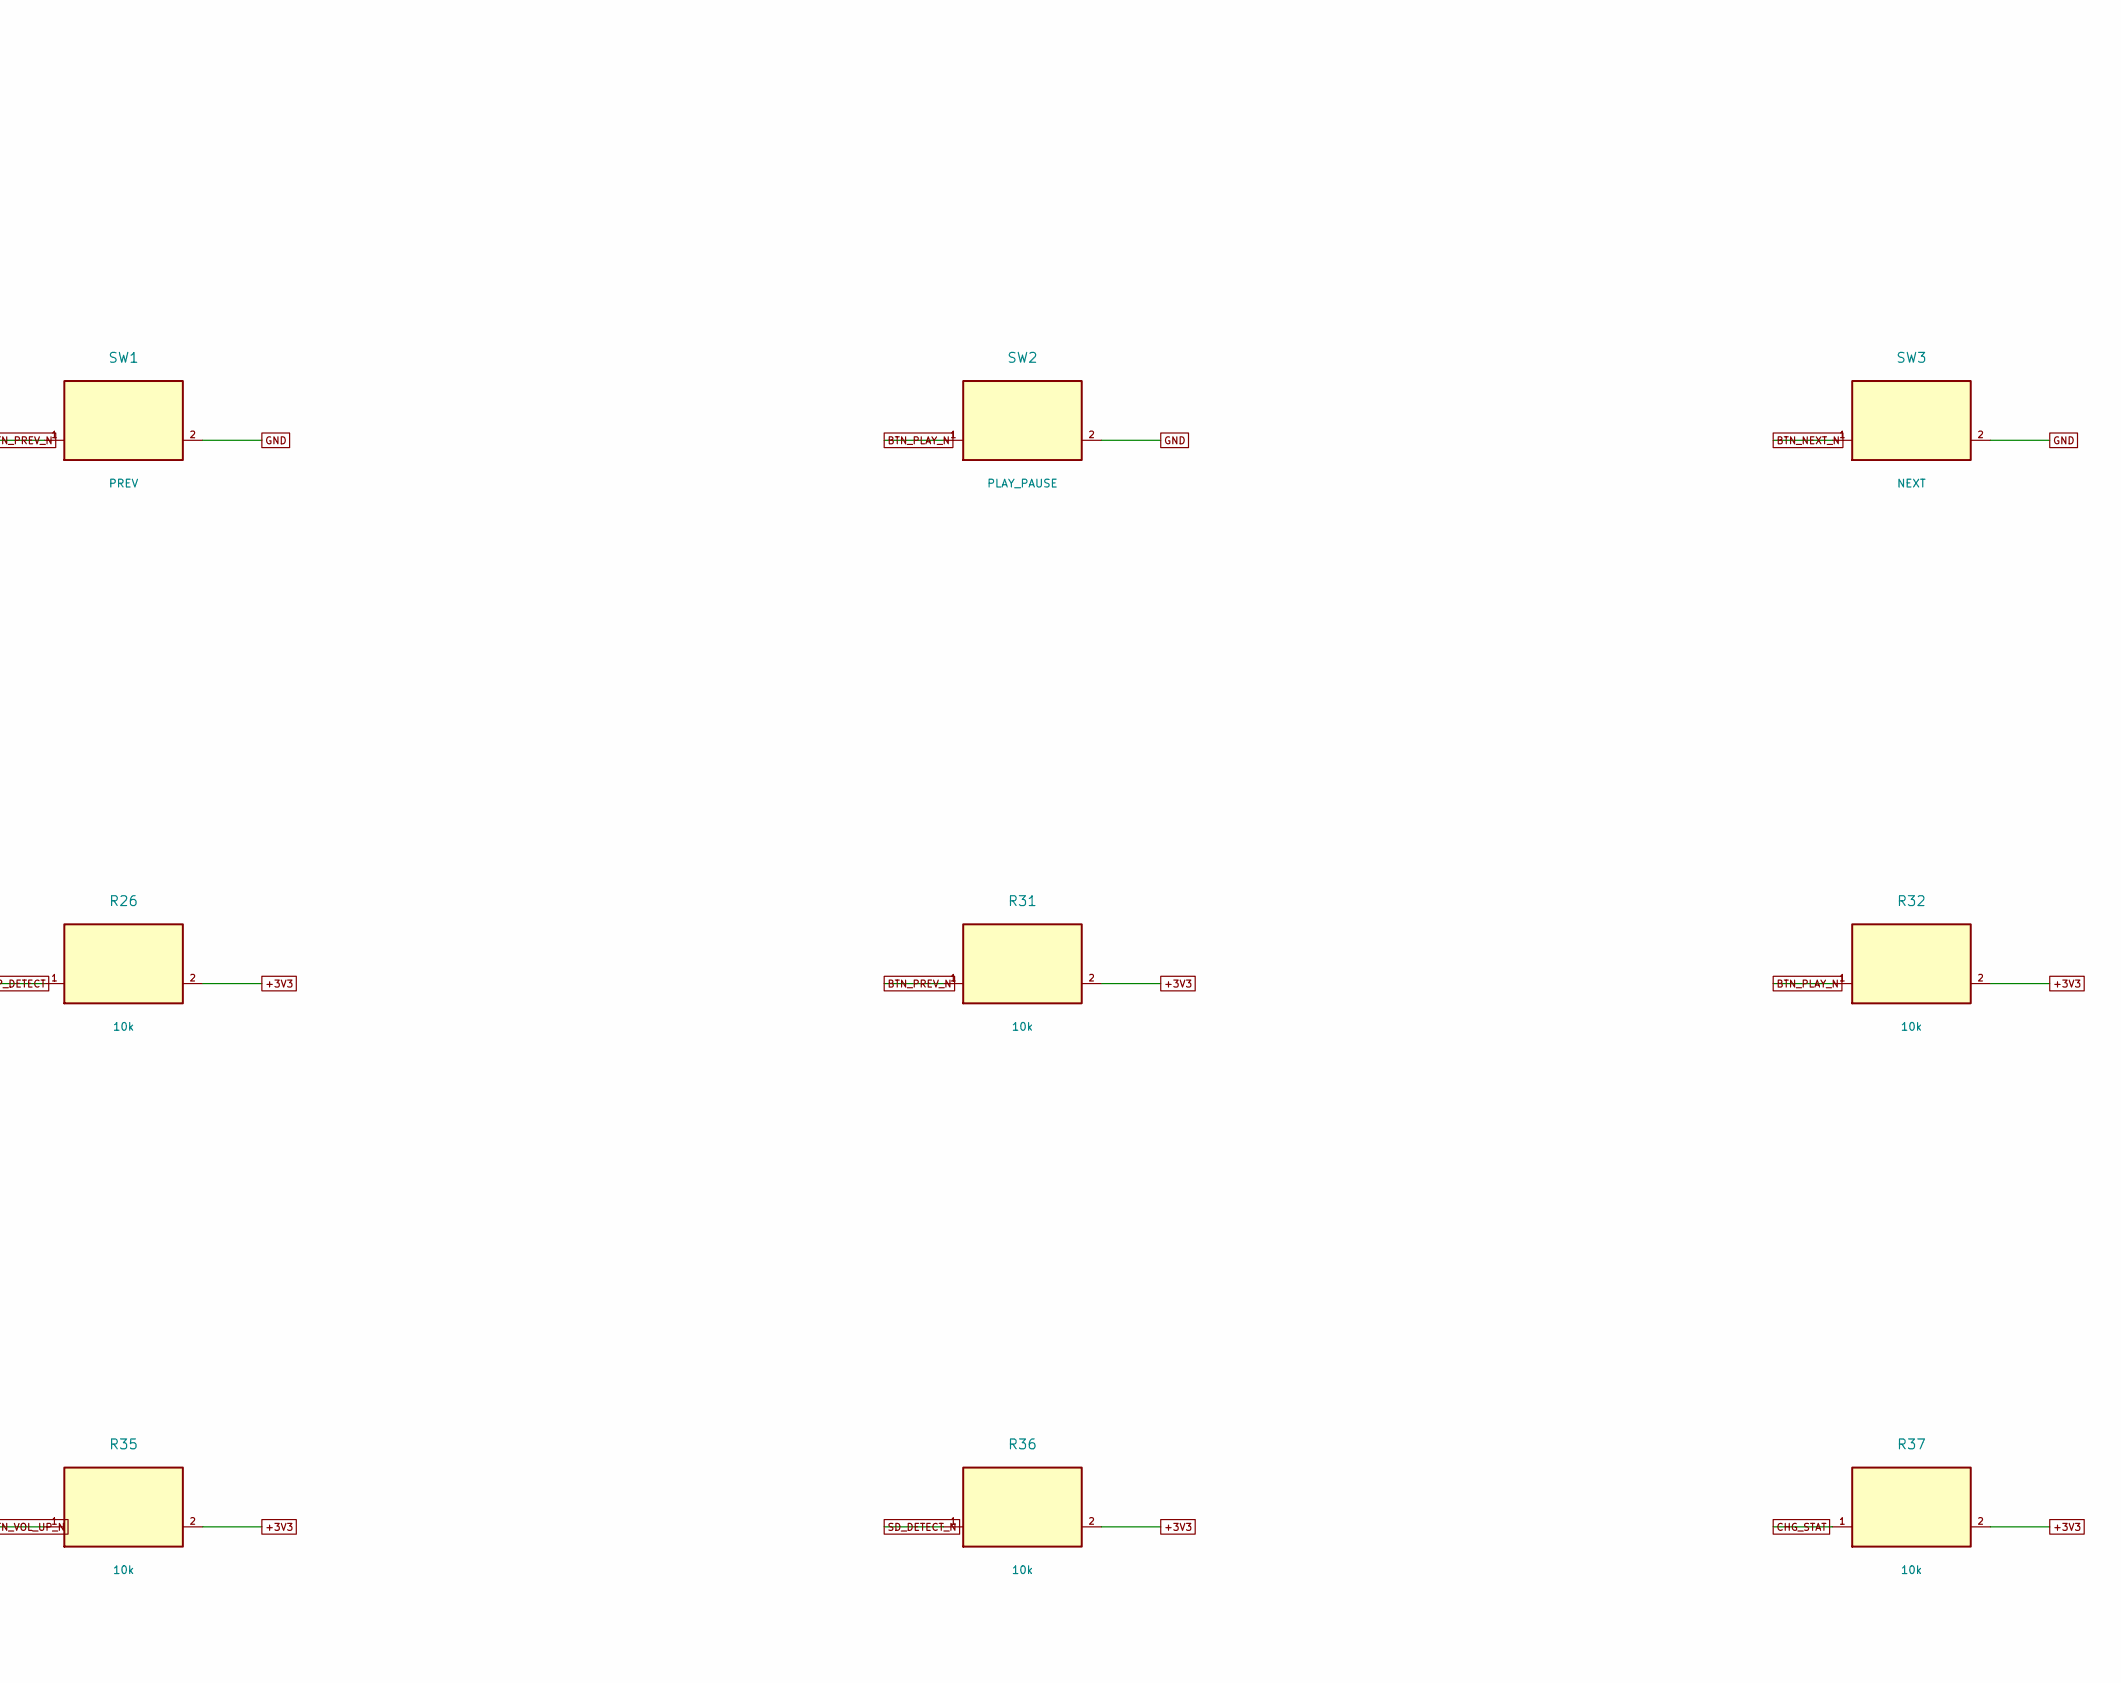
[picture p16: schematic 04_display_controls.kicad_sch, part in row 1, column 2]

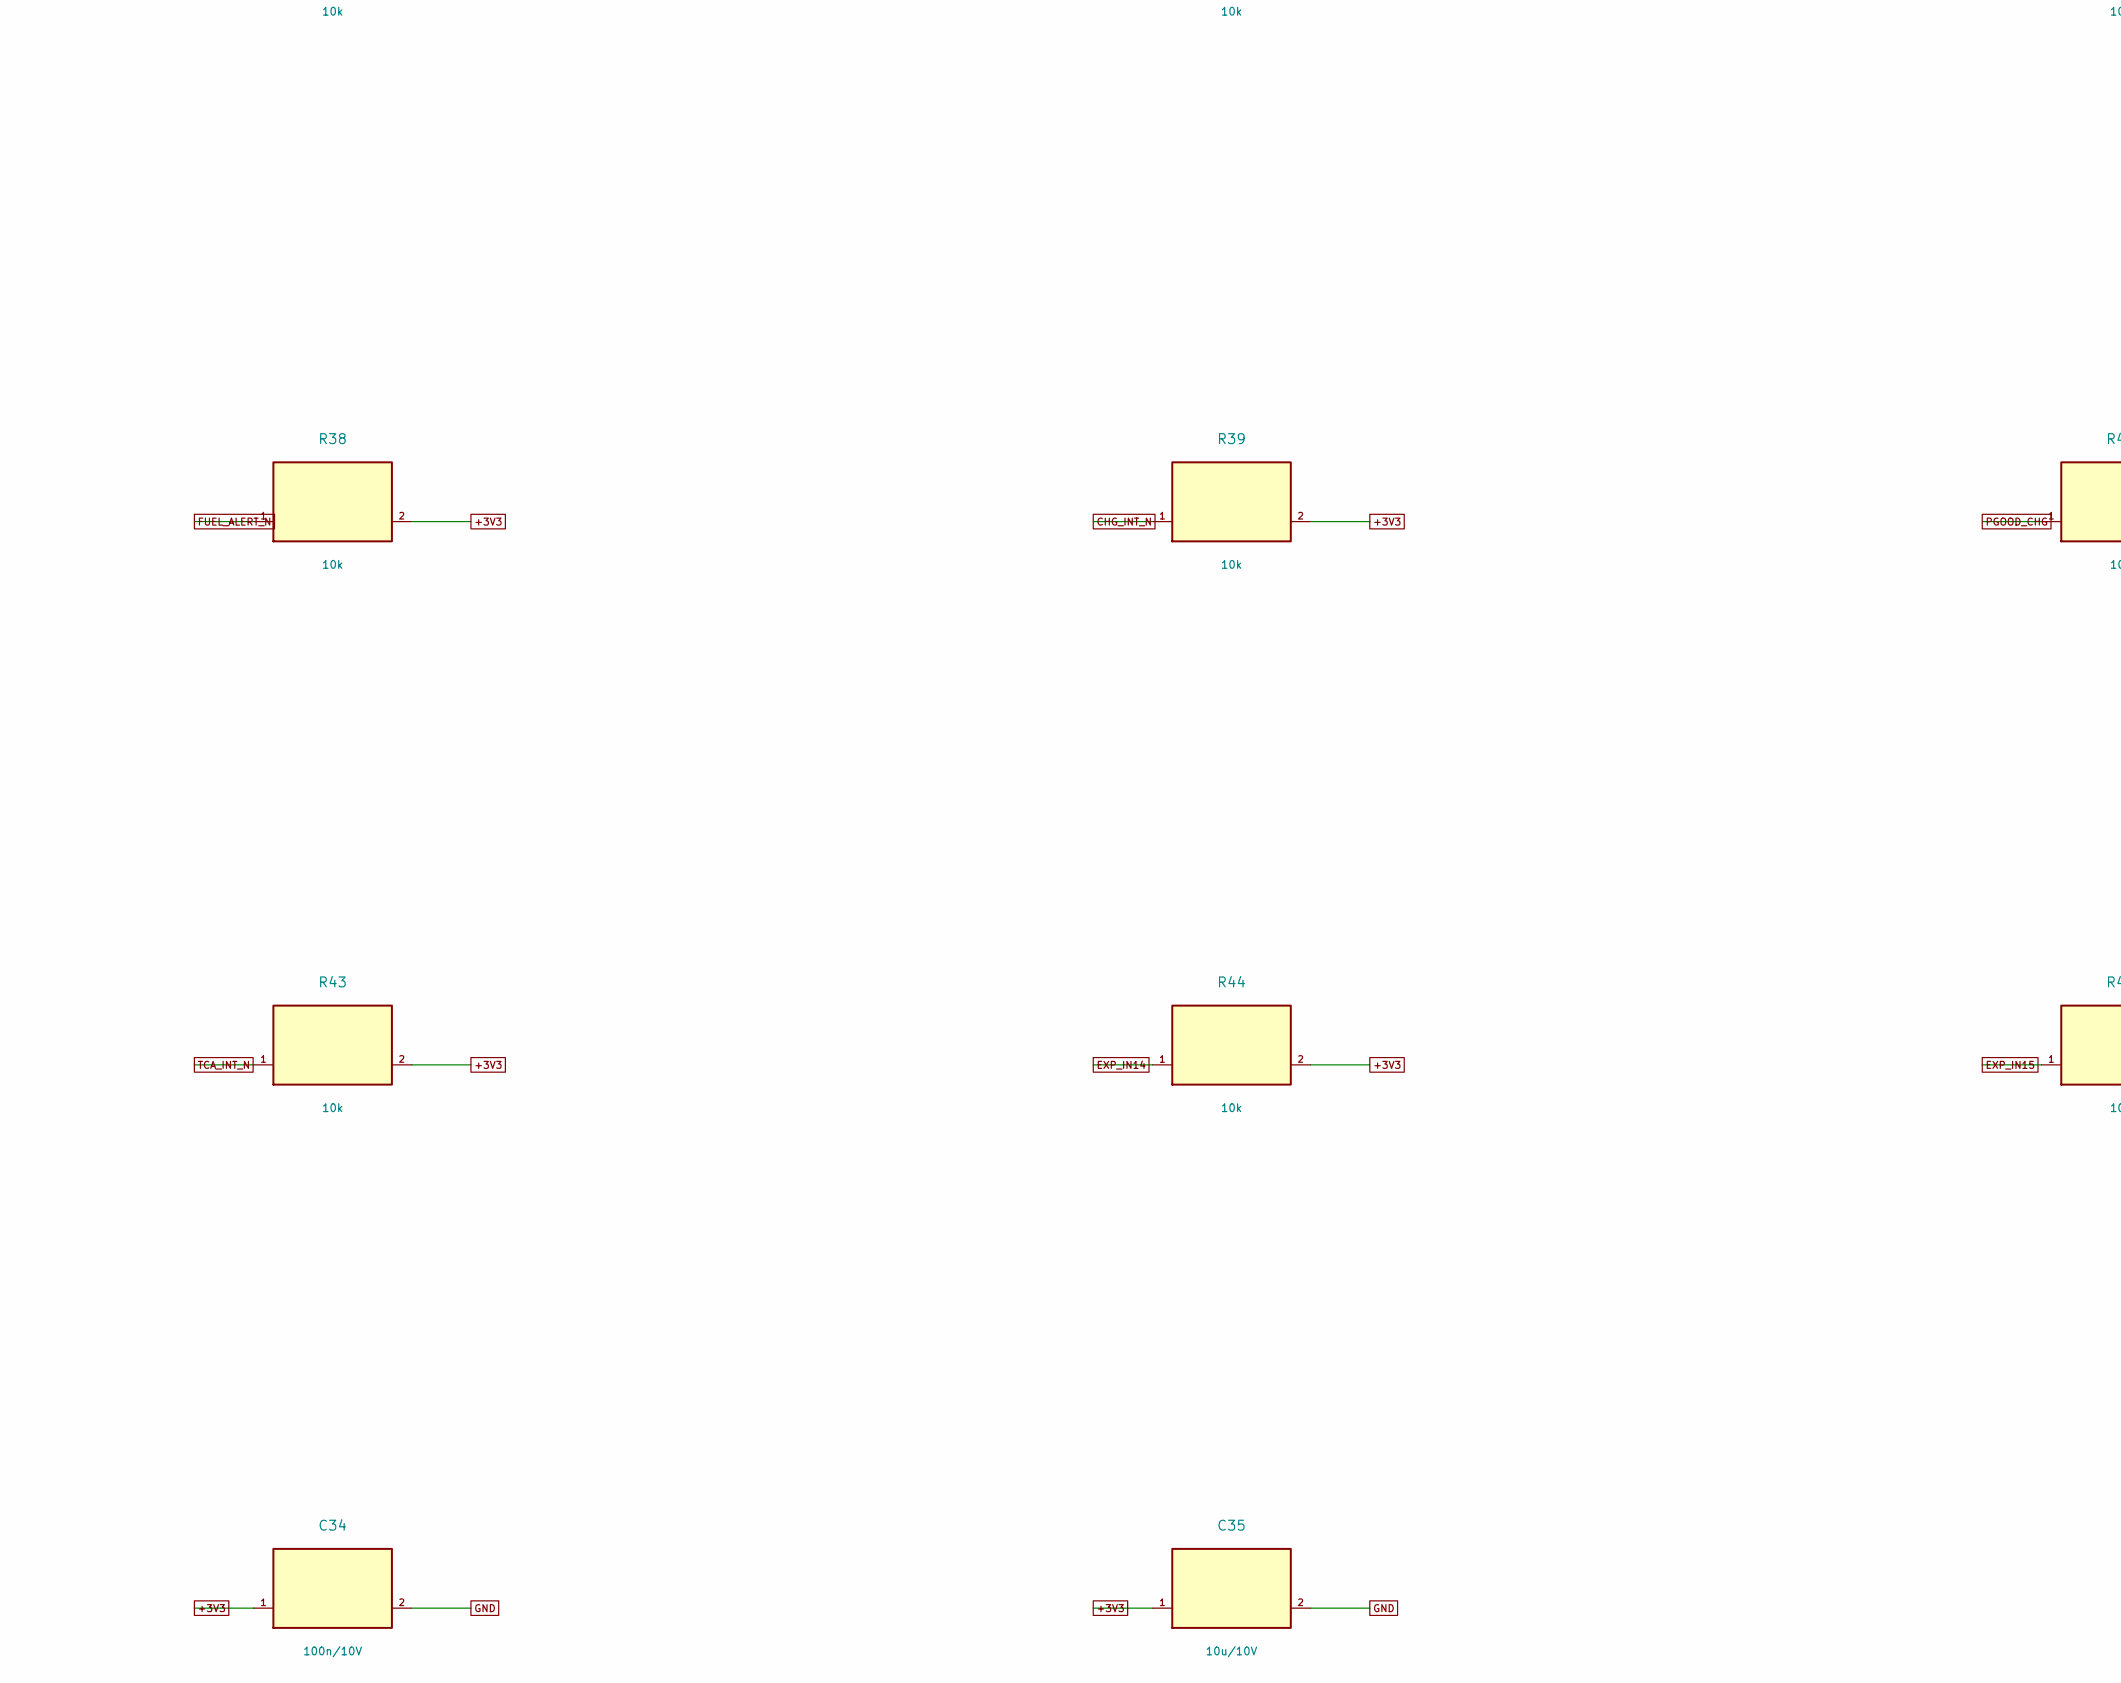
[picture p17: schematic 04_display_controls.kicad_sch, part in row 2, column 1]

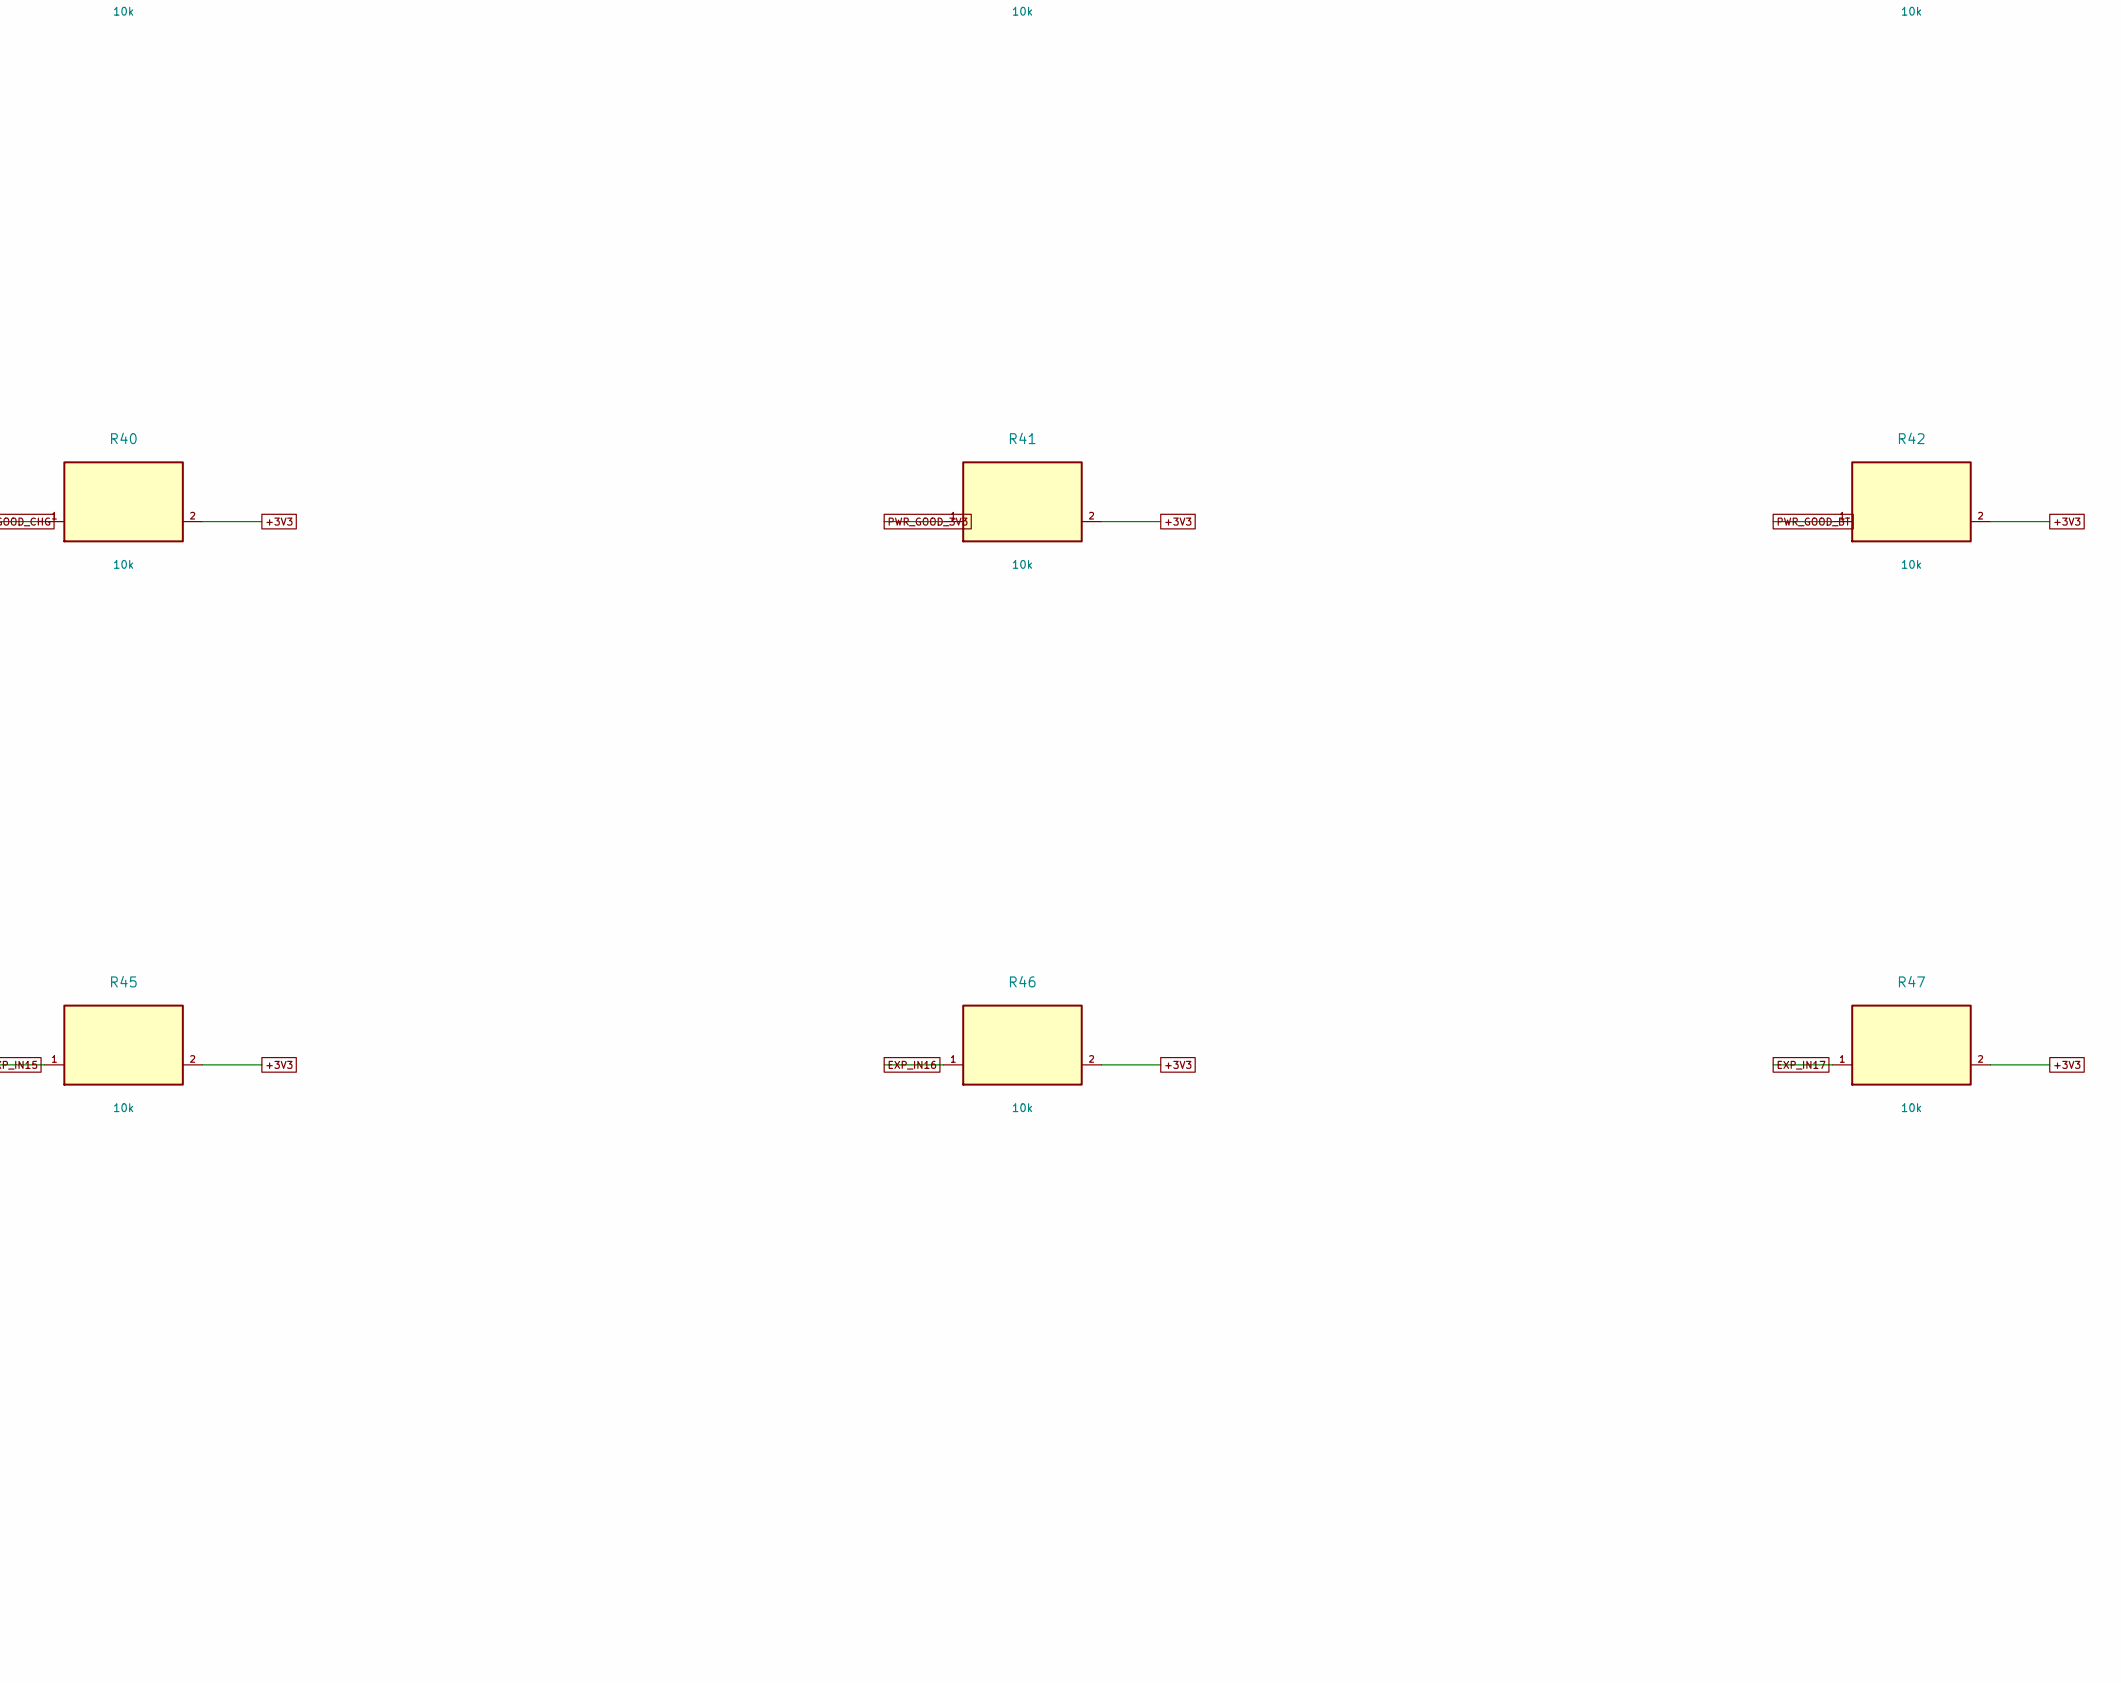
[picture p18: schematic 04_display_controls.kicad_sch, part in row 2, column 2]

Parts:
C34: 100n/10V; C_0805_2012Metric
C35: 10u/10V; C_0805_2012Metric
J7: TFT_24382_HARNESS; JST_GH_SM08B-GHS-TB_1x08-1MP_P1.25mm_Horizontal
R26, R31, R32, R33, R34, R35, R36, R37, R38, R39, R40, R41, R42, R43, R44, R45, R46, R47: 10k; R_0603_1608Metric
SW1: PREV; SW_SPST_TL3342
SW2: PLAY_PAUSE; SW_SPST_TL3342
SW3: NEXT; SW_SPST_TL3342
SW4: VOL_DOWN; SW_SPST_TL3342
SW5: VOL_UP; SW_SPST_TL3342
U11: TCA9535PWR; TSSOP-24_4.4x7.8mm_P0.65mm

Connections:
+3V3: C34.1 (+3V3), C35.1 (+3V3), J7.1, R26.2 (+3V3), R31.2 (+3V3), R32.2 (+3V3), R33.2 (+3V3), R34.2 (+3V3), R35.2 (+3V3), R36.2 (+3V3), R37.2 (+3V3), R38.2 (+3V3), R39.2 (+3V3), R40.2 (+3V3), R41.2 (+3V3), R42.2 (+3V3), R43.2 (+3V3), R44.2 (+3V3), R45.2 (+3V3), R46.2 (+3V3), R47.2 (+3V3), U11.24 (VCC); also elsewhere on the board
BTN_NEXT_N: R33.1 (BTN_NEXT_N), SW3.1, U11.6 (P0_2)
BTN_PLAY_N: R32.1 (BTN_PLAY_N), SW2.1, U11.5 (P0_1)
BTN_PREV_N: R31.1 (BTN_PREV_N), SW1.1, U11.4 (P0_0)
BTN_VOL_DOWN_N: R34.1 (BTN_VOL_DOWN_N), SW4.1, U11.7 (P0_3)
BTN_VOL_UP_N: R35.1 (BTN_VOL_UP_N), SW5.1, U11.8 (P0_4)
CHG_INT_N: R39.1 (CHG_INT_N), U11.13 (P1_0); also elsewhere on the board
CHG_STAT: R37.1 (CHG_STAT), U11.10 (P0_6); also elsewhere on the board
EXP_IN14: R44.1 (EXP_IN14), U11.17 (P1_4)
EXP_IN15: R45.1 (EXP_IN15), U11.18 (P1_5)
EXP_IN16: R46.1 (EXP_IN16), U11.19 (P1_6)
EXP_IN17: R47.1 (EXP_IN17), U11.20 (P1_7)
FUEL_ALERT_N: R38.1 (FUEL_ALERT_N), U11.11 (P0_7); also elsewhere on the board
GND: C34.2 (GND), C35.2 (GND), J7.2, J7.MP (GND), SW1.2, SW2.2, SW3.2, SW4.2, SW5.2, U11.2 (A1), U11.3 (A2), U11.12 (GND), U11.21 (A0); also elsewhere on the board
HP_DETECT: R26.1 (HP_DETECT); also elsewhere on the board
I2C_SCL: U11.22 (SCL); also elsewhere on the board
I2C_SDA: U11.23 (SDA); also elsewhere on the board
PGOOD_CHG: R40.1 (PGOOD_CHG), U11.14 (P1_1); also elsewhere on the board
PWR_GOOD_3V3: R41.1 (PWR_GOOD_3V3), U11.15 (P1_2); also elsewhere on the board
PWR_GOOD_BT: R42.1 (PWR_GOOD_BT), U11.16 (P1_3); also elsewhere on the board
SD_DETECT_N: R36.1 (SD_DETECT_N), U11.9 (P0_5); also elsewhere on the board
TCA_INT_N: R43.1 (TCA_INT_N), U11.1 (INT); also elsewhere on the board
TFT_BL_PWM: J7.8; also elsewhere on the board
TFT_CS: J7.5; also elsewhere on the board
TFT_DC: J7.6; also elsewhere on the board
TFT_MOSI: J7.3; also elsewhere on the board
TFT_RST: J7.7; also elsewhere on the board
TFT_SCLK: J7.4; also elsewhere on the board

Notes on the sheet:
TFT display, input expander and buttons
AI-authored engineering reference. Verify pinout, support values, footprint orientation, lithium safety, RF keepout and assembly before fabrication.

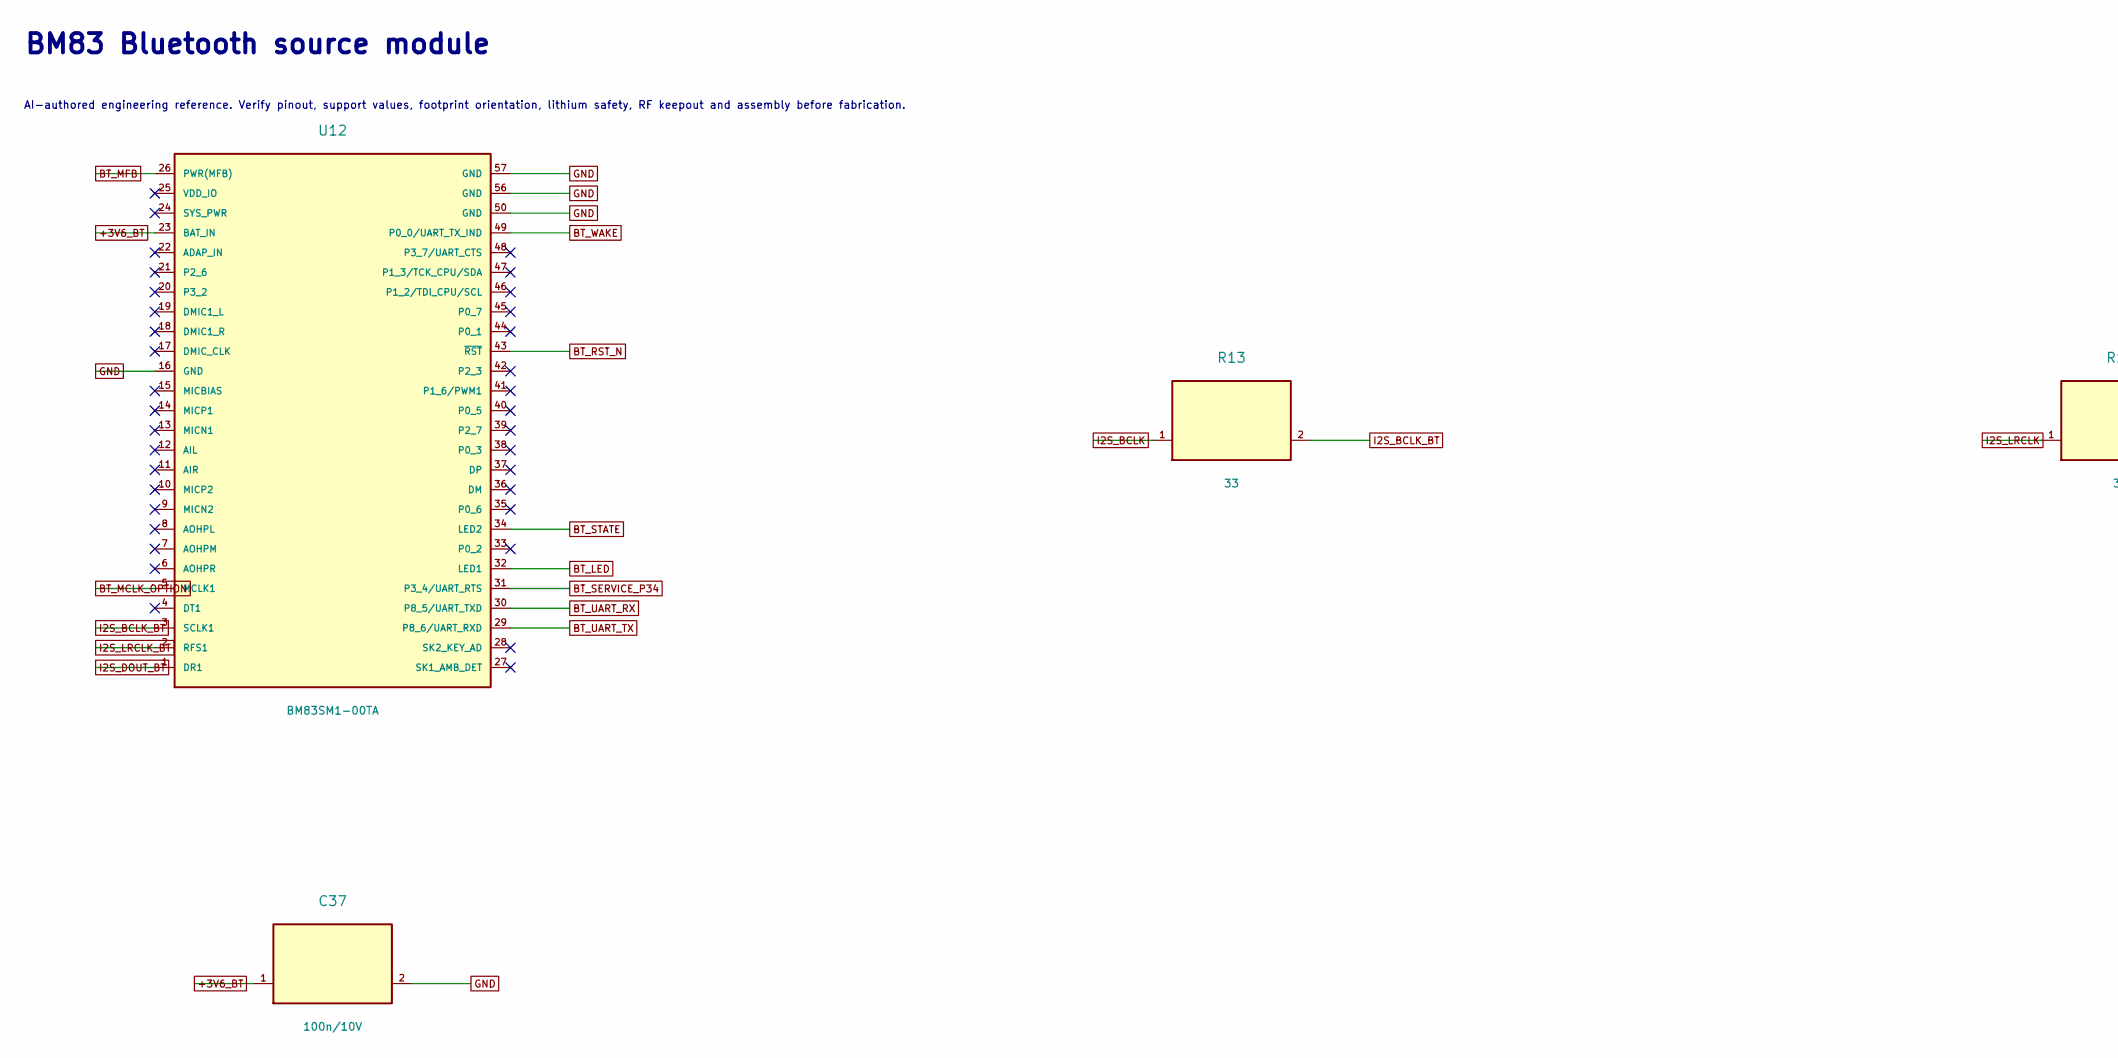
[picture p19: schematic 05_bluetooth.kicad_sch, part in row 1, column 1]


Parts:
C36: 10u/10V; C_0805_2012Metric
C37: 100n/10V; C_0805_2012Metric
R13, R14, R15: 33; R_0603_1608Metric
U12: BM83SM1-00TA; Microchip_BM83_GroundLands

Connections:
+3V6_BT: C36.1 (+3V6_BT), C37.1 (+3V6_BT), U12.23 (BAT_IN); also elsewhere on the board
BT_LED: U12.32 (LED1); also elsewhere on the board
BT_MCLK_OPTION: U12.5 (MCLK1); also elsewhere on the board
BT_MFB: U12.26 (PWR(MFB)); also elsewhere on the board
BT_RST_N: U12.43 (~RST); also elsewhere on the board
BT_SERVICE_P34: U12.31 (P3_4/UART_RTS); also elsewhere on the board
BT_STATE: U12.34 (LED2); also elsewhere on the board
BT_UART_RX: U12.30 (P8_5/UART_TXD); also elsewhere on the board
BT_UART_TX: U12.29 (P8_6/UART_RXD); also elsewhere on the board
BT_WAKE: U12.49 (P0_0/UART_TX_IND); also elsewhere on the board
GND: C36.2 (GND), C37.2 (GND), U12.16 (GND), U12.50 (GND), U12.56 (GND), U12.57 (GND); also elsewhere on the board
I2S_BCLK: R13.1 (I2S_BCLK); also elsewhere on the board
I2S_BCLK_BT: R13.2 (I2S_BCLK_BT), U12.3 (SCLK1)
I2S_DOUT: R15.1 (I2S_DOUT); also elsewhere on the board
I2S_DOUT_BT: R15.2 (I2S_DOUT_BT), U12.1 (DR1)
I2S_LRCLK: R14.1 (I2S_LRCLK); also elsewhere on the board
I2S_LRCLK_BT: R14.2 (I2S_LRCLK_BT), U12.2 (RFS1)

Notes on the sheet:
BM83 Bluetooth source module
AI-authored engineering reference. Verify pinout, support values, footprint orientation, lithium safety, RF keepout and assembly before fabrication.

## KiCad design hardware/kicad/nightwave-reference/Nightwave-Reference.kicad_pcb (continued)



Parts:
J8: UART0_SERVICE; PinHeader_1x06_P2.54mm_Vertical
SW6: MAIN_POWER; SW_SPDT_PCM12
TP1: VBUS5; TestPoint_Pad_D1.0mm
TP2: BAT; TestPoint_Pad_D1.0mm
TP3: SYS; TestPoint_Pad_D1.0mm
TP4: VSYS_SW; TestPoint_Pad_D1.0mm
TP5: +3V3; TestPoint_Pad_D1.0mm
TP6: +3V6_BT; TestPoint_Pad_D1.0mm
TP7: I2C_SDA; TestPoint_Pad_D1.0mm
TP8: I2C_SCL; TestPoint_Pad_D1.0mm
TP9: I2S_BCLK; TestPoint_Pad_D1.0mm
TP10: I2S_LRCLK; TestPoint_Pad_D1.0mm
TP11: I2S_DOUT; TestPoint_Pad_D1.0mm
TP12: GND; TestPoint_Pad_D1.0mm
TP13: BT_SERVICE_P34; TestPoint_Pad_D1.0mm
TP14: BT_LED; TestPoint_Pad_D1.0mm
TP15: BT_STATE; TestPoint_Pad_D1.0mm
TP16: HP_DETECT; TestPoint_Pad_D1.0mm

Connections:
+3V3: J8.1, TP5.1; also elsewhere on the board
+3V6_BT: TP6.1; also elsewhere on the board
BAT: TP2.1; also elsewhere on the board
BOOT_N: J8.6; also elsewhere on the board
BT_LED: TP14.1; also elsewhere on the board
BT_SERVICE_P34: TP13.1; also elsewhere on the board
BT_STATE: TP15.1; also elsewhere on the board
ESP_EN: J8.5; also elsewhere on the board
GND: J8.2, SW6.1 (A), TP12.1; also elsewhere on the board
HP_DETECT: TP16.1; also elsewhere on the board
I2C_SCL: TP8.1; also elsewhere on the board
I2C_SDA: TP7.1; also elsewhere on the board
I2S_BCLK: TP9.1; also elsewhere on the board
I2S_DOUT: TP11.1; also elsewhere on the board
I2S_LRCLK: TP10.1; also elsewhere on the board
PWR_SWITCH_ON: SW6.2 (B); also elsewhere on the board
SYS: SW6.3 (C), TP3.1; also elsewhere on the board
UART0_RX: J8.4; also elsewhere on the board
UART0_TX: J8.3; also elsewhere on the board
VBUS5: TP1.1; also elsewhere on the board
VSYS_SW: TP4.1; also elsewhere on the board

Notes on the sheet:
Service connectors, power switch and test points
AI-authored engineering reference. Verify pinout, support values, footprint orientation, lithium safety, RF keepout and assembly before fabrication.


Board: 4 copper layers, 110.0 x 100.0 mm, 135 parts (0 on the bottom side), 104 nets.

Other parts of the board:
H1, H2, H3: M2_NPTH_NYLON_HARDWARE; MountingHole_2.2mm_M2

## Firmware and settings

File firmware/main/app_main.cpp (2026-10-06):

#include <algorithm>
#include <array>
#include <cmath>
#include <cstdio>
#include <cstdlib>
#include <cstring>

#include "esp_log.h"
#include "freertos/FreeRTOS.h"
#include "freertos/task.h"
#include "freertos/semphr.h"
#include "esp_timer.h"

#include "nightwave/audio_sink.h"
#include "nightwave/button_monitor.h"
#include "nightwave/diagnostics.h"
#include "nightwave/hardware_config.h"
#include "nightwave/storage.h"
#include "nightwave/streaming_player.h"
#include "nightwave/player_frontend.h"
#include "nightwave/engineering_report.h"
#include "nightwave/bluetooth_source.h"
#include "nightwave/power_hal.h"
#include "nightwave/power_i2c.h"
#include "nightwave/board_i2c.h"
#include "nightwave/bm83_at_codec.h"
#include "nightwave/runtime_recorder.h"
#include "esp_heap_caps.h"
#include "nightwave/st7789_spi.h"

namespace {

constexpr char kTag[] = "nightwave";
constexpr float kPi = 3.14159265358979323846F;

nightwave::SdStorage g_storage;
nightwave::I2sAudioSink g_audio;
nightwave::StreamingPlayer g_player;
nightwave::ButtonMonitor g_buttons;
#if defined(CONFIG_NIGHTWAVE_REFERENCE_BOARD) && CONFIG_NIGHTWAVE_REFERENCE_BOARD
nightwave::St7789Spi g_tft_bus;
nightwave::St7789Display g_tft(g_tft_bus);
nightwave::PlayerFrontend g_frontend(g_storage, g_player, g_audio, g_buttons, "/sdcard", &g_tft);
#else
nightwave::PlayerFrontend g_frontend(g_storage, g_player, g_audio, g_buttons);
#endif
SemaphoreHandle_t g_commands = nullptr;
nightwave::UnavailableBluetooth g_bluetooth_backend;
nightwave::BluetoothSource g_bluetooth(g_bluetooth_backend);
#if defined(CONFIG_NIGHTWAVE_REFERENCE_BOARD) && CONFIG_NIGHTWAVE_REFERENCE_BOARD
nightwave::PowerI2c g_power_bus;
nightwave::ReferencePower g_power(g_power_bus);
#else
nightwave::UnavailablePower g_power;
#endif
nightwave::RuntimeRecorder g_runtime;
std::uint64_t g_runtime_sampled_ms = 0, g_runtime_reported_ms = 0;

nightwave::RuntimeObservation runtime_observation() {
    nightwave::RuntimeObservation o;
    o.monotonic_ms = static_cast<std::uint64_t>(esp_timer_get_time() / 1000);
    o.media_frames = g_player.media_frames_accepted();
    o.errors = g_player.lifetime_errors(); o.underruns = g_player.lifetime_underruns();
    o.sample_rate_hz = g_player.playback_rate_hz();
    o.playing = g_player.playing(); o.paused = g_player.paused();
    const auto route = g_player.requested_output();
    o.route = route == nightwave::OutputPath::kSpeaker ? nightwave::RuntimeRoute::kSpeaker :
        route == nightwave::OutputPath::kLine ? nightwave::RuntimeRoute::kWired : nightwave::RuntimeRoute::kMuted;
    o.volume = g_player.requested_volume();
    o.power = g_power.sample(static_cast<std::uint32_t>(o.monotonic_ms));
    // Readable registers do not qualify the pack, model, or physical audio route.
    return o;
}
void print_runtime() {
    std::array<char, 768> json{};
    if (nightwave::format_runtime_report(g_runtime.summary(), json.data(), json.size())) std::puts(json.data());
}
void runtime_tick() {
    if (!g_runtime.summary().active) return;
    const auto now = static_cast<std::uint64_t>(esp_timer_get_time() / 1000);
    if (now < g_runtime_sampled_ms || now - g_runtime_sampled_ms >= 1000) {
        g_runtime.observe(runtime_observation()); g_runtime_sampled_ms = now;
    }
    if (!g_runtime.summary().active || now - g_runtime_reported_ms >= 60000) {
        print_runtime(); g_runtime_reported_ms = now;
    }
}

void ui_task(void*) {
    while (true) {
        if (xSemaphoreTake(g_commands, pdMS_TO_TICKS(10)) == pdTRUE) {
            g_frontend.tick(static_cast<std::uint32_t>(esp_timer_get_time() / 1000));
            runtime_tick();
            xSemaphoreGive(g_commands);
        }
        vTaskDelay(pdMS_TO_TICKS(25));
    }
}

static_assert(nightwave::hardware::pins_are_unique(),
              "Nightwave GPIO assignments must be unique");
static_assert(nightwave::hardware::pins_avoid_restricted_set(),
              "Nightwave GPIO assignments overlap a restricted ESP32-S3 pin");

nightwave::OutputPath parse_output(const char* value) {
    if (value != nullptr && std::strcmp(value, "speaker") == 0) {
        return nightwave::OutputPath::kSpeaker;
    }
    if (value != nullptr && std::strcmp(value, "line") == 0) {
        return nightwave::OutputPath::kLine;
    }
    return nightwave::OutputPath::kMuted;
}

void print_help() {
    std::printf(
        "\nNightwave diagnostics\n"
        "  board                         boot/heap/PSRAM report\n"
        "  sd                            mount + enumerate WAV/MP3\n"
        "  bench [absolute-path]         SD average/worst read report\n"
        "  tone <speaker|line> [hz]      2 s low-level diagnostic tone\n"
        "  play <speaker|line> <path>    buffered WAV/MP3 playback\n"
        "  pause | resume                pause/resume buffered playback\n"
        "  volume <0..100>               ramped digital volume\n"
        "  stop                          stop playback and mute outputs\n"
        "  status                        queue/underrun/error counters\n"
        "  power                         read-only gauge/charger diagnostics\n"
        "  mode <normal|shuffle|all|track> playback sequence mode\n"
        "  sleep <off|15|30|45|60|end>    ramp/stop/display sleep timer\n"
        "  seek <milliseconds>           WAV seek / indexed MP3 with safe fallback\n"
        "  last                          explicit saved-track resume\n"
        "  selftest                      JSON software/hardware availability\n"
        "  engineering                   bounded JSON library/seek/memory telemetry\n"
        "  runtime <start|stop|status>    sampled runtime log; never physical certification\n"
        "  help                          show this text\n\n");
}

void run_tone(nightwave::OutputPath output, float frequency_hz) {
    if (!std::isfinite(frequency_hz) || frequency_hz < 20.0F ||
        frequency_hz > 20000.0F) {
        ESP_LOGE(kTag, "tone frequency must be finite and between 20 and 20000 Hz");
        return;
    }
    if (output == nightwave::OutputPath::kMuted || g_player.playing()) {
        ESP_LOGE(kTag, "tone requires speaker|line and idle playback");
        return;
    }
    nightwave::AudioFormat format{44100, 2, 16};
    if (g_audio.configure(format) != nightwave::AudioSinkStatus::kAccepted) {
        ESP_LOGE(kTag, "tone I2S setup failed");
        return;
    }
    if (!g_audio.select_output(output)) {
        g_audio.stop();
        return;
    }
    constexpr std::size_t kFrames = 256;
    constexpr std::int16_t kPeak = 1200;
    std::array<std::int16_t, kFrames * 2> pcm{};
    std::uint64_t frame_index = 0;
    const std::uint64_t total_frames = format.sample_rate_hz * 2ULL;
    ESP_LOGI(kTag, "TONE START hz=%.1f peak=%d duration_ms=2000", frequency_hz,
             kPeak);
    while (frame_index < total_frames) {
        const auto frames = static_cast<std::size_t>(
            std::min<std::uint64_t>(kFrames, total_frames - frame_index));
        for (std::size_t index = 0; index < frames; ++index) {
            const float phase = 2.0F * kPi * frequency_hz *
                                static_cast<float>(frame_index + index) /
                                static_cast<float>(format.sample_rate_hz);
            float envelope = 1.0F;
            const auto absolute = frame_index + index;
            constexpr std::uint64_t kRampFrames = 2205;
            if (absolute < kRampFrames) {
                envelope = static_cast<float>(absolute) / kRampFrames;
            } else if (total_frames - absolute < kRampFrames) {
                envelope = static_cast<float>(total_frames - absolute) /
                           kRampFrames;
            }
            const auto sample = static_cast<std::int16_t>(
                std::sin(phase) * envelope * kPeak);
            pcm[index * 2] = sample;
            pcm[index * 2 + 1] = sample;
        }
        nightwave::PcmBlock block{pcm.data(), frames, format, frame_index};
        if (g_audio.write(block) != nightwave::AudioSinkStatus::kAccepted) {
            ESP_LOGE(kTag, "tone write failed");
            break;
        }
        frame_index += frames;
    }
    pcm.fill(0);
    nightwave::PcmBlock silence{pcm.data(), kFrames, format, frame_index};
    if (g_audio.write(silence) != nightwave::AudioSinkStatus::kAccepted ||
        g_audio.drain() != nightwave::AudioSinkStatus::kAccepted) {
        ESP_LOGE(kTag, "tone silence/drain failed");
    }
    g_audio.stop();
    ESP_LOGI(kTag, "TONE STOP output=muted");
}

void execute_command(char* line) {
    char* context = nullptr;
    const char* command = strtok_r(line, " \r\n", &context);
    if (command == nullptr) return;
    if (std::strcmp(command, "help") == 0) {
        print_help();
    } else if (std::strcmp(command, "board") == 0) {
        nightwave::log_boot_diagnostics();
    } else if (std::strcmp(command, "sd") == 0) {
        if (g_storage.mount()) g_storage.enumerate_supported_files();
    } else if (std::strcmp(command, "bench") == 0) {
        const char* path = strtok_r(nullptr, " \r\n", &context);
        if (path == nullptr) path = "/sdcard/02_left_right_stereo_44100.wav";
        if (g_storage.mount()) g_storage.benchmark(path);
    } else if (std::strcmp(command, "tone") == 0) {
        const auto output = parse_output(strtok_r(nullptr, " \r\n", &context));
        const char* frequency = strtok_r(nullptr, " \r\n", &context);
        run_tone(output,
                 frequency == nullptr ? 440.0F : std::strtof(frequency, nullptr));
    } else if (std::strcmp(command, "wav") == 0 || std::strcmp(command, "play") == 0) {
        const auto output = parse_output(strtok_r(nullptr, " \r\n", &context));
        const char* path = strtok_r(nullptr, "\r\n", &context);
        while (path != nullptr && *path == ' ') ++path;
        g_frontend.stopped(); // Console playback has no folder auto-advance queue.
        if (output == nightwave::OutputPath::kMuted || path == nullptr ||
            !g_storage.mount() || !g_player.start(path, g_audio, output, 8)) {
            ESP_LOGE(kTag, "usage: play <speaker|line> </sdcard/file.wav|mp3>");
        } else {
            g_frontend.track_started(path);
        }
    } else if (std::strcmp(command, "pause") == 0) {
        g_player.pause(true);
    } else if (std::strcmp(command, "resume") == 0) {
        g_player.pause(false);
    } else if (std::strcmp(command, "volume") == 0) {
        const char* value = strtok_r(nullptr, " \r\n", &context);
        std::uint32_t volume = 0;
        if (nightwave::parse_unsigned(value, 100, volume)) g_frontend.volume(static_cast<std::uint8_t>(volume), static_cast<std::uint32_t>(esp_timer_get_time() / 1000));
        else ESP_LOGW(kTag, "volume requires an integer 0..100");
    } else if (std::strcmp(command, "stop") == 0) {
        g_frontend.stopped();
        if (!g_player.stop()) {
            ESP_LOGW(kTag, "stop still pending; retain hardware and retry status/stop");
        }
    } else if (std::strcmp(command, "last") == 0) {
        if (!g_storage.mount() || !g_frontend.resume_saved()) ESP_LOGW(kTag, "saved-track resume unavailable/invalid");
    } else if (std::strcmp(command, "seek") == 0) {
        const char* value = strtok_r(nullptr, " \r\n", &context);
        std::uint32_t position = 0;
        if (!nightwave::parse_unsigned(value, 1800000, position) || !g_frontend.seek_current(position)) ESP_LOGW(kTag, "seek requires 0..1800000 ms and an active queue track");
    } else if (std::strcmp(command, "mode") == 0) {
        const char* value = strtok_r(nullptr, " \r\n", &context);
        if (value) {
            const char* names[] = {"normal", "shuffle", "all", "track"};
            for (unsigned i = 0; i < 4; ++i) if (!std::strcmp(value, names[i])) g_frontend.mode(static_cast<nightwave::PlaybackMode>(i), static_cast<std::uint32_t>(esp_timer_get_time() / 1000));
        }
    } else if (std::strcmp(command, "sleep") == 0) {
        const char* value = strtok_r(nullptr, " \r\n", &context);
        if (value) {
            const char* names[] = {"off", "15", "30", "45", "60", "end"};
            for (unsigned i = 0; i < 6; ++i) if (!std::strcmp(value, names[i])) g_frontend.sleep_timer(static_cast<nightwave::SleepMode>(i), static_cast<std::uint32_t>(esp_timer_get_time() / 1000));
        }
    } else if (std::strcmp(command, "runtime") == 0) {
        const char* action = strtok_r(nullptr, " \r\n", &context);
        if (action && std::strcmp(action, "start") == 0) {
            const auto observation = runtime_observation();
            if (!g_runtime.begin(observation)) {
                ESP_LOGW(kTag, "runtime start requires active, nonzero-volume playback and no active recorder");
            } else {
                g_runtime_sampled_ms = g_runtime_reported_ms = observation.monotonic_ms;
                print_runtime();
            }
        } else if (action && std::strcmp(action, "stop") == 0) {
            g_runtime.stop(runtime_observation()); print_runtime();
        } else if (action && std::strcmp(action, "status") == 0) {
            g_runtime.observe(runtime_observation()); print_runtime();
            g_runtime_sampled_ms = static_cast<std::uint64_t>(esp_timer_get_time() / 1000);
        } else ESP_LOGW(kTag, "usage: runtime <start|stop|status>");
    } else if (std::strcmp(command, "selftest") == 0) {
        std::printf("{\"type\":\"nightwave_selftest\",\"schema\":1,\"gpio_map_unique\":%s,\"storage_mounted\":%s,\"bluetooth\":\"BM83SM1-00TA_backend_unqualified\",\"battery\":\"unmeasured\",\"acoustic_output\":\"unverified\",\"physical_pass\":false}\n",
            nightwave::hardware::pins_are_unique() ? "true" : "false", g_storage.mount() ? "true" : "false");
    } else if (std::strcmp(command, "engineering") == 0) {
        nightwave::EngineeringReport report;
        report.stream = g_player.telemetry(); report.position_ms = g_player.position_ms();
        report.catalog_tracks = g_frontend.catalog_tracks(); report.query_reads = g_frontend.catalog_query_reads();
        report.catalog_building = g_frontend.catalog_building(); report.catalog_fast = g_frontend.catalog_fast_lookup();
        report.heap_free = heap_caps_get_free_size(MALLOC_CAP_INTERNAL | MALLOC_CAP_8BIT);
        report.heap_min = heap_caps_get_minimum_free_size(MALLOC_CAP_INTERNAL | MALLOC_CAP_8BIT);
        report.psram_free = heap_caps_get_free_size(MALLOC_CAP_SPIRAM | MALLOC_CAP_8BIT);
        std::array<char, 1024> json{};
        if (nightwave::format_engineering_report(report, json.data(), json.size())) std::puts(json.data());
    } else if (std::strcmp(command, "power") == 0) {
        const auto p=g_power.sample(static_cast<std::uint32_t>(esp_timer_get_time()/1000));
        std::printf("{\"type\":\"nightwave_power\",\"schema\":1,\"voltage_valid\":%s,\"battery_mv\":%u,\"soc_valid\":%s,\"soc_estimate_percent\":%u,\"charging_valid\":%s,\"charging\":%s,\"source\":%u,\"physically_qualified\":false}\n",
            p.voltage_valid?"true":"false",unsigned(p.state.battery_millivolts),
            p.charge_percent_valid?"true":"false",unsigned(p.state.state_of_charge_percent),
            p.charging_valid?"true":"false",p.state.charging?"true":"false",unsigned(p.state.source));
#if defined(CONFIG_NIGHTWAVE_REFERENCE_BOARD) && CONFIG_NIGHTWAVE_REFERENCE_BOARD
        const auto d=g_power.diagnostic();
        std::printf("{\"type\":\"nightwave_charger_registers\",\"valid\":%s,\"status0\":%u,\"status1\":%u,\"faults\":%u,\"charge_limit_ma\":%u,\"voltage_limit_mv\":%u,\"input_register_limit_ma\":%u,\"charge_configuration_approved\":false}\n",
            d.valid?"true":"false",unsigned(d.status0),unsigned(d.status1),unsigned(d.faults),
            unsigned(d.charge_limit_ma),unsigned(d.voltage_limit_mv),unsigned(d.input_limit_ma));
#endif
    } else if (std::strcmp(command, "status") == 0) {
        const auto status = nightwave::capture_diagnostics(
            g_player.underruns(), g_storage.errors(), g_player.errors(),
            g_player.queue_depth_ms());
        ESP_LOGI(kTag,
                 "STATUS playing=%d queue_ms=%lu underruns=%lu storage_errors=%lu decode_errors=%lu heap_min=%lu",
                 g_player.playing(),
                 static_cast<unsigned long>(status.pcm_queue_depth_ms),
                 static_cast<unsigned long>(status.audio_underruns),
                 static_cast<unsigned long>(status.storage_errors),
                 static_cast<unsigned long>(status.decode_errors),
                 static_cast<unsigned long>(status.minimum_free_heap_bytes));
        const auto t = g_player.telemetry();
        std::printf("{\"type\":\"nightwave_stream\",\"schema\":1,\"position_ms\":%lu,\"pcm_ms\":%lu,\"encoded_bytes\":%lu,\"underruns\":%lu,\"errors\":%lu,\"sd_worst_us\":%lu,\"decode_worst_us\":%lu,\"bluetooth\":\"BM83_backend_unqualified\",\"battery\":null}\n",
            static_cast<unsigned long>(g_player.position_ms()), static_cast<unsigned long>(t.pcm_ms), static_cast<unsigned long>(t.compressed_bytes),
            static_cast<unsigned long>(t.underruns), static_cast<unsigned long>(t.errors), static_cast<unsigned long>(t.sd_worst_us), static_cast<unsigned long>(t.decoder_worst_us));
        std::printf("{\"type\":\"nightwave_performance\",\"schema\":1,\"sd_bytes\":%lu,\"sd_reads\":%lu,\"sd_total_us\":%lu,\"decode_calls\":%lu,\"decode_total_us\":%lu,\"encoded_low_bytes\":%lu,\"pcm_low_frames\":%lu,\"stack_min_bytes\":[%lu,%lu,%lu]}\n",
            static_cast<unsigned long>(t.sd_bytes), static_cast<unsigned long>(t.sd_reads), static_cast<unsigned long>(t.sd_total_us),
            static_cast<unsigned long>(t.decode_calls), static_cast<unsigned long>(t.decode_total_us), static_cast<unsigned long>(t.encoded_low_bytes),
            static_cast<unsigned long>(t.pcm_low_frames), static_cast<unsigned long>(t.storage_stack_bytes), static_cast<unsigned long>(t.decoder_stack_bytes), static_cast<unsigned long>(t.audio_stack_bytes));
        ESP_LOGI(kTag, "STREAM compressed=%lu sd_worst_us=%lu decode_worst_us=%lu stack_min_bytes=%lu/%lu/%lu",
            static_cast<unsigned long>(t.compressed_bytes), static_cast<unsigned long>(t.sd_worst_us),
            static_cast<unsigned long>(t.decoder_worst_us), static_cast<unsigned long>(t.storage_stack_bytes),
            static_cast<unsigned long>(t.decoder_stack_bytes), static_cast<unsigned long>(t.audio_stack_bytes));
    } else {
        ESP_LOGW(kTag, "unknown command: %s", command);
        print_help();
    }
}

}  // namespace

extern "C" void app_main() {
    ESP_LOGW(kTag, "Board profile: %s; hardware remains unqualified", nightwave::hardware::kReferenceBoard ? "REFERENCE PCB / TFT / TCA9535" : "LEGACY BENCH / OLED / GPIO buttons");
    g_audio.initialize_safe_outputs();
    if (!nightwave::prepare_board_i2c()) ESP_LOGE(kTag, "shared I2C unavailable; devices will retry");
    nightwave::log_boot_diagnostics();
    if (!g_buttons.start()) ESP_LOGE(kTag, "button monitor failed to start");
    if (!g_storage.mount()) {
        ESP_LOGW(kTag, "SD unavailable; console and button diagnostics remain active");
    } else {
        g_storage.enumerate_supported_files();
    }
    print_help();
    g_commands = xSemaphoreCreateMutex();
    if (!g_commands) { ESP_LOGE(kTag, "command mutex unavailable"); return; }
    g_frontend.initialize();
    if (xTaskCreate(ui_task, "UiTask", 6144, nullptr, 3, nullptr) != pdPASS)
        ESP_LOGE(kTag, "UI task unavailable; console remains active");

    std::array<char, 256> line{};
    bool discard_line = false;
    while (true) {
        std::printf("nightwave> ");
        std::fflush(stdout);
        if (std::fgets(line.data(), line.size(), stdin) != nullptr) {
            const bool terminated = std::strchr(line.data(), '\n') != nullptr;
            if (discard_line) { discard_line = !terminated; continue; }
            if (!terminated) { discard_line = true; ESP_LOGW(kTag, "overlong/incomplete command discarded"); continue; }
            xSemaphoreTake(g_commands, portMAX_DELAY);
            execute_command(line.data());
            xSemaphoreGive(g_commands);
        } else {
            clearerr(stdin);
            vTaskDelay(pdMS_TO_TICKS(100));
        }
    }
}

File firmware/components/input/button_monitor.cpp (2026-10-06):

#include "nightwave/button_monitor.h"
#include "nightwave/button_gestures.h"
#include "nightwave/hardware_config.h"
#include "nightwave/tca9535_i2c.h"
#include "nightwave/board_i2c.h"
#include "driver/gpio.h"
#include "esp_log.h"
#include "esp_timer.h"
#include "freertos/FreeRTOS.h"
#include "freertos/task.h"
#include "freertos/queue.h"

namespace nightwave {
namespace {
constexpr char kTag[] = "buttons";
#if defined(CONFIG_NIGHTWAVE_REFERENCE_BOARD) && CONFIG_NIGHTWAVE_REFERENCE_BOARD
Tca9535I2c bus;
Tca9535Input expander(bus);
bool attached = false;
bool initialize_source() {
    if (!attached) {
        const auto shared=reference_i2c_device(reference_board::kTcaAddress);
        if (!shared || !bus.attach_borrowed(shared)) return false;
        attached=true;
    }
    return expander.initialize();
}
bool sample_source(std::uint8_t& pressed) {
    Tca9535Sample value{};
    if (!expander.poll(value)) return false;
    pressed = static_cast<std::uint8_t>(~value.raw_levels & 0x1f);
    return true;
}
#else
constexpr std::array<std::int8_t, 5> pins{hardware::kButtonPrevious,
    hardware::kButtonPlayPause, hardware::kButtonNext,
    hardware::kButtonVolumeDown, hardware::kButtonVolumeUp};
bool initialize_source() {
    gpio_config_t cfg{};
    for (const auto pin : pins) cfg.pin_bit_mask |= (1ULL << pin);
    cfg.mode = GPIO_MODE_INPUT; cfg.pull_up_en = GPIO_PULLUP_ENABLE;
    cfg.pull_down_en = GPIO_PULLDOWN_DISABLE; cfg.intr_type = GPIO_INTR_DISABLE;
    return gpio_config(&cfg) == ESP_OK;
}
bool sample_source(std::uint8_t& pressed) {
    pressed = 0;
    for (std::size_t i = 0; i < pins.size(); ++i)
        if (!gpio_get_level(static_cast<gpio_num_t>(pins[i]))) pressed |= (1U << i);
    return true;
}
#endif
} // namespace

bool ButtonMonitor::start() {
    if (task_handle_) return true;
    queue_ = xQueueCreate(16, sizeof(ButtonEvent));
    if (!queue_) return false;
    TaskHandle_t handle = nullptr;
    if (xTaskCreate(task_entry, "InputTask", 4096, this, 4, &handle) != pdPASS) {
        vQueueDelete(static_cast<QueueHandle_t>(queue_)); queue_ = nullptr; return false;
    }
    task_handle_ = handle;
    return true; // Task exists; source readiness can recover independently.
}
bool ButtonMonitor::poll(ButtonEvent& event) {
    return queue_ && xQueueReceive(static_cast<QueueHandle_t>(queue_), &event, 0) == pdTRUE;
}
void ButtonMonitor::task_entry(void* context) { static_cast<ButtonMonitor*>(context)->task(); }
void ButtonMonitor::task() {
    ButtonGestures gestures;
    bool ready = false;
    const auto emit = [this](const ButtonEvent& event) {
        if (xQueueSend(static_cast<QueueHandle_t>(queue_), &event, 0) != pdTRUE)
            ESP_LOGW(kTag, "button queue full: gesture dropped");
    };
    while (true) {
        if (!ready) {
            gestures.invalidate();
            ready = initialize_source();
            if (!ready) {
                ESP_LOGW(kTag, "input source unavailable; retrying in 1 second");
                vTaskDelay(pdMS_TO_TICKS(1000)); continue;
            }
            ESP_LOGI(kTag, "input source ready: %s", hardware::kReferenceBoard ? "TCA9535 0x20 P0.0..4" : "legacy GPIO");
        }
        std::uint8_t pressed = 0;
        if (sample_source(pressed)) {
            gestures.sample(pressed, static_cast<std::uint32_t>(esp_timer_get_time() / 1000), emit);
        } else {
            ready = false; gestures.invalidate();
            ESP_LOGW(kTag, "input read failed; pending gestures cancelled");
            vTaskDelay(pdMS_TO_TICKS(1000));
        }
        vTaskDelay(pdMS_TO_TICKS(5));
    }
}
} // namespace nightwave

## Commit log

2026-09-29 docs: complete Phase 1 architecture research
    [BOM.csv]
2026-09-30 fix: align button GPIO constants with pin map
2026-09-30 docs: prepare exact Phase 2 bench prototype
    [prototype-BOM.csv, prototype-wiring.csv]
2026-09-30 ci: pin firmware runner for reproducibility
2026-09-30 docs: define Phase 3 bench validation gate
    [audio-prototype.csv, current-draw.csv, prototype-BOM.csv]
2026-09-30 fix: repair Phase 3 worker lifecycle before bench tests
    [memory-stability.csv, underruns.csv]
2026-10-01 fix: harden Phase 3 WAV parsing and I2S startup cleanup
    [app_main.cpp, audio_sink.cpp]
2026-10-01 feat: add bounded MP3 decoder and funding-stage audit
2026-10-01 feat: add OLED button frontend and streaming stress tests
2026-10-01 test: expand media UI stress coverage and conservative power model
2026-10-01 docs: record software evidence and exact funding blockers
    [BOM.csv]
2026-10-01 fix: keep corrupt-track filenames visible on bounded OLED rows
2026-10-01 docs: record final-master validation evidence and staged builder gates
2026-10-02 Accelerate catalog groups and filtered playback with bounded PSRAM lookup
2026-10-02 Add bounded MP3 seek indexing and portable product interfaces; record BM83 selection
    [BOM.csv]
2026-10-02 Fix ESP32 integer type deduction and remove stale seek and BOM claims
2026-10-02 Validate engineering log records and publish final pre-schematic software evidence
2026-10-02 Record sampled runtime and preserve full Trial acceptance scope
2026-10-03 Propagate selected TFT and input expansion with verified digital gates
    [BOM.csv, prototype-BOM.csv]
2026-10-03 hardware: add builder-authored KiCad starter
    [01_power_charging.kicad_sch, 02_mcu_storage.kicad_sch, 03_local_audio.kicad_sch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]
2026-10-04 hardware: add Nightwave AI reference PCB package
    [01_power_charging.kicad_sch, 02_mcu_storage.kicad_sch, 03_local_audio.kicad_sch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]
2026-10-05 hardware: close reference PCB routing and verify CAD exports
    [01_power_charging.kicad_sch, 02_mcu_storage.kicad_sch, 03_local_audio.kicad_sch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]
2026-10-05 docs: record routed PCB checkpoint CI results
2026-10-06 Integrate reference board inputs and TFT with typed electrical checks
    [01_power_charging.kicad_sch, 02_mcu_storage.kicad_sch, 03_local_audio.kicad_sch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]
2026-10-06 Add read-only reference power telemetry and expose charging design constraints
2026-10-06 Resolve reference resistor MPNs and record verified power checkpoint
    [reference-procurement.csv]
2026-10-06 Serialize reference I2C device registration and correct charger timing screen
    [board_i2c.cpp, board_i2c_tests.cpp, button_monitor.cpp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]
2026-10-06 docs: record verified I2C and power screening checkpoint
2026-10-06 Record compact builder boundaries and battery-independent power screening
2026-10-06 Separate output power estimates and test persistent Bluetooth preferences
2026-10-06 Record approved power direction and sourced Bluetooth battery constraints
2026-10-07 Correct charger input telemetry and add fail-closed charge policy
2026-10-12 Quantify compact board area and enclosure feasibility constraints
2026-10-12 Apply approved Type-C source gating to charging estimates
2026-10-12 Reject nominal-only thermistor reset window with tolerance regression
2026-10-12 Derate requested charge current against qualified positive error
2026-10-12 Gate charging on derated voltage readback and all-stage qualification
